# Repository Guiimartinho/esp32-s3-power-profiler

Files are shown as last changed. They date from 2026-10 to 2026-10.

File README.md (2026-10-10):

# Open Power Profiler

[](CONTRIBUTING.md#quality-gates)
[](#roadmap)
[](LICENSE)
[](hardware/LICENSE)

Open-source power profiler in the class of the Nordic PPK2, built around the
Raspberry Pi Pico 2. It is designed to sample current at 100 kSPS from
100 nA to 1 A with automatic range switching, to work either as a source
meter that powers the device under test or as an ampere meter in series
with an external supply, and to stream the samples to a PC over USB.

The instrument is two boards: a Raspberry Pi Pico 2, bought ready-made,
plugged into a carrier board designed in this project that holds the
measurement electronics.

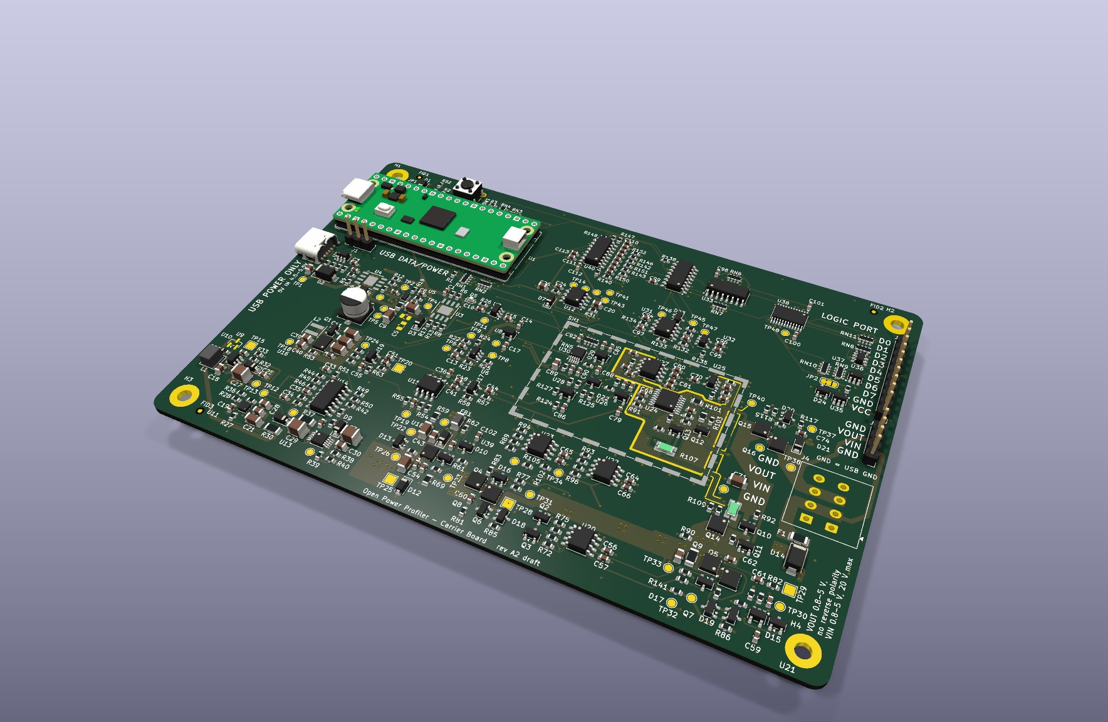
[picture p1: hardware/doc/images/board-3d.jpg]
Rendered view of the carrier board, draft A2


The picture is a rendering from the KiCad files of draft A2, with the
Pico 2 on its sockets. It is not a photograph: no board has been built.

> [!NOTE]
> The project is in early development. No hardware has been built and
> nothing has been measured. The performance figures in this repository
> are design targets, the circuits of the board are simulated from its
> netlist, and the figures of the board are calculated from the drawn
> copper. [Project Status](#project-status) says what exists, what it
> rests on and what comes next.

## Table of Contents

- [Project Status](#project-status)
- [Target Specifications](#target-specifications)
- [How It Works](#how-it-works)
- [Connections](#connections)
- [Hardware Draft](#hardware-draft)
- [Circuit Simulations](#circuit-simulations)
- [Repository Structure](#repository-structure)
- [Roadmap](#roadmap)
- [Getting Started](#getting-started)
- [Engineering Practices](#engineering-practices)
- [Documentation](#documentation)
- [Contributing](#contributing)
- [License](#license)
- [Acknowledgments](#acknowledgments)

## Project Status

As of 2026-10-10. Draft A2 of the carrier board is the present state of
the hardware: the whole schematic, a specification written for it, and a
board with every part placed and every one of its 984 connections drawn.
The board was first routed by an autorouter, which left 28 connections
open. Its layout has since been reviewed: the open connections are closed
and the copper that an autorouter does not draw is drawn, the pours of the
1 A path, the guard, the sense pairs and the copper of the converters. The
review was done with scripts and checked by independent calculation. The
seven points where the reviewed board departs from the first wording of
section 10 of the specification are recorded decisions, D-87 to D-93, and
the specification follows them. What is open is the review by a person in
the KiCad editor, a list of items that need parts moved, the silkscreen
and test point items, and the thermal check of D-93. Every figure of the
board is calculated from the drawn copper, none is measured; the package
in [`tools/board/`](tools/board/README.md) reproduces them from the board
file.

On 2026-10-10 the circuits of the schematic were simulated as well, block
by block, from its netlist: 134 benches in ngspice, of which 93 run
circuits of the board and 41 put the models into the test circuits of
their datasheets. The central design figures of the specification come
out again. The simulations raised four points for a decision before
boards are ordered, and the project owner decided them the same day: they
are decisions D-95 to D-98 of the specification. Three of them change the
schematic and are not drawn yet, so the schematic, the board, the bill of
materials and the results of the simulations still show the earlier
state. In fourteen places the simulations differ from a figure or a rule
of the specification or show something that it does not state. Those are
not decided, and no requirement, figure or rule of the specification was
changed on their account. A simulation is not a measurement: every active
part in it is a model written from a datasheet, a typical part at room
temperature. [Circuit Simulations](#circuit-simulations) shows the state.

The software was written ahead of the hardware and is tested without it.

| Area | What exists | What is open |
| --- | --- | --- |
| [Specification](docs/specification.md) | The baseline of draft A2: requirements R-01 to R-17, analog and firmware design, pin map, host protocol, 98 recorded decisions and 36 firmware rules that guard hardware. The last four, D-95 to D-98, are the decisions of the project owner on the four points that the simulations raised | Every figure is a datasheet value, a calculation, a simulation or an estimate; the tests of its section 11 have to confirm them. Three of the four new decisions are stated here and not drawn yet. Where the simulations of 2026-10-10 differ from its text in fourteen other places, the text stands unchanged and its section 16 lists the place |
| [Schematic](hardware/doc/README.md) | 428 parts on 15 pages. It passes the electrical rules check, and its netlist was checked independently against the datasheets. Its circuits are simulated from that netlist | The [component checks](docs/checks/README.md): none is closed, so every part is a candidate. Three decisions that follow the simulations are not drawn yet: 10 nF in place of 1 nF at three capacitors of the rail monitor (D-95), a position for a capacitor at the buffer of the driver rail (D-96), and the two parts of the damper on the module input fitted (D-98) |
| [Board](hardware/README.md#board) | 150 mm × 100 mm, four layers, 425 footprints, 984 of 984 connections drawn, no violation in the design rules check. The layout was reviewed with scripts and checked by independent calculation. Calculated from the drawn copper: the 1 A path is 19.5 squares in source meter mode and 23.3 squares in ampere meter mode against a limit of 30, and the surface leakage into the measured node is 5.1 nA against a budget of 10 nA. The seven points where the layout departs from the first wording of section 10 of the specification are recorded as decisions D-87 to D-93 | No person has reviewed the board in the KiCad editor; open items need parts moved, the capacitor loops of the converters among them; names on the silkscreen and probe grounds at the test points are missing; the temperature rise of the linear regulator is an open check, read on the first board (D-93). The position for a capacitor of D-96 is not on the board yet: it adds one footprint |
| [Bill of materials](hardware/doc/bom.csv) | 151 lines, each with a part number and a maker, exported from the schematic | Three lines had no stock on 2026-10-09. The file still shows the state before the decisions of 2026-10-10, with three positions without parts: the two parts of the damper on the module input are fitted by D-98 and get their part numbers when the schematic is changed, the three capacitors of D-95 change their value, and the detector position at the boost converter stays empty (D-97) |
| [Circuit simulations](simulation/README.md) | The circuits of draft A2 simulated in ngspice from the netlist of the final schematic, in a package of their own (D-94): 134 benches, 93 on the circuits of the board in ten blocks and 41 that put the models written for the project into the test circuits of their datasheets. Of 3162 figures 1834 pass, 122 fail and 1206 carry no limit. The central design figures of the specification come out again block by block: shunt ladder, signal chain, range logic with requirement R-07, source meter, output stage, path switches, rails, power input and digital lines. The package has 777 tests; lines and branches are covered in full, the one module that loads the simulator excepted | The four points that the simulations raised are decided (D-95 to D-98): the capacitors of the rail monitor, the buffer of the driver rail, the detector position at the boost converter and the damper on the module input. The results are still those of the circuit before these decisions; the benches run again when the change is drawn. In fourteen places the simulation and the text of the specification differ; the text stands unchanged until the owner decides. What stays for the bench: leakage at the nanoampere level, the multiplexer at +12 V and −4 V, the programs of the controller, coupling through the board, temperature. Every active part is a model written from its datasheet, and nothing is measured. The simulations ran on one machine; the `Simulation` workflow has not been started yet |
| [Firmware](firmware/README.md) | Core in C that needs no hardware, with unit tests on the PC: wire protocol, block queue, settling window, step-down rule, device state machine. The build project is still the one of the first plan, for the ESP32-S3 | No build for the Pico 2, no PIO program, no adapter for any hardware, no command handler, none of the firmware rules of the specification |
| [Host software](host/README.md) | Python package with protocol, transports, device client, capture helpers and a device simulator, tested against that simulator | Its nominal calibration and its handling of flagged samples do not follow draft A2 yet; no command that captures from an instrument, no viewer and no export |
| [Protocol](protocol/README.md) | One definition; the constants of firmware and host and the shared test vectors are generated from it | What draft A2 reports beyond it, listed in section 16 of the specification |
| [Tools](tools/README.md) | [`tools/board/`](tools/board/README.md): a Python package that calculates the layout figures from a dump of the board file: copper resistance in squares and milliohms, lengths of the Kelvin pairs, surface leakage into the measured node. 260 tests on synthetic boards, lines and branches fully covered | Calibration and production test: two empty folders. The `Tools` workflow has not been started yet. The scripts that drew the layout are not in the repository |
| Measurements | None: no board has been built | The phases of the [roadmap](#roadmap) |

Next steps, in this order:

1. **Draw the decisions that follow the simulations.** The project owner
   decided the four points on 2026-10-10: decisions D-95 to D-98 of the
   specification. Three of them change the schematic and are not drawn
   yet: 10 nF in place of 1 nF at three capacitors of the rail monitor,
   the comparators that tell the controller that the analog supplies
   stand (D-95); a position for a capacitor at the buffer of the driver
   rail, the supply of the amplifier that drives the converter, which
   needs a footprint and so a change of the board (D-96); and the two
   parts of a damper, a resistor with a capacitor, on the module input,
   the supply that comes through the USB connector of the Pico 2, on pads
   that the board already has (D-98). The fourth leaves the position for
   a voltage detector at the boost converter, which makes the supply of
   the analog rails, without a part and changes only the text of that
   position (D-97). After the change come the
   electrical rules check and the design rules check, the bill of
   materials and the pictures exported again, the netlist snapshot of the
   simulations written again and the benches of the changed blocks run
   again. Until then the schematic, the board, the bill of materials and
   the results of the simulations show the earlier state.
2. **Decisions that are still open.** They are the project owner's. The
   fourteen places where the text of the specification and the simulation
   differ: each one that changes the text becomes an entry in its
   decision log. And whether proof-of-concept boards are ordered on this
   state. The
   [simulation guide](simulation/README.md#what-the-simulations-say) gives
   every place with the bench that shows it, and section 16 of the
   specification lists them as open.
3. **Board.** Four things stand between the reviewed layout and
   fabrication. First, a person opens the board in the KiCad editor and
   reviews it; so far it was drawn and checked with scripts only. Second,
   the open items that need parts moved are a change of placement with a
   local redraw: the capacitor loops of the converters, the inductor of
   the pre-regulator and the others. Third, the silkscreen and test point
   items: net names, jumper functions, probe grounds, a frame for the
   serial number. Fourth, the thermal check of D-93: the temperature rise
   of the linear regulator at full dissipation is read on the first board.
   The [hardware guide](hardware/README.md#still-to-do) lists the open
   items one by one. The simulations judge the circuits, not the copper:
   of their decisions only the position of D-96 touches it.
4. **Software.** Bring the host package and the firmware to what the
   specification of draft A2 asks: the nominal calibration, the fault
   causes and the protocol items of its section 16. Then port the firmware
   to the Pico SDK. The [firmware guide](firmware/README.md) and the
   [host guide](host/README.md) list the differences.

Until 2026-10-10 this list had a step to file the simulations. It is
done in another form. The files of the earlier simulations, from which
the specification took its figures marked "simulated", are not filed;
the circuits were simulated again from the netlist, and the package, the
benches and their results are in [`simulation/`](simulation/README.md),
where a reader can run them again.

The [component checks](docs/checks/README.md) follow, of which none is
closed, and the phases of the [roadmap](#roadmap), starting with the risk
prototypes of phase 1. Three of those prototypes settle what the
simulations leave open: the reaction time of the range sequencer, which is
an input of every simulation of the range logic, the loop of the
pre-regulator at its low end, and the start of the boost converter from a
supply limited to 0.7 A.

## Target Specifications

| Item | Target | Requirement |
| --- | --- | --- |
| Sampling rate | 100 kSPS, timed by hardware | R-01 |
| Data integrity | No lost sample in a capture of 10 minutes; any loss is reported | R-02 |
| Current range | 100 nA to 1 A in four ranges, switched automatically | R-03 |
| Resolution | 100 nA or better in the lowest range; RMS noise there at most 5 nA in ampere meter mode from a quiet supply and 40 nA in source meter mode | R-04 |
| Accuracy | ±1 % of reading ±0.1 % of range after calibration | R-05 |
| Burden voltage | 100 mV maximum across the shunt; 200 mV from input to output at 1 A | R-06 |
| Range change | On a step from 1 µA to 500 mA the instrument adds at most 0.5 V of drop with 1 µF at its output and 0.25 V with 10 µF | R-07 |
| Source meter mode | Programmable output from 0.8 V to 5.0 V in 1.3 mV steps; 1.0 A up to 2.0 V, falling to 0.6 A at 5.0 V | R-08 |
| Ampere meter mode | External supply from 0.8 V to 5.0 V through the shunts; the input withstands −20 V to +20 V while its switch is open | R-09 |
| Digital inputs | 8 logic channels sampled together with the current, logic levels from 1.65 V to 5.5 V | R-10 |
| Host link | USB Full-Speed, CDC ACM, binary protocol | R-11 |
| Calibration | Gain and offset of each range, stored on the device | R-12 |
| Protection | Over-current trip, reverse polarity, over-voltage, thermal | R-13 |
| Power input | USB-C, 5 V, on the carrier board, used whenever it is present, or the USB cable of the Pico 2 alone; the input current is limited to what the source offers: 0.45 A, 1.4 A or 1.7 A | R-14 |
| Host software | Capture, live view, statistics and export on Windows, Linux and macOS | R-15 |
| Openness | Firmware and host software under MIT, hardware under CERN-OHL-P v2 | R-16 |
| Software quality | Automated tests with coverage gates, static analysis and continuous integration | R-17 |
| Controller | Raspberry Pi Pico 2 (RP2350) on pin sockets | D-39 |
| DUT connections | Pin header and lever terminal block, in the pin order of the PPK2 | D-44 |

These are design targets, not measurements. Draft A2 set seven of them
(R-04, R-06, R-07, R-08, R-09, R-10 and R-14) to what the architecture
delivers, with the PPK2 as the yardstick. Section 2 of the
[specification](docs/specification.md) gives the full wording of each
requirement and the evidence behind each figure: a datasheet value, a
calculation, a simulation or an estimate.

Where the specification compares a target with the PPK2, it quotes the
PPK2 User Guide v1.0.1:

| Item | This design, target | PPK2, as its user guide states |
| --- | --- | --- |
| Resolution in the lowest range | 100 nA or better (R-04) | 0.2 µA, with measurement down to about 200 nA |
| Current in source meter mode | 1.0 A up to 2.0 V, falling to 0.6 A at 5.0 V (R-08) | 600 mA, with a rated power of 5 W |
| External supply in ampere meter mode | 0.8 V to 5.0 V (R-09) | The same range |
| Logic levels of the digital inputs | 1.65 V to 5.5 V (R-10) | 1.65 V to 5.5 V |
| Burden voltage | 100 mV across the shunt, 200 mV in the whole path at 1 A (R-06) | Not stated |
| Drop at a range change | 0.5 V with 1 µF at the output, 0.25 V with 10 µF (R-07) | Not stated |
| Voltage that the supply input withstands | −20 V to +20 V with its switch open (R-09) | Not stated |

The middle column holds design targets, none of them measured; the right
column is taken from section 2 of the specification.

## How It Works

```text
USB-C 5 V ────► limiter ─┐
                         ├► multiplexer ─► 5 V rail ─► supplies of the carrier
Pico 2 USB ───► limiter ─┘

5 V rail ───► pre-regulator ──► LDO (source mode) ◄── DAC ◄── SPI
                                    │
VIN (ampere mode) ──► protection ──►├── mode switch
                                    │
                         shunt ladder + range FETs ◄── range sequencer
                                    │         │ Kelvin sense   ▲
                         output switch     in-amp ──┬──► comparators
                                    │               └──► ADC ──► Pico 2 ──► USB
                                  VOUT ──► DUT          D0..D7 ──► level shift
```

- **Two boards.** Everything in the diagram except the controller is on the
  carrier board. The Raspberry Pi Pico 2 brings the microcontroller and the
  USB port, and uses every one of its 26 GPIO pins.
- **One programmable part.** The range sequencer and the sampling clock are
  programs for the PIO blocks of the RP2350: small state machines that run
  from the system clock whatever the processors do. Firmware is loaded
  through USB; no programmer and no vendor tool is needed.
- **A supply that spares its source.** Each USB input has its own current
  limiter, and a multiplexer feeds the 5 V rail from USB-C whenever it is
  present. A supervisor switches the supplies of the carrier off when that
  rail collapses, and four comparators report through one line, PWR_GOOD,
  that the analog rails and the reference are present.
- **Four shunt ranges.** Shunts of 1 kΩ, 33 Ω, 1 Ω and 0.1 Ω, each limited
  to 100 mV of burden voltage. Three comparators drive the range
  sequencer, which switches to a higher range with no firmware involved:
  on a large step the 1 A range conducts 0.35 µs after its threshold
  (simulated, with a sequencer that reacts within 100 ns, which phase 1
  has to measure). A current step therefore costs the device under test
  only a short dip; requirement R-07 of the specification gives its size.
  The firmware decides when to step back down.
- **Hardware-timed sampling.** A 16-bit SAR ADC is clocked by a PIO state
  machine, so the sampling instant does not depend on firmware latency. The
  same state machine reads the range and the logic inputs with every
  conversion result.
- **Self-describing samples.** Every sample is a 32-bit word that carries the
  ADC code, the active range, a validity flag, the fault flag and the eight
  logic inputs.
- **Two cores, two jobs.** One core acquires data in DMA blocks. The other
  frames the blocks and streams them over USB.
- **Programmable supply.** In source meter mode a DAC sets a low-noise linear
  regulator, fed by a pre-regulator that tracks the output voltage.
- **Protection that does not wait for firmware.** The over-current trip is a
  PIO state machine. An over-voltage on the external supply input holds
  its switch open through one transistor, a second transistor keeps the two
  mode switches from closing together, and with its switch open that input
  withstands −20 V to +20 V (simulated).
- **A quiet front end.** The shunts of the three lower ranges, the
  amplifier and the converter are placed under a shield can, and the
  switching converters stand at least 30 mm away from it.

The reasons behind each choice, with the decision that records it, are in
sections 3 and 4 of the [specification](docs/specification.md).

## Connections

The back edge of the carrier has the USB connector of the Pico 2 (data, and
power for small loads) and a USB-C connector for power. Either one powers
the whole instrument. The front edge has the connections to the device under
test, in the pin order of the Nordic PPK2:

| Connector | Type | Pins, left to right |
| --- | --- | --- |
| DUT | 1×4 pin header, 2.54 mm | GND, VIN, VOUT, GND |
| DUT | Lever terminal block, 3.5 mm | GND, VIN, VOUT, GND |
| Logic port | 1×10 pin header, 2.54 mm | VCC, GND, D7 down to D0 |

- **Source meter mode:** the device under test connects to VOUT and GND.
- **Ampere meter mode:** the external supply connects to VIN and GND, the
  device under test to VOUT and GND.
- **Logic port:** as built, the logic inputs follow the output voltage, and
  the VCC pin is not needed. A solder jumper makes the VCC pin the reference
  instead, for a device whose logic runs on another voltage.

## Hardware Draft

The carrier board is drawn in KiCad 10 as draft A2. Its layout was reviewed
on 2026-10-10.

| | Draft A2 after the layout review |
| --- | --- |
| Schematic | 428 parts on 15 A4 pages: the root page and 14 sheets; unchanged by the layout review |
| Electrical rules check | 0 errors, 0 warnings |
| Board | 150 mm × 100 mm, four layers, 425 footprints, all on the top side |
| Routing | 984 of the 984 connections: 8.38 m of track on three layers (top 3.76 m, second inner layer 2.84 m, bottom 1.79 m), 694 vias and 42 copper zones. The first inner layer is the ground plane, in one piece and with no track on it |
| Open connections | None. The autorouted board had 28, and 25 of them broke a function |
| Design rules check | 0 violations, 0 unconnected pads, 0 footprint errors, 0 differences between board and schematic. The rule file is stricter than the one the autorouter ran with: the exemption of the larger spacings near pins now holds on the top layer only. Decision D-87 records its spacings |
| Bill of materials | 151 lines, each with a part number and a maker: [`hardware/doc/bom.csv`](hardware/doc/bom.csv); unchanged by the layout review |
| Circuit simulations | The circuits of the schematic simulated from its netlist on 2026-10-10 in 93 benches: 1356 figures pass, 105 fail and 1136 carry no limit. The four points that they raised are decided (D-95 to D-98), and three of them are not drawn yet ([Circuit Simulations](#circuit-simulations)) |

The schematic was checked independently against the datasheets of its
parts. That closes none of the
[component checks](docs/checks/README.md): the parts are candidates. The
simulations close none either: they run on models written from those
datasheets.

The board came about in three steps. A script placed every footprint
inside the area of its functional block. An autorouter drew a first set of
tracks: 956 of the 984 connections, with 28 left open, no pour and no
guard. Then the layout was reviewed with scripts on the board file, block
by block: the open connections were closed and the pours of the 1 A path,
the guard, the Kelvin pairs, the copper of the converters, the 5 V rail and
the ground fills were drawn. Each block was drawn against the rules of
section 10 of the specification and then checked by an independent check
that calculated every rule again. A final review of the whole board by rule
group followed, with 75 findings, then a repair round for the leakage paths
into the measured node that it found. No part was added or removed; 35 of
the 425 footprints moved or turned, 33 of them by 2.75 mm or less.

The result is a drawn and calculated layout, not a design to fabricate.
Nobody has opened it in the KiCad editor and looked at it as a person
would before ordering boards: every check ran from the command line. The
scripts that calculate the figures are in the repository, as the package
in [`tools/board/`](tools/board/README.md); the helpers that drew the
layout are not.

### What the Layout Review Reached

Every figure in the column "Now" is calculated from the drawn copper.
Nothing is built and nothing is measured. The resistances count 35 µm
copper at 40 °C and leave out the transistors, the shunt and the fuse.

| Rule, with its section of the specification | Limit | Autorouted board | Now |
| --- | --- | --- | --- |
| Connections drawn | 984 | 956 | 984 |
| 1 A path in source meter mode, regulator output to the VOUT terminal (10.4) | 30 squares | 397 squares, about 211 mΩ | 19.5 squares, 10.4 mΩ |
| 1 A path in ampere meter mode, VIN terminal to the VOUT terminal (10.4) | 30 squares | 217 squares, about 116 mΩ | 23.3 squares, 12.3 mΩ |
| Surface leakage into the measured node (10.3) | 10 nA | No figure | 5.1 nA; it was about 20 nA at the final review, before the repair round |
| Guard around the measured node (10.3) | A closed ring on the top layer | None | One piece of copper: three arcs on the top layer, open where the measured node leaves the shield can, joined through the other layers |
| Sense and guarded nets on the top layer without a via (10.3) | All 11 | No figure | 10 of 11 |
| 5 V rail from the bulk capacitor to the input capacitors of the converters (10.1) | 10 mΩ to the pre-regulator and 25 mΩ to the boost converter: targets of the layout review, the specification gives no figure | Tracks of 0.4 mm | A pour on the second inner layer: 2.7 mΩ and 3.0 mΩ to the pre-regulator, 3.6 mΩ to the boost converter |
| Copper from the output capacitors of the pre-regulator to the bead (10.5) | 15 mΩ | No figure | 7.1 mΩ |

The figures of the 1 A path, of the leakage, of the pairs and of the vias
on the sense nets are reproduced from the board file by the `report`
command of the package in `tools/board/`; its
[guide](tools/board/README.md#report-everything-the-definition-asks-for)
says how to install it, dump the board and run it. The resistances are
calculated on a grid of 0.1 mm; on a grid of 0.05 mm the two sums of the
1 A path read about 2 % higher, 19.9 squares and 23.8 squares, and a via
is counted in a way that errs to the high side.

The leakage figure rests on the assumptions that section 10.3 of the
specification itself uses: a clean surface of 10¹¹ Ω per square and the
voltages of the neighboring nets. Solder mask, cleanliness and humidity
are not modeled. Almost all of what is left comes from the pitch of pads:
the gate beside the source in a transistor package, the poles of the two
DUT connectors, neighboring pins of the multiplexer.

### Decisions of the Layout Review

In seven points the reviewed board departs from what section 10 of the
specification first asked. The owner accepted all seven on 2026-10-10.
They are recorded in the decision log of the
[specification](docs/specification.md) (section 15), and section 10 now
describes the board as it is drawn:

- **D-87.** The rule file of the board states every spacing that the
  layout needs.
- **D-88.** The high-side sense line of the 0.1 Ω shunt keeps two vias and
  1.9 mm on the second inner layer.
- **D-89.** The Kelvin pairs: one runs side by side, two are equal in
  length within 1 mm, and the taps of the two lowest ranges run through
  one via each.
- **D-90.** The guard is one piece of copper, open on the top layer at the
  three exits of the measured node and joined on other layers.
- **D-91.** The supply, address and enable pins of the multiplexer and
  their parts stand inside the guard.
- **D-92.** The 1 A path is judged by its resistance, 30 squares or less
  in either mode; two of its pieces run on the bottom layer.
- **D-93.** The island of output copper under the linear regulator is
  291 mm² on the bottom layer and 102 mm² on the top layer, joined by
  22 vias; its temperature rise is an open check, read on the first board.

A decision accepts a drawn layout, not a measured one: where it rests on
a resistance or a leakage, the figure is calculated from the drawn copper.
The [hardware guide](hardware/README.md#decisions-of-the-layout-review-d-87-to-d-93)
quotes, for each point, what section 10 said before, what the board has
and why.

### What the Layout Review Left Open

Four things stand before fabrication, and the component checks beside
them. A fifth came after the review: the three decisions that follow the
circuit simulations and are not drawn yet, of which the position for a
capacitor at the buffer of the driver rail adds a footprint to this board
(D-96; [Project Status](#project-status)).

No person has reviewed the board in the KiCad editor: it was drawn and
checked with scripts only.

Eleven items need parts moved or another footprint and were left open. The
capacitor loops of the pre-regulator and of the boost converter close over
6.8 mm to 17.1 mm of top copper where the limit is 5 mm, and the inductor
of the pre-regulator stands 4.5 mm from its switch pins where the limit is
3 mm; nine more are smaller.

The legends of the silkscreen and the test points are as the autorouted
board had them; only the title text changed, to the name of the project.
32 of the 40
signal test points have no probe ground within 5 mm, and the net names of
the test points and the functions of the two jumpers are not printed.

The temperature rise of the linear regulator at full dissipation is an
open check, to be read on the first board (D-93).

The component checks are open too: none is closed. The hardware guide
lists the [open items](hardware/README.md#open-items) one by one, with
their figures and with what would close each.

### Pictures

All pictures are renderings and plots of the board file, not photographs.

The top side, rendered from the board file. The gold line around the front
end is the guard under open solder mask:

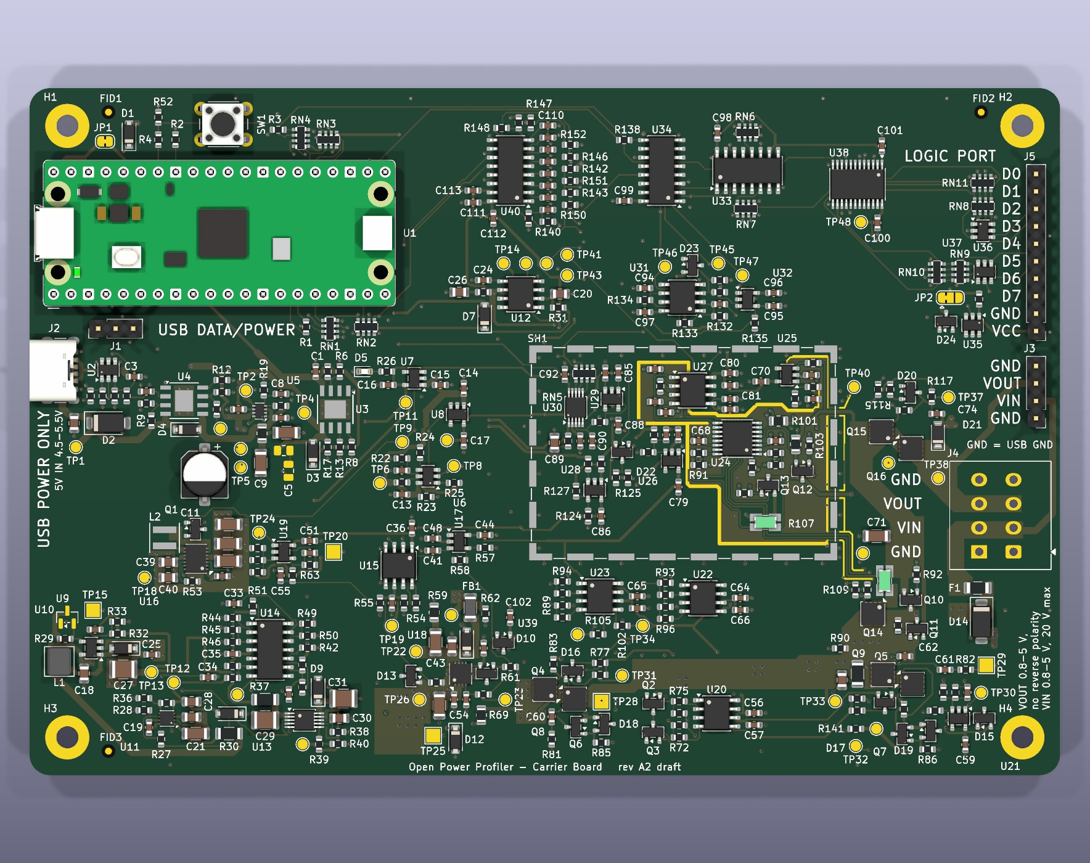
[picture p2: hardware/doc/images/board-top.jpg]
Rendered top view of the carrier board


The four copper layers side by side. Top left, the top layer: the parts,
the pours of the 1 A path, the sense pairs and the guard. Top right, the
first inner layer: the ground plane, in one piece. Bottom left, the second
inner layer: the 5 V rail, the rail trunks and a ground fill. Bottom
right, the bottom layer: the crossings, the second layer of the 1 A path
and a ground fill:

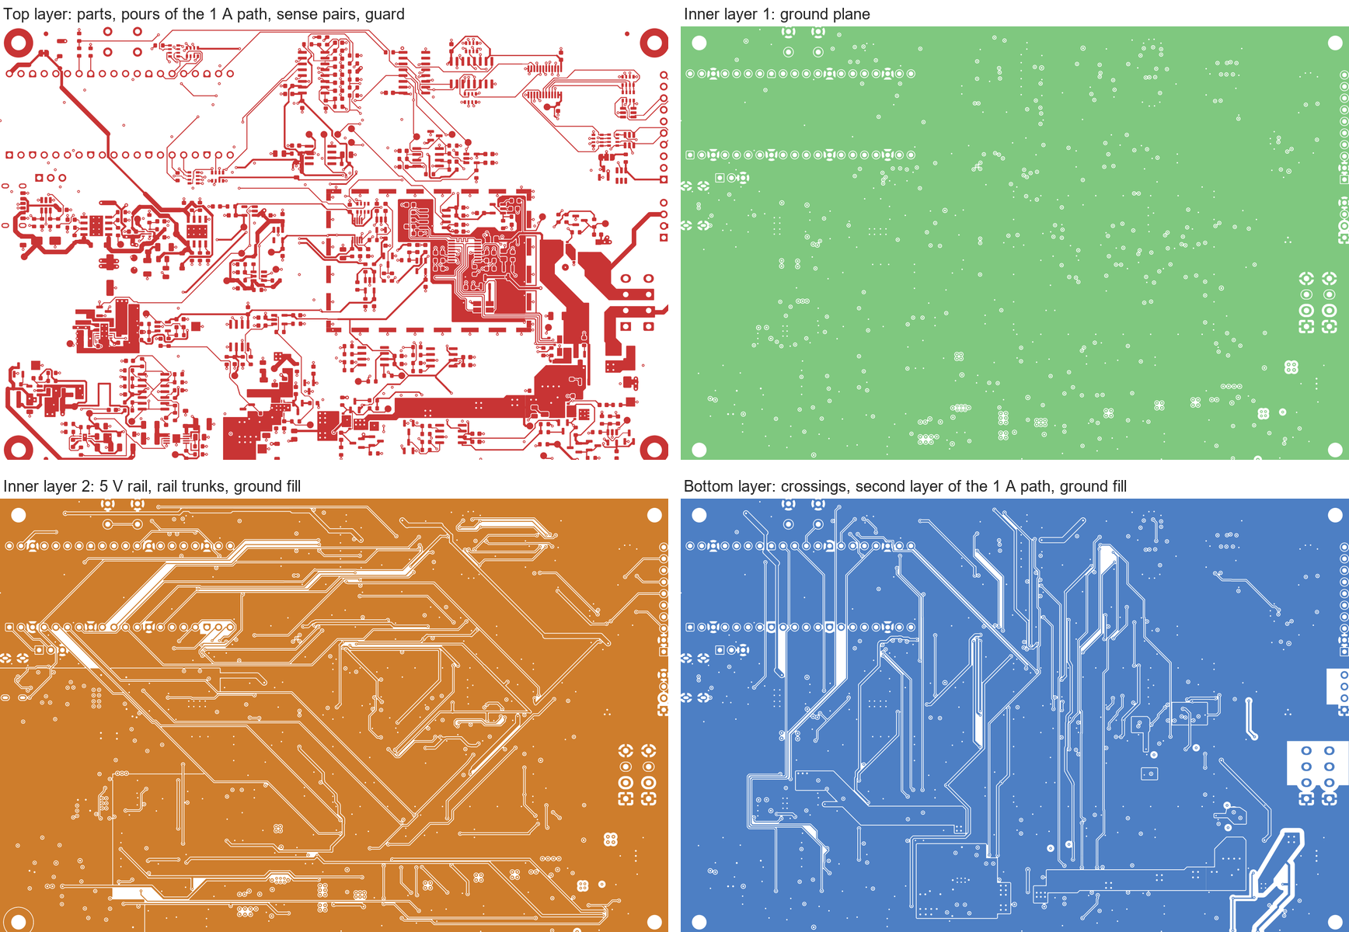
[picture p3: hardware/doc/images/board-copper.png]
The four copper layers of the board


The measured node under the shield can, top layer in red, openings of the
solder mask in pink. Look for the pink line that runs around the large red
area: it is the guard, bare of solder mask, around the copper of the
measured node and the guard pour. From the multiplexer in the middle, thin
lines run in pairs to the shunts: the Kelvin lines. At the lower right the
pair of the 1 A range leaves the can in a lane with a guard track on each
side:

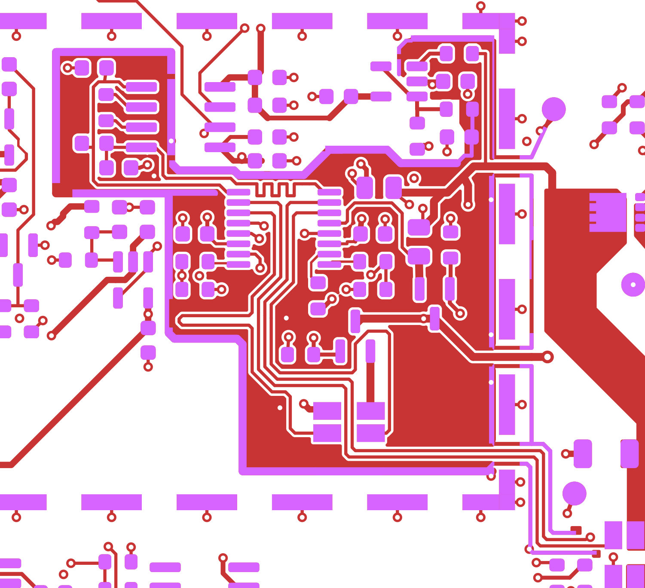
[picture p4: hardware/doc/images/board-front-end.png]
The measured node and its guard on the top layer


The 1 A path on the top layer. Follow the wide copper from the linear
regulator at the bottom left, along the supply band to the right, up to
the shunt branch and the output switch, and out to the terminal block at
the right edge. The dashed rectangle is made of the lands of the shield
can:

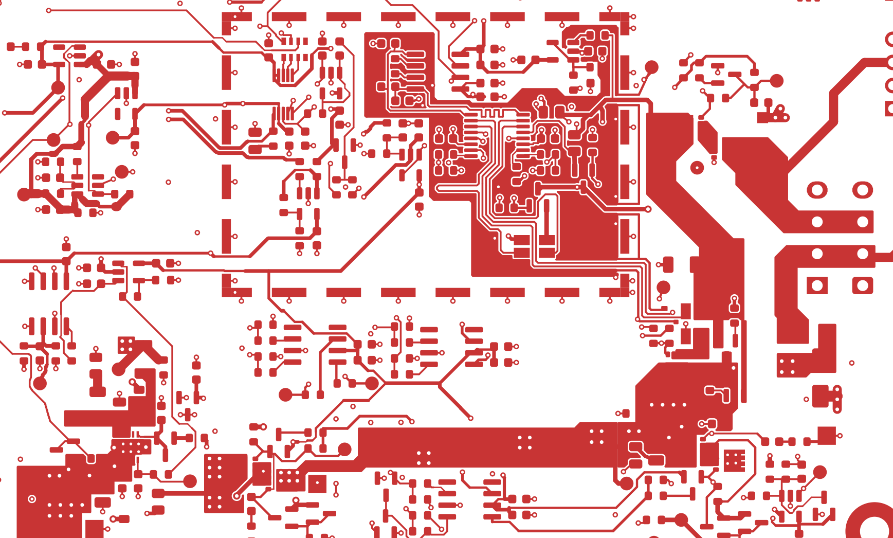
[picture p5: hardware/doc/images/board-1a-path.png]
The pours of the 1 A path on the top layer


The areas of the sixteen functional blocks and the parts inside them:

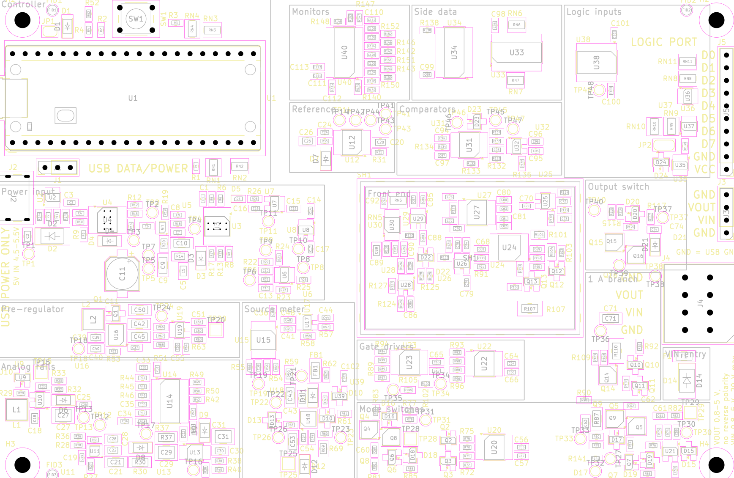
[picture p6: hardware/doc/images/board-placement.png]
Placement of the functional blocks


The root page of the schematic, with one block for each of the 14 sheets:

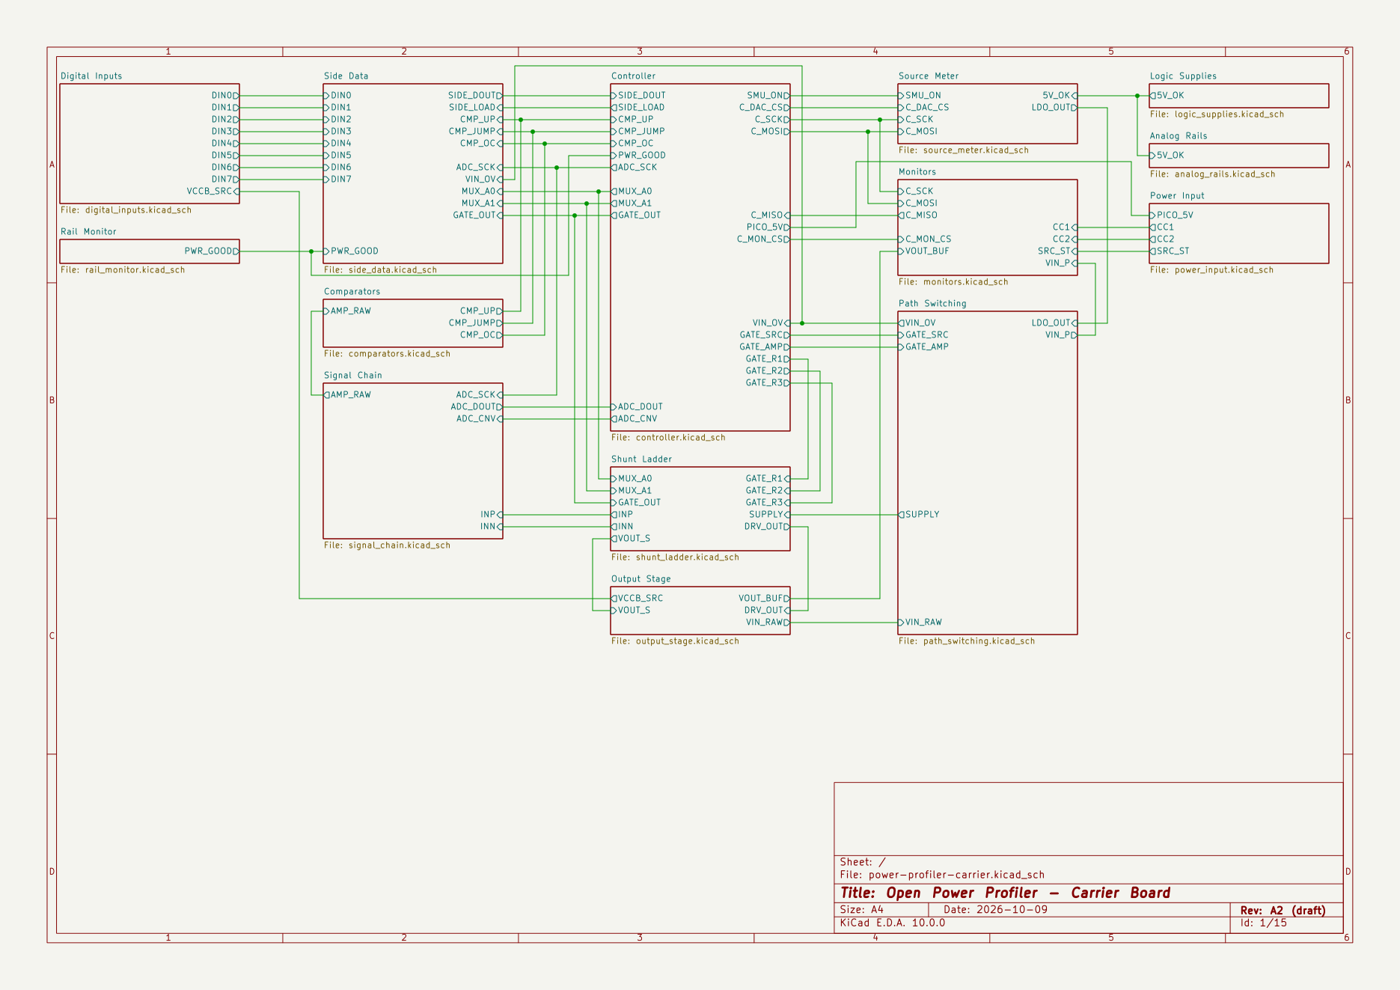
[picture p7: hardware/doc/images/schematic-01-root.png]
Block level of the schematic


Every sheet and the board are shown in
[`hardware/doc/`](hardware/doc/README.md), and the whole schematic is in
[`hardware/doc/schematic.pdf`](hardware/doc/schematic.pdf). The status, the
checks and the open work are in the [hardware guide](hardware/README.md).

## Circuit Simulations

The circuits of the carrier board are simulated from the netlist of the
schematic. A bench names parts of the schematic by their reference
designators, the package in [`simulation/`](simulation/README.md) writes
their elements from a snapshot of that netlist, and ngspice runs the
circuit: no part of the board is typed by hand. What stands around the
parts is typed by the bench and named in its notes: sources, loads,
cables, and in some benches a stand-in for a neighboring block of the
board. The simulator is the ngspice library that KiCad 10 ships. Every
active part is a model written for this project from its datasheet, a
typical part at room temperature. 41 benches put these models into the
test circuits of their datasheets; four models have no such bench, the
analog multiplexer among them. The models of the manufacturers may not be
copied into the repository; where a copy is present they give a second
value.

Everything in this section is simulated. Nothing is built and nothing is
measured: a figure that passes says that the circuit as drawn keeps its
limit with these models, not that a board will. Elsewhere on this page a
figure marked "simulated" is one of the specification, taken from the
earlier simulations of the draft.

| Block | Benches | Pass | Fail | No limit |
| --- | --- | --- | --- | --- |
| [Shunt ladder](simulation/results/ladder/README.md) | 2 | 20 | 0 | 6 |
| [Signal chain](simulation/results/signal_chain/README.md) | 11 | 113 | 8 | 111 |
| [Range control logic](simulation/results/range_logic/README.md) | 12 | 143 | 6 | 122 |
| [Source meter](simulation/results/source_meter/README.md) | 12 | 176 | 3 | 247 |
| [Output stage](simulation/results/output_stage/README.md) | 6 | 151 | 6 | 142 |
| [Path switching](simulation/results/path_switching/README.md) | 15 | 288 | 19 | 235 |
| [Power input and logic supplies](simulation/results/power_input/README.md) | 13 | 190 | 27 | 113 |
| [Analog rails and rail monitor](simulation/results/analog_rails/README.md) | 10 | 105 | 25 | 108 |
| [Digital lines and monitors](simulation/results/digital/README.md) | 10 | 145 | 11 | 49 |
| [Whole measuring path](simulation/results/system/README.md) | 2 | 25 | 0 | 3 |
| Circuits of the board, ten blocks | 93 | 1356 | 105 | 1136 |
| [Models against their datasheets](simulation/results/models/README.md) | 41 | 478 | 17 | 70 |
| All | 134 | 1834 | 122 | 1206 |

A bench is one circuit with its stimulus. It takes figures from the
waveforms and judges each one against its limit: a figure of the
specification where it states one; else a rating or a figure of a
datasheet, a value that the bench calculates, or a limit that the bench
sets and names. For a model the limit is the figure of its datasheet with
the tolerance that this project asks of a model. 1206 figures carry no
limit: they are values that nothing limits. A figure that fails is kept
as it is. Most of the 122 are of five kinds: a point that is decided
since and not drawn yet, a figure of the specification that the circuit
does not give, a rating that a fault case passes, an option that is not
in use, and a model that misses its datasheet. The guide
[sorts them by block](simulation/README.md#reading-the-failures).

How close the simulated values lie: for 595 figures of the board blocks
the pages print the distance from a stated value, in most cases the one
that the specification states. 368 lie less than 5 % from it, 434 less
than 10 % and 489 less than 25 %. The
[index of the results](simulation/results/README.md) has every bench, and
the page of each block has the values, the graphs and the decks, the
circuit files that the simulator ran. The whole suite ran on one Windows
machine and takes 29 minutes there.

### What the Simulations Say

**Reproduced.** The central design figures of the specification come out
of circuits taken from the netlist. That is a second calculation with
models, not a confirmation by measurement. Among them:

- Requirement R-07: on a step from 1 µA to 500 mA with 1 µF at the output
  the drop is 301.9 mV with nominal delays, and 388.2 mV with every delay
  at its limit and the capacitor 10 % low, against the limit of 500 mV.
  With 10 µF it is 168.3 mV and 179.2 mV, against 250 mV. An amplifier
  with half the bandwidth of its model, which is an assumption, takes the
  two worst cases to 400.3 mV and 180.8 mV.
- The jump to the 1 A range takes 360.8 ns from its threshold with
  nominal delays and 480.3 ns with the worst ones, against a target of
  550 ns. The 100 ns of the sequencer are an input of that run.
- Gain 19.93 and zero code 1313; one code is 1.914 nA in the lowest range
  and 19.14 µA in the highest. After a jump to the highest range the chain
  settles to 0.1 % of the range in 45.37 µs, and in 49.2 µs at the most
  over the cases that were run. The noise of one sample in the lowest
  range is 2.098 nA from a quiet supply.
- The source meter gives 799.5 mV and 5 V at its two nominal codes in
  steps of 1.282 mV, and its regulator keeps 449.2 mV to 631.9 mV of head
  room on the curve of R-08 with nominal parts.
- The in-rush into 2200 µF at the output is 856.1 mA, below the trip
  level, and the closed path drops 155.7 mV at 1 A in ampere meter mode,
  with the 20 mΩ that the specification allows for copper and contacts
  (limit 200 mV).
- With its switch open the external supply input takes 184.6 µA at +20 V
  and 597.9 µA at −20 V, against a limit of 1 mA.

**Four points, decided.** The simulations raised them for a decision
before boards are ordered, and the project owner decided them on
2026-10-10. Three are not drawn yet, so the results above are still those
of the circuit before them:

1. The capacitors of the rail monitor become 10 nF (D-95). With 1 nF as
   drawn and a comparator at its least hysteresis, an edge of PWR_GOOD
   moves its own threshold and gives a burst of edges on a slow rail.
   With 10 nF the threshold moves by 525 µV, below that hysteresis, where
   1 nF gives 3.149 mV to 3.606 mV; the one run made with 10 nF, at a
   slower slope, shows one edge. The capacitance between the pins that
   couples the edge is an assumption.
2. The buffer of the driver rail of the converter gets a position for a
   capacitor at its input, whose value is chosen on the bench (D-96). Its
   loop has 41.92° of phase margin as drawn, not the 54° that the
   specification stated, and it is stable. The model of the manufacturer
   gives 68.99°, with input capacitances that are not those of its
   datasheet. No run with the capacitor exists, and the position needs a
   footprint.
3. The position for a voltage detector at the boost converter stays
   without a part (D-97). As drawn the converter starts in one go from an
   input limited to 0.67 A to 0.85 A. A detector with a time-out of
   0.24 s in that position would stop that start and, with 1 mA of load,
   repeat it four times in the 1.1 s of the run without completing it.
   The result rests on a model of the converter below 2.7 V, where its
   datasheet says nothing, on a source with a flat current limit and on
   the 1 mA, so the start on a prototype stays a test of phase 1.
4. The damper on the module input is fitted (D-98). When the data cable
   is plugged again on a port at 5.5 V behind a short cable while USB-C
   supplies the instrument, the input of the power multiplexer reaches
   5.941 V with a limiter of typical reaction, and 6.002 V with one
   assumed to react in 15 µs, against a rating of 6.0 V. With the damper
   fitted the peak is 5.502 V in the runs made; the case that is worst
   with the damper, a longer gap of the contact, was not run, and neither
   was the recharge pulse at a change of input.

**Fourteen places where the simulation and the text differ.** The round
proposes no change of hardware for them; that is the owner's decision
too. They are figures and rules of the specification, and things on which
it is silent: how long the over-current comparator stays high while a
large capacitor recharges, the ladder clamp in a short circuit, the advice
on a capacitor at the VIN terminals, the times at power-off, the opening
time of the output switch at 0.8 V, the current in the output suppressor
at a trip, three figures of the mode switches, a check of section 16 that
the simulation does not meet, the list of terms of the noise budget, the
timing estimates of the converter lines, the leakage of the monitor
converter, figures of the source meter, the in-rush on a computer port
and the range that a logic input withstands. The text of the
specification stands until the owner decides. The fourteen are not every
difference: the guide names the further figures that fail against a
rating of a datasheet.

**What stays for the bench.** The simulations cannot settle the linear
range of the amplifier near the negative rail, the loop of the
pre-regulator at its low end, the linear regulator at light load, a supply
that leaves its range while the path is closed, leakage at the nanoampere
level, the programs of the controller, coupling through the board and
temperature.

The [simulation guide](simulation/README.md#what-the-simulations-say) gives
each of these with its figures, with the bench that shows it and with the
limits of the models behind it.

### Two of the Results

Both pictures are plots of simulation runs, not measurements.

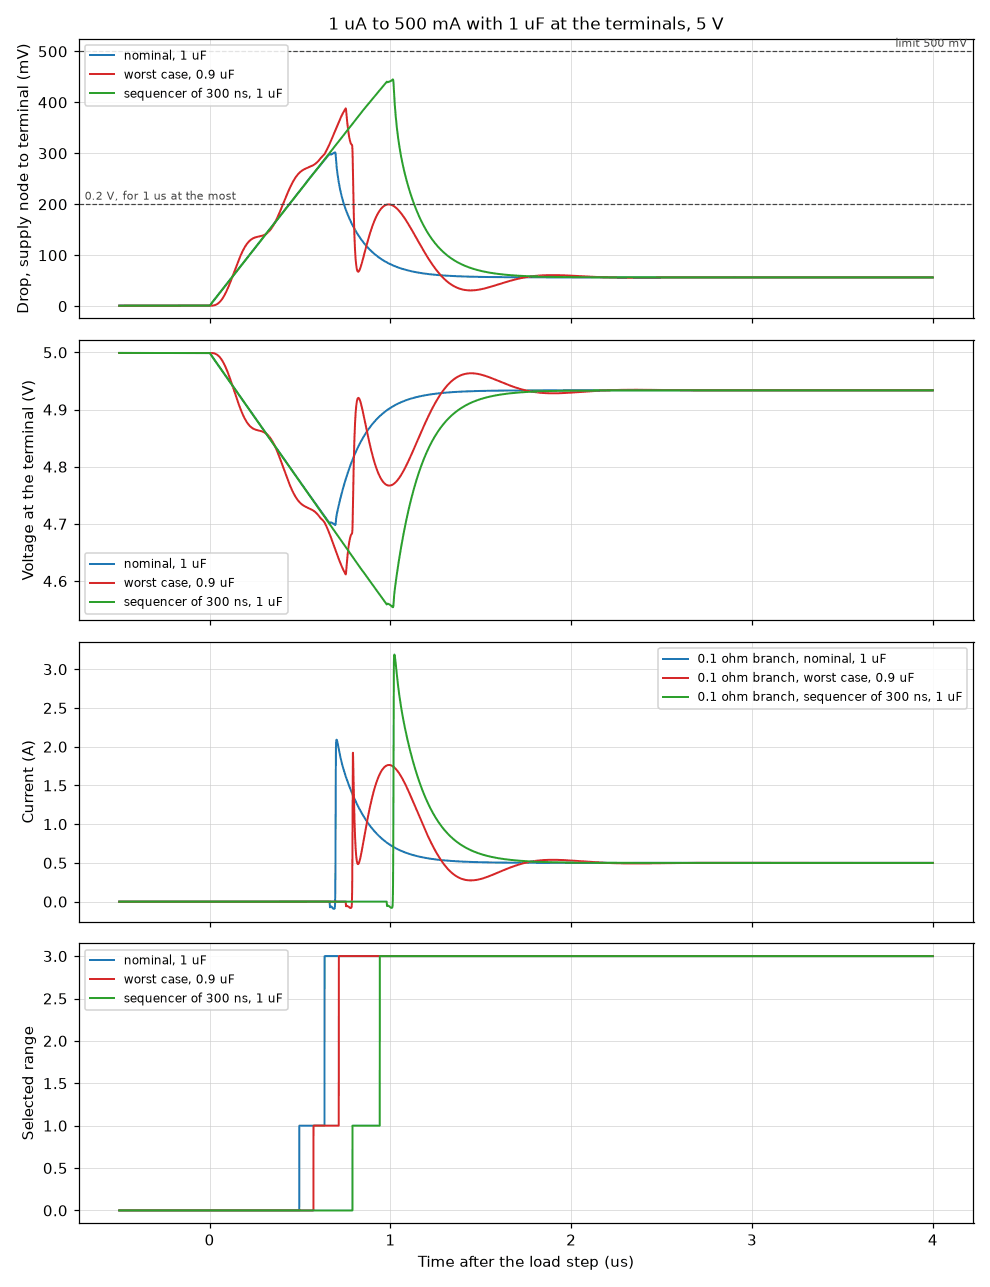
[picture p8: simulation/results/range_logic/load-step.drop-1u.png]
Simulated: a step from 1 µA to 500 mA with 1 µF at the terminals


Requirement R-07 in a simulation. The load steps from 1 µA to 500 mA in
the lowest range, with 1 µF at the terminals and 5 V at the output. From
the top: the drop between the supply node and the output terminal, the
voltage at the terminal, the current in the branch of the 0.1 Ω shunt, and
the selected range. The step-up comparator takes the next range, then the
jump comparator takes the path to the 1 A range. The drop peaks at 301.9 mV
with nominal delays and at 388.2 mV with every delay at its limit and the
capacitor 10 % low, against the limit of 500 mV. The requirement also
allows the drop above 0.2 V for 1 µs at the most, which is the dashed
line; the two curves are above it for 302 ns and 390 ns. The third curve
gives the sequencer 300 ns, three times what the specification allows it,
and reaches 445.1 mV. The reaction time of the sequencer is an input of
this run: the program that has to keep it is not written.

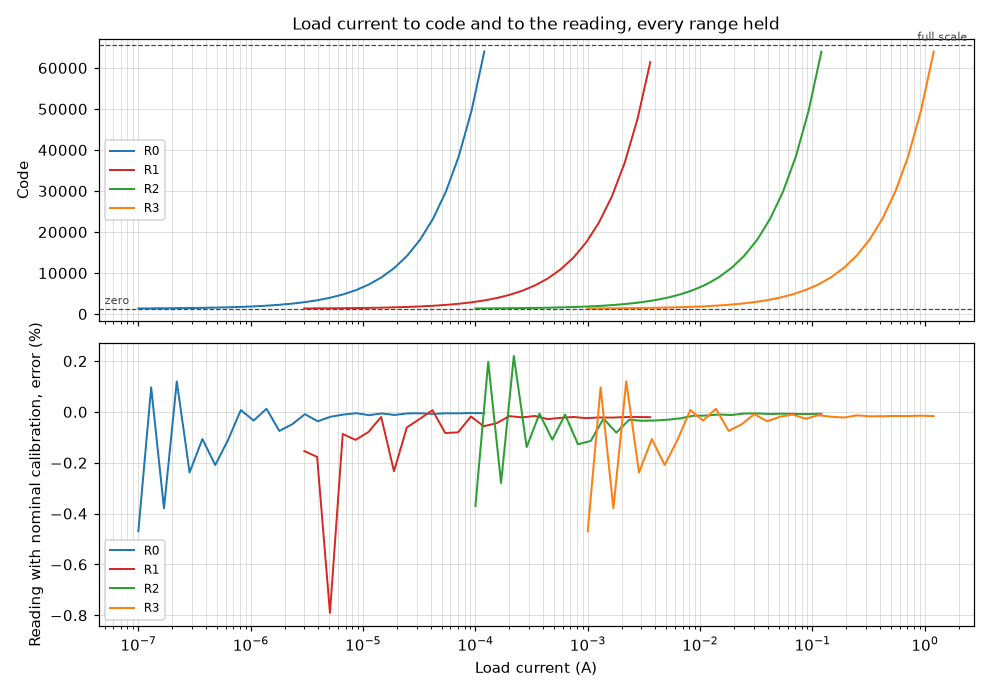
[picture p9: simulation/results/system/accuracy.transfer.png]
Simulated: load current to code and to the reading, every range held


The whole measuring path in a simulation: ladder, multiplexer and
amplifier chain as one circuit from the netlist, each range held while the
load current rises to 120 % of its full scale. Above, the code of an ideal
16-bit converter at the converter input: the four ranges cover 100 nA to
1.2 A, with zero at code 1313. Below, the error of the reading with the
nominal calibration against the load current; at small currents it is the
rounding to one code. The amplifiers have no offset, no bias current and
no noise in this run, and the converter is arithmetic.

## Repository Structure

| Path | Content | License |
| --- | --- | --- |
| [`firmware/`](firmware/) | Firmware of the controller: hardware-independent core with its unit tests; target build not ported to the Pico 2 yet | MIT |
| [`hardware/`](hardware/) | KiCad project of the carrier board and its pictures; the folder for fabrication outputs is empty | CERN-OHL-P v2 |
| [`simulation/`](simulation/) | Circuit simulations of the carrier board: the package `circuit-sim` with its tests, a snapshot of the netlist of the schematic, the models written for the project, the benches and their results | MIT |
| [`host/`](host/) | Python package: protocol, transports, device client, capture helpers, simulator | MIT |
| [`protocol/`](protocol/) | Protocol definition, generator and shared test vectors | MIT |
| [`tools/`](tools/) | [`tools/board/`](tools/board/): the package that calculates the layout figures from the board file, with its tests. The folders for the calibration and production-test scripts are empty | MIT |
| [`docs/`](docs/) | Specification, component checks (all open), test reports (none yet) | MIT |

## Roadmap

The work is split into phases. Each phase is closed by a test report with
recorded measurements. The exit criteria are in section 13 of the
[specification](docs/specification.md).

| Phase | Goal | Status |
| --- | --- | --- |
| 1 | Risk prototypes. On a Pico 2 with an ADC evaluation module: firmware on the Pico SDK, hardware-timed ADC capture, reaction time of the range sequencer, USB throughput. On evaluation modules: the pre-regulator with its tracking amplifier, and the start of the boost converter from a supply limited to 0.7 A | Not started; the software foundations exist, written ahead of it and tested without hardware; the firmware port to the Pico SDK and the bench work are not started |
| 2 | Analog front end with one fixed range on a test board | Not started |
| 3 | Shunt ladder and range logic | Not started |
| 4 | Source mode and power | Not started |
| 5 | Carrier board, revision A, with the Pico 2 plugged in. Entry: the open checks that precede fabrication are closed and the layout is reviewed | Not started; draft A2 of the schematic and a board with every connection drawn exist, drawn ahead of the phases. The layout was reviewed with scripts and by calculation, and its seven deviations from section 10 are recorded decisions (D-87 to D-93); three decisions that follow the simulations are still to be drawn (D-95, D-96 and D-98), and the review by a person in KiCad and the open items remain |
| 6 | Calibration, protocol freeze and host software | Not started |
| 7 | Revision B and release | Not started |

Draft A2 is the hypothesis that the phases test: the component checks and
the results of phases 1 to 4 change it before revision A is fabricated.
The circuit simulations test the same hypothesis ahead of the bench, with
models in place of parts. They are not a phase and close none: a phase is
closed by measurements. The work that comes first is listed under
[Project Status](#project-status).

## Getting Started

```sh
git clone https://github.com/Guiimartinho/open-power-profiler.git
cd open-power-profiler
```

Start with the [specification](docs/specification.md). Each part of the
repository documents its own setup and commands:

| Part | Needs | Guide |
| --- | --- | --- |
| Firmware | CMake, Ninja and gcc for the unit tests | [`firmware/README.md`](firmware/README.md) |
| Host software | Python 3.10 or later | [`host/README.md`](host/README.md) |
| Protocol | Python 3.11 or later | [`protocol/README.md`](protocol/README.md) |
| Hardware | KiCad 10 | [`hardware/README.md`](hardware/README.md) |
| Board figures | Python 3.10 or later; KiCad 10 to dump the board file | [`tools/board/README.md`](tools/board/README.md) |
| Circuit simulations | Python 3.10 or later; the ngspice shared library, which KiCad 10 ships | [`simulation/README.md`](simulation/README.md) |
| Documentation | Node.js, for `npx --yes markdownlint-cli2@0.23.3` | [`CONTRIBUTING.md`](CONTRIBUTING.md) |

No instrument is needed to work on the software: the firmware logic runs in
unit tests on the PC, the host package talks to a simulator, the board
figures package is tested on small synthetic boards, and the circuit
simulations need only the ngspice library that KiCad installs.

## Engineering Practices

- Logic that does not need hardware is kept apart from the code that does,
  in firmware and in host software, and is covered by unit tests.
- The wire protocol has one definition. The constants of both sides are
  generated from it, and both codecs must reproduce the same test vectors.
- Seven continuous integration workflows, one per area (`Firmware`,
  `Host`, `Protocol`, `Tools`, `Simulation`, `Hardware`, `Docs`), build
  the firmware, run the tests with coverage floors, run the formatters and
  static analyzers and check the hardware project. The firmware build is
  still the one of the first plan, for the ESP32-S3, until the port to the
  Pico SDK. For now the workflows are started by hand, not on every push
  (D-22); the same checks run locally before a change is recorded.
- The board figures package in `tools/board/` has the gates of the host
  software: tests with a coverage floor of 90 % of lines and branches,
  ruff, mypy in strict mode, and the wheel built and installed. They ran
  locally on Windows; the `Tools` workflow, which repeats them on Linux
  and macOS too, has not been started yet.
- The simulation package in `simulation/` has those gates as well: 777
  tests, of which 11 need the ngspice library, ruff, and mypy in strict
  mode over the package, its tests and the benches. Lines and branches
  are covered in full against a floor of 90 %; the one module that loads
  the simulator runs in a child process and is outside that measurement.
  The gates ran locally on Windows with Python 3.11; the `Simulation`
  workflow has not been started yet. They cover the package, not the
  board: a figure that fails in a simulation breaks no gate. It is a
  finding, and it is kept.
- Timing, throughput and analog behavior are not claimed from tests. They
  are measured on the bench and recorded in a report. A simulation is
  filed as a simulation: it closes no check and no phase.

The rules are in section 18 of the [specification](docs/specification.md)
and in the [contributing guide](CONTRIBUTING.md).

## Documentation

- [System specification](docs/specification.md): requirements, analog and
  firmware architecture, pin map, host protocol, calibration, verification
  plan, risks and decision log.
- [Hardware guide](hardware/README.md) and
  [the draft in pictures](hardware/doc/README.md): the carrier board, sheet
  by sheet.
- [Firmware guide](firmware/README.md), [host guide](host/README.md) and
  [protocol guide](protocol/README.md): architecture, commands and tests of
  each part.
- [Simulation guide](simulation/README.md) and
  [simulation results](simulation/results/README.md): what the circuit
  simulations reproduce, the four points that are decided, where they
  differ from the text of the specification, the limits of the models, and
  every figure with its graph and its circuit file.
- [Open checks](docs/checks/README.md): what has to be confirmed, part by
  part and on the bench, before the schematic is frozen, and the records
  that accept a candidate part against its datasheet; none is filed yet.
- [Test reports](docs/reports/README.md): the measurements that close each
  phase; no report is filed yet.
- [Calibration](docs/calibration/README.md) and
  [protocol reference](docs/protocol/README.md): what the specification
  defines for each and what is not written.
- [Tools](tools/README.md): the board figures, which exist, and what the
  calibration tool and the production test will have to do; neither is
  started.
- [Board figures guide](tools/board/README.md): how the figures of the
  layout are calculated from the board file, with the method, the
  assumptions and the limits.
- [Documentation index](docs/README.md): every document of the repository
  and how they relate.
- [Changelog](CHANGELOG.md): notable changes by release.

## Contributing

Contributions are welcome. Read the [contributing guide](CONTRIBUTING.md)
first: it covers the workflow, the commit message format, the quality gates
and how changes to the specification are recorded.

## License

- Hardware design files under [`hardware/`](hardware/):
  [CERN-OHL-P v2](hardware/LICENSE).
- Everything else, including firmware, host software, tools and
  documentation: [MIT](LICENSE).

## Acknowledgments

- Inspired by
  [Gedankenn/power_profiller](https://github.com/Gedankenn/power_profiller),
  an ESP32 and INA226 power profiler with a web dashboard. This project
  started on the ESP32-S3 too, and was called `esp32-s3-power-profiler`
  until its controller changed.
- The feature set and the pin order of the connectors follow the Nordic
  Semiconductor Power Profiler Kit II (PPK2). This project is independent
  and is not affiliated with or endorsed by Nordic Semiconductor.
- The controller module is a Raspberry Pi Pico 2. This project is
  independent and is not affiliated with or endorsed by Raspberry Pi Ltd.

[badge-checks]: https://img.shields.io/badge/checks-run%20on%20demand-lightgrey
[badge-status]: https://img.shields.io/badge/status-early%20development-orange
[badge-mit]: https://img.shields.io/badge/software-MIT-blue
[badge-ohl]: https://img.shields.io/badge/hardware-CERN--OHL--P%20v2-blue

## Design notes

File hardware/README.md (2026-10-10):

# Hardware

The carrier board of the instrument: schematic, PCB layout and fabrication
outputs. The simulations of its circuits are a package of their own, in
[`../simulation/`](../simulation/README.md).

The instrument is two boards. A Raspberry Pi Pico 2, bought ready-made, is
the controller. It plugs into two rows of pin sockets on the carrier board
designed here, which holds everything else: power input, source meter, shunt
ladder, signal chain, side data and connectors. Sections 4.11 and 5 of the
[specification](../docs/specification.md) define the interface.

Rendered view of the carrier board, draft A2

The picture is a rendering from the KiCad files, with the Pico 2 on its
sockets. It is not a photograph: no board has been built.

## Status

Draft A2 with a reviewed layout, as of 2026-10-10. The KiCad project holds
the whole carrier board: the schematic with 428 parts on fifteen A4 pages
(the root sheet and fourteen sheets) and a four-layer board of
150 mm × 100 mm on which every connection is drawn. The board was placed by
a script and routed by an autorouter, which left 28 connections open. On
2026-10-10 its layout was reviewed with scripts: the open connections were
closed and the copper that an autorouter does not draw was drawn. Every
figure of the board in this guide is calculated from the drawn copper. On
the same day the circuits of the schematic were simulated from its netlist,
block by block; the central design figures of the specification come out
again ([Circuit Simulations](#circuit-simulations)). The simulations
raised four points, which the owner decided the same day: decisions D-95
to D-98 of the specification. Three of them change the circuit, the
fourth only the text of a position, and none is drawn yet, so the files
of this directory still show the earlier state
([Decisions That Follow the Simulations](#decisions-that-follow-the-simulations)).
Nobody has looked at the layout in the KiCad editor yet, no board is
built, and nothing is measured.

| What | State |
| --- | --- |
| Schematic | Every sheet drawn: 428 parts, 225 nets, 15 pages; not changed by the layout review. Three decisions of 2026-10-10 are not drawn in it yet (D-95, D-96, D-98) |
| Electrical rules check | 0 errors, 0 warnings |
| Netlist against datasheets | Checked independently; no blocker and no major defect found |
| Bill of materials | 151 lines, each with a part number and a maker; three lines without stock on 2026-10-09; not changed by the layout review. It still holds 1 nF at C32 to C34 and leaves R14 and C5 out (D-95, D-98) |
| Component checks | 0 closed; every part is a candidate |
| Board, placement | 425 footprints placed by a script; 35 of them moved or turned in the layout review; not reviewed by a person |
| Board, routing | 984 of 984 connections, none open: 8.38 m of track, 694 vias, 42 copper zones |
| Design rules check with schematic parity | 0 violations, 0 unconnected pads, 0 footprint errors, against a rule file that asks more than the one of the autorouted board |
| Layout review | Done with scripts and checked by independent calculation; not yet looked at by a person in the KiCad editor |
| 1 A path, copper only | 19.5 squares (10.4 mΩ at 40 °C) in source mode and 23.3 squares (12.3 mΩ at 40 °C) in ampere mode, against a limit of 30 squares; calculated from the drawn copper |
| Surface leakage into the measured node | 5.1 nA against a budget of 10 nA; calculated from the drawn copper with the assumptions of section 10.3 of the specification |
| Deviations from the words of section 10 | Seven, each recorded as a decision of the specification on 2026-10-10: D-87 to D-93 ([list](#decisions-of-the-layout-review-d-87-to-d-93)) |
| Open items of the layout | Eleven that need parts moved or another footprint, and five points that the review did not touch ([list](#open-items)) |
| Thermal check of the linear regulator | Open: the temperature rise of U18 at full dissipation is read on the first board (D-93) |
| Calculation scripts | In [`tools/board/`](../tools/board/README.md): they calculate the figures of the board again from the board file ([how](#reproducing-the-figures)) |
| Circuit simulations | Done on 2026-10-10 from the netlist of this schematic, in [`../simulation/`](../simulation/README.md): 134 benches, 93 on the circuits of the board and 41 on the models; 1834 figures pass, 122 fail and 1206 carry no limit. Every active part is a model written from its datasheet; nothing is measured |
| Decisions that follow the simulations | Four, decided by the owner on 2026-10-10: D-95 to D-98. Not drawn yet: 10 nF at C32 to C34 of the rail monitor, a position for a capacitor at the buffer U28, and the damper R14 and C5 fitted. The detector position U9 stays without a part ([list](#decisions-that-follow-the-simulations)) |
| PIO programs | Not written |
| Fabrication outputs | None |
| Measurements | None: no board has been built |

What the draft has behind it:

- The schematic passes the electrical rules check of KiCad with no errors
  and no warnings. The netlist that KiCad exports equals the netlist the
  drawings were generated from (428 parts, 225 nets), and every symbol pin
  has a pad in its footprint (65 pairs of symbol and footprint).
- The netlist was checked independently against the datasheets: symbol,
  footprint and ratings of every part type that is new in this draft, and
  six subsystems as a whole (power, source meter, ampere path, measuring
  chain, controller and logic, and the seams between the blocks). That
  check found no blocker and no major defect. It is not a component check:
  it closes no item of section 16 of the specification. Its notes are not
  filed in this repository, so the result can be read here but not
  inspected: it counts as a review, not as evidence.
- Every line of the bill of materials has a part number and a maker (151
  lines; section 17 of the specification).
- The board is fully connected: 984 of 984 connections. It passes the
  design rules check of KiCad with no rule violation, no unconnected pad
  and no difference between board and schematic ([Checks](#checks)).
- The layout was reviewed against the rules of section 10 of the
  specification: the 1 A path is drawn as pours, a guard surrounds the
  measured node, the Kelvin lines are drawn again, the 5 V rail is a pour
  and two layers carry ground fills. Each block was drawn with scripts and
  then calculated again by an independent check, and a final review of the
  whole board recorded 75 findings, of which 41 are open
  ([Layout Review](#layout-review)).
- The figures of the board are calculated from the drawn copper: squares
  and resistance of a pour, surface leakage with an assumed sheet
  resistance, lengths of tracks and distances between copper. None is a
  measurement. The scripts that calculate the resistance of the 1 A path,
  the lengths of the pairs, the vias on the sense nets and the surface
  leakage are in [`tools/board/`](../tools/board/README.md), so those
  figures can be calculated again from the board file
  ([Reproducing the Figures](#reproducing-the-figures)).
- The seven points in which the board departs from the words of section 10
  of the specification are decisions of the specification, D-87 to D-93,
  accepted by the owner on 2026-10-10 on the recommendation of the layout
  review. Sections 10.3, 10.4, 10.6 and 10.8 of the specification say what
  the board has
  ([list](#decisions-of-the-layout-review-d-87-to-d-93)).
- The circuits of the schematic were simulated in ngspice from its
  netlist, block by block: a bench names parts by their reference
  designators and their elements are written from a snapshot of the
  netlist, so no part of the board is typed by hand. What stands around
  the parts is typed by the bench: sources, loads, cables, and in some
  benches a stand-in for a neighboring block. The central design figures
  of the specification come out again: the shunts and the burden, gain,
  zero and settling of the chain, the thresholds and the jump path, the
  drop of requirement R-07, the set-point and the head room of the
  source, the in-rush at the output, the order of the rails and the
  limits of the power input. The models are written from datasheets, and
  41 benches put them into the test circuits of those datasheets
  ([Circuit Simulations](#circuit-simulations)).
- The notes on the sheets were compared with the specification figure by
  figure and corrected where they differed, and the pictures and the PDF of
  [`doc/`](doc/README.md) are plotted from the present files.

It is not a design to fabricate:

- Nothing has been built and nothing has been measured. Every figure in
  these documents is a datasheet value, a calculation, a simulation or an
  estimate; the specification says which.
- The parts are the candidates of the specification. No component check of
  [`docs/checks/`](../docs/checks/README.md) is closed, and the open checks
  of section 16 of the specification stand, the bench items among them.
- The layout review was done with scripts. Nobody has opened the board in
  the KiCad editor and looked at it as a person does before ordering
  boards.
- Eleven items of the layout are open because they need parts moved or
  another footprint, the loops of the converter capacitors among them, and
  five points of section 10 were not touched by the review, the legends of
  the silkscreen among them.
- The temperature rise of the linear regulator U18 at its full dissipation
  is an open check of section 16 of the specification, to be read on the
  first board: the island of output copper on the top layer is smaller
  than the one the datasheet figure stands for (D-93).
- A simulation is not a measurement. Every active part in it is a model
  written from a datasheet, typical and at room temperature; the layout,
  leakage at the nanoampere level and temperature are not in it, and the
  range sequencer is a model of the firmware rules F-16 to F-18, because
  its program does not exist.
- Three decisions that follow the simulations are not drawn: 10 nF at
  C32 to C34 (D-95), a position for a capacitor at U28, which needs a
  footprint that the board does not have (D-96), and the damper R14 and
  C5 fitted (D-98)
  ([Decisions That Follow the Simulations](#decisions-that-follow-the-simulations)).
- In fourteen places the simulation and the text of the specification
  differ. The simulation round proposes no change of hardware for them;
  that decision is the owner's, and the text of the specification stands
  until it is taken.
- The helpers that drew the layout are not in this repository. The board
  file is the record of what was drawn.
- The range logic and the sampling clock are programs for the PIO blocks of
  the controller. They are not written yet; until they are, the pin
  assignment of the controller is provisional.
- Three positions carry no part in the drawn state. They are marked "do
  not populate" and are left out of the bill of materials: a voltage
  detector at the enable pin of the boost converter (U9) and the two
  parts of a damper on the module input (R14, C5), each drawn as the
  remedy for a bench item of section 16 (decision D-84). Two decisions
  change that, and neither is drawn yet: the damper is fitted (D-98), and
  U9 stays without a part but is no longer meant for the 803 type with
  its time-out of 0.24 s (D-97).
- Three lines of the bill of materials had no stock at an authorized
  distributor on 2026-10-09: the 1.5 µH inductor of the pre-regulator
  (L2, Coilcraft XFL4020-152MEC; Würth 74438356015 fits the same pads)
  and the capacitors Samsung CL21A106KAYNNNE and CL31A226KAHNNNE.
- The land pattern of the pre-regulator (U16) is a library footprint
  whose lead pads agree with the drawing of the manufacturer; its center
  pad is larger than the drawing asks for (1.7 mm × 3.3 mm against
  1.58 mm × 2.85 mm), which is accepted.
- KiCad has no 3D model of the lever terminal block, so the pictures show
  only its pads. The side its wires enter from was taken from the
  footprint, not from the drawing of the manufacturer.

## Layout

| Path | Content |
| --- | --- |
| `kicad/` | KiCad 10 project: schematic sheets, board, design rules and library tables |
| `kicad/lib/` | Project symbol and footprint libraries |
| `doc/` | Pictures of every schematic sheet and of the board, the schematic as PDF, and the bill of materials of the draft as CSV |
| `fabrication/` | Outputs of each revision: Gerber and drill files, bill of materials, placement (empty until a revision is fabricated) |

The simulations are not in this directory. They are a package of their own
at the root of the repository, [`../simulation/`](../simulation/README.md),
by decision D-94: it reads a snapshot of the netlist of this schematic and
holds the models, the benches and their results.

## KiCad Project

Open `kicad/power-profiler-carrier.kicad_pro` with KiCad 10. To look at the
design without KiCad, see [`doc/`](doc/README.md): every sheet with a
description and the board as pictures, and
[`doc/schematic.pdf`](doc/schematic.pdf).

The board carries the name of the project: the silkscreen text at its
bottom edge reads "Open Power Profiler - Carrier Board   rev A2 draft",
and the title blocks of the board file and of the root page of the
schematic read "Open Power Profiler - Carrier Board". The schematic PDF and
the picture of its root page were exported again with that title; the
other fourteen pages are unchanged.

### Schematic

| Page | Sheet | File | Content |
| --- | --- | --- | --- |
| 1 | Root | `power-profiler-carrier.kicad_sch` | One block per sheet and the wires between them |
| 2 | Controller | `controller.kicad_sch` | Raspberry Pi Pico 2 on its sockets, supply of the module, pull and series resistors of the SPI and acquisition lines, series resistors of the two status lines, reset button, console header |
| 3 | Power Input | `power_input.kicad_sch` | USB-C power connector, one current limiter per USB input, priority multiplexer that drives the 5 V rail |
| 4 | Logic Supplies | `logic_supplies.kicad_sch` | Supervisor of the 5 V rail, the two 3.3 V regulators, power LED, mounting holes, fiducials |
| 5 | Analog Rails | `analog_rails.kicad_sch` | +13.5 V boost, +12 V and −4 V rails with their clamps, 2.5 V reference |
| 6 | Rail Monitor | `rail_monitor.kicad_sch` | Four comparators that watch the analog rails and the reference: PWR_GOOD |
| 7 | Source Meter | `source_meter.kicad_sch` | Pre-regulator that tracks the output, linear regulator with its clamps, DAC and set-point amplifier |
| 8 | Path Switching | `path_switching.kicad_sch` | Source and ampere mode switches with their gate networks and interlock, VIN input and its protection |
| 9 | Shunt Ladder | `shunt_ladder.kicad_sch` | Four shunts, range switches with their drivers, ladder clamp, Kelvin multiplexer |
| 10 | Output Stage | `output_stage.kicad_sch` | Output switch with slow turn-on, DUT connectors and their suppressor, guard buffer |
| 11 | Signal Chain | `signal_chain.kicad_sch` | Instrumentation amplifier, pedestal, limiter on its own driver rail, filter, converter, shield can |
| 12 | Comparators | `comparators.kicad_sch` | Step up, over-current and jump thresholds |
| 13 | Side Data | `side_data.kicad_sch` | Two shift registers: status and logic inputs of every sample |
| 14 | Digital Inputs | `digital_inputs.kicad_sch` | Logic port, protection, series resistors and pull-downs, level translator |
| 15 | Monitors | `monitors.kicad_sch` | Eight slow channels and the temperature sensor |

Drawing conventions:

- Every page is A4.
- Connections inside a sheet are wires. Supply rails use power symbols.
- A signal that goes to another sheet ends on a hierarchical label, and the
  root sheet joins the sheets with wires.
- Reference designators are numbered as the annotation tool of KiCad does by
  default: one count per prefix (`R1`, `R2`, ... and `C1`, `C2`, ...), in the
  order of the sheets, and on a sheet by position (decision D-45).
- Each sheet carries notes with the design values of its block. In the
  notes, "range 0" to "range 3" are the four current ranges, so that they
  are not taken for resistors. On the Digital Inputs sheet, "D0" to "D7"
  are the logic inputs, named as on the logic port of the PPK2: they are
  not diodes.
- A part drawn with a cross is a position without a part.

Supply rails:

| Rail | Source | Feeds |
| --- | --- | --- |
| `+5V` | Priority multiplexer: the USB-C connector of the carrier through a 2.0 A limiter, or the USB connector of the Pico 2 through a jumper and a 0.76 A limiter | Every converter and regulator, the supervisor, and the Pico 2 through a diode |
| `+13V5` | Boost converter, running whenever `+5V` is present | +12 V_A regulator, control pin of the output regulator |
| `+12V_A` | Low-noise regulator | Amplifiers, multiplexer, gate drivers, buffers |
| `-4V_A` | Inverting charge pump with regulator | Amplifiers, multiplexer, buffers, minimum load of the output regulator |
| `+3V3_A` | Low-noise regulator | Converter, comparators, DAC, monitor, reference, buffer of the driver rail, tracking amplifier of the pre-regulator, temperature sensor |
| `+3V3_C` | Regulator | Logic of the carrier, rail monitor, power LED |
| `VREF` | 2.5 V reference, supplied from `+3V3_A` | Converter, DAC, monitor, thresholds, pedestal, driver rail |

A supervisor on `+5V` enables both 3.3 V regulators, the +12 V_A regulator,
the charge pump and, through a transistor, the pre-regulator: below 3.83 V
to 4.00 V on the rail (calculated) the carrier is off, with no firmware
involved (decision D-48). The power tree with its thresholds and its
start-up order is in section 3 of the specification.

The bill of materials is generated from the schematic, in which each of
its parts carries the fields `MPN` and `Manufacturer`: one line per part
number, 151 lines for 368 parts. The positions without parts, the test
points, the mounting holes, the fiducials and the solder jumpers are not
in it. The list of this draft is filed as [`doc/bom.csv`](doc/bom.csv);
to make it again, from `kicad/`:

```sh
kicad-cli sch export bom --output ../doc/bom.csv --fields 'Reference,Value,Footprint,MPN,Manufacturer,${QUANTITY}' --group-by 'Value,Footprint,MPN,Manufacturer' --exclude-dnp power-profiler-carrier.kicad_sch
```

### Board

`power-profiler-carrier.kicad_pcb` is linked to the schematic: every
footprint has its nets and its symbol. All 984 connections are drawn. The
figures of this section are counted or calculated from the board file;
none is measured.

- Outline 150 mm × 100 mm with a corner radius of 3 mm and four M3 holes
  (decision D-85).
- Four copper layers, used as the table below says. All 425 footprints are
  on the top side. The schematic has 428 parts: the two sockets of the
  module (MP1, MP2) sit in the holes of the module footprint, and the cover
  of the shield can (MP3) snaps onto its frame, so these three have no
  footprint of their own.
- The stackup in the board setup is the build that section 10.1 of the
  specification assumes until a manufacturer is chosen: 1.6 mm, 35 µm
  outer and 17.5 µm inner copper, 0.2 mm of dielectric between each outer
  layer and the inner layer next to it, gold finish (ENIG).
- Back edge, on the left: the USB connector of the Pico 2, which lies along
  the top edge, and below it the USB-C power connector.
- Front edge, on the right, from the top: the logic port, the DUT pin header
  and the DUT lever terminal block, each with the names of its pins; the
  limits of VOUT and VIN are printed below the terminal block.
- The rectangles on the `Dwgs.User` layer are the areas of the sixteen
  functional blocks. They follow section 10.1 of the specification: the
  switching converters in the left third, the front end right of center
  under the frame of a shield can, the 1 A branch of the ladder between the
  can and the terminal block.
- Net classes for the 1 A path, the supply inputs, the switch nodes, the
  rails, the sense and guard nets, the gate nodes and the clocked lines are
  defined in the project file, thirteen with the default class. The file
  `power-profiler-carrier.kicad_dru` adds the clearances that a net class
  cannot express ([Design rules check](#design-rules-check)). The classes
  are bound to the names of the nets: after a change to the schematic,
  check that the nets of the 1 A path still have their class.

Placement of the functional blocks

#### Placement

The parts were placed by a script, from the netlist and from a table that
gives each part the pin it serves and its largest distance from it.
Connectors, mounting holes, fiducials and the frame of the shield can stand
at fixed coordinates. The result of the run that placed this board:

- Every part is inside the rectangle of its block, no courtyard overlaps
  another, and nothing stands under the controller module.
- Only the 58 parts of the front end are inside the frame of the shield
  can.
- 95.9 % of the 370 distances of the table are kept, taken as the copper
  gap between the two pads, and so are those of all 47 decoupling
  capacitors.

The layout review moved or turned 35 of the 425 footprints, 33 of them by
2.75 mm or less. Two moved farther: the test point of VOUT, TP38, by
11.2 mm onto the pour of VOUT, and the suppressor of VOUT, D21, by 8.6 mm.
No part was added or removed. The reference designators of 123 parts are
hidden on the silkscreen, where no free place was left beside the part (115
after the placing run); they are on the fabrication layer. Nobody has
reviewed the placement by hand, and several
[open items](#open-items) of the layout are placement changes.

#### Routing

The board was first routed automatically with FreeRouting 2.5.0, through a
Specctra export of the placed board and an import of the session file
(decision D-86), in several runs that each continued from the board of the
run before. That autorouted board connected 956 of the 984 connections and
left 28 open, 25 of which broke a function: the 5 V rail was in pieces,
neither mode had a complete current path, and one Kelvin sense line of the
0.1 Ω shunt had no track. Its power nets were tracks of 0.4 mm and 0.5 mm.

The layout review of 2026-10-10 continued from that board. It closed the 28
connections and drew the copper that an autorouter does not draw
([Layout Review](#layout-review)). The board before and now:

| Item | Autorouted board | Now |
| --- | --- | --- |
| Connections | 956 of 984, 28 open | 984 of 984, none open |
| Tracks | 7.83 m in 3,228 segments | 8.38 m in 3,716 segments |
| Vias | 499, of which 26 of 0.8 mm with a 0.4 mm hole | 694: 594 of 0.6 mm with a 0.3 mm hole and 100 of 0.8 mm with a 0.4 mm hole; 336 of them on ground |
| Copper zones | 1, the ground plane | 42: the pours of the 1 A path, the pours of the converters, the 5 V rail, the guard, the ground fills |
| Ground plane | One piece | One piece of 14,205 mm², no track on its layer |
| Ground fills | None | 10,891 mm² on the second inner layer and 12,108 mm² on the bottom layer, stitched to the plane with 41 added vias |
| 5 V rail | Tracks of 0.4 mm | A pour of 1,623 mm² on the second inner layer, in three pieces |
| Reference designators hidden on the silkscreen | 115 | 123 |

The layers as they are used now:

| Layer | What it carries |
| --- | --- |
| `F.Cu`, top | All parts; the pours of the 1 A path and of the converters; the Kelvin lines; the guard ring and its pour; 3.76 m of track |
| `In1.Cu`, first inner layer | The ground plane: one piece, no track. The clearances of vias and through-hole pads open 787 mm² of it in all (593 mm² on the autorouted board, which had 499 vias) |
| `In2.Cu`, second inner layer | The pour of the 5 V rail; 2.84 m of track, among them rail trunks, 41 mm of the ladder output and 64.8 mm of the guard; a ground fill, which those tracks cut into 80 pieces |
| `B.Cu`, bottom | 1.79 m of track; the second layer of the supply band of the 1 A path; the output island of the linear regulator; the two pieces of the 1 A path that have no room on top; the output pour of the pre-regulator; four guard pours under the measured node; a ground fill |

The four copper layers

The picture shows the four copper layers side by side, plotted from the
board file: top, ground plane, second inner layer, bottom. Two details of
the top layer are in the next section: the measured node under the shield
can ([`board-front-end.png`](doc/images/board-front-end.png)) and the 1 A
path ([`board-1a-path.png`](doc/images/board-1a-path.png)). The rendered
views are in [`doc/`](doc/README.md); in the top view the gold line around
the front end is the guard under open solder mask.

#### Design Rules Check

The design rules check of KiCad, with schematic parity, reports on this
board 0 rule violations, 0 unconnected pads, 0 footprint errors and 0
differences between board and schematic. The commands are under
[Checks](#checks).

The rule file was rewritten in the layout review and has thirteen rules
now. It asks more than the file the autorouter ran against, so the result
above is not the same statement as "0 violations" on the autorouted board.
In plain words:

- Copper of different nets keeps 0.15 mm, except from pad to pad inside a
  footprint.
- The larger spacings (1 A path, switch nodes, measured node, gate nodes,
  VIN) still leave out a track that touches the courtyard of a footprint,
  because at the pins of a part the pad pitch decides. That exemption now
  applies on the top layer only. Before, it also freed copper on the other
  layers under a part, although every part is on the top side.
- The measured node keeps 0.5 mm from foreign nets on the bottom layer too,
  and there the rule also covers the ladder output.
- The copper fills of other nets keep 1.0 mm from the measured node on the
  two outer layers. On the inner layers a via of the measured node opens
  the ground plane by the normal clearance and not by a hole of 2.6 mm.
- The pours of the measured node keep 1.0 mm from ground and rail copper
  on the outer layers, pads included: a ground pad beside such a pour is a
  leakage path into the node.
- Gate nodes keep 0.5 mm from other nets on both outer layers.
- The VIN input keeps 1.0 mm from other nets on the outer layers and 0.5 mm
  on the inner layers. Section 10.4 of the specification says 1.0 mm from
  every other net.
- The guard may run 0.2 mm beside the measured node: it is driven to the
  potential of that node.

The rewritten rule file is decision D-87, the first of the
[decisions of the layout review](#decisions-of-the-layout-review-d-87-to-d-93).
Two things it does not check: no rule counts the vias on a sense net or on
a guarded net, and no rule spaces the measured node from other copper on
the inner layers, where 41 mm of the ladder output run with the ground fill
0.15 mm beside them. Both were checked by calculation instead.

The project ignores five checks of KiCad, the same five as on the
autorouted board: a footprint without a courtyard, a track end that is not
centered on a via, the tuning profiles, the footprint filters of the
symbols, and the component type of a footprint against its pads.

### Layout Review

The layout was reviewed on 2026-10-10 with scripts that work on the KiCad
board file, block by block. Each block was drawn against the rules of
section 10 of the specification and then checked by an independent check
that calculated every rule again. After that the whole board went through a
final review by rule group, with each finding checked by a second reviewer.
A repair round followed for the leakage paths into the measured node that
this review found, and a last pass calculated every finding again on the
final board.

The final review recorded 75 findings. On the final board 15 of them are
fixed, 16 are improved, 41 are open and 3 are not defects. The sections
below group them: the results by rule, the seven decisions that the review
led to, the open items, and what the review did not touch.

What the review is and is not:

- It is a drawn and calculated layout. Every figure below is calculated
  from the drawn copper with scripts; the level of evidence is a
  calculation, in a few places with stated assumptions.
- It is not a look at the board by a person. Nobody has opened it in the
  KiCad editor.
- Nothing is built and nothing is measured. Every part is still a
  candidate.
- The scripts that calculate the figures are in this repository
  ([Reproducing the Figures](#reproducing-the-figures)). The helpers that
  drew the layout are not.

#### Reproducing the Figures

The package [`tools/board/`](../tools/board/README.md) calculates the
figures of the layout from the board file: the resistance of the copper of
a net between pads, a path on one layer alone, the lengths of the two lines
of a pair along their center lines, the vias on the sense and guarded nets,
and the surface leakage into the measured node. What is specific to this
board (the pieces of the 1 A path, the three pairs, the nets of the
measured node, the assumed voltages, the rectangle of the shield can) is in
`tools/board/carrier.toml`. The package is tested on small synthetic
boards with answers known by hand, without KiCad and without hardware.

Three steps, each described in the
[README of the package](../tools/board/README.md):

1. Install the package into an environment of its own, from `tools/board/`.
2. Dump the board file to JSON with `tools/board/kicad/dump_board.py`. This
   step runs under the Python that KiCad installs, because it reads the
   board with KiCad's own module. Fill the zones and save the board first.
3. Run `board-figures report` on the dump.

From the root of the repository:

```sh
"$KICAD_PYTHON" tools/board/kicad/dump_board.py hardware/kicad/power-profiler-carrier.kicad_pcb tools/board/board.json
cd tools/board
python -m venv .venv
.venv/Scripts/python -m pip install -e ".[dev]"
.venv/Scripts/board-figures report board.json
```

`KICAD_PYTHON` stands for the path of the Python interpreter of the KiCad
installation. On Linux and macOS the folder of the environment is
`.venv/bin/` in place of `.venv/Scripts/`. The report reads
`carrier.toml` from the working directory, which is why it runs in
`tools/board/`. On the board in this directory the report prints:

| Figure | Report |
| --- | --- |
| 1 A path, source mode | 19.5 squares, 10.4 mΩ at 40 °C, with its seven pieces |
| 1 A path, ampere mode | 23.3 squares, 12.3 mΩ at 40 °C, with its eight pieces |
| Surface leakage, top layer | 4.46 nA, of which 0.73 nA inside the shield can |
| Surface leakage, bottom layer | 0.67 nA, of which 0.00 nA under the can |
| Kelvin pair of range 3 | 46.31 mm and 45.42 mm, difference 0.89 mm |
| Kelvin pair of range 2 | 28.35 mm and 27.78 mm, difference 0.56 mm |
| Pair from the multiplexer to the amplifier | 17.01 mm and 17.89 mm, difference 0.88 mm |
| Sense and guarded nets | 10 of 11 without a via |

The report also gives the share of the track length at the class width,
the tracks near the mounting holes and the ground vias at the lands of the
shield can. The other figures of this guide (the loops of the converters,
the 5 V rail, the copper of the reference, distances between copper) are
calculated with the commands `squares` and `path` of the package, one net
at a time, or were calculated in the review and are not part of the report.

The limits of the calculation:

- The resistances are calculated on a grid of 0.1 mm. On a grid of 0.05 mm
  the two sums read about 2 % higher: 19.9 squares and 23.8 squares.
  Compare figures made with the same grid only.
- A via counts 1.7 squares for each step from one layer to the next. That
  overstates a via, so the figure errs to the high side.
- The resistances count copper only: the transistors, the shunt, the fuse
  and the terminal are not in them, nor are solder and the heating of the
  copper by its own current.
- The leakage figure is converged at its grid of 0.04 mm. It rests on an
  assumed sheet resistance of 10¹¹ Ω per square and on assumed voltages.
  It leaves out the solder mask, flux residue, moisture and dust, the
  leakage through the laminate to the inner layers, and the leakage of the
  parts themselves. A real surface can be orders of magnitude off the
  assumed value in either direction: the figure ranks layouts and shows
  where the current would come from, and it is not an error budget.
- Every figure compares one layout with another. None predicts what a
  bench will read, and a measurement replaces it.

The helpers that drew the layout (the routing and merging scripts of the
review) are not in this repository; the board file is their result. The
simulations of the circuits are filed and can be run again
([Circuit Simulations](#circuit-simulations)).

#### Results by Rule

The column "Autorouted board" gives the figure of the board before the
review where one was calculated. Where it says "at the final review", the
figure is that of the board after the blocks were drawn and before the
repair round.

| Rule | Limit in the specification | Autorouted board | Now |
| --- | --- | --- | --- |
| 1 A path in source mode, output of the linear regulator to the VOUT terminal | 30 squares of 35 µm copper (10.4) | 397 squares, about 211 mΩ | 19.5 squares, 10.4 mΩ at 40 °C |
| 1 A path in ampere mode, VIN terminal to the VOUT terminal | 30 squares of 35 µm copper (10.4) | 217 squares, about 116 mΩ | 23.3 squares, 12.3 mΩ at 40 °C |
| Surface leakage into the measured node | Leakage budget of 10 nA (4.3, 10.3) | Not calculated; about 20 nA at the final review (top layer 11 nA, bottom layer 9 nA) | 5.1 nA: top layer 4.46 nA, bottom layer 0.67 nA |
| Sense and guarded nets without a via | No via (10.3) | Not counted; one sense line of the 0.1 Ω shunt had no track | 10 of 11 on the top layer without a via; the eleventh keeps two vias and 1.9 mm on the second inner layer |
| Kelvin pair of range 3, 0.1 Ω shunt to the multiplexer | Tracks of 0.2 mm at a gap of 0.2 mm, one layer, equal within 1 mm, no via (10.3) | One of the two lines open | 46.3 mm and 45.4 mm, 0.9 mm apart in length; side by side at 0.2 mm over 83 % of the run; one line has the two vias |
| Kelvin pair of range 2, 1 Ω shunt to the multiplexer | As above | Not calculated | 28.4 mm and 27.8 mm, 0.6 mm apart in length; top layer, no via; not side by side |
| Pair from the multiplexer to the amplifier | As above | Not calculated | 17.0 mm and 17.9 mm, 0.9 mm apart in length; side by side over about 4 mm only |
| Taps of range 0 (1 kΩ) and range 1 (33 Ω) | Sensed at the pads, the tap leaving the pad as its own track (10.3) | Not calculated | Each tap leaves its pad as its own track, then runs through a via and 12 mm and 10 mm on the second inner layer; not pairs |
| Guard | A closed track of 0.5 mm on the top layer, no solder mask over it (10.3) | None | One piece of copper: three arcs on the top layer, joined through 11 vias on the other layers; inside the can 109 mm at 0.5 mm, 24 mm at 0.25 mm and 7 mm at 0.15 mm; solder mask open over 160 of 190 mm (84 %); a guard pour of 227 mm² |
| Ground copper beside the pours of the measured node, outside the can | 1.0 mm (10.3) | Not calculated; 0.15 mm at the final review | None within 1.0 mm; the ground pad of the VOUT suppressor is 1.55 mm away |
| Gate node of the output switch to VOUT copper | 2 mm except at the gate pins (10.3) | Not calculated; 0.56 mm at the final review | 2.0 mm or more except at the two gate pins |
| Test point of VOUT, TP38 | 3 mm or more from any other pad (10.7) | Not calculated; 1.50 mm at the final review | On the VOUT pour, 3.03 mm from the nearest pad |
| Ground via at each land of the shield can | One beside each land (10.3) | Not counted | All 32 lands have a ground via within 1.5 mm |
| Pre-regulator, switch nodes and ground pad | Short pours from pad to pad; six vias in the power ground pad (10.5) | Tracks | Both switch nodes are pours without a via; six vias in the pad |
| Pre-regulator, feedback line | 20 mm or less (10.5) | Not calculated | 16.4 mm |
| Pre-regulator, copper from the output capacitors to the bead | 15 mΩ or less (10.5) | Not calculated | 13.4 squares, 7.1 mΩ, on the bottom layer through groups of vias |
| Pre-regulator, loops of its five capacitors | 5 mm or less on the top layer (10.5) | Not calculated | 8.2 mm to 17.1 mm: not kept |
| Pre-regulator, inductor to the switch pins | Within 3 mm (10.5) | Not calculated | 4.5 mm from its second pair of switch pins: not kept |
| Boost converter, loop of switch pin, diode, output capacitor and ground pin | Within 5 mm (10.5) | Not calculated | 6.8 mm through the 10 µF capacitor and 10.3 mm through the 100 nF capacitor: not kept |
| Boost converter, output to the filter resistor of the +12 V regulator | One track of 25 mm or more (10.5) | Not calculated | One track of 28.8 mm |
| Charge pump, capacitors to their pins | Within 2 mm (10.5) | Not calculated; two of its connections were open | Flying capacitor and supply sides 0.9 mm to 1.3 mm; the ground sides of two capacitors 3.4 mm and 4.4 mm: not kept |
| +12 V regulator | Output sense pin routed to the pad of the output capacitor; a guard track around the copper of the SET pin (10.5) | Not checked | Sense pin routed to the pad; +12 V copper faces 75 % of the contour of the SET copper and is open at the pins |
| 5 V rail, bulk capacitor to the input capacitors of the pre-regulator | 10 mΩ, a target of the layout review; the specification gives no figure (10.1) | Tracks of 0.4 mm, the rail in pieces | 2.7 mΩ and 3.0 mΩ |
| 5 V rail, bulk capacitor to the input capacitor of the boost converter | 25 mΩ, a target of the layout review; the specification gives no figure (10.1) | Tracks of 0.4 mm, the rail in pieces | 3.6 mΩ |
| Reference | The output pin is the star point; the branches share no track (10.5) | Not checked | Ten branches that share no track beyond the star copper; that copper, 5.7 mm long, is common to several: 2.2 mΩ between the branch of the ADC and the pedestal divider |
| Track widths | The width of the net class | Rails, guard nets and gate drivers 0.25 mm or less; power nets 0.4 mm and 0.5 mm | Share of the track length at the class width or wider: rails (0.4 mm) 62 %, gate drives (0.3 mm) 71 %, power input nets (1.0 mm) 34 %, sense nets (0.2 mm) 100 % |
| Thermal reliefs | Only on the ground pads of through-hole parts; none on a pad of the 1 A path (10.4, 10.6) | Not checked; 21 such pads joined solid into the plane at the final review | Reliefs on the through-hole ground pads of the connectors, the module sockets and the reset switch, in the plane and in the fills; the pads of the 1 A path joined solid |
| Mounting holes | No track on an outer layer within 4.0 mm of the center (10.1) | Not checked | Kept |

#### The 1 A Path

The 1 A path on the top layer

The picture is the top layer from the linear regulator at the bottom left,
along the supply band to the shunt branch, the output switch and the
terminal block on the right. The path is drawn as pours on the top layer.
The supply band, 38 mm from the source pair to the shunt branch, is doubled
on the bottom layer through groups of four to eight vias of 0.8 mm with a
0.4 mm hole. The linear regulator U18 stands on an island of output copper:
291 mm² on the bottom layer and 102 mm² on the top layer, joined by 22
vias.

The pieces, in squares of 35 µm copper, calculated from the drawn copper:

| Piece | Source mode | Ampere mode |
| --- | --- | --- |
| Output of the linear regulator to the source pair | 2.2 | |
| Common source of the source pair | 0.4 | |
| VIN terminal to the fuse | | 3.5 |
| Fuse to the ampere pair | | 8.0 |
| Common source of the ampere pair | | 0.3 |
| Supply node | 6.5 | 1.0 |
| Range 3 transistor to the 0.1 Ω shunt | 1.3 | 1.3 |
| Ladder output, from the shunt to the output switch | 5.6 | 5.6 |
| Common source of the output pair | 0.6 | 0.6 |
| VOUT to the terminal | 2.9 | 2.9 |
| Sum | 19.5 | 23.3 |
| Resistance at 40 °C | 10.4 mΩ | 12.3 mΩ |

The pieces are printed to one decimal. The pieces of ampere mode add to
23.25 squares before that rounding, which is 23.3 squares.

The figures count copper only: the transistors, the shunt, the fuse and
the contacts are not in them. They end at the poles of the terminal block,
where R-06 takes the path drop. The pin header is fed from the terminal
block through two tracks of 1.0 mm, 10.2 mΩ on VOUT and 11.2 mΩ on VIN
(calculated): a load on the pin header sees about 21 mΩ more copper than a
load on the terminal block.

The tracks of the 1 A net classes that remain on the board are taps and
links, not the path. In the last step of the review 1,069 tracks of the
board were widened toward the width of their net class where the copper
around them left room, and the 41 track ends that entered 19 pads wider
than the pad were necked down to the pad.

#### The Measured Node

The measured node under the shield can

The picture is the top layer under the shield can in red, with the
openings of the solder mask in pink: the guard ring, the guard pour, the
Kelvin lines from the multiplexer to the shunts, and the lane of the
range 3 pair outside the can.

Surface leakage. The figure of 5.1 nA is calculated with the assumptions
that section 10.3 of the specification uses: 10¹¹ Ω per square on a clean
surface, 5 V to ground and logic, 7 V to the +12 V rail and to gate nodes,
9 V to the −4 V rail. Solder mask, cleanliness and humidity are not
modeled. Of the 4.46 nA on the top layer, 0.73 nA are inside the shield can
and 3.73 nA outside; of the 0.67 nA on the bottom layer, 0.00 nA are under
the can. The largest shares:

| From | Share |
| --- | --- |
| Gate of the output pair | 1.35 nA |
| Ground | 1.32 nA |
| Copper of the VIN terminal | 0.98 nA |
| Gate of the range 3 transistor | 0.62 nA |
| +12 V at pin 14 of the multiplexer | 0.47 nA |
| −4 V at pin 2 of the guard buffer | 0.26 nA |

Almost all of it is the pitch of pads: the gate beside the source in the
transistor package, the poles of the two DUT connectors, neighboring pins
of the multiplexer and of the guard buffer. No track can change that; what
is left is another footprint or cleaning. An estimate made before the board
was drawn gave 1.3 nA to 2.9 nA; section 10.3 of the specification now
carries the figure calculated from the board and names that estimate.

Sense lines. Ten of the eleven sense and guarded nets are on the top layer
without a via. The eleventh is the high-side sense line of the 0.1 Ω shunt:
with the pin order of the multiplexer and the pad order of the
four-terminal shunt, the two lines of that pair have to cross once, and no
rotation of a part changes that. The lengths in the table are taken along
the center lines from pad edge to pad edge. The pair of range 2 is equal in
length but not side by side, because the pair of range 3 runs between its
two lines under the multiplexer. The pair to the amplifier is side by side
over about 4 mm only, because its pins are on opposite sides of both
packages.

Guard. The guard is the buffered ladder output and is one piece of copper.
On the top layer it is three arcs around the measured node inside the can.
They are cut where the measured node itself leaves through the wall: the
ladder output, the supply node and the range 3 pair. A guard track runs on
both sides of each exit, and along both sides of the range 3 pair outside
the can as far as the shunt. The arcs are joined through 11 vias, with
12.8 mm of track on the bottom layer and 64.8 mm on the second inner layer,
of which 53 mm are the feed of the monitor. Four guard pours on the bottom
layer surround the via pads of the measured node. The solder mask stays
closed over the guard at the six wall crossings and between pads on
purpose, and no bare guard lies within 0.3 mm of a land of the can. The
free top copper inside the ring is a guard pour, under solder mask except
at the ring. Inside the ring there is no ground pour, but 29 pads of 10
foreign nets stand there, the supply, address and enable pins of the
multiplexer and their parts, and 18 vias.

Off the top layer. The ladder output has no track on the bottom layer any
more (37 mm at the final review). It has 41 mm on the second inner layer:
the two taps and the load track of the 1 Ω shunt, with the inner ground
fill 0.15 mm beside them, which is laminate and not a surface. Its six via
pads on the bottom layer stand in guard pours; the nearest foreign copper
to one of them is 0.81 mm away.

#### Decisions of the Layout Review (D-87 to D-93)

The reviewed board departs in seven points from what section 10 of the
specification said before the review. The owner accepted the
recommendation of the layout review on all seven on 2026-10-10. They are
recorded in the decision log of the specification (section 15) as D-87 to
D-93, and sections 10.3, 10.4, 10.6 and 10.8 of the specification now
describe the board as it is drawn. The log has 98 decisions. The last
five are not of the layout: D-94 places the circuit simulations, and D-95
to D-98 are the decisions that followed them.

Each point below quotes the sentence that section 10 carried before the
review, says what the board has and why, and names the decision. The
figures in the reasons are calculated from the drawn copper; a decision
accepts a drawn layout, not a measured one.

1. **The rule file (D-87).** `kicad/power-profiler-carrier.kicad_dru` was
   rewritten, as [Design Rules Check](#design-rules-check) says rule by
   rule. Section 10.4 said of the VIN copper that it "keeps 1.0 mm from
   every other net"; the rule file asks 1.0 mm on the outer layers and
   0.5 mm on the inner layers. Reason: an inner layer has no surface that
   joins the two nets, and the larger spacing there only opens the ground
   plane. The other changes make the file stricter, or let the guard run
   0.2 mm beside the node it guards. A custom rule that matches replaces
   the clearance of a zone and of a net class, and the old exemption near
   pins had hidden 32 places where the measured node or the VIN input
   stood too close to other copper. The decision: the rule file states
   every spacing that the layout needs. The exemption near pins applies on
   the top layer only; the 0.5 mm of the measured node apply on the bottom
   layer too, there also to the ladder output; gate nodes keep 0.5 mm on
   both outer layers; the VIN input keeps 1.0 mm on the outer layers and
   0.5 mm on the inner layers; copper fills keep 1.0 mm from the measured
   node on the outer layers; the pours of the measured node keep 1.0 mm
   from ground and rail copper, pads included; the guard may run 0.2 mm
   beside the measured node.
2. **Vias on one sense line (D-88).** Section 10.3 said "No via on a
   sense net or on a guarded net." The high-side sense line of the 0.1 Ω
   shunt R110 has two, with 1.9 mm on the second inner layer at the shunt.
   Reason: the pin order of the multiplexer against the pad order of the
   four-terminal shunt forces the two lines of the pair to cross once, and
   no rotation of a part changes that. The decision: that line keeps its
   two vias and its 1.9 mm on the second inner layer, and its two via pads
   on the bottom layer stand in a guard pour. It is the one sense net with
   a via.
3. **Kelvin pairs (D-89).** Section 10.3 asked for "a tightly coupled pair
   from each shunt to the multiplexer U24 and from there to the amplifier
   U27: tracks of 0.2 mm with a gap of 0.2 mm, on one layer, equal in
   length within 1 mm, without a via." The lengths are equal within 1 mm
   in the three pairs. But the taps of ranges 0 and 1 run through a via
   each and on the second inner layer, the pair of range 2 is not side by
   side, and the pair to the amplifier is side by side over a quarter of
   its length. Reason: the pin order of the multiplexer nests the pairs
   under its package, so only the innermost pair can run side by side,
   and the two pins of a pair are on opposite sides of the multiplexer and
   of the amplifier. The decision: the pair of R110 runs side by side at
   0.2 mm; the pair of R107 and the pair from U24 to U27 are equal in
   length within 1 mm and run side by side only where the pins allow; the
   taps of R101 and R104 leave their pads as tracks of their own and run
   through one via each on the second inner layer.
4. **The guard is not a closed ring on one layer (D-90).** Section 10.3
   said "It is a closed track of 0.5 mm on the top layer" and "The guard
   is on the top layer only." The guard is open at the three exits of the
   measured node, its arcs are joined on the other layers, parts of it are
   0.25 mm and 0.15 mm wide, and guard pours exist on the bottom layer.
   Reason: the measured node has to leave the ring on the top layer, the
   bottom pours shield the via pads of the node from the ground fill, and
   bare guard beside a soldered land of the can would bridge to ground at
   assembly. The decision: the guard is one piece of copper, open on the
   top layer at the three places where the measured node leaves the shield
   can, with a guard track on both sides of each exit and of the range 3
   pair outside the can as far as the shunt. Its arcs are joined through
   vias with tracks on the bottom layer and on the second inner layer, and
   guard pours on the bottom layer surround the via pads of the measured
   node. The solder mask is closed over the guard at the wall crossings
   and between pads.
5. **Foreign nets inside the ring (D-91).** Section 10.3 said "no ground
   pour and no foreign net inside the ring." There is no ground pour, but
   the supply, address and enable pins of the multiplexer and their parts
   are inside. Reason: the pins of the multiplexer are inside by
   necessity, and moving their parts outside would lead their nets across
   the guard on the top layer. Their share of the calculated leakage is
   0.47 nA, at pin 14 of the multiplexer. The decision: the supply,
   address and enable pins of U24 and the parts at those pins stand inside
   the guard, and no ground pour lies inside it.
6. **Width and layer of the 1 A pours (D-92).** Section 10.4 asked for
   "pours on the top layer, 4 mm to 8 mm wide". The sums are under
   30 squares, but pieces are narrower: 1.2 mm on top at the source pair,
   where the bottom band is 4.9 mm, and 2.0 mm to 2.9 mm at the poles of
   the terminal block and at test points. Two pieces run on the bottom
   layer because parts stand in the way on top: the output of the linear
   regulator to the source pair, and the fuse to the ampere pair. Clearing
   them is a change of placement. The decision: the 1 A path is judged by
   its resistance, 30 squares or less in either mode (the drawn path has
   19.5 squares and 23.3 squares). Its pours are 4 mm to 8 mm wide where
   the parts leave room and narrower at pins, test points and connector
   poles, and the two pieces named above run on the bottom layer through
   groups of vias.
7. **Top island of the linear regulator (D-93).** Section 10.6 asked for
   "an island of output copper of at least 15 mm × 15 mm on the top layer
   and the same on the bottom layer". The bottom layer has 291 mm²; the
   top layer has 102 mm². Reason: parts stand around the regulator on the
   top layer. The decision: the island under U18 is 291 mm² on the bottom
   layer, joined by 22 vias to 102 mm² on the top layer. The datasheet
   figure of 65 K/W is for 225 mm² of top copper, so the temperature rise
   of U18 at its full dissipation is an open check of section 16 of the
   specification, to be read on the first board
   ([Close the Open Checks](#5-close-the-open-checks)).

Three things that the decisions do not do. They do not close an
[open item](#open-items): those are places where the board does not keep a
rule that still stands. They do not replace the look of a person at the
board in the KiCad editor. And they rest on calculations: where a decision
quotes a leakage or a resistance, a measurement on the first board
replaces the figure.

#### Open Items

These need parts moved or another footprint, and the review did not do
that. Every figure is calculated from the drawn copper. Each item says
what would close it.

- **Loops of the converter capacitors.** Pre-regulator: the loops of its
  five capacitors close on the top layer only over 8.2 mm to 17.1 mm
  (limit 5 mm), because their ground pads face away from the converter;
  each has a ground via 0.15 mm to 0.20 mm from its pad into the plane.
  Boost converter: 6.8 mm and 10.3 mm (limit 5 mm). Charge pump: the ground
  sides of two capacitors are 3.4 mm and 4.4 mm from the pin (limit 2 mm).
  To close: turn or place the capacitors again so that their ground pads
  face the ground pad of the converter. The other way is a decision that
  the return runs through the vias and the plane, with the ripple measured
  on the phase 1 prototype.
- **Inductor of the pre-regulator.** 4.5 mm from its second pair of switch
  pins (limit 3 mm). To close: turn or move the inductor so that its pad
  faces those pins.
- **Temperature sensor U39.** 5.1 mm from pad to pad and 7.7 mm from
  center to center from the linear regulator (limit 5 mm). To close: move
  it 0.2 mm toward the regulator, or have section 10.6 say between which
  points the 5 mm are taken.
- **Suppressor of VOUT, D21.** Its cathode copper is 93 mm² (1 cm² asked),
  and it stands 8.6 mm from the VOUT pole, where section 10.4 describes it
  between the poles at 4.3 mm. It was moved away from the poles to keep
  ground 1.0 mm from the VOUT pour. To close: enlarge the VOUT pour by
  7 mm², and have section 10.4 describe the part where it stands, or place
  it again.
- **Ladder clamps Q10 and Q11.** 21 mm² and 28 mm² of supply-node copper
  lie within 5 mm of their drains (1 cm² asked), and the strip to one
  clamp is 0.6 mm wide. To close: more copper at the drains, which needs a
  resistor and a gate track moved, or a sentence in section 10.6 that the
  1 cm² is the whole supply pour.
- **Drain pad of the ampere pair on the VIN side.** The pad of that
  transistor lies in no top pour: the whole current of ampere mode enters
  through four vias of 0.6 mm with a 0.3 mm hole in the pad. To close:
  move the parts that stand between the pour and the pad, and use vias of
  0.8 mm with a 0.4 mm hole. It is the piece from the fuse to the ampere
  pair, which decision D-92 lets run on the bottom layer.
- **Openings of the ground plane.** Where the clearances of a group of
  vias merge, the plane opens: up to 4.7 mm × 2.3 mm under the island of
  the linear regulator. With 694 vias instead of 499 the plane has 787 mm²
  of openings in all, against 593 mm² on the autorouted board. To close: a
  via pitch of 1.5 mm in the groups keeps webs of plane between the vias.
- **Star of the reference.** The branches should leave the output pad
  itself; two parts stand in the way, and 5.7 mm of copper with 2.2 mΩ are
  common to the branch of the ADC and the pedestal divider. To close: move
  one of the two parts, or record the common 2.2 mΩ as a decision.
- **Distance of the +12 V regulator.** It is 22 mm, courtyard to
  courtyard, from the diode and the capacitor of the boost converter;
  25 mm are asked and are kept from center to center only. To close: move
  the regulator, or have section 10.1 say that the 25 mm are from center to
  center.
- **Vias in or at pads that get solder paste.** 4 via holes on a pad edge
  and 14 via rings on a pad; via holes also in the drain pads of two
  transistors of the 1 A path. To close: move the vias clear of the pads,
  or accept them in writing with a line in the assembly notes (holes
  filled and capped, or a stencil that allows for them).
- **Pads entered by a wider track.** 19 pads were entered by a track wider
  than the pad. The 41 track ends were necked down in the last step of the
  review; the item stays on this list until a person has looked at those
  pads.

Smaller findings of the final review stay open beside these, among them:
the pour of the 5 V rail is in three pieces and the three 3.3 V regulators
hang on two single vias; the six vias in the power ground pad of the
pre-regulator are of 0.6 mm with a 0.3 mm hole, where section 10.1 gives
0.8 mm with a 0.4 mm hole for power; and five tracks have an acute corner.

#### Not Touched by the Review

These points of section 10 of the specification are as they were on the
autorouted board:

- 32 of the 40 signal test points have no probe ground within 5 mm
  (section 10.7).
- The net names of the test points and the function of the two solder
  jumpers are not on the silkscreen (section 10.2), 123 reference
  designators are hidden, and there is no frame for a hand-written serial
  number (section 10.7).
- The three acquisition lines enter the shield can at three places on two
  layers instead of through one opening (section 10.1).
- 21 nets cross the wall of the can below the ground plane, where
  section 10.3 lets tracks cross only on the top layer. The second inner
  layer carries 2.84 m of track, so its ground fill is in 80 pieces.
- The two resistor pairs of the set-point path do not stand side by side
  (section 10.1).

### Circuit Simulations

On 2026-10-10 the circuits of this schematic were simulated in ngspice,
block by block. The work is in [`../simulation/`](../simulation/README.md),
a package of its own at the root of the repository (decision D-94). A
bench names parts of the schematic by their reference designators, and the
package writes their elements from `simulation/netlist/carrier.json`, a
snapshot of the netlist that KiCad exports: 428 parts with their values
and nets. No part of the board is typed by hand. What stands around the
parts is typed by the bench and named in its notes: sources, loads,
cables, and in some benches a stand-in for a neighboring block of the
board. The snapshot matched the schematic in this directory on
2026-10-10.

Everything in this section is simulated. No board is built and nothing is
measured. A figure that passes says that the circuit as drawn keeps its
limit with the models named beside the result; it does not say that a
built board will. Every active part is a model written for this project
from its datasheet, a typical part at room temperature. 41 benches put
these models into the test circuits of their datasheets; the multiplexer
U24, the gate drivers U20, U22 and U23, the BAV199 diode pairs and the
fit of the clamp transistors Q10 and Q11 have no such bench. The models
of the manufacturers may not be copied into the repository; where a copy
was present they gave a second value.

| Block | Sheets of the schematic | Benches | Pass | Fail | No limit |
| --- | --- | --- | --- | --- | --- |
| [Shunt ladder](../simulation/results/ladder/README.md) | Shunt Ladder | 2 | 20 | 0 | 6 |
| [Signal chain](../simulation/results/signal_chain/README.md) | Signal Chain | 11 | 113 | 8 | 111 |
| [Range control logic](../simulation/results/range_logic/README.md) | Comparators, with Shunt Ladder, Signal Chain and the output switch in the loop | 12 | 143 | 6 | 122 |
| [Source meter](../simulation/results/source_meter/README.md) | Source Meter | 12 | 176 | 3 | 247 |
| [Output stage](../simulation/results/output_stage/README.md) | Output Stage | 6 | 151 | 6 | 142 |
| [Path switching](../simulation/results/path_switching/README.md) | Path Switching | 15 | 288 | 19 | 235 |
| [Power input and logic supplies](../simulation/results/power_input/README.md) | Power Input, Logic Supplies | 13 | 190 | 27 | 113 |
| [Analog rails and rail monitor](../simulation/results/analog_rails/README.md) | Analog Rails, Rail Monitor | 10 | 105 | 25 | 108 |
| [Digital lines and monitors](../simulation/results/digital/README.md) | Controller, Side Data, Digital Inputs, Monitors | 10 | 145 | 11 | 49 |
| [Whole measuring path](../simulation/results/system/README.md) | Shunt Ladder, Signal Chain and Comparators as one circuit | 2 | 25 | 0 | 3 |
| Circuits of the board | Ten blocks | 93 | 1356 | 105 | 1136 |
| [Models against their datasheets](../simulation/results/models/README.md) | | 41 | 478 | 17 | 70 |
| All | | 134 | 1834 | 122 | 1206 |

A figure that fails is kept as it is. The
[simulation guide](../simulation/README.md#reading-the-failures) says what
the 122 are, block by block, and gives every statement below with the
bench that shows it.

What the simulations reproduce of this draft, each value beside the one
that the specification states. It is a second calculation with models,
not a measurement:

| Circuit | Simulated | Specification |
| --- | --- | --- |
| Shunts seen by the amplifier | 1 kΩ, 31.95 Ω, 999 mΩ, 99.99 mΩ | 1 kΩ, 31.95 Ω, 0.999 Ω, 0.1 Ω |
| Burden of range 3 at 1 A, typical parts | 104.3 mV | 105 mV to 107 mV (calculated) |
| Gain of the chain and code at zero current | 19.93 and 1313 | 19.93 and about 1313 |
| Settling after a jump to range 3, to 0.1 % of the range and to one code | 45.37 µs and 65.22 µs | About 45 µs and 65 µs |
| Thresholds at the shunt: step up, over-current, jump | 90.95 mV, 115 mV, 151.2 mV | 91 mV, 115 mV, 151 mV |
| Jump threshold to range 3 conducting, nominal and worst delays | 360.8 ns and 480.3 ns | 0.35 µs and 0.51 µs; target 0.55 µs |
| Drop on a step from 1 µA to 500 mA with 1 µF, nominal and worst case (R-07) | 301.9 mV and 388.2 mV; 400.3 mV with the amplifier at half the bandwidth of its model, an assumption | 312 mV and 422 mV; limit 500 mV |
| The same with 10 µF | 168.3 mV and 179.2 mV; 180.8 mV with the amplifier at half its bandwidth | 169 mV and 186 mV; limit 250 mV |
| Output of the source at codes 616 and 3893, and its ceiling | 799.5 mV, 5 V, 5.259 V | 0.80 V, 5.00 V, 5.26 V |
| In-rush into 2200 µF when the output switch closes | 856.1 mA | 0.85 A |
| Drop at 1 A from the feeding point to the output terminal, with 20 mΩ of copper and contacts, ampere and source mode (R-06) | 155.7 mV and 141.7 mV | 158 mV and 144 mV; limit 200 mV |
| Over-voltage detector of VIN, trip and release | 5.465 V and 5.345 V | 5.46 V and 5.35 V |
| +13.5 V rail and −4 V_A at the tolerance limits | 13.02 V to 14.06 V; −3.913 V to −4.041 V | 13.0 V to 14.1 V; −3.91 V to −4.05 V |
| Current limits of the module input and of the USB-C input | 758.5 mA and 2.006 A | 0.76 A and 2.0 A |
| Resistance from the USB-C receptacle to the 5 V rail, typical and largest | 125.9 mΩ and 170.1 mΩ | 0.126 Ω and 0.170 Ω |

#### Decisions That Follow the Simulations

The simulations raised four points for a decision before boards are
ordered. The owner decided them on 2026-10-10, on the recommendation of
the simulations: decisions D-95 to D-98 of the specification. Nothing of
them is drawn yet. The schematic and the board in `kicad/`, the pictures
and the bill of materials in `doc/`, and the netlist snapshot of the
simulations hold the earlier state: 1 nF at C32 to C34, no position at
U28, R14 and C5 without parts. Drawing them is the first item of
[Still to Do](#still-to-do).

| Decision | What the simulation shows | What changes here | State |
| --- | --- | --- | --- |
| D-95: the capacitors C32 to C34 of the rail monitor are 10 nF, not 1 nF (changes the value of D-54) | With 1 nF as drawn and a comparator at its least hysteresis of 1 mV, an edge of PWR_GOOD moves its own threshold and a rail that crosses at 20 V/s or 400 V/s gives a burst of edges. With 10 nF and 1 pF the threshold moves by 525 µV, where 1 nF gives 3.149 mV to 3.606 mV; the one run made with 10 nF, at 2 V/s, shows one edge. The capacitance between the pins of the package, 0.5 pF to 1 pF, is an assumption | A value on three capacitors: the schematic, the bill of materials, no copper | Not drawn: the schematic shows 1 nF |
| D-96: a position for a capacitor from the non-inverting input of the buffer of the driver rail, U28, to ground; its value is chosen on the bench, and the position may stay empty | 41.92° of phase margin as drawn, not the 54° that the specification stated, because R126 (10 kΩ) works against the input capacitance of the amplifier. The loop is stable and a load step does not ring. The model of the manufacturer gives 68.99°, with input capacitances that are not those of its datasheet. No run with the capacitor exists | One position more on the Signal Chain sheet and one footprint more on the board, so the board changes | Not drawn |
| D-97: the position U9 at the boost converter stays without a part, and the 803 type with its time-out of 0.24 s is no longer the part meant for it; a remedy, if the test of phase 1 asks for one, is a detector with a time-out of milliseconds (changes D-84) | As drawn the boost converter starts in one go from an input limited to 0.67 A to 0.85 A. With a detector of 0.24 s the start would be stopped and, with 1 mA of load, repeated four times in the 1.1 s of the run without completing; with 0.1 mA the second attempt completes it. The result rests on a model of the converter below 2.7 V, where its datasheet says nothing, on a source with a flat current limit and on the assumed load | No copper. The text of the position, in the schematic and in the value of its footprint on the board | Schematic and board still name the position "803 type, 3.08 V" |
| D-98: the damper R14 (0.33 Ω) with C5 (10 µF) on the module input is fitted (changes D-84) | When the data cable is plugged again on a port at 5.5 V behind a short cable while USB-C supplies the rail, input 2 of the multiplexer U5 reaches 5.941 V with a limiter of typical reaction and 6.002 V with one assumed to react in 15 µs, against a rating of 6.0 V. With the damper fitted, its capacitor at half its value, the peak is 5.502 V in the runs made, after gaps of 2 ms to 2.6 ms; the damped input falls far less in those gaps, and the longer gap that matches was not run. The recharge pulse at a change of input was not simulated with the damper fitted; without it that pulse is 4.103 A through U5, against a pulse rating of 4 A | Two parts with their part numbers in the schematic and two lines of the bill of materials, on pads that exist | Not drawn: both are still marked "do not populate" |

#### Where the Text Differs, and What Stays for the Bench

In fourteen places the simulation and the text of the specification
differ: the time for which the over-current comparator stays high, the
ladder clamp in a short circuit, the capacitor advised at the VIN
terminals, the times at power-off, the opening time of the output switch
at 0.8 V, and others. The simulation round proposes no change of hardware
for them; the decision is the owner's. They are listed, with their
figures, in the
[simulation guide](../simulation/README.md#where-the-simulation-and-the-text-differ)
and as open points in section 16 of the specification, whose text stands
until the owner decides. The fourteen are not every difference: the guide
also names the figures that fail against a rating of a datasheet, most of
them in a fault case.

Some questions about this hardware stay for the bench, whatever the
simulations say:

- The linear range of the amplifier U27 near the −4 V rail with the output
  below 0.2 V: two readings of its datasheet end it at 130 mV or at
  214 mV across the shunt. It is an open check of section 16.
- The loop of the pre-regulator U16 at its low end, and the linear
  regulator U18 at light load with 22 µF: the models extrapolate there.
- A supply that reverses or jumps to 20 V while the ampere pair is closed:
  a transistor of the pair then has to block 34.44 V to 65.74 V against a
  rating of 30 V. Whether a part survives is a pulse test.
- The clamp levels of the rail diodes D8 and D9, 296.4 mV and −292.8 mV
  with the largest forward voltage of the datasheet, and 394.2 mV and
  −391.4 mV at −40 °C, against pin ratings of 0.3 V.
- Leakage at the nanoampere level, the multiplexer U24 at +12 V and −4 V,
  the programs of the controller, coupling through the copper and
  temperature. No model here gives a figure for any of them.

### Connectors

Someone who faces the front edge reads the pins from left to right in the
order of the Nordic PPK2 (Figure 4 of its user guide, v1.0.1).

| Connector | Type | Pins |
| --- | --- | --- |
| DUT, pin header | 1×4, 2.54 mm, straight | GND, VIN, VOUT, GND |
| DUT, terminal block | Lever-operated, 3.5 mm (candidate: WAGO 2601-1104) | GND, VIN, VOUT, GND |
| Logic port | 1×10, 2.54 mm, straight | VCC, GND, D7 down to D0 |

The carrier also has the USB-C power connector at the back edge (power
only) and a 3-pin console header (TX, RX and GND at 3.3 V).

The two DUT connectors carry the same nets. VOUT delivers 0.8 V to 5.0 V in
source mode. VIN is the external supply of ampere mode: 0.8 V to 5.0 V in
use, and −20 V to +20 V withstood while the ampere switch is open
(simulated; decision D-60). The VCC pin of the logic port is used only when
the solder jumper beside the level translator (JP2) is moved: as built,
the logic inputs follow the output voltage of the instrument, and they are
valid for logic levels of 1.65 V to 5.5 V (R-10). The limits of every
terminal are in section 4.9 of the specification.

### Libraries

| Library | Item | Description |
| --- | --- | --- |
| `PowerProfiler` | Symbol `ADS8860xDGS` | 16-bit converter, from the datasheet SBAS569B |
| `PowerProfiler` | Symbol `MUX509xPW` | Dual 4:1 multiplexer, from the datasheet SBAS758C |
| `PowerProfiler` | Symbol `TPS63020DSJ` | Buck-boost converter, from the datasheet SLVS916I |
| `PowerProfiler` | Symbol `TPS2116DRL` | Priority power multiplexer, with the pin numbers of the KiCad symbol `Power_Management:TPS2116DRL`; its second output pin is passive |
| `PowerProfiler` | Footprint `TerminalBlock_WAGO_2601-1104_1x04_P3.50mm_Horizontal_Pad1.9mm` | Lever terminal block: the library footprint with pads of 1.9 mm × 2.3 mm |
| `PowerProfiler` | Footprint `RaspberryPi_Pico_Common_THT_NoKeepout` | Controller module: the library footprint without its antenna keep-out |
| `PowerRails` | Power symbols | One symbol per supply rail of the table above, and the ground symbol |

The symbols are in `kicad/lib/PowerProfiler.kicad_sym` and
`kicad/lib/PowerRails.kicad_sym`, the two footprints in
`kicad/lib/PowerProfiler.pretty` (decision D-85). Every other symbol and
footprint, the symbol of the Pico 2 among them, comes from the library that
KiCad 10 installs.

### Controller Module

The carrier takes a Raspberry Pi Pico 2 with its pin headers fitted, on two
1×20 pin sockets 17.78 mm apart (MP1, MP2). The sockets are soldered
into the holes of the module footprint (U1) and the module is plugged
into them; an RP2350 of stepping A3 or A4 is preferred (decision D-82). A
Pico 2 W fits the same sockets, but the firmware does not support it. The
pin map is in section 5 of the specification; every GPIO of the headers is
in use.

- Either USB connector powers the whole instrument, and USB-C is used
  whenever it is present. Each input has its own current limiter, and
  neither connector is fed back from the other. Cut the solder jumper on
  the Controller sheet (JP1) to keep the carrier off the USB port of the
  computer.
- With the data cable alone the instrument stays inside what a default USB
  port offers: the input current allowed is 0.45 A, about 1.5 W at the
  output (estimate). The whole current curve of R-08 needs a USB-C source
  that offers 1.5 A or more (section 4.1 of the specification, decision
  D-49).
- Every line that the module drives, except the console output, has a
  resistor to a rail on the carrier, and series resistors limit what a pin
  can push into an input whose supply is absent. With the module in reset,
  in its boot loader or out of its sockets every switch is open and the
  pre-regulator is off (section 5).
- Firmware is loaded through the USB connector of the Pico 2: hold its
  BOOTSEL button and press the reset button of the carrier.

### Checks

Run them from `kicad/`. The Hardware workflow runs the same commands when it
is started, by hand only (decision D-22). It fails on any error of the
electrical rules check, on any rule violation of the board (warnings
count), on any footprint error and, since the layout review, on any
unconnected pad. The results below are from local runs.

```sh
kicad-cli sch erc --severity-all power-profiler-carrier.kicad_sch
kicad-cli pcb drc --schematic-parity --severity-all power-profiler-carrier.kicad_pcb
```

Results on the files of this draft, with KiCad 10.0.0 on 2026-10-10:

| Check | Result |
| --- | --- |
| Electrical rules check | 0 errors, 0 warnings |
| Design rules check, rule violations | 0 |
| Design rules check, footprint errors (difference between board and schematic) | 0 |
| Design rules check, unconnected pads | 0 |

The design rules check compares the board with its rules and with the
schematic. Before a board is ordered it must report no rule violation, no
difference between board and schematic and no unconnected pad. It reports
that now, against the rule file that the layout review rewrote
([Design Rules Check](#design-rules-check) says what the file asks and
which five checks the project ignores). On the autorouted board the same
check listed 28 unconnected items.

Three corrections stood behind the result of the autorouted board. The
autorouter had left five pairs of vias
0.493 mm to 0.499 mm apart; each pair was moved apart by less than 0.01 mm.
The pattern that binds one net to its net class was corrected. And the
stackup of the board file was set to the build of section 10.1 of the
specification.

Both checks were run with `kicad-cli` only. The project has not been opened
in the KiCad editor yet. The checks say that the files are consistent and
that the copper keeps the rules of the rule file. They do not say that the
layout is good: a rule file holds spacings, not the length of a converter
loop, the squares of a pour or the leakage into a node. Those were
calculated in the [layout review](#layout-review), and what that review
left open is listed there.

### Still to Do

This is the hardware part of the next steps that the
[README](../README.md#project-status) of the repository puts in order:
first the decisions that follow the simulations are drawn (item 1 here),
then the owner decides what is still open (item 2), then the board
(items 3 and 4), then the software, which the
[firmware guide](../firmware/README.md) and the
[host guide](../host/README.md) list. The checks that need parts or a
bench (item 5) and the work that waits for firmware (item 6) belong to the
phases that follow.

Five steps of the earlier lists are done. The 28 connections that the
autorouter had left open were closed in the layout review of 2026-10-10;
this guide no longer carries their list and their map. The seven
deviations of the reviewed board are decided
([D-87 to D-93](#decisions-of-the-layout-review-d-87-to-d-93)). The
scripts that calculate the figures of the board are filed in
[`tools/board/`](../tools/board/README.md). The simulations of the
circuits are filed in [`../simulation/`](../simulation/README.md), made
again from the final netlist; this guide no longer carries the list of
what had to be filed. And the four points that the simulations raised
are decided
([D-95 to D-98](#decisions-that-follow-the-simulations)).

#### 1. Draw the Decisions That Follow the Simulations

Nothing of the four decisions is drawn. The files in `kicad/`, and the
pictures and the bill of materials in `doc/`, show the state before
them.

- D-95, Rail Monitor sheet: C32, C33 and C34 from 1 nF to 10 nF, with the
  part number of the new value in their fields. The pads stay, so the
  board changes only in the value of three footprints.
- D-96, Signal Chain sheet: a position for a capacitor from the
  non-inverting input of U28, the node of R126, to ground, and its
  footprint on the board. It is the one change of copper: the board has
  425 footprints, and this is one more. The position may stay without a
  part; its value is chosen on the bench.
- D-98, Power Input sheet: R14 (0.33 Ω) and C5 (10 µF) are no longer
  marked "do not populate" and get their part numbers. Their pads are on
  the board.
- D-97, Analog Rails sheet: U9 stays without a part. Its value still
  reads "803 type, 3.08 V", and that text follows the decision: the part
  meant now is a detector with a time-out of milliseconds, named only if
  the test of phase 1 asks for a remedy.
- Then the notes of the sheets that name the old values, the electrical
  rules check and the design rules check with schematic parity, the bill
  of materials, the PDF and the pictures of `doc/` exported again, and
  the figures of the layout that the new footprint touches
  ([Reproducing the Figures](#reproducing-the-figures)).
- Then the simulations: the netlist exported, the snapshot written again
  and the benches of the changed blocks run again. The
  [simulation guide](../simulation/README.md#when-the-schematic-changes)
  says which benches hold the changed parts.

#### 2. Decide What Is Still Open

- The fourteen places where the simulation and the text of the
  specification differ are the owner's. None is proposed as a change of
  the hardware; each one that changes the text is an entry in the
  decision log.
- Whether proof-of-concept boards are ordered on this state is a decision
  as well. The simulations judge the circuits, not the copper: items 3
  and 4 stand as they are.

#### 3. Review the Board in KiCad

- A person opens the project in the KiCad editor and reviews the board.
  Until now every check ran from the command line and every figure comes
  from a script.
- That review reads the placement and the copper against the rules of
  section 10 of the specification, and compares a 1:1 print with the
  module on its sockets, the USB-C connector, the terminal block, the frame
  of the can and one of the 1 A transistors (section 10.8).

#### 4. Close the Open Items and Finish the Silkscreen

- The [open items](#open-items) that the owner wants closed are placement
  changes with a local redraw: the capacitors of the three converters and
  the inductor of the pre-regulator, the temperature sensor, the suppressor
  of VOUT, the ladder clamps, the drain pad of the ampere pair, the star of
  the reference, the via groups over the ground plane, the vias at pasted
  pads.
- The points that the review [did not touch](#not-touched-by-the-review):
  probe grounds at the test points, the net names of the test points and
  the functions of the jumpers on the silkscreen, a frame for the serial
  number, one opening for the acquisition lines, the resistor pairs of the
  set-point path.
- Calculate again, after each change, the figures that the change touches
  ([Reproducing the Figures](#reproducing-the-figures)), and run both
  checks. A renamed net or a renumbered part also changes
  `tools/board/carrier.toml`. The board can be ordered only when the
  design rules check reports no violation, no difference between board and
  schematic and no unconnected pad, and when a person has reviewed it.

#### 5. Close the Open Checks

Section 16 of the specification, tracked in
[`docs/checks/`](../docs/checks/README.md):

- Close the component checks, part by part, each with the comparison of
  pin numbers and land pattern with the datasheet. None is closed.
- Before a board is ordered, without a carrier board: the risk prototypes of
  phase 1 (reaction of the range sequencer, pre-regulator with its tracking
  amplifier, start of the boost converter from a supply limited to 0.7 A),
  the linear range of the amplifier near full scale with the output below
  0.2 V, and on loose parts the leakage of the VOUT suppressor, the leakage
  of the range and clamp transistors and the on-resistance of the
  multiplexer.
- Find stock for the three lines of the bill of materials that had none,
  and order the parts with long lead times first.
- On the first board, before a DUT is connected: every gate at or below
  0.3 V in the states that section 16 lists, then the gate ramp of the
  output switch and the in-rush with a capacitor in place of the DUT.
- On the first board, the thermal check of decision D-93: the temperature
  rise of the linear regulator U18 at its full dissipation. Its island of
  output copper is 291 mm² on the bottom layer and 102 mm² on the top
  layer, and the datasheet figure of 65 K/W is for 225 mm² of top copper,
  so the figure has to be read on the board.
- On the bench, what the four decisions leave to check: one edge of
  PWR_GOOD per event at start and at stop with 10 nF (D-95); the step
  response of the driver rail with the position at U28 empty and with a
  capacitor in it, whose value is chosen there (D-96); the start of the
  boost converter from a supply limited to 0.7 A, which says whether a
  detector with a time-out of milliseconds is needed at U9 (D-97); the
  data cable plugged again with the damper fitted, and the recharge
  pulse at a change of input, which was not simulated (D-98).
- Measure what the simulations leave to the bench
  ([list](#where-the-text-differs-and-what-stays-for-the-bench)).

#### 6. With the Firmware

- Write the PIO programs of the range sequencer and of the acquisition, and
  test them in an emulator. Until they exist the pin assignment of the
  controller is provisional, and a change of it changes the Controller
  sheet and the board.
- The firmware rules that guard hardware (F-1 to F-36, section 6.6 of the
  specification) are part of this design: several limits of the carrier
  hold only with them. None is implemented; the
  [firmware guide](../firmware/README.md) says what exists.

#### After Every Change

- Plot the pictures of `doc/` again after every change to the schematic or
  the board; the commands are at the end of [`doc/README.md`](doc/README.md).
  Export the bill of materials again after a change to the schematic.
- After a change to the schematic, check that the nets of the 1 A path
  still have their net class, and run both checks.
- After a change to the schematic, export its netlist, write the snapshot
  of the simulations again and run the benches of the blocks that the
  change touches. The results describe the netlist of the snapshot, and
  no check compares the two by itself: the
  [simulation guide](../simulation/README.md#when-the-schematic-changes)
  has the steps.

## Design References

In the [specification](../docs/specification.md):

- Section 3: system architecture and power tree.
- Section 4: analog hardware design, from the power input to the error
  budget, and the controller module.
- Section 5: pin map.
- Section 6.6: firmware rules that guard hardware.
- Section 10: PCB and mechanical guidelines.
- Section 15: decisions, D-23 onwards for the drafts, D-47 to D-86 for
  draft A2, D-87 to D-93 for its layout review, D-94 for the place of
  the circuit simulations and D-95 to D-98 for the decisions that
  followed them.
- Section 16: open checks, and at its end the open points of the circuit
  simulations.
- Section 17: bill of materials summary.

## Revisions

Board revisions are named with letters. Drafts A0, A1 and A2 are review
drafts; A2 is the one in this directory. Revision A is the first carrier
board to be fabricated (phase 5) and revision B corrects the issues found on
it (phase 7). Fabrication outputs are stored per revision, for example
`fabrication/rev-a/`.

- Draft A1 changed, against draft A0, the controller (a Raspberry Pi Pico 2
  in place of the ESP32-S3 development board and of the programmable logic
  device), the connectors of the DUT, the reference designators and the
  board (decisions D-39 to D-46).
- Draft A2 is draft A1 after a review of every part and every block, which
  recorded 432 findings, six of them blockers. The power input has a
  current limiter per USB input and a priority multiplexer in place of the
  fuse and the diode OR-ing, and a supervisor of the 5 V rail gives the
  carrier one off state. Four comparators make PWR_GOOD, the pre-regulator
  follows the output of the linear regulator, the switches of the path
  close slowly behind gate networks, the two mode switches cannot be closed
  together, and VIN withstands −20 V to +20 V. Clamps, pull resistors and
  series resistors protect the ladder, the terminals, the converter input
  and the lines of the controller. The schematic grew from 278 parts on
  13 pages to 428 parts on 15 and was numbered again, and every line of
  the bill of materials has a part number. Where the specification asked
  for more than an instrument of this class delivers, the requirement was
  restated (R-04, R-06 to R-10 and R-14). The board grew from
  130 mm × 100 mm to 150 mm × 100 mm and is placed and routed
  automatically, where draft A1 had placed footprints and no tracks
  (decisions D-47 to D-86).
- The layout of draft A2 was reviewed on 2026-10-10. The autorouted board
  had 956 of its 984 connections and 28 open. The review closed them and
  drew the pours of the 1 A path, the guard, the Kelvin lines, the pour of
  the 5 V rail and the ground fills, with scripts and with an independent
  check of every rule. The schematic and the bill of materials did not
  change, and the draft keeps its name. The board departs from the words
  that section 10 of the specification had in seven points; the owner
  accepted them the same day, and they are decisions D-87 to D-93. The
  review left a list of open items ([Layout Review](#layout-review)). The
  scripts that calculate its figures are in
  [`tools/board/`](../tools/board/README.md), and the silkscreen and both
  title blocks carry the name "Open Power Profiler - Carrier Board".
- The circuits of draft A2 were simulated on 2026-10-10, from the netlist
  of its schematic. Neither the schematic nor the board changed, and the
  draft keeps its name. The central design figures come out again
  ([Circuit Simulations](#circuit-simulations)). The simulations are in
  [`../simulation/`](../simulation/README.md) by decision D-94. They
  raised four points, which the owner decided the same day (D-95 to
  D-98): three of them change the schematic and are not drawn yet. A
  list of places where the simulations differ from the text of the
  specification is not decided.

## License

Copyright (c) 2026 Luiz Guilherme Ito.

The design files in this directory are licensed under the CERN Open Hardware
Licence Version 2 - Permissive (CERN-OHL-P v2). See [LICENSE](LICENSE). They
are provided without any warranty, as stated in section 5 of the license.

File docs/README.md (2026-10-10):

# Documentation

The index of every document of the repository, with the state of each one.

The project is in early development. The carrier board exists as draft A2:
a complete schematic and a board whose layout was reviewed on 2026-10-10.
All 984 connections are routed, and the copper that an autorouter does not
draw is drawn: the pours of the 1 A path, the guard, the Kelvin pairs, the
copper of the converters, the 5 V rail and the ground fills. That review
was done with scripts and checked by independent calculation; the board has
not yet been looked at by a person in the KiCad editor, and it is not a
design to fabricate. The seven points in which it deviates from the earlier
guidelines of section 10 of the specification are recorded as decisions
D-87 to D-93. The circuits of the schematic were simulated on 2026-10-10
from its netlist, in a package of their own in `simulation/` (D-94): 134
benches, whose results are filed. The central design figures of the
specification come out again. The simulations raised four points for a
decision before boards are ordered, and the project owner decided them the
same day: decisions D-95 to D-98. Three of them change the schematic and
are not drawn yet, so the schematic, the board, the bill of materials and
the results of the simulations still show the earlier state. In fourteen
places the simulations differ from the text of the specification; those
are not decided, and no requirement, figure or rule of the specification
was changed on their account. The software foundations exist and are
tested without hardware, and so do the package that calculates the
figures of the board layout and the package that runs the simulations.

Nothing has been built and nothing has been measured: every figure in these
documents is a datasheet value, a calculation, a simulation or an estimate,
and says which. Every figure of the board is calculated from the drawn
copper, and the package in `tools/board/` calculates them again from the
board file. A figure of the circuit simulations of 2026-10-10 comes from
a circuit whose parts are taken from the netlist, with models written
from datasheets, and the package in `simulation/` runs it again. The
figures that the specification marks "simulated" are older: they were
taken from simulations made while the draft was designed, whose files are
not filed.

## In This Directory

| Document | Content | State |
| --- | --- | --- |
| [specification.md](specification.md) | The baseline: requirements R-01 to R-17, architecture and analog design, pin map, firmware with the rules F-1 to F-36 that guard hardware, host protocol, calibration, board guidelines, verification plan, development phases, risk register, decision log, open checks and bill of materials | Written for draft A2 of the carrier board, with decisions D-01 to D-98. No value in it is measured. The seven points in which the reviewed board deviates from the earlier guidelines of section 10 are decisions D-87 to D-93, and sections 10.3, 10.4, 10.6 and 10.8 describe the board as it is drawn. D-94 places the circuit simulations in `simulation/`, and D-95 to D-98 are the decisions of the project owner on the four points that the simulations raised: it states them as the design, and three of them are not drawn yet. Where those simulations differ from a figure or a rule in other places, the text is unchanged: the end of section 16 lists fourteen such places as open |
| [checks/](checks/README.md) | Component checks: each candidate part, and each peripheral of the controller, against the documentation of its manufacturer. The tables mirror section 16 of the specification, the open points of the circuit simulations included | Every check is open; no record is filed, so every part is a candidate. The fourteen places where the simulations and the specification differ wait for the project owner; the four points of the simulations are decided (D-95 to D-98) and have left the list, and drawing them is the first item before the board is ordered |
| [checks/TEMPLATE.md](checks/TEMPLATE.md) | Form of a check record | In use from the first record |
| [reports/](reports/README.md) | Test reports: the measurements that close each development phase of section 13 | No report is filed; no phase is closed |
| [reports/TEMPLATE.md](reports/TEMPLATE.md) | Form of a phase report | In use from the first report |
| [protocol/](protocol/README.md) | Host protocol: where it is defined, its state against draft A2, and what the user reference will hold | Pointer page. The protocol is at version 1 and not frozen; the reference is planned for phase 6 |
| [calibration/](calibration/README.md) | Calibration: what section 8 of the specification defines, the reference equipment, and what is missing | Summary page. The procedure is not written; planned for phase 6 |

## In the Rest of the Repository

| Document | Content | State |
| --- | --- | --- |
| [README](../README.md) | The project in one page: the state of every area and the next steps, target specifications with a comparison with the PPK2, how it works, connections, the hardware draft in pictures, the circuit simulations with two of their graphs, roadmap | Follows draft A2 with the reviewed layout, the simulations of 2026-10-10 and the four decisions that followed them |
| [Hardware guide](../hardware/README.md) | The carrier board: status of the draft, schematic, board, connectors, libraries, checks and the work still to do | Draft A2: 428 parts on 15 schematic pages; a board of 150 mm × 100 mm on four layers with 984 of 984 connections routed and a design rules check with no violation and no unconnected pad. The layout is reviewed with scripts; its figures are calculated from the drawn copper. Its seven deviations from the earlier guidelines are recorded decisions (D-87 to D-93). A review by a person, the open items of the layout and the thermal check of D-93 stand before fabrication. It carries the four decisions that follow the simulations (D-95 to D-98) with what each changes on the schematic, the board or the bill of materials; none is drawn yet, and drawing them is its first step |
| [The draft in pictures](../hardware/doc/README.md) | Every schematic sheet and the board as pictures, with the design values of each block; the schematic is also a [PDF](../hardware/doc/schematic.pdf), and the bill of materials a [CSV file](../hardware/doc/bom.csv) | Plotted and exported from draft A2; the board pictures are plotted from the reviewed board file, and the views of the assembled board are renderings, not photographs. The pictures show the state before decisions D-95, D-96 and D-98; the text under the sheets says where they differ |
| [Simulation guide](../simulation/README.md) | The circuit simulations: the state of the results block by block, what they reproduce, the four points that are decided, where they differ from the text of the specification, what stays for the bench, the limits of the models, the traps of the simulator, setup, commands and checks | The package `circuit-sim` exists: 134 benches run in the ngspice library of KiCad 10, 93 that take the parts of their circuits from a snapshot of the netlist and 41 that put the models into the test circuits of their datasheets. 1834 figures pass, 122 fail and 1206 carry no limit. 777 tests, 100 % of lines and branches covered outside the one module that loads the simulator (floor 90 %), ruff and mypy in strict mode, run locally on Windows. Its workflow has not been started yet. It simulates with models written from datasheets and measures nothing. Its results are those of the circuit before decisions D-95, D-96 and D-98 |
| [Simulation results](../simulation/results/README.md) | One line for every bench, and a page for each block with every figure beside the value that the specification states and its limit, the graphs of the waveforms and the decks, the circuit files that the simulator ran | Written by the package from the result files of 2026-10-10; not edited by hand. Everything in them is simulated |
| [Firmware guide](../firmware/README.md) | Architecture of the firmware, its layout, the unit tests on the PC, coverage and static analysis | The hardware-independent core exists and is unit-tested. The port to the Pico SDK is not started; the target build in the directory is still the one for the ESP32-S3 |
| [Host guide](../host/README.md) | The Python package: layers, setup, the simulated instrument, checks | Protocol codec, transports, device client, capture helpers and simulator exist and are tested. Viewer, export and the marks that draft A2 asks for are not written |
| [Protocol directory](../protocol/README.md) | The definition of the wire protocol, the generator, the shared test vectors, and how a change is made | Version 1, generated files up to date. The items that draft A2 reports are not in the definition yet |
| [Tools](../tools/README.md) | The tools of the repository: the board figures, and what the calibration tool and the production test will have to do | The board figures exist and are tested without hardware. The calibration tool and the production test are not started; their directories are empty |
| [Board figures guide](../tools/board/README.md) | The package `board-figures`: how to install it, dump the board from KiCad and run each command; the method, the assumptions and the limits of each calculation; its checks | The package exists: 260 tests on synthetic boards, 100 % of lines and branches covered (floor 90 %), ruff and mypy in strict mode, run locally on Windows. Its workflow has not been started yet. It calculates from the drawn copper and measures nothing |
| [Contributing guide](../CONTRIBUTING.md) | Workflow, commit message format, quality gates, versioning | Current |
| [Changelog](../CHANGELOG.md) | Notable changes by release | Everything is under "Unreleased"; no release exists |

One directory of the hardware area is empty and has no document:
`hardware/fabrication/`, for the outputs of a board that is ordered. The
directory `hardware/simulation/` is gone: the simulations are in
`simulation/`, at the root of the repository (D-94). The scripts that
calculate the figures of the reviewed board (resistance of a pour in
squares, a path on one layer, surface leakage into the measured node,
lengths of the pairs) are filed in `tools/board/`, so a reader can repeat
those figures from the board file. The scripts that drew the copper of the
board are not in the repository, and neither are the model files of the
manufacturers, whose licenses do not allow it.

## What Comes Next

The first part of the board step is done: the 28 connections that the
autorouter left open are closed, and the layout is drawn against section 10
of the specification. The seven points in which the drawn board deviates
from the earlier text of that section are decided: the project owner
accepted them on 2026-10-10, and they are decisions D-87 to D-93 of the
log. The scripts that calculate the figures of the board are filed in
`tools/board/`. The simulation step is done as well: the circuits are
simulated from the final netlist, and the package, the models, the benches
and the results are filed in `simulation/`. The rest is not started. It is
the work that stands between the draft and the phases of section 13 of the
specification:

1. The decisions that follow the simulations, drawn. The project owner
   decided the four points on 2026-10-10 (D-95 to D-98). Three change the
   schematic and are not drawn yet: 10 nF at three capacitors of the rail
   monitor, a position for a capacitor at the buffer of the driver rail,
   which adds a footprint to the board, and the two parts of the damper on
   the module input. Then the two rule checks, the bill of materials and
   the pictures exported again, the netlist snapshot of the simulations
   written again and the benches of the changed blocks run again. The
   [hardware guide](../hardware/README.md#still-to-do) has the steps.
2. Decisions of the project owner that are still open:
   - The fourteen places where the simulation and the text of the
     specification differ, listed in the
     [simulation guide](../simulation/README.md#what-the-simulations-say)
     and at the end of section 16 of the specification. A change of the
     text is an entry in the decision log.
   - Whether proof-of-concept boards are ordered on this state.
3. Board, four things, with the lists in the
   [hardware guide](../hardware/README.md):
   - A person opens the board in KiCad and reviews it.
   - The open items that need a part moved or another footprint: a
     placement change with a local redraw. The capacitor loops of the
     pre-regulator, the boost converter and the charge pump are the
     largest of them.
   - The silkscreen and the test points: net names, the function of the two
     jumpers, a frame for the serial number, a probe ground near each test
     point.
   - The thermal check of D-93: the temperature rise of the linear
     regulator U18 at full dissipation on its island of copper, read on
     the first board.
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

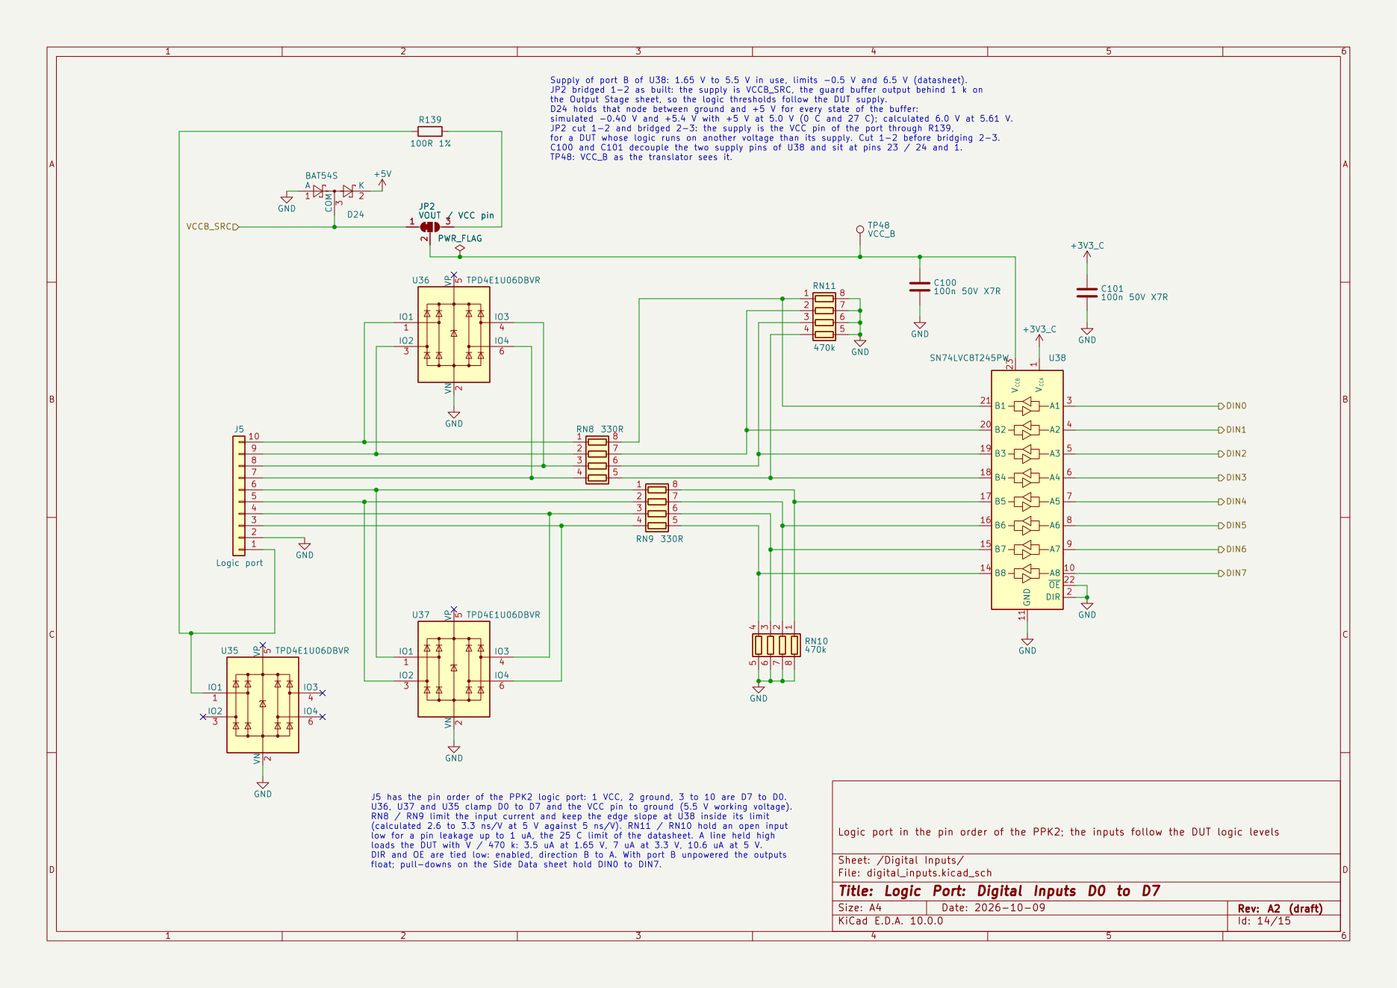
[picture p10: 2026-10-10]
hardware/doc/images/schematic-14-digital-inputs.png

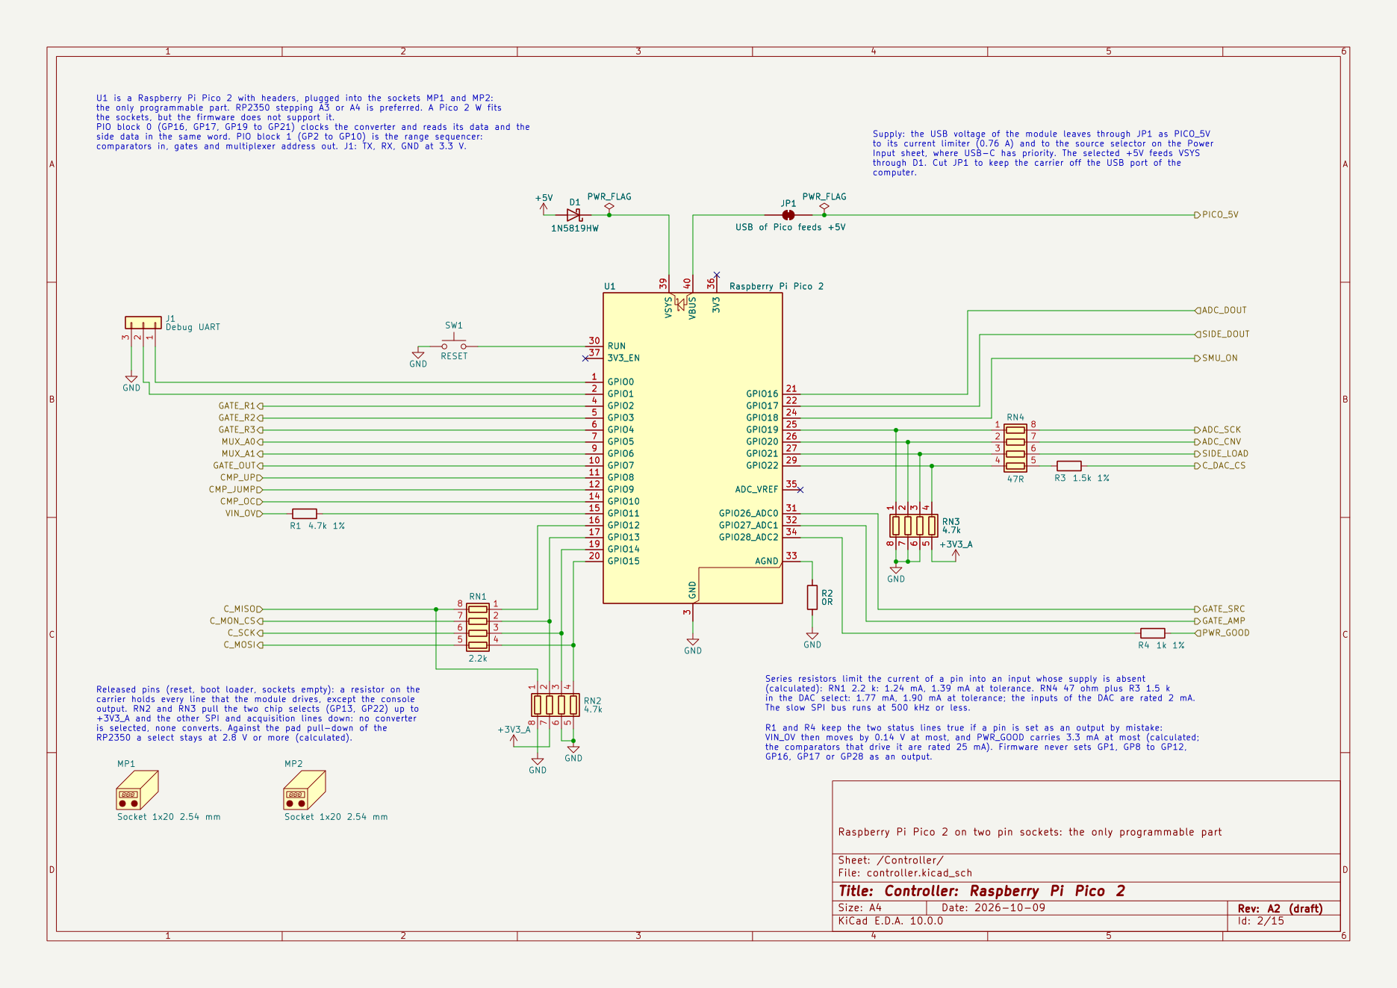
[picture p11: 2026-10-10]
hardware/doc/images/schematic-02-controller.png

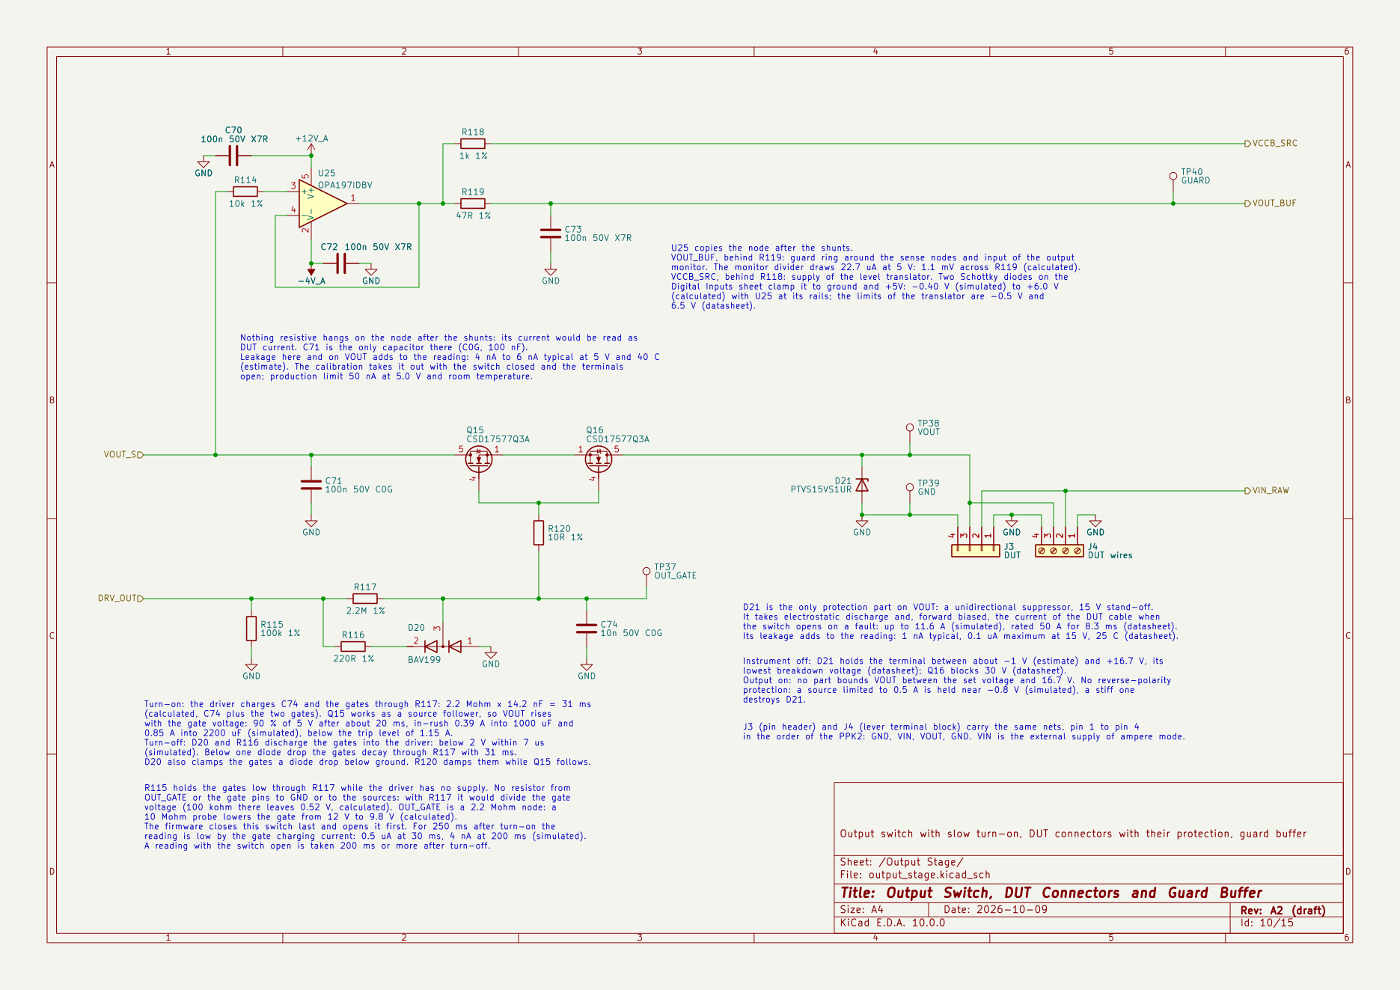
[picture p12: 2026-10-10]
hardware/doc/images/schematic-10-output-stage.png

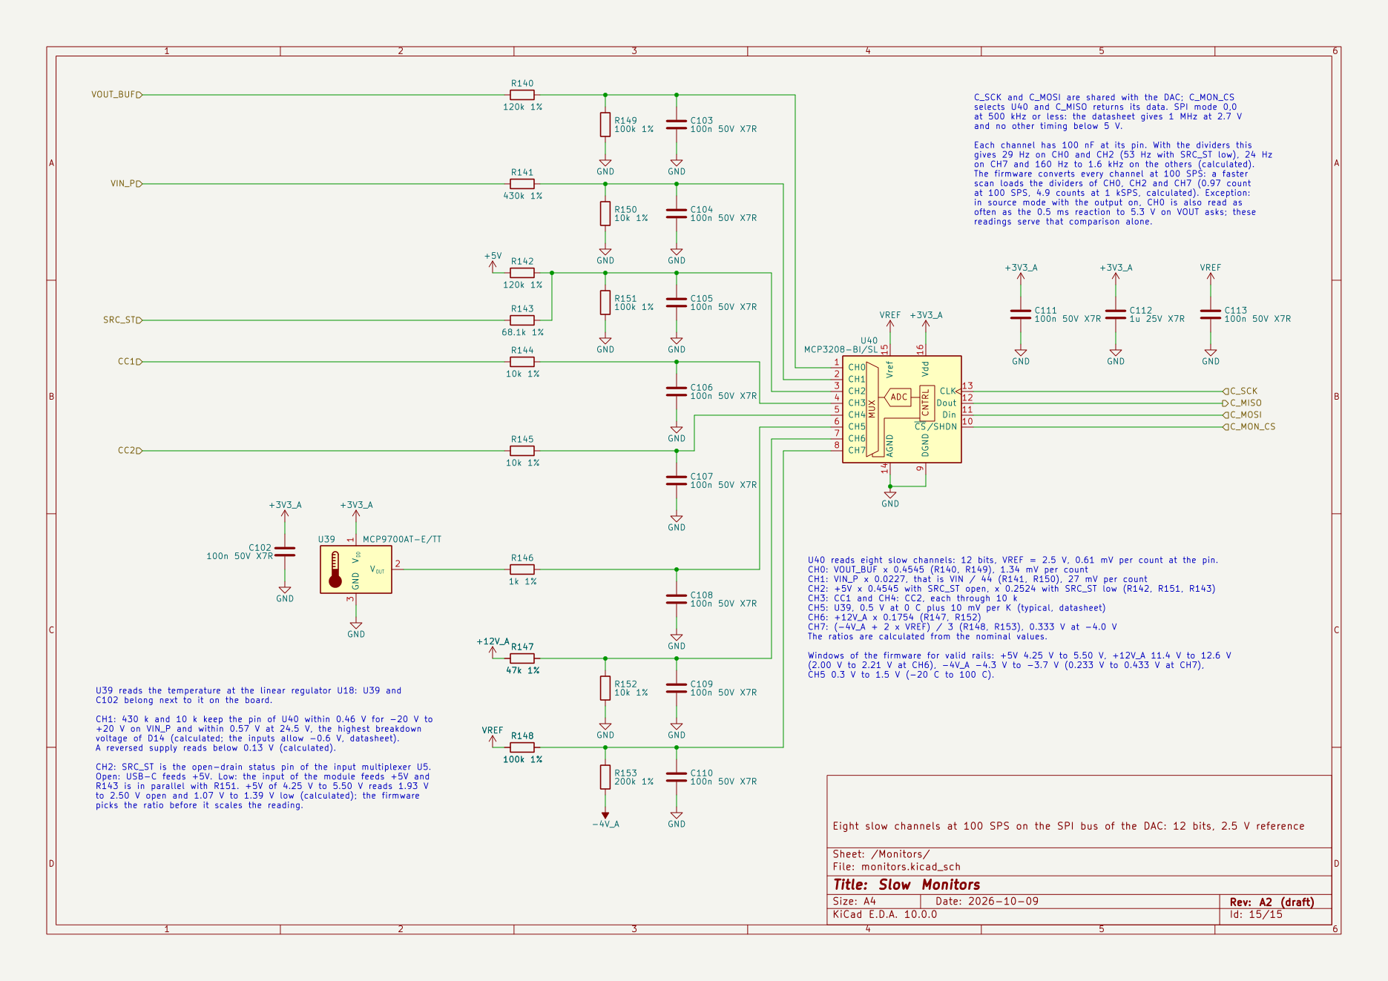
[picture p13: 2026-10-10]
hardware/doc/images/schematic-15-monitors.png

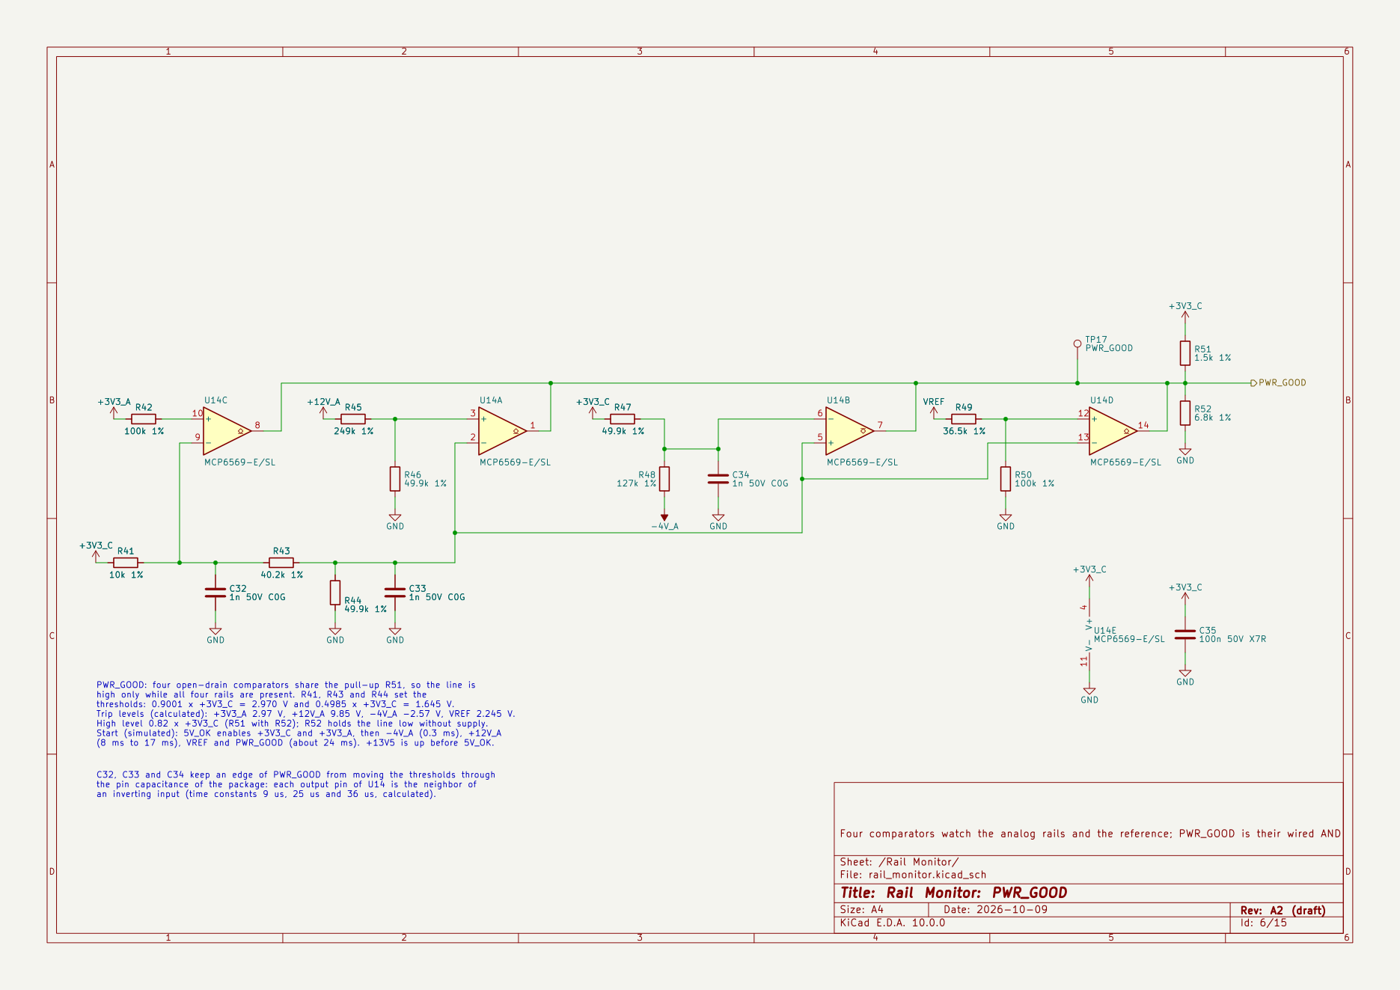
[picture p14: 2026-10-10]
hardware/doc/images/schematic-06-rail-monitor.png

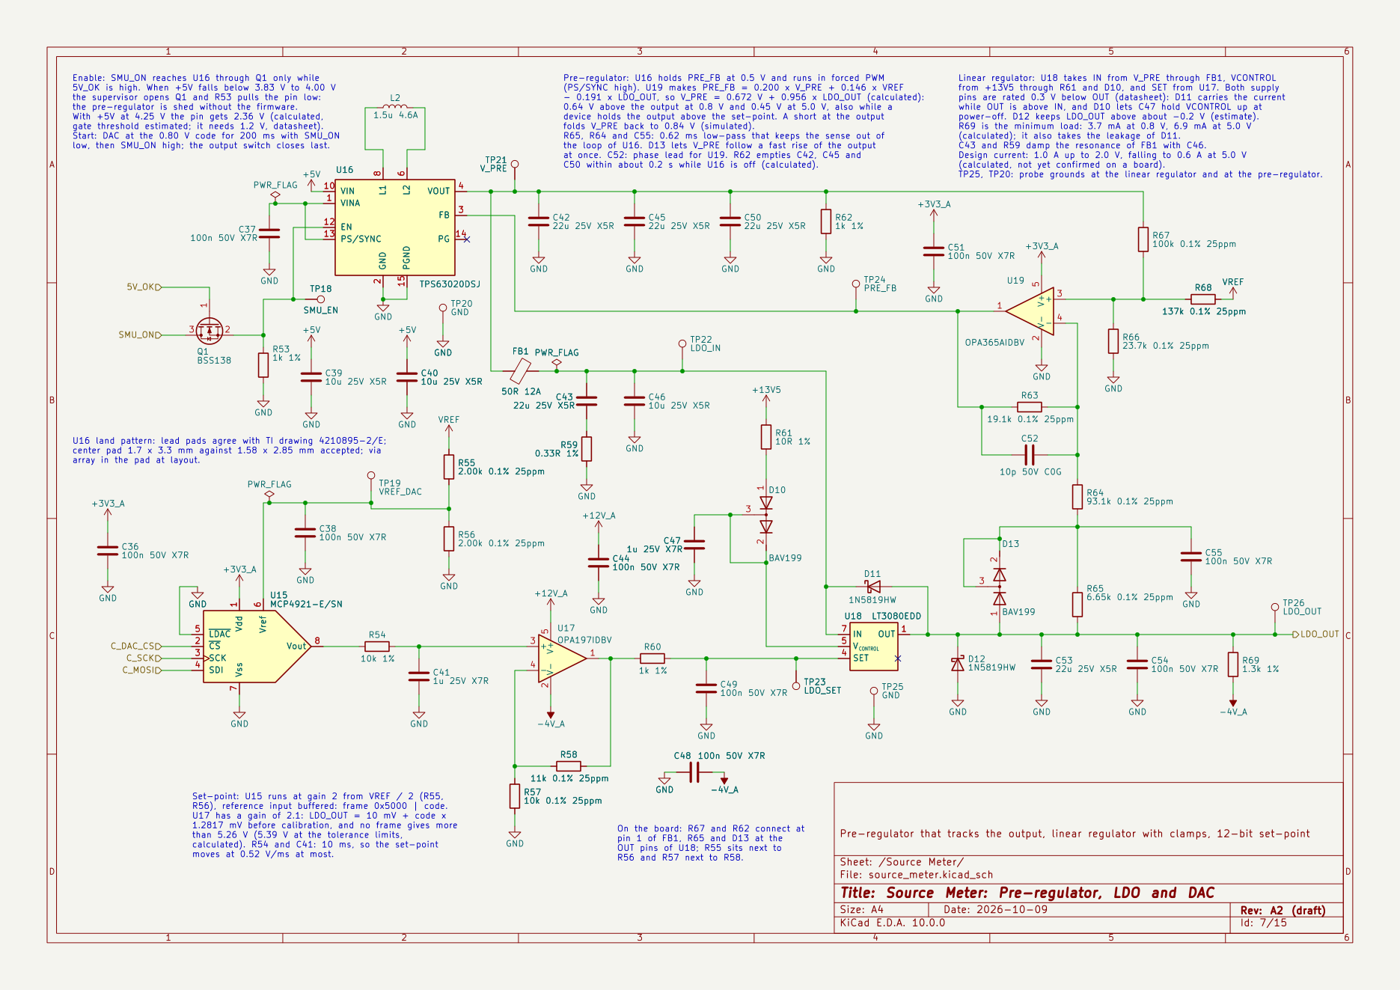
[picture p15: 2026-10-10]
hardware/doc/images/schematic-07-source-meter.png

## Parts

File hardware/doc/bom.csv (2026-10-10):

Reference | Value | Footprint | MPN | Manufacturer | QUANTITY
C1,C3,C13,C25,C35-C38,C44,C48,C49,C51,C54,C55,C57,C59-C61,C66-C70,C72,C73,C79-C81,C84,C86,C88,C93-C111,C113 | 100n 50V X7R | Capacitor_SMD:C_0603_1608Metric | C0603C104K5RACTU | KEMET | 51
C2,C18,C20,C22,C28,C30,C63 | 4.7u 25V X7R | Capacitor_SMD:C_0805_2012Metric | CL21B475KAFNNNE | Samsung Electro-Mechanics | 7
C4 | 3.3n 50V X7R | Capacitor_SMD:C_0603_1608Metric | CL10B332KB8NNNC | Samsung Electro-Mechanics | 1
C6,C7,C14-C17,C19,C24,C41,C47,C56,C62,C64,C65,C78,C82,C83,C91,C92,C112 | 1u 25V X7R | Capacitor_SMD:C_0603_1608Metric | C0603C105K3RACTU | KEMET | 20
C8 | 33n 50V X7R | Capacitor_SMD:C_0603_1608Metric | CL10B333KB8NNNC | Samsung Electro-Mechanics | 1
C9,C10,C21 | 22u 10V X7R | Capacitor_SMD:C_1206_3216Metric | CL31B226KPHNNNE | Samsung Electro-Mechanics | 3
C11 | 47u 16V | Capacitor_SMD:CP_Elec_6.3x5.4 | 865060343004 | Wurth Elektronik | 1
C12,C32-C34,C58 | 1n 50V C0G | Capacitor_SMD:C_0603_1608Metric | C0603C102J5GACTU | KEMET | 5
C23,C77 | 220p 50V C0G | Capacitor_SMD:C_0603_1608Metric | C0603C221J5GACTU | KEMET | 2
C26 | 10u 16V X7R | Capacitor_SMD:C_0805_2012Metric | CL21B106KOQNNNE | Samsung Electro-Mechanics | 1
C27,C29,C31 | 10u 25V X7R | Capacitor_SMD:C_1210_3225Metric | CL32B106KAJNNNE | Samsung Electro-Mechanics | 3
C39,C40,C46 | 10u 25V X5R | Capacitor_SMD:C_0805_2012Metric | CL21A106KAYNNNE | Samsung Electro-Mechanics | 3
C42,C43,C45,C50,C53 | 22u 25V X5R | Capacitor_SMD:C_1206_3216Metric | CL31A226KAHNNNE | Samsung Electro-Mechanics | 5
C52 | 10p 50V C0G | Capacitor_SMD:C_0603_1608Metric | C0603C100J5GACTU | KEMET | 1
C71 | 100n 50V C0G | Capacitor_SMD:C_1206_3216Metric | C3216C0G1H104J160AA | TDK | 1
C74 | 10n 50V C0G | Capacitor_SMD:C_0603_1608Metric | GRM1885C1H103JA01D | Murata | 1
C75,C76 | 22p 50V C0G | Capacitor_SMD:C_0603_1608Metric | C0603C220J5GACTU | KEMET | 2
C85 | 1.5n 50V C0G | Capacitor_SMD:C_0603_1608Metric | C0603C152J5GACTU | KEMET | 1
C87 | 680p 50V C0G | Capacitor_SMD:C_0603_1608Metric | C0603C681J5GACTU | KEMET | 1
C89 | 22u 6.3V X5R | Capacitor_SMD:C_0805_2012Metric | CL21A226KQQNNNE | Samsung Electro-Mechanics | 1
C90 | 10n 25V C0G | Capacitor_SMD:C_0603_1608Metric | C0603C103J3GACTU | KEMET | 1
D1,D3,D4,D11,D12 | 1N5819HW | Diode_SMD:D_SOD-123 | 1N5819HW-7-F | Diodes Incorporated | 5
D2 | SMAJ10A | Diode_SMD:D_SMA | SMAJ10A-E3/61 | Vishay | 1
D5 | green 2.0V | LED_SMD:LED_0603_1608Metric | 150060VS75000 | Wurth Elektronik | 1
D6-D9 | B0530W 30V 0.5A | Diode_SMD:D_SOD-123 | B0530W-7-F | Diodes Incorporated | 4
D10,D13,D15-D20,D22,D23 | BAV199 | Package_TO_SOT_SMD:SOT-23 | BAV199-7-F | Diodes Incorporated | 10
D14 | SMAJ20CA | Diode_SMD:D_SMA | SMAJ20CA-E3/61 | Vishay | 1
D21 | PTVS15VS1UR | Diode_SMD:Nexperia_CFP3_SOD-123W | PTVS15VS1UR,115 | Nexperia | 1
D24 | BAT54S | Package_TO_SOT_SMD:SOT-23 | BAT54SLT1G | onsemi | 1
F1 | 4A fast 32V | Fuse:Fuse_1206_3216Metric | 0466004.NR | Littelfuse | 1
FB1 | 50R 12A | Inductor_SMD:L_1206_3216Metric | BLM31SN500SN1L | Murata | 1
J1 | Debug UART | Connector_PinHeader_2.54mm:PinHeader_1x03_P2.54mm_Vertical | 61300311121 | Wurth Elektronik | 1
J2 | USB-C power | Connector_USB:USB_C_Receptacle_GCT_USB4125-xx-x_6P_TopMnt_Horizontal | USB4125-GF-A-0190 | GCT | 1
J3 | DUT | Connector_PinHeader_2.54mm:PinHeader_1x04_P2.54mm_Vertical | 61300411121 | Wurth Elektronik | 1
J4 | DUT wires | PowerProfiler:TerminalBlock_WAGO_2601-1104_1x04_P3.50mm_Horizontal_Pad1.9mm | 2601-1104 | WAGO | 1
J5 | Logic port | Connector_PinHeader_2.54mm:PinHeader_1x10_P2.54mm_Vertical | 61301011121 | Wurth Elektronik | 1
L1 | 10u 3A | Inductor_SMD:L_Wuerth_MAPI-4030 | 74438357100 | Wurth Elektronik | 1
L2 | 1.5u 4.6A | Inductor_SMD:L_Coilcraft_XxL4020 | XFL4020-152MEC | Coilcraft | 1
MP1,MP2 | Socket 1x20 2.54 mm |  | 61302011821 | Wurth Elektronik | 2
MP3 | BMI-S-210-C |  | BMI-S-210-C | Laird | 1
Q1-Q3 | BSS138 | Package_TO_SOT_SMD:SOT-23 | BSS138-7-F | Diodes Incorporated | 3
Q4,Q5,Q8,Q9,Q14-Q16 | CSD17577Q3A | Package_SON:VSON-8_3.3x3.3mm_P0.65mm_NexFET | CSD17577Q3A | Texas Instruments | 7
Q6,Q7 | BC847B | Package_TO_SOT_SMD:SOT-23 | BC847B-7-F | Diodes Incorporated | 2
Q10-Q13 | IRLML0030 | Package_TO_SOT_SMD:SOT-23 | IRLML0030TRPBF | Infineon | 4
R1,R71 | 4.7k 1% | Resistor_SMD:R_0603_1608Metric | CRCW06034K70FKEA | Vishay | 2
R2 | 0R | Resistor_SMD:R_0603_1608Metric | CRCW06030000Z0EA | Vishay | 1
R3,R51 | 1.5k 1% | Resistor_SMD:R_0603_1608Metric | CRCW06031K50FKEA | Vishay | 2
R4,R26,R53,R60,R62,R70,R72,R75,R88,R89,R93,R94,R96-R99,R111,R112,R118,R146 | 1k 1% | Resistor_SMD:R_0603_1608Metric | CRCW06031K00FKEA | Vishay | 20
R5,R9 | 4.53k 1% | Resistor_SMD:R_0603_1608Metric | CRCW06034K53FKEA | Vishay | 2
R6,R10 | 3.01k 1% | Resistor_SMD:R_0603_1608Metric | CRCW06033K01FKEA | Vishay | 2
R7,R11,R91,R95 | 5.1k 1% | Resistor_SMD:R_0603_1608Metric | CRCW06035K10FKEA | Vishay | 4
R8,R12 | 402k 1% | Resistor_SMD:R_0603_1608Metric | CRCW0603402KFKEA | Vishay | 2
R13 | 1.21k 1% | Resistor_SMD:R_0603_1608Metric | CRCW06031K21FKEA | Vishay | 1
R15 | 453R 1% | Resistor_SMD:R_0603_1608Metric | CRCW0603453RFKEA | Vishay | 1
R16,R19,R23,R25,R41,R54,R113,R114,R126,R144,R145,R150,R152 | 10k 1% | Resistor_SMD:R_0603_1608Metric | CRCW060310K0FKEA | Vishay | 13
R17,R24,R27,R42,R50,R78,R80,R85,R86,R90,R103,R106,R109,R115,R148,R149,R151 | 100k 1% | Resistor_SMD:R_0603_1608Metric | CRCW0603100KFKEA | Vishay | 17
R18 | 13.7k 1% | Resistor_SMD:R_0603_1608Metric | CRCW060313K7FKEA | Vishay | 1
R20,R59 | 0.33R 1% | Resistor_SMD:R_0805_2012Metric | ERJ-6RQFR33V | Panasonic | 2
R21 | 86.6k 0.1% | Resistor_SMD:R_0603_1608Metric | TNPW060386K6BEEA | Vishay | 1
R22,R57 | 10k 0.1% 25ppm | Resistor_SMD:R_0603_1608Metric | TNPW060310K0BEEA | Vishay | 2
R28 | 150k 1% | Resistor_SMD:R_0603_1608Metric | CRCW0603150KFKEA | Vishay | 1
R29 | 51k 1% | Resistor_SMD:R_0603_1608Metric | CRCW060351K0FKEA | Vishay | 1
R30 | 2.2R 1% 0.25W | Resistor_SMD:R_1206_3216Metric | CRCW12062R20FKEA | Vishay | 1
R31,R61,R108,R120,R129 | 10R 1% | Resistor_SMD:R_0603_1608Metric | CRCW060310R0FKEA | Vishay | 5
R32 | 133k 1% | Resistor_SMD:R_0603_1608Metric | CRCW0603133KFKEA | Vishay | 1
R33 | 13.3k 1% | Resistor_SMD:R_0603_1608Metric | CRCW060313K3FKEA | Vishay | 1
R34 | 226k 0.1% | Resistor_SMD:R_0603_1608Metric | TNPW0603226KBEEA | Vishay | 1
R35 | 1R 1% | Resistor_SMD:R_0603_1608Metric | CRCW06031R00FNEA | Vishay | 1
R36,R67,R74 | 100k 0.1% 25ppm | Resistor_SMD:R_0603_1608Metric | TNPW0603100KBEEA | Vishay | 3
R37 | 0.47R 1% 0.25W | Resistor_SMD:R_1206_3216Metric | ERJ-8RQFR47V | Panasonic | 1
R38 | 120k 0.1% | Resistor_SMD:R_0603_1608Metric | TNPW0603120KBEEA | Vishay | 1
R39 | 442k 1% | Resistor_SMD:R_0603_1608Metric | CRCW0603442KFKEA | Vishay | 1
R40 | 12.4k 1% | Resistor_SMD:R_0603_1608Metric | CRCW060312K4FKEA | Vishay | 1
R43 | 40.2k 1% | Resistor_SMD:R_0603_1608Metric | CRCW060340K2FKEA | Vishay | 1
R44,R46,R47 | 49.9k 1% | Resistor_SMD:R_0603_1608Metric | CRCW060349K9FKEA | Vishay | 3
R45 | 249k 1% | Resistor_SMD:R_0603_1608Metric | CRCW0603249KFKEA | Vishay | 1
R48 | 127k 1% | Resistor_SMD:R_0603_1608Metric | CRCW0603127KFKEA | Vishay | 1
R49 | 36.5k 1% | Resistor_SMD:R_0603_1608Metric | CRCW060336K5FKEA | Vishay | 1
R52,R81,R82 | 6.8k 1% | Resistor_SMD:R_0603_1608Metric | CRCW06036K80FKEA | Vishay | 3
R55,R56 | 2.00k 0.1% 25ppm | Resistor_SMD:R_0603_1608Metric | TNPW06032K00BEEA | Vishay | 2
R58,R124 | 11k 0.1% 25ppm | Resistor_SMD:R_0603_1608Metric | TNPW060311K0BEEA | Vishay | 2
R63 | 19.1k 0.1% 25ppm | Resistor_SMD:R_0603_1608Metric | TNPW060319K1BEEA | Vishay | 1
R64 | 93.1k 0.1% 25ppm | Resistor_SMD:R_0603_1608Metric | TNPW060393K1BEEA | Vishay | 1
R65 | 6.65k 0.1% 25ppm | Resistor_SMD:R_0603_1608Metric | TNPW06036K65BEEA | Vishay | 1
R66 | 23.7k 0.1% 25ppm | Resistor_SMD:R_0603_1608Metric | TNPW060323K7BEEA | Vishay | 1
R68 | 137k 0.1% 25ppm | Resistor_SMD:R_0603_1608Metric | ERA-3AEB1373V | Panasonic | 1
R69 | 1.3k 1% | Resistor_SMD:R_0805_2012Metric | CRCW08051K30FKEA | Vishay | 1
R73 | 115k 0.1% | Resistor_SMD:R_0603_1608Metric | TNPW0603115KBEEA | Vishay | 1
R76 | 3.3M 1% | Resistor_SMD:R_0603_1608Metric | CRCW06033M30FKEA | Vishay | 1
R77,R79,R92,R100,R130 | 22R 1% | Resistor_SMD:R_0603_1608Metric | CRCW060322R0FKEA | Vishay | 5
R83,R84,R117 | 2.2M 1% | Resistor_SMD:R_0603_1608Metric | CRCW06032M20FKEA | Vishay | 3
R87 | 0.47R 1% 0.5W | Resistor_SMD:R_1206_3216Metric | RCWE1206R470FKEA | Vishay | 1
R101 | 1k 0.1% 25ppm | Resistor_SMD:R_0805_2012Metric | TNPW08051K00BEEA | Vishay | 1
R102,R105,R119 | 47R 1% | Resistor_SMD:R_0603_1608Metric | CRCW060347R0FKEA | Vishay | 3
R104 | 33R 0.1% 25ppm | Resistor_SMD:R_0805_2012Metric | CPF0805B33RE1 | TE Connectivity | 1
R107 | 1R 0.5% 25ppm | Resistor_SMD:R_Shunt_Ohmite_LVK12 | TNPW12061R00DEEA | Vishay | 1
R110 | 0.1R 0.25% 50ppm | Resistor_SMD:R_Shunt_Ohmite_LVK12 | LVK12R100CER | Ohmite | 1
R116 | 220R 1% | Resistor_SMD:R_0603_1608Metric | CRCW0603220RFKEA | Vishay | 1
R121 | 49.9k 0.1% 25ppm | Resistor_SMD:R_0603_1608Metric | TNPW060349K9BEEA | Vishay | 1
R122 | 1.02k 0.1% 25ppm | Resistor_SMD:R_0603_1608Metric | TNPW06031K02BEEA | Vishay | 1
R123 | 523R 0.1% 25ppm | Resistor_SMD:R_0603_1608Metric | RT0603BRD07523RL | Yageo | 1
R125,R128 | 3.9k 1% | Resistor_SMD:R_0603_1608Metric | CRCW06033K90FKEA | Vishay | 2
R127,R137 | 1k 0.1% 25ppm | Resistor_SMD:R_0603_1608Metric | TNPW06031K00BEEA | Vishay | 2
R131 | 0.22R 1% | Resistor_SMD:R_0603_1608Metric | ERJ-3RQFR22V | Panasonic | 1
R132 | 34.8k 0.1% 25ppm | Resistor_SMD:R_0603_1608Metric | TNPW060334K8BEEA | Vishay | 1
R133 | 3.6k 0.1% 25ppm | Resistor_SMD:R_0603_1608Metric | TNPW06033K60BEEA | Vishay | 1
R134 | 2.4k 0.1% 25ppm | Resistor_SMD:R_0603_1608Metric | TNPW06032K40BEEA | Vishay | 1
R135 | 9.31k 0.1% 25ppm | Resistor_SMD:R_0603_1608Metric | TNPW06039K31BEEA | Vishay | 1
R136 | 3.01k 0.1% 25ppm | Resistor_SMD:R_0603_1608Metric | ERA-3AEB3011V | Panasonic | 1
R138 | 33R 1% | Resistor_SMD:R_0603_1608Metric | CRCW060333R0FKEA | Vishay | 1
R139 | 100R 1% | Resistor_SMD:R_0603_1608Metric | CRCW0603100RFKEA | Vishay | 1
R140,R142 | 120k 1% | Resistor_SMD:R_0603_1608Metric | CRCW0603120KFKEA | Vishay | 2
R141 | 430k 1% | Resistor_SMD:R_0603_1608Metric | CRCW0603430KFKEA | Vishay | 1
R143 | 68.1k 1% | Resistor_SMD:R_0603_1608Metric | CRCW060368K1FKEA | Vishay | 1
R147 | 47k 1% | Resistor_SMD:R_0603_1608Metric | CRCW060347K0FKEA | Vishay | 1
R153 | 200k 1% | Resistor_SMD:R_0603_1608Metric | CRCW0603200KFKEA | Vishay | 1
RN1 | 2.2k | Resistor_SMD:R_Array_Convex_4x0603 | CAY16-222J4LF | Bourns | 1
RN2,RN3 | 4.7k | Resistor_SMD:R_Array_Convex_4x0603 | CAY16-472J4LF | Bourns | 2
RN4 | 47R | Resistor_SMD:R_Array_Convex_4x0603 | CAY16-470J4LF | Bourns | 1
RN5 | 220R 5% | Resistor_SMD:R_Array_Convex_4x0603 | CAY16-221J4LF | Bourns | 1
RN6,RN7 | 100k | Resistor_SMD:R_Array_Convex_4x0603 | CAY16-104J4LF | Bourns | 2
RN8,RN9 | 330R | Resistor_SMD:R_Array_Convex_4x0603 | CAY16-331J4LF | Bourns | 2
RN10,RN11 | 470k | Resistor_SMD:R_Array_Convex_4x0603 | CAY16-474J4LF | Bourns | 2
SH1 | BMI-S-210-F | RF_Shielding:Laird_Technologies_BMI-S-210-F_44.00x30.50mm | BMI-S-210-F | Laird | 1
SW1 | RESET | Button_Switch_THT:SW_PUSH_6mm | B3F-1000 | Omron | 1
U1 | Raspberry Pi Pico 2 | PowerProfiler:RaspberryPi_Pico_Common_THT_NoKeepout | SC1632 | Raspberry Pi | 1
U2,U35-U37 | TPD4E1U06DBVR | Package_TO_SOT_SMD:SOT-23-6 | TPD4E1U06DBVR | Texas Instruments | 4
U3,U4 | TPS259621DDAR | Package_SO:TI_SO-PowerPAD-8_ThermalVias | TPS259621DDAR | Texas Instruments | 2
U5 | TPS2116DRLR | Package_TO_SOT_SMD:SOT-583-8 | TPS2116DRLR | Texas Instruments | 1
U6 | TPS3808G01DBVR | Package_TO_SOT_SMD:SOT-23-6 | TPS3808G01DBVR | Texas Instruments | 1
U7,U8 | LP5907MFX-3.3 | Package_TO_SOT_SMD:SOT-23-5 | LP5907MFX-3.3/NOPB | Texas Instruments | 2
U10 | LMR62014XMF | Package_TO_SOT_SMD:SOT-23-5 | LMR62014XMF/NOPB | Texas Instruments | 1
U11 | LM27761DSG | Package_SON:WSON-8-1EP_2x2mm_P0.5mm_EP0.9x1.6mm | LM27761DSGT | Texas Instruments | 1
U12 | REF5025AID | Package_SO:SOIC-8_3.9x4.9mm_P1.27mm | REF5025AID | Texas Instruments | 1
U13 | LT3042EMSE | Package_SO:MSOP-10-1EP_3x3mm_P0.5mm_EP1.68x1.88mm | LT3042EMSE#PBF | Analog Devices | 1
U14 | MCP6569-E/SL | Package_SO:SOIC-14_3.9x8.7mm_P1.27mm | MCP6569-E/SL | Microchip | 1
U15 | MCP4921-E/SN | Package_SO:SOIC-8_3.9x4.9mm_P1.27mm | MCP4921-E/SN | Microchip | 1
U16 | TPS63020DSJ | Package_DFN_QFN:DFN-14-1EP_3x4mm_P0.5mm_EP1.7x3.3mm | TPS63020DSJR | Texas Instruments | 1
U17,U25,U26 | OPA197IDBV | Package_TO_SOT_SMD:SOT-23-5 | OPA197IDBVR | Texas Instruments | 3
U18 | LT3080EDD | Package_DFN_QFN:DFN-8-1EP_3x3mm_P0.5mm_EP1.66x2.38mm | LT3080EDD#PBF | Analog Devices | 1
U19,U28,U29 | OPA365AIDBV | Package_TO_SOT_SMD:SOT-23-5 | OPA365AIDBVR | Texas Instruments | 3
U20,U22,U23 | TC4427EOA | Package_SO:SOIC-8_3.9x4.9mm_P1.27mm | TC4427EOA713 | Microchip | 3
U21,U32 | MCP6561T-E/OT | Package_TO_SOT_SMD:SOT-23-5 | MCP6561T-E/OT | Microchip | 2
U24 | MUX509IPWR | Package_SO:TSSOP-16_4.4x5mm_P0.65mm | MUX509IPWR | Texas Instruments | 1
U27 | AD8421ARZ | Package_SO:SOIC-8_3.9x4.9mm_P1.27mm | AD8421ARZ | Analog Devices | 1
U30 | ADS8860IDGS | Package_SO:MSOP-10_3x3mm_P0.5mm | ADS8860IDGS | Texas Instruments | 1
U31 | MCP6562-E/SN | Package_SO:SOIC-8_3.9x4.9mm_P1.27mm | MCP6562-E/SN | Microchip | 1
U33,U34 | SN74LV165ADR | Package_SO:SOIC-16_3.9x9.9mm_P1.27mm | SN74LV165ADR | Texas Instruments | 2
U38 | SN74LVC8T245PW | Package_SO:TSSOP-24_4.4x7.8mm_P0.65mm | SN74LVC8T245PWR | Texas Instruments | 1
U39 | MCP9700AT-E/TT | Package_TO_SOT_SMD:SOT-23 | MCP9700AT-E/TT | Microchip | 1
U40 | MCP3208-BI/SL | Package_SO:SOIC-16_3.9x9.9mm_P1.27mm | MCP3208T-BI/SL | Microchip | 1

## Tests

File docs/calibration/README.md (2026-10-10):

# Calibration

How the instrument turns ADC codes into amperes and DAC codes into volts,
and how the values behind that are found for one board and stored.

## Status

The calibration procedure is not written. It is planned for phase 6
(section 13 of the [specification](../specification.md)), and it cannot be
written earlier: no board exists, and a procedure has to be tried on one.
Until then section 8 of the specification defines what is calibrated, how
the values are stored and which reference equipment is needed. This page
summarizes that section and says what is missing around it.

Nothing below is measured. Each figure is a datasheet value, a calculation,
a simulation or an estimate, as the specification marks it.

## What Section 8 Defines

The conversion runs on the host. The instrument sends raw ADC codes with
the range that was active, and the host computes
`I = (code − offset[r]) × gain[r]` with one gain and one offset per range.
Requirement R-12 asks for these values to be stored on the device.

- **Nominal values.** Before a board is calibrated the gain of a range is
  `VREF / (65536 × G × R[r])`, with the amplifier gain G = 19.93 and, for
  R[r], the shunt of the range in parallel with the shunt of range 0, which
  always stays in the path: 1 kΩ, 31.95 Ω, 0.999 Ω and 0.1 Ω for ranges 0
  to 3 (calculated, section 4.3). The set-point of the source is
  10 mV + code × 1.2817 mV before calibration (F-30). Nominal values are
  design targets, never a calibration.
- **The stored record.** Gain and offset of each range, gain and offset of
  the DAC, the length of the settling window and the calibration
  temperature, with a version field and a CRC. The record lives in the
  flash of the Pico 2, because the carrier board has no memory of its own
  (D-82).
- **What binds the record to a module and to a carrier.** The record
  carries the 64-bit chip identifier of the RP2350 and the serial number
  and revision of the carrier. The serial number is entered at calibration
  and written by hand into a frame on the silkscreen of the carrier
  (section 10.7). A record whose chip identifier does not match, which is a
  flash image copied to another module, is reported by GET_INFO as not
  calibrated, and so is a missing or corrupt record; nominal values are
  then used and flagged. A module moved to another carrier is not detected
  by firmware. For that case the host shows the stored serial number at
  every connection, to be compared with the label (section 9).
- **Open-switch zero.** With the output switch open the current is zero,
  so firmware measures the offset of every range, locked one by one. It
  runs at start-up and on the command CAL_ZERO, no earlier than 200 ms
  after the output switch opened or after a reset, because the gate of
  that switch needs this time to rest (F-36). The offsets are kept in RAM,
  not in flash. The zero of range 0 drifts by up to 0.7 nA/°C from the
  amplifier alone (datasheet maxima, calculated), so firmware takes the
  zero again whenever the output is off and the board temperature has
  moved by more than 2 °C.
- **Closed-switch zero (D-59).** The open-switch zero does not see what
  loads the node behind the shunts beyond the output switch. With the
  output on and the terminals open, at 5.0 V and at the working voltage,
  300 ms or more after the output was switched on (F-36), the reading of
  range 0 is stored and subtracted. The limit for a board is 50 nA at
  5.0 V and room temperature; the typical figures add up to 4 nA to 6 nA
  at 40 °C (estimate). The step needs the DUT disconnected once per
  calibration.
- **Gain calibration.** In source mode into precision resistors, with the
  output voltage read by a reference multimeter; two points per range,
  near 10 % and 90 % of full scale. It removes the tolerance of the
  shunts, 0.1 % to 0.5 % (D-68), the share of the range 0 shunt in the
  higher ranges and, at the calibration temperature, the leakage across
  the ladder. It does not remove the drift with temperature, 25 ppm/°C for
  ranges 0 to 2 and 50 ppm/°C for range 3 (datasheet values), which is why
  the calibration temperature is stored. After a reported sequencer fault
  (F-21) the gain of range 2 is calibrated again: its 1 Ω shunt has
  carried 6.3 W to 8.4 W for up to 2 ms (calculated).
- **DAC calibration.** Nine set-points or more, at room temperature,
  measured with the reference multimeter (D-58, F-30). Two points do not
  cover the integral non-linearity of the DAC, 15.4 mV at its limit and
  2.6 mV typical (datasheet values, calculated), against the criterion of
  10 mV in the test of R-08 (section 11).
- **Settling window.** After a range change the samples are flagged
  invalid for 7 samples by default (F-35; simulated: 45 µs to 0.1 % of
  range). The length is measured on the prototype with a fast load step
  and then stored as a constant.
- **Output settling.** For 250 ms after the output switch closes the
  samples read low by the charging current of its gate, 0.3 µA after 50 ms
  and 4 nA after 200 ms (simulated). The time is a constant of the host,
  which marks these samples and leaves them out of statistics below 1 µA
  (section 9).

Three more values are found on a board and stored, by the firmware rules of
section 6.6, and section 8 does not list them in the record. Where they are
kept is open, and section 16 lists it among the points to decide:

- the offset of the monitor channel that reads VIN, stored at calibration
  (F-26); before it a true 0.8 V can read 0.67 V (calculated);
- the constants of the input model behind the power budget, calibrated on
  the first board (F-14);
- the thermal limit, a constant taken from the first board (F-15).

## What the Circuit Simulations Add

On 2026-10-10 the circuits of draft A2 were simulated from the netlist of
the schematic ([simulation guide](../../simulation/README.md)). Nothing in
them is measured, and section 8 is unchanged.

- The nominal values come out of the drawn circuit: the amplifier sees
  shunts of 1 kΩ, 31.95 Ω, 999 mΩ and 99.99 mΩ, the gain is 19.93, and
  the code at zero current is 1313 (simulated). Over 120 sets of
  tolerances the gain of the chain lies between 19.87 and 19.97; with the
  tolerance of the shunts, that is what the gain calibration removes.
- One question for section 8 came up. With the amplifier at the limit of
  its common-mode rejection the zero of range 0 moves with the output
  voltage by 2.515 nA per volt, 12.58 nA at 5 V (simulated;
  [`signal_chain/common-mode`](../../simulation/results/signal_chain/README.md#signal_chaincommon-mode)).
  Section 8 does not say at which ladder voltage the open-switch zero is
  taken. The point stays for the bench and for the procedure that is not
  written; the closed-switch zero is taken at 5.0 V and at the working
  voltage.
- The settling after a range change comes out again: 45.37 µs to 0.1 %
  of the range, where the specification has about 45 µs. The charging
  current of the gates of the output switch is 293.1 nA after 50 ms,
  where the specification has 0.3 µA, and 2.748 nA after 200 ms, where it
  has 4 nA: 31 % less, inside the factor of two that the bench sets as
  its limit (simulated).

## Reference Equipment

Section 8 names three things, and no model or accuracy class beyond the
tolerance of the resistors:

| Equipment | Used for |
| --- | --- |
| Precision resistors, 0.01 % | The loads of the gain calibration, two points per range |
| Reference multimeter | The output voltage in the gain calibration and the nine or more set-points of the DAC calibration |
| A fast load step | The length of the settling window, measured once on the prototype |

The DAC calibration is done at room temperature, and the calibration
temperature is stored with the record. Which multimeter is
good enough for the target of R-05, ±1 % of reading ±0.1 % of range, is
part of the procedure that is not written.

## What Is Not Written

- **The procedure.** The steps, the resistor values of each range, the
  order, the pass limits and the form of the result. It belongs on this
  page.
- **The tool.** The scripts under
  [`tools/calibration/`](../../tools/README.md) that drive the instrument
  and the reference equipment. The directory is empty.
- **Firmware support.** The `cal` component of the firmware has no code:
  no record, no storage in flash, no check of the chip identifier, no zero
  calibration. The firmware is not ported to the Pico 2 either (see the
  [firmware guide](../../firmware/README.md)).
- **Host support.** The host package converts codes with a nominal table,
  and its client can send CAL_ZERO and CAL_WRITE to the simulated
  instrument. The nominal table still uses the values of the first plan, a
  gain of 20 and shunts of 1 kΩ, 33 Ω, 1 Ω and 0.1 Ω, not the nominal
  values above. The host does not read a table from the instrument, does
  not show the carrier serial number, does not mark the output settling,
  and has no guided calibration (see the
  [host guide](../../host/README.md)).
- **Protocol support.** The command CAL_WRITE carries a target, a gain and
  an offset. How the other fields of the record reach the instrument (the
  settling window, the temperature, the serial number of the carrier, the
  DAC set-points beyond a gain and an offset) and how the host reads the
  record and its state back through GET_INFO is not defined; the response
  data of GET_INFO is provisional (section 7.4). See the
  [protocol page](../protocol/README.md).

The order of that work follows the next steps in the
[README](../../README.md#project-status) of the repository. First the
software, without a board: the nominal values of draft A2 in the host
package, the decision of section 16 on how the record travels, the record
in the `cal` component, and then the port of the firmware to the Pico SDK.
The procedure and the tool come in phase 6, on a carrier board of
revision A.

A change to the calibration format, once one exists, is a breaking change
(see the [contributing guide](../../CONTRIBUTING.md)).

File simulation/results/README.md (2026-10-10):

# Simulation Results

Everything in this folder is a simulation result: circuits taken from
the netlist of the schematic, run in ngspice, with models that are
named beside every result. Nothing here is measured on hardware. A
figure that passes says that the circuit as drawn, with these models,
keeps the limit; it does not say that a built board will.

The pages are written by `circuit-sim report` from the result files;
do not edit them by hand.

| Block | Bench | What is simulated | Pass | Fail | No limit |
| --- | --- | --- | --- | --- | --- |
| analog_rails | [boost-detector](analog_rails/README.md) | Boost converter with the voltage detector of decision D-84 fitted at U9 | 3 | **7** | 12 |
| analog_rails | [boost-output](analog_rails/README.md) | Boost converter: +13V5 with tolerances, against load, and its ripple | 7 | 0 | 21 |
| analog_rails | [boost-start](analog_rails/README.md) | Boost converter as drawn: its start on a source limited to 0.67 A to 0.85 A | 26 | **1** | 17 |
| analog_rails | [clamps](analog_rails/README.md) | Clamp diodes D8 and D9: one analog rail present, the other one absent | 4 | **2** | 3 |
| analog_rails | [monitor](analog_rails/README.md) | Rail monitor: thresholds with tolerances, hysteresis, and the edge of PWR_GOOD | 15 | **2** | 16 |
| analog_rails | [negative-rail](analog_rails/README.md) | -4V_A: its level and the 5 V rail it needs | 7 | 0 | 1 |
| analog_rails | [power-down](analog_rails/README.md) | Power-off and supervisor trip: the order in which the rails fall | 10 | **12** | 2 |
| analog_rails | [power-up](analog_rails/README.md) | Power-up: the order in which the rails arrive | 27 | **1** | 1 |
| analog_rails | [reference](analog_rails/README.md) | Reference line: level under load, impedance with the capacitors as drawn, noise | 4 | 0 | 18 |
| analog_rails | [supply-noise](analog_rails/README.md) | Noise and ripple of +12V_A and -4V_A, and what passes from the rails ahead | 2 | 0 | 17 |
| digital | [converter-lines](digital/README.md) | Converter lines: edges behind 47 ohm and 220 ohm, cost in timing, reading window | 16 | **2** | 15 |
| digital | [logic-abuse](digital/README.md) | A logic input at +12 V, at -12 V and under a contact discharge of 8 kV | 9 | **5** | 11 |
| digital | [logic-input](digital/README.md) | A logic input: edge, levels, open line, load on the device under test | 22 | 0 | 1 |
| digital | [module-supply](digital/README.md) | The 5 V of the controller module against the 5 V rail: which way current flows | 6 | **1** | 4 |
| digital | [monitor-channels](digital/README.md) | Monitor channels at rest: scale, tolerance, input leakage, VIN at -20 V and +20 V | 18 | **3** | 7 |
| digital | [monitor-sampling](digital/README.md) | Monitor converter while it samples: charge step, settling, edges of the slow SPI bus | 10 | 0 | 4 |
| digital | [released-pins](digital/README.md) | Lines of the controller with its pins released, and the two status lines | 24 | 0 | 2 |
| digital | [side-data](digital/README.md) | Side data chain: load pulse, shift and the sixteen bits at the controller | 12 | 0 | 2 |
| digital | [translator-supply](digital/README.md) | Supply of the user side of the translator: clamp levels, drop at rest, sag | 18 | 0 | 1 |
| digital | [unpowered-inputs](digital/README.md) | Controller lines driven high into parts that have no supply | 10 | 0 | 2 |
| ladder | [change](ladder/README.md) | A range change at the ladder: make-before-break of the range switches | 8 | 0 | 0 |
| ladder | [ranges](ladder/README.md) | The four ranges at rest: shunt seen by the amplifier and burden voltage | 12 | 0 | 6 |
| models | [analog-rails-b0530w](models/README.md) | B0530W models against the datasheet | 9 | 0 | 2 |
| models | [analog-rails-detector](models/README.md) | 803-type voltage detector model against its datasheet | 4 | 0 | 0 |
| models | [analog-rails-lm27761](models/README.md) | LM27761 models against the datasheet | 14 | 0 | 0 |
| models | [analog-rails-lmr62014](models/README.md) | LMR62014 models against the datasheet | 11 | **2** | 2 |
| models | [analog-rails-lt3042](models/README.md) | LT3042 model against its datasheet | 15 | 0 | 0 |
| models | [analog-rails-mcp6569](models/README.md) | MCP6569 model (open-drain output) against its datasheet | 8 | 0 | 0 |
| models | [analog-rails-mlcc](models/README.md) | Ceramic capacitor with its loss under bias against the cited curves | 8 | 0 | 0 |
| models | [analog-rails-ref5025](models/README.md) | REF5025 model against its datasheet | 15 | 0 | 0 |
| models | [digital-1n5819hw](models/README.md) | 1N5819HW model against its datasheet | 11 | 0 | 0 |
| models | [digital-ads8860](models/README.md) | ADS8860 digital pins: model against the datasheet | 6 | 0 | 0 |
| models | [digital-bat54s](models/README.md) | BAT54S model against its datasheet | 15 | 0 | 0 |
| models | [digital-mcp3208](models/README.md) | MCP3208 inputs: model against the datasheet | 7 | 0 | 0 |
| models | [digital-mcp9700a](models/README.md) | MCP9700A model against its datasheet | 6 | 0 | 0 |
| models | [digital-rp2350](models/README.md) | Controller module: pad and supply models against the datasheets | 15 | 0 | 0 |
| models | [digital-sn74lv165a](models/README.md) | SN74LV165A model against its datasheet | 7 | 0 | 0 |
| models | [digital-sn74lvc8t245](models/README.md) | SN74LVC8T245 model against its datasheet | 23 | 0 | 0 |
| models | [digital-tpd4e1u06](models/README.md) | TPD4E1U06 model against its datasheet | 13 | 0 | 0 |
| models | [mosfet-csd17577q3a](models/README.md) | CSD17577Q3A model against its datasheet | 4 | 0 | 2 |
| models | [mosfet-irlml0030](models/README.md) | IRLML0030 model against its datasheet | 4 | 0 | 2 |
| models | [output-stage-buffer](models/README.md) | OPA197 model with a capacitive load behind an isolation resistor | 10 | **7** | 4 |
| models | [output-stage-suppressor](models/README.md) | PTVS15VS1UR model against its datasheet | 6 | 0 | 6 |
| models | [output-stage-transistor](models/README.md) | CSD17577Q3A at the limits of its datasheet: the variants of the output stage | 5 | 0 | 8 |
| models | [path-switching-bc847b](models/README.md) | BC847B model against its datasheet | 8 | 0 | 3 |
| models | [path-switching-bss138](models/README.md) | BSS138 model of the path switching sheet against its datasheet | 9 | 0 | 1 |
| models | [path-switching-fuse](models/README.md) | Model of the fuse 0466004.NR against its datasheet | 1 | 0 | 2 |
| models | [path-switching-smaj20ca](models/README.md) | SMAJ20CA model against its datasheet | 9 | 0 | 0 |
| models | [power-input-capacitors](models/README.md) | Capacitor models of the power input against their datasheets | 13 | **1** | 0 |
| models | [power-input-diodes](models/README.md) | 1N5819HW, SMAJ10A, TPD4E1U06 and LED models against their datasheets | 14 | 0 | 4 |
| models | [power-input-limiter](models/README.md) | TPS259621 model against its datasheet | 24 | 0 | 0 |
| models | [power-input-multiplexer](models/README.md) | TPS2116 model against its datasheet | 16 | 0 | 1 |
| models | [power-input-regulator](models/README.md) | LP5907-3.3 model against its datasheet | 14 | 0 | 0 |
| models | [power-input-supervisor](models/README.md) | TPS3808G01 model against its datasheet | 6 | 0 | 3 |
| models | [range-logic-mcp6561](models/README.md) | MCP6561 model against its datasheet: thresholds, hysteresis and delay | 4 | 0 | 6 |
| models | [signal-chain-ad8421](models/README.md) | AD8421 model against its datasheet | 35 | **2** | 1 |
| models | [signal-chain-ads8860](models/README.md) | ADS8860 analog input and reference pin: model against the datasheet | 7 | 0 | 1 |
| models | [signal-chain-opa197](models/README.md) | OPA197 model against its datasheet | 21 | 0 | 2 |
| models | [signal-chain-opa365](models/README.md) | OPA365 model against its datasheet | 17 | 0 | 1 |
| models | [source-meter-lt3080](models/README.md) | LT3080 model of the source meter against its datasheet | 18 | **3** | 15 |
| models | [source-meter-mcp4921](models/README.md) | MCP4921 model of the source meter against its datasheet | 11 | 0 | 0 |
| models | [source-meter-parts](models/README.md) | Diode, transistor, bead and inductor of the source meter against their datasheets | 19 | 0 | 1 |
| models | [source-meter-tps63020](models/README.md) | TPS63020 model of the source meter against its datasheet | 16 | **2** | 3 |
| output_stage | [guard](output_stage/README.md) | The guard buffer: stability with the guard ring, static error, range change, output off | 14 | 0 | 13 |
| output_stage | [on-resistance](output_stage/README.md) | The closed output pair at 1 A: burden behind the shunts, over the output range | 4 | 0 | 8 |
| output_stage | [short-circuit](output_stage/README.md) | A short circuit at the closed output: current, trip, energy and voltages | 58 | **2** | 57 |
| output_stage | [terminal](output_stage/README.md) | The output terminal under abuse: reversed source, live source on the open output, charged capacitor on a lower output | 17 | 0 | 30 |
| output_stage | [turn-off](output_stage/README.md) | The output switch opens under load: gate, current, terminal and suppressor | 33 | **3** | 27 |
| output_stage | [turn-on](output_stage/README.md) | The output switch closes: gate ramp, output ramp and in-rush into a capacitor | 25 | **1** | 7 |
| path_switching | [close](path_switching/README.md) | A mode pair closes on a live supply: gate ramp and source follower | 28 | 0 | 12 |
| path_switching | [detector](path_switching/README.md) | The over-voltage detector of VIN: levels with tolerances and reaction time | 12 | **2** | 6 |
| path_switching | [drop](path_switching/README.md) | The two paths at rest: drop at 1 A, gate drive and current taken from VIN | 12 | **3** | 26 |
| path_switching | [hand-over](path_switching/README.md) | A pair closes while the supply node still holds a higher voltage | 2 | 0 | 4 |
| path_switching | [idle](path_switching/README.md) | The supply node with every path switch open: idle level and decay | 3 | 0 | 5 |
| path_switching | [interlock](path_switching/README.md) | The interlock of the two mode pairs and a change of mode | 29 | 0 | 1 |
| path_switching | [open](path_switching/README.md) | A mode pair opens under load: time to block and the kick of the supply leads | 47 | **3** | 28 |
| path_switching | [overvoltage](path_switching/README.md) | The supply rises above its range while the ampere pair is closed | 27 | **3** | 23 |
| path_switching | [plug](path_switching/README.md) | A supply of +20 V or -20 V is plugged into VIN with the ampere pair open | 24 | 0 | 28 |
| path_switching | [reversal](path_switching/README.md) | The supply reverses while the ampere pair is closed | 15 | **4** | 29 |
| path_switching | [ring](path_switching/README.md) | Ampere mode: a load step to 1 A rings on the supply leads against the capacitor at the load | 4 | 0 | 23 |
| path_switching | [sag](path_switching/README.md) | Ampere mode: the supply node after a load step of 500 mA behind supply leads | 3 | 0 | 4 |
| path_switching | [short](path_switching/README.md) | A short circuit in ampere mode: the trip opens the output and the supply leads kick | 41 | **4** | 30 |
| path_switching | [trip](path_switching/README.md) | Ampere mode: the output opens at 0.5 A to 1.2 A behind 0.5 uH to 3 uH of supply leads | 14 | 0 | 15 |
| path_switching | [withstand](path_switching/README.md) | The VIN terminal from -20 V to +20 V with the ampere pair open | 27 | 0 | 1 |
| power_input | [contact-bounce](power_input/README.md) | A contact of the USB-C cable opens and closes again: what reaches the multiplexer | 22 | 0 | 13 |
| power_input | [current-limit](power_input/README.md) | The current limits of the two inputs and a short circuit of the 5 V rail | 5 | **4** | 10 |
| power_input | [load-step](power_input/README.md) | A load step of 1 A on the 5 V rail: the dip and its recovery with the capacitors as drawn | 11 | 0 | 14 |
| power_input | [logic-rails](power_input/README.md) | The supervisor of the 5 V rail and the two 3.3 V rails: thresholds, delay, start and trip | 15 | **2** | 6 |
| power_input | [overload](power_input/README.md) | A load beyond what the source gives: the rail falls and the supervisor sheds the carrier | 13 | 0 | 6 |
| power_input | [overvoltage](power_input/README.md) | Too much voltage and the wrong polarity at the USB-C receptacle | 9 | **3** | 4 |
| power_input | [path-drop](power_input/README.md) | The drop from each connector to the 5 V rail at the loads of the specification | 9 | 0 | 5 |
| power_input | [plug-module](power_input/README.md) | Plugging the cable of the controller module: in-rush on the port of a computer | 17 | **13** | 8 |
| power_input | [plug-usbc](power_input/README.md) | Plugging a live USB-C source: peak at the receptacle, in-rush, soft start, the 5 V rail | 13 | **2** | 13 |
| power_input | [replug-module](power_input/README.md) | The cable of the module is plugged again: what reaches input 2 of the multiplexer | 35 | **2** | 14 |
| power_input | [switch-over](power_input/README.md) | USB-C plugged while the module input supplies: the change of input and the dip of the rail | 16 | 0 | 8 |
| power_input | [thresholds](power_input/README.md) | The levels at which the limiter and the multiplexer switch, and what the monitor reads | 18 | 0 | 1 |
| power_input | [unplug](power_input/README.md) | The USB-C cable is pulled: the rail falls, the multiplexer changes to the module input | 7 | **1** | 11 |
| range_logic | [blanking](range_logic/README.md) | The blanking time: the old voltage after a change and the pulse of a step down | 4 | 0 | 23 |
| range_logic | [hot-plug](range_logic/README.md) | Hot plug of 100 uF and a short circuit at the output: the surge in the ladder | 14 | **1** | 5 |
| range_logic | [input-clamp](range_logic/README.md) | The comparator inputs with 3V3_A off and the amplifier output at 10 V | 9 | 0 | 4 |
| range_logic | [jump](range_logic/README.md) | The jump path: from the jump threshold at the ladder to range 3 conducting | 12 | 0 | 5 |
| range_logic | [landing](range_logic/README.md) | Load steps with a capacitor at the load: the range reached and the time to a true reading | 1 | **1** | 37 |
| range_logic | [load-step](range_logic/README.md) | Requirement R-07: the drop on a step from 1 uA to 500 mA, and the ladder clamp | 23 | 0 | 7 |
| range_logic | [power-on](range_logic/README.md) | DUT power on into 1000 uF to 3300 uF: the in-rush against the armed trip | 6 | 0 | 6 |
| range_logic | [ramp](range_logic/README.md) | A slow ramp from 1 uA to 1 A and back: one range at a time, no bounce | 18 | 0 | 10 |
| range_logic | [reverse](range_logic/README.md) | Reverse current through the ladder: under-range level and voltage across the ladder | 6 | 0 | 2 |
| range_logic | [supply-leads](range_logic/README.md) | Ampere mode behind supply leads: sag of the supply node, ringing and the trip | 7 | **2** | 9 |
| range_logic | [thresholds](range_logic/README.md) | The three comparator thresholds, with tolerances, and their hysteresis | 31 | 0 | 4 |
| range_logic | [trip](range_logic/README.md) | The over-current trip after 12 us, and the recharge of a load capacitor | 12 | **2** | 10 |
| signal_chain | [common-mode](signal_chain/README.md) | Offset and gain of the chain against the output voltage | 6 | 0 | 14 |
| signal_chain | [driver-rail](signal_chain/README.md) | The driver rail: output of the buffer U28, the rail, and the stability of its loop | 8 | **3** | 11 |
| signal_chain | [frequency](signal_chain/README.md) | Frequency response: input filter and anti-alias filter | 8 | 0 | 9 |
| signal_chain | [head-room](signal_chain/README.md) | Head room of the amplifier near full scale with the output voltage near 0 V | 10 | **2** | 15 |
| signal_chain | [limiter](signal_chain/README.md) | The limiter in front of the converter driver during an over-range | 13 | 0 | 15 |
| signal_chain | [noise](signal_chain/README.md) | Noise of the chain at the converter input, by range | 4 | 0 | 22 |
| signal_chain | [pedestal](signal_chain/README.md) | The pedestal: divider with its 1 uF, the buffer U26 and the reference pin of U27 | 7 | **1** | 10 |
| signal_chain | [reference-line](signal_chain/README.md) | The reference pin of the converter during a conversion: R131 and C89 | 4 | 0 | 8 |
| signal_chain | [sampling-kick](signal_chain/README.md) | The converter input: settling of the sampling kick through R130 and C90 | 6 | **2** | 3 |
| signal_chain | [settling](signal_chain/README.md) | Settling of the chain after a range change | 31 | 0 | 0 |
| signal_chain | [transfer](signal_chain/README.md) | From the shunt voltage to the converter input and to the code, with tolerances | 16 | 0 | 4 |
| source_meter | [enable](source_meter/README.md) | The enable pin of the pre-regulator behind Q1, over the 5 V rail | 11 | 0 | 1 |
| source_meter | [external](source_meter/README.md) | A device above the set-point: current drawn from it, clamps, the 5 V rail | 6 | **2** | 10 |
| source_meter | [filter](source_meter/README.md) | The filter in front of the IN pin: source impedance with and without the damper | 0 | 0 | 18 |
| source_meter | [load-step](source_meter/README.md) | Load steps from microamperes to 100 mA and to the curve: droop, recovery, head room | 28 | 0 | 72 |
| source_meter | [loop](source_meter/README.md) | Loop gain and phase margin: linear regulator, pre-regulator, tracking amplifier | 6 | 0 | 33 |
| source_meter | [noise](source_meter/README.md) | Noise of the source across the 1 kohm shunt of range 0 | 8 | 0 | 2 |
| source_meter | [pre-regulator](source_meter/README.md) | The pre-regulator with its tracking amplifier: start and a load step to the curve | 13 | 0 | 49 |
| source_meter | [rails](source_meter/README.md) | A missing or falling rail, the minimum load and the set-point filter in a hold-off | 16 | 0 | 1 |
| source_meter | [sequence](source_meter/README.md) | Start and stop of the source in the order of rules F-28 and F-29, set-point steps | 21 | **1** | 15 |
| source_meter | [setpoint](source_meter/README.md) | The set-point: DAC code to output voltage, step, ceiling and tolerances | 15 | 0 | 12 |
| source_meter | [short](source_meter/README.md) | Short circuit at the output: current limit, pre-regulator, dissipation of U18 | 20 | 0 | 20 |
| source_meter | [tracking](source_meter/README.md) | The tracking pre-regulator at rest: law, head room on the curve, dissipation | 32 | 0 | 14 |
| system | [accuracy](system/README.md) | From the load current to the code, every range held | 18 | 0 | 0 |
| system | [profile](system/README.md) | A load profile with automatic ranging: sleep, wake, burst, sleep | 7 | 0 | 3 |

Simulator: ngspice-45.2 shared library.

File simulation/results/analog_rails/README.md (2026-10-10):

# Simulation Results: Analog Rails and Rail Monitor

Everything on this page is a simulation result. Nothing here is measured on
hardware. The page is written by `circuit-sim report` from the result files
beside it; do not edit it by hand.

## `analog_rails/boost-detector`

**Boost converter with the voltage detector of decision D-84 fitted at U9.**

A detector of 3.08 V holds the converter off until the 5 V rail has stood for a
while. The position U9 is empty on the board. Here it carries an 803-type
detector: its output holds the enable pin of the converter low until the rail
has been above 3.08 V for the time-out of the part, and pulls it low again 20 us
after the rail has fallen below. The converter then starts on a rail that
already stands at 5 V, with +13V5 at 4.6 V. The first attempt is taken cycle by
cycle on the three limits of the input of the controller module, on the corner
that is kindest to the source, and on the USB-C input. Two runs of 1.1 s with
the averaged model and the real time-out of 0.24 s then show what follows a
failed attempt, with 1 mA and with 0.1 mA drawn from +13V5 in between.

Answers: section 4.1 (the detector is the remedy if the converter does not start
cleanly), requirement R-14, decision D-84, the risk register.

| Figure | Simulated | Specification | Limits | Verdict | Source |
| --- | --- | --- | --- | --- | --- |
| First attempt, source limited to 0.67 A: lowest 5 V rail | 2.928 V | | at least 3.13 V | **FAIL** | datasheet of the detector: it stops the converter at 3.04 V to 3.13 V; a rail that stays above 3.13 V is a start in one go |
| First attempt, source limited to 0.67 A: +13V5 when the detector stops the converter | 10.21 V | | | | |
| First attempt, source limited to 0.67 A: time from the enable to the stop | 177.5 µs | | | | |
| First attempt, source limited to 0.76 A: lowest 5 V rail | 2.976 V | | at least 3.13 V | **FAIL** | datasheet of the detector: it stops the converter at 3.04 V to 3.13 V; a rail that stays above 3.13 V is a start in one go |
| First attempt, source limited to 0.76 A: +13V5 when the detector stops the converter | 10.73 V | | | | |
| First attempt, source limited to 0.76 A: time from the enable to the stop | 203.5 µs | | | | |
| First attempt, source limited to 0.85 A: lowest 5 V rail | 3.03 V | | at least 3.13 V | **FAIL** | datasheet of the detector: it stops the converter at 3.04 V to 3.13 V; a rail that stays above 3.13 V is a start in one go |
| First attempt, source limited to 0.85 A: +13V5 when the detector stops the converter | 11.48 V | | | | |
| First attempt, source limited to 0.85 A: time from the enable to the stop | 249 µs | | | | |
| First attempt, 0.85 A, gentle amplifier and least current limit: lowest 5 V rail | 3.62 V | | at least 3.13 V | pass | datasheet of the detector: it stops the converter at 3.04 V to 3.13 V; a rail that stays above 3.13 V is a start in one go |
| First attempt, 0.85 A, gentle amplifier and least current limit: +13V5 at the end of the run | 13.98 V | | | | |
| First attempt, source limited to 2.0 A: lowest 5 V rail | 4.586 V | | at least 3.13 V | pass | datasheet of the detector: it stops the converter at 3.04 V to 3.13 V; a rail that stays above 3.13 V is a start in one go |
| First attempt, source limited to 2.0 A: +13V5 at the end of the run | 13.66 V | | | | |
| First attempt, 0.76 A: lowest 5 V rail, averaged model | 3.006 V | 2.976 V (+1.01 %) | 2.827 V to 3.124 V | pass | the cycle-by-cycle model in the same circuit (check of the averaged model) |
| 0.76 A, a detector with a time-out of 3 ms: attempts until +13V5 is charged | 2 | | | | |
| 0.76 A, a detector with a time-out of 3 ms: +13V5 above 13.0 V after the first enable | 3.379 ms | | | | |
| 0.76 A, 1 mA on +13V5: number of starts of the converter in 1.1 s | 4 | | at most 1 | **FAIL** | decision D-84: the detector is the remedy for a start that hangs or repeats |
| 0.76 A, 1 mA on +13V5: +13V5 above 13.0 V after the source starts | nan s | | at most 460 ms | **FAIL** | section 3, step 8: PWR_GOOD at the latest 0.46 s after power |
| 0.76 A, 1 mA on +13V5: +13V5 just before the second start | 4.817 V | | | | |
| 0.76 A, 0.1 mA on +13V5: number of starts of the converter in 1.1 s | 2 | | at most 1 | **FAIL** | decision D-84: the detector is the remedy for a start that hangs or repeats |
| 0.76 A, 0.1 mA on +13V5: +13V5 above 13.0 V after the source starts | 485.6 ms | | at most 460 ms | **FAIL** | section 3, step 8: PWR_GOOD at the latest 0.46 s after power |
| 0.76 A, 0.1 mA on +13V5: +13V5 just before the second start | 8.867 V | | | | |

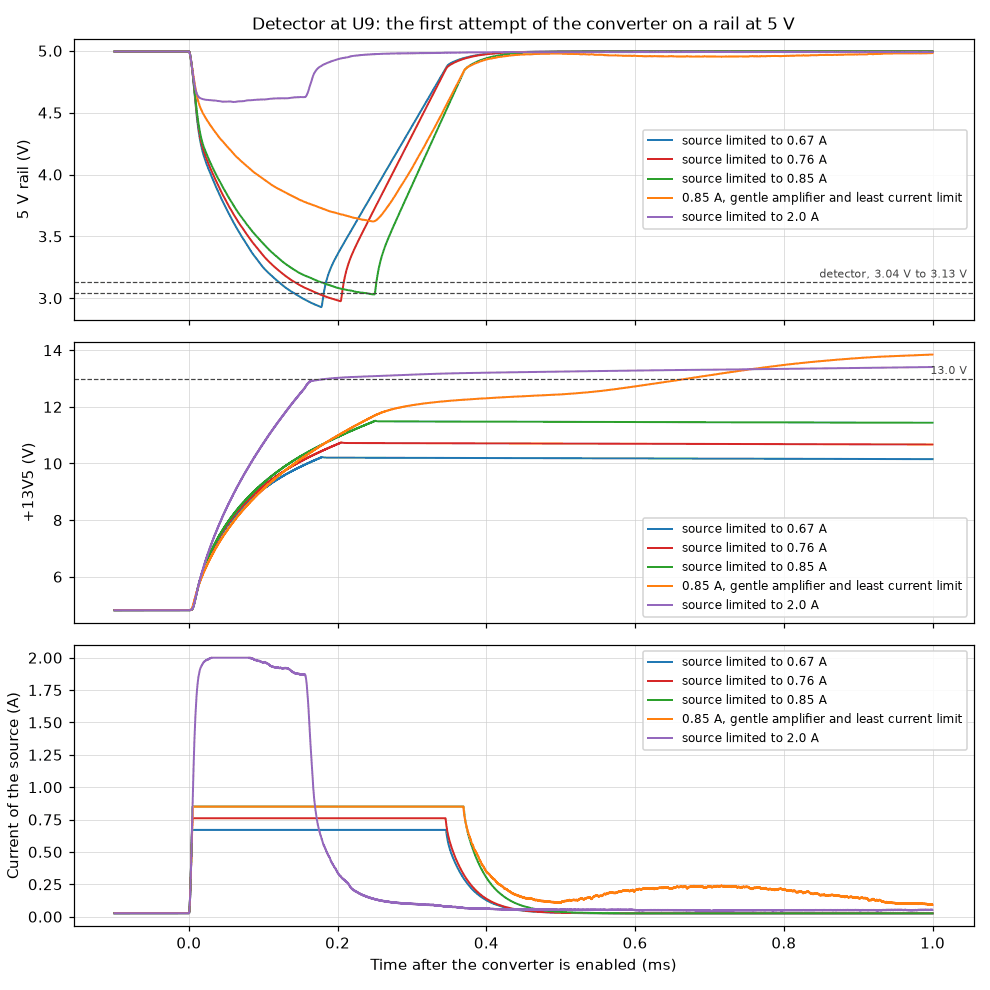
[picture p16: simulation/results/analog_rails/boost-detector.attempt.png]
Detector at U9: the first attempt of the converter on a rail at 5 V


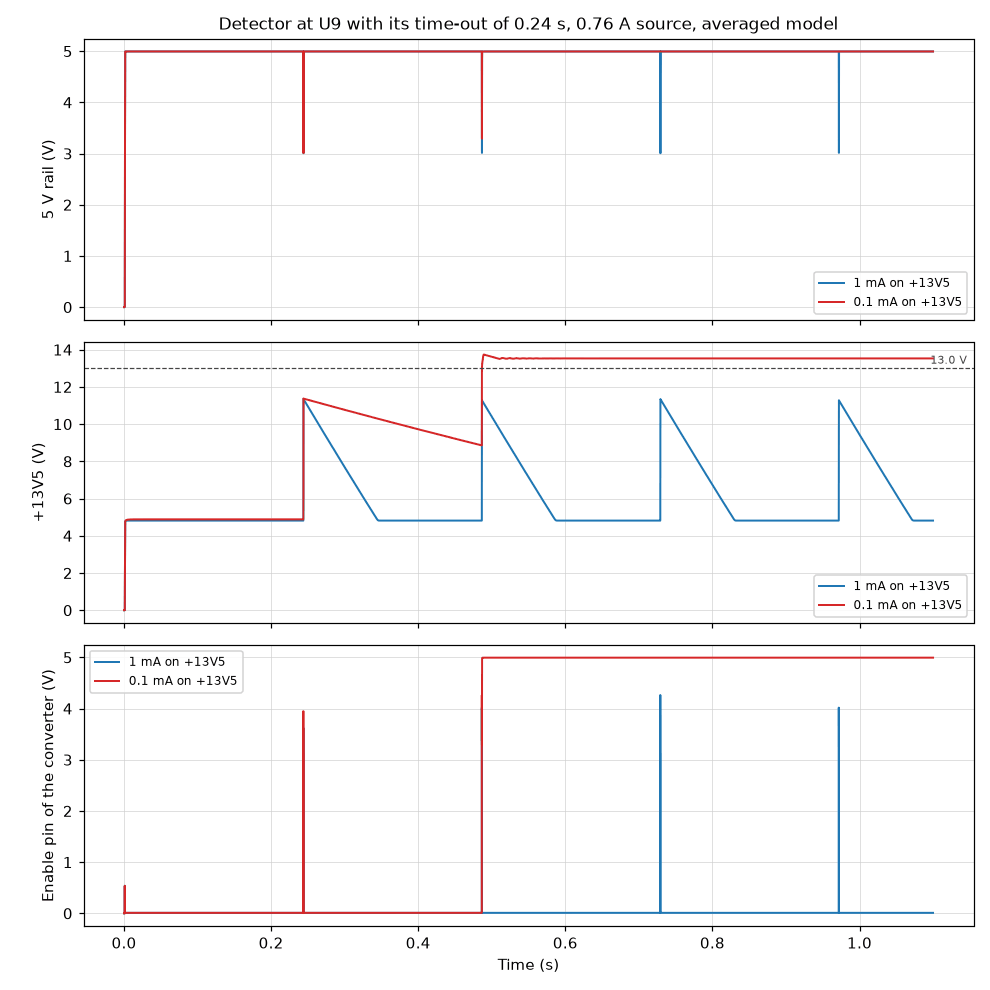
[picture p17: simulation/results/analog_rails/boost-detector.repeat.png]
Detector at U9 with its time-out of 0.24 s, 0.76 A source, averaged model


Notes:

- The detector carries the figures of the APX803S-31: 3.08 V, 20 us to answer,
  0.24 s of time-out. The schematic names the position "803 type, 3.08 V"
  without a part number.
- The source is a voltage behind 0.2 ohm with a flat current limit and no path
  back; a limiter that folds back or switches off while it limits makes the
  attempt harder, not easier.
- With the detector the converter starts on a rail at 5 V. There it takes more
  than twice what the input of the controller module gives, the capacitors of
  the rail make up the difference, and the rail reaches the detector before
  +13V5 is charged. The detector then stops the converter for 0.24 s. Whether a
  later attempt ends depends on what +13V5 keeps in between: with 1 mA drawn
  from it nothing is left and every attempt is the first one again.
- The cycle-by-cycle runs wait 3 ms where the part waits 0.24 s, and they go on
  to the second attempt of such a detector: in 3 ms +13V5 keeps its charge and
  the second attempt ends. A detector with a short time-out, or anything else
  that keeps +13V5 from emptying between two attempts, charges the rail in two
  steps; the part of the schematic does not.
- The load on +13V5 while the detector waits is an assumption: 1 mA for the
  control pin of the source regulator, whose datasheet gives it only under load,
  beside the 0.09 mA of the feedback divider, which is in the netlist.
- The converter model takes its current limit from the typical curve of the
  datasheet and holds the full current until the output is within 1 V. The case
  "gentle amplifier and least current limit" takes both the other way and is the
  kindest corner for the source that the datasheet allows.
- The ceramic capacitors are linear in every run: those of +13V5 take the value
  that needs the energy of the real charge from 4.6 V to 13.5 V, those of the 5
  V rail the value they have at 5 V, which is less than they have while the rail
  is lower.

Models. written here: B0530W, LMR62014, LMR62014_AVG, L_74438357100,
PWRIN_WCAP_47U, RAILS_803.

Decks: [boost-detector.first-0p76.cir](boost-detector.first-0p76.cir),
[boost-detector.long-1ma.cir](boost-detector.long-1ma.cir).

## `analog_rails/boost-output`

**Boost converter: +13V5 with tolerances, against load, and its ripple.**

The boost converter on a 5 V rail that is up, with the loads of +13V5. The level
of +13V5 is read from the averaged model: with typical parts, with the feedback
voltage and the 1 % divider at their limits, at 10 mA and at 40 mA of load, and
with the 5 V rail at 4.25 V and at 5.5 V. The ripple is read from the
cycle-by-cycle model at the same two loads, at the output of the converter,
behind the filter R37 with C29 at the input of the +12V_A regulator, and on the
5 V rail; then once more with a 0 ohm part in the place of R37.

Answers: section 3 (analog rails, 13.0 V to 14.1 V), decision D-51.

| Figure | Simulated | Specification | Limits | Verdict | Source |
| --- | --- | --- | --- | --- | --- |
| +13V5, typical parts, 10 mA | 13.53 V | 13.53 V (+0.00 %) | 13.46 V to 13.6 V | pass | section 3: 13.5 V; 1.23 V x (1 + R32 / R33) |
| +13V5, feedback voltage and divider at the limits that make it highest | 14.06 V | | 13 V to 14.1 V | pass | section 3: 13.0 V to 14.1 V |
| +13V5, feedback voltage and divider at the limits that make it lowest, 40 mA | 13.02 V | | 13 V to 14.1 V | pass | section 3: 13.0 V to 14.1 V |
| +13V5: change from 10 mA to 40 mA | -352.7 µV | | | | |
| +13V5 with the 5 V rail at 4.25 V, 40 mA | 13.53 V | | 13 V to 14.1 V | pass | section 3: 13.0 V to 14.1 V; D-49: the rail may stand at 4.25 V |
| +13V5 with the 5 V rail at 5.5 V, 10 mA | 13.53 V | | 13 V to 14.1 V | pass | section 3: 13.0 V to 14.1 V |
| Current from the 5 V rail at 10 mA of load | 29.86 mA | | | | |
| Current from the 5 V rail at 40 mA of load | 113.6 mA | | | | |
| Ripple at the output of the converter within two switching periods, peak to peak, 10 mA | 879.4 µV | | | | |
| Slow movement at the output of the converter over 0.25 ms, peak to peak, 10 mA | 1.352 mV | | | | |
| Ripple behind R37 with C29 within two switching periods, peak to peak, 10 mA | 39.82 µV | | | | |
| Slow movement behind R37 with C29 over 0.25 ms, peak to peak, 10 mA | 1.217 mV | | | | |
| Ripple on the 5 V rail within two switching periods, peak to peak, 10 mA | 867.9 µV | | | | |
| Slow movement on the 5 V rail over 0.25 ms, peak to peak, 10 mA | 1.108 mV | | | | |
| Ripple at the input of the +12V_A regulator with R37 at 0 ohm, 10 mA | 451.8 µV | | | | |
| That ripple behind the regulator by its 79 dB, R37 as drawn, 10 mA | 4.468 nV | | | | |
| The same with R37 at 0 ohm, 10 mA | 50.69 nV | | | | |
| Highest inductor current in regulation, 10 mA | 121.7 mA | | at most 3 A | pass | datasheet of the inductor: 10 % of the inductance lost at 3 A |
| Ripple at the output of the converter within two switching periods, peak to peak, 40 mA | 2.542 mV | | | | |
| Slow movement at the output of the converter over 0.25 ms, peak to peak, 40 mA | 5.135 mV | | | | |
| Ripple behind R37 with C29 within two switching periods, peak to peak, 40 mA | 129.2 µV | | | | |
| Slow movement behind R37 with C29 over 0.25 ms, peak to peak, 40 mA | 4.547 mV | | | | |
| Ripple on the 5 V rail within two switching periods, peak to peak, 40 mA | 1.144 mV | | | | |
| Slow movement on the 5 V rail over 0.25 ms, peak to peak, 40 mA | 3.597 mV | | | | |
| Ripple at the input of the +12V_A regulator with R37 at 0 ohm, 40 mA | 1.319 mV | | | | |
| That ripple behind the regulator by its 79 dB, R37 as drawn, 40 mA | 14.5 nV | | | | |
| The same with R37 at 0 ohm, 40 mA | 148 nV | | | | |
| Highest inductor current in regulation, 40 mA | 241.5 mA | | at most 3 A | pass | datasheet of the inductor: 10 % of the inductance lost at 3 A |

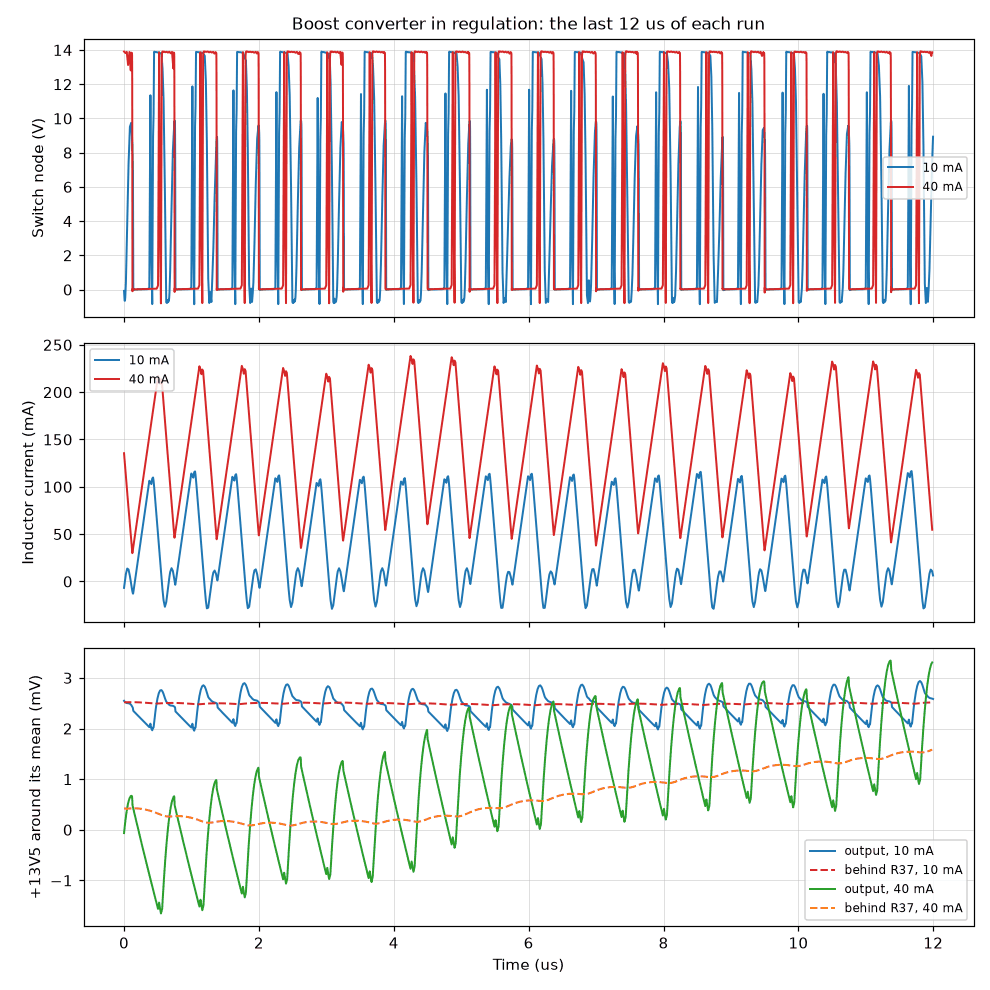
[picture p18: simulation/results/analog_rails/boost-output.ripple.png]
Boost converter in regulation: the last 12 us of each run


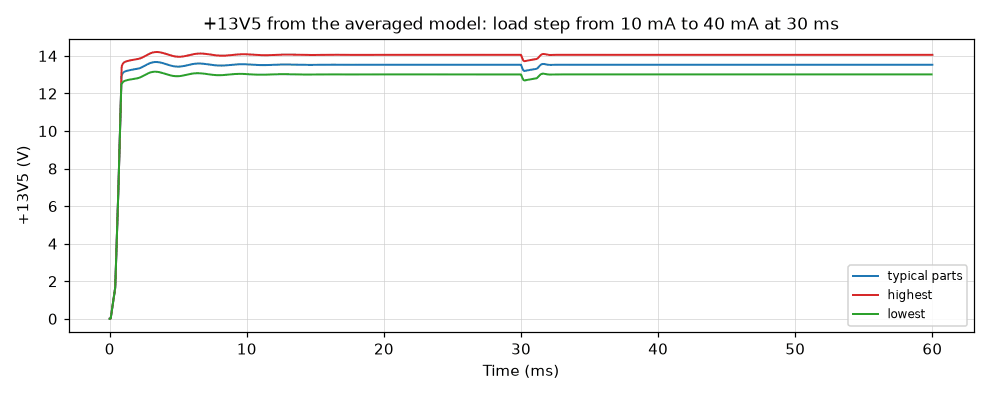
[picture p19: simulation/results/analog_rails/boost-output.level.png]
+13V5 from the averaged model: load step from 10 mA to 40 mA at 30 ms


Notes:
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

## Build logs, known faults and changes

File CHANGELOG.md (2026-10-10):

# Changelog

All notable changes to this project are documented in this file.

The format is based on
[Keep a Changelog](https://keepachangelog.com/en/1.1.0/), and this project
adheres to [Semantic Versioning](https://semver.org/spec/v2.0.0.html).

Each entry starts with the area it affects: **firmware**, **hardware**,
**host**, **protocol**, **tools**, **simulation**, **docs** or **repo**.

## [Unreleased]

### Added

- **docs:** system specification with requirements, analog and firmware
  architecture, host protocol, calibration, verification plan, development
  phases, risk register and decision log.
- **docs:** templates and indexes for component checks and phase reports.
- **repo:** monorepo layout with `firmware/`, `hardware/`, `host/`, `tools/`
  and `docs/`.
- **repo:** contributing guide, issue and pull request templates, editor and
  lint configuration, documentation lint workflow.
- **repo:** MIT license for everything outside `hardware/` and CERN-OHL-P v2
  for the hardware design files.
- **protocol:** one definition of the wire protocol in
  `protocol/definition.toml`, with a generator for the firmware and host
  constants and for the test vectors that both codecs must reproduce.
- **firmware:** ESP-IDF project for the ESP32-S3 with the
  hardware-independent core, unit-tested on the PC: CRC, frame encoder and
  parser, sample word, stream payload, command envelopes, the block queue
  between the cores, the settling window, the step-down rule and the device
  state machine. It drives no hardware yet.
- **host:** Python package `s3-power-profiler` with the protocol codec,
  serial and in-memory transports, a device client, a capture reader with gap
  detection, nominal calibration and statistics, a device simulator and the
  `s3pp` command.
- **hardware:** KiCad 10 project of the carrier board with the sockets of the
  development board and the 19 signals between the boards.
- **hardware:** draft A0 of the carrier board: the complete schematic on
  thirteen A4 sheets drawn with wires, and a board file with every footprint
  placed by functional block and no tracks. A review draft with candidate
  parts, not a design to fabricate.
- **hardware:** project symbols for the ADS8860, the MUX509 and the TPS63020,
  and a power-symbol library for the supply rails.
- **hardware:** pictures of every schematic sheet and of the board, and the
  schematic as PDF, in `hardware/doc/`.
- **hardware:** draft A1 of the carrier board. A Raspberry Pi Pico 2 on
  sockets is the only programmable part; two shift registers carry the
  side data; the DUT connects through a pin header and a lever terminal
  block in the pin order of the PPK2, and the logic port has that order
  too. The board is 130 mm × 100 mm with every part placed near the pin it
  serves.
- **repo:** continuous integration for firmware, host software, protocol and
  hardware, with coverage floors and static analysis.
- **hardware:** draft A2 of the carrier schematic: 428 parts on 15 A4
  pages, 14 sheets below the root sheet (D-83). It passes the electrical
  rules check and was checked independently against datasheets; the parts
  stay candidates, and nothing is built or measured.
- **hardware:** input stage with a current limiter on each USB input and a
  priority multiplexer that supplies the 5 V rail from USB-C whenever it is
  present (D-47). A supervisor on the 5 V rail switches the supplies of the
  carrier off as one below 3.9 V (calculated, D-48).
- **hardware:** rail monitor on a sheet of its own: PWR_GOOD comes from
  four comparators that watch 3V3_A, +12 V_A, −4 V_A and the reference
  (D-54).
- **hardware:** VIN protection that withstands −20 V to +20 V while the
  ampere switch is open (simulated), with a bidirectional suppressor, a
  fuse and a detector that refuses to close the switch above 5.46 V
  (calculated, D-60). An interlock transistor keeps the two mode switches
  from closing together (D-62).
- **hardware:** ESD arrays at the CC pins and at the VCC pin of the logic
  port (D-50), test points on the nodes that draft A2 adds, and positions
  without parts for a voltage detector at the boost converter and for a
  damper on the input from the controller module (D-84).
- **hardware:** a project symbol for the input multiplexer TPS2116, and
  project footprints for the lever terminal block and for the controller
  module (D-83, D-85).
- **docs:** one list of the firmware rules that guard hardware, in section
  6.6 of the specification, with the hardware watchdog of the controller as
  the last line of defense (D-81).
- **docs:** the README states where every area of the project stands and
  the next steps in their order, and shows the routed layers, the open
  connections, the placement and the check results of draft A2.
- **hardware:** the bill of materials of draft A2 is filed as
  `hardware/doc/bom.csv`: 151 lines, each with a part number and a maker.
- **docs:** the hardware guide lists the 28 open connections of the
  board one by one, with what each breaks while it is open and a map of
  them, and the simulations whose files have to be filed.
- **docs:** the firmware, host and protocol guides compare the code with
  what the specification of draft A2 asks, item by item, and give the next
  steps of each area; the pages on calibration, tools and test reports say
  what the specification defines today and what is not written.
- **hardware:** two pictures of the reviewed board in
  `hardware/doc/images/`: `board-front-end.png`, the measured node under
  the shield can with the guard and the Kelvin lines, and
  `board-1a-path.png`, the pours from the linear regulator to the terminal
  block. Both are plots of the board file, not photographs.
- **docs:** the hardware guide lists, one by one, the seven points in which
  the reviewed board deviates from the layout guidelines that section 10
  of the specification had for draft A2, each recorded as a decision (D-87
  to D-93), and the open items of the layout that need a part moved or
  another footprint.
- **tools:** the package `board-figures` in `tools/board/`, with a command
  of the same name. It calculates the layout figures that the documents
  quote from a dump of the board file of the carrier: the resistance of
  the copper of a net between pads in squares and in milliohms, a path on
  one layer alone, the center-line lengths of the two lines of a pair, the
  surface leakage into the measured node, and all figures of the carrier
  in one report. What is specific to the carrier board is in
  `tools/board/carrier.toml`, and an adapter that runs under the Python of
  KiCad 10 writes the dump. Every figure it gives is calculated from the
  drawn copper; it measures nothing.
- **tools:** the package is tested without hardware and without KiCad: 260
  tests on small synthetic boards with answers known by hand, 100 % of
  lines and branches covered against a floor of 90 %, ruff, and mypy in
  strict mode. These checks ran locally on Windows. The package brings
  numpy, scipy and shapely as dependencies, for this package only.
- **repo:** the workflow `Tools` runs the checks of `tools/board/` on
  Windows, Linux and macOS and builds and installs the package. Like the
  other workflows it is started by hand (D-22); it has not been started
  yet.
- **docs:** a guide of the board figures in `tools/board/README.md`: how
  to install the package, make the dump and run each command, with the
  method, the assumptions and the limits of each calculation.
- **simulation:** the package `circuit-sim` in `simulation/`, with a
  command of the same name, simulates the circuits of the carrier board
  (D-94). A bench names parts of the schematic by their reference
  designators; the package writes their elements from a snapshot of the
  netlist that KiCad exports, runs the circuit in the ngspice shared
  library that KiCad 10 ships, takes figures from the waveforms, and
  judges each against its limit: a figure of the specification, a rating
  of a datasheet, or a limit that the bench sets and names. It files the
  figures, a graph of the waveforms and the decks, the circuit files
  that the simulator ran, and writes a page for each block from them. No
  part of the board is typed by hand; sources, loads and cables are.
- **simulation:** models of the parts, written for the project from their
  datasheets, each with the source of its figures and a list of what it
  leaves out. 41 benches put them into the test circuits of their
  datasheets; four models have no such bench, and the simulation guide
  names them. The model files of the manufacturers are not in the
  repository, because their licenses do not allow a copy; where a copy is
  present, a second run gives a second value beside the first.
- **simulation:** the results of 2026-10-10 on the netlist of draft A2, in
  `simulation/results/`: 134 benches, 93 on the circuits of the board in
  ten blocks (shunt ladder, signal chain, range logic, source meter,
  output stage, path switching, power input, analog rails, digital lines,
  whole measuring path) and 41 on the models. Of 3162 figures 1834 pass,
  122 fail and 1206 carry no limit; a figure that fails is kept as it is.
  The folder holds 251 graphs and 289 decks. Everything in it is
  simulated: no board is built and nothing is measured.
- **simulation:** what those results say. The central design figures of
  the specification come out again block by block, among them the drop of
  requirement R-07 on a step from 1 µA to 500 mA with 1 µF: 301.9 mV with
  nominal delays, and 388.2 mV with every delay at its limit and the
  capacitor 10 % low, against the limit of 500 mV (simulated). The
  simulations raised four points for a decision before boards are
  ordered: the capacitors of the rail monitor, the buffer of the driver
  rail, the detector position at the boost converter and the damper on
  the module input. The project owner decided them (D-95 to D-98, under
  "Changed"). In fourteen places the simulation and the text of the
  specification differ. Those are not decided, and the specification
  keeps its text there.
- **simulation:** the package is tested: 777 tests, of which 11 need the
  ngspice library, 100 % of lines and branches covered against a floor of
  90 %, the module that loads the simulator excepted, ruff, and mypy in
  strict mode over the package, its tests and the benches. These checks
  ran locally on Windows with Python 3.11 and ngspice 45.2. The package
  brings numpy and matplotlib as dependencies.
- **repo:** the workflow `Simulation` runs the checks of `simulation/` on
  Windows, Linux and macOS, runs the tests that need the simulator with
  the ngspice library of a Linux distribution, and builds and installs the
  package. It does not run the benches. Like the other workflows it is
  started by hand (D-22); it has not been started yet.
- **docs:** a guide of the simulations in `simulation/README.md`: the state
  of the results block by block, what they reproduce, the four points
  that are decided, the places where they differ from the text of the
  specification, what stays for the bench, what the 122 failing figures
  are, the limits of the models, the traps of the simulator, and how to
  set up, run and extend the package.
- **docs:** the README shows the circuit simulations on the front page: a
  row in the status table, the results by block, what they say, and two
  graphs of simulation runs, each called a simulation.

### Changed

- **docs:** the instrument is now two boards: an ESP32-S3-DevKitC-1
  compatible development board plugged into a carrier board (D-14). The
  carrier has its own USB-C power connector (D-15), the slow monitors move to
  an external converter (D-16), and the pin map is rewritten for the headers
  of the development board.
- **docs:** the host protocol gains its exact CRC parameters, the type,
  command, status and event codes, the command arguments and the rules for
  which state accepts which command.
- **docs:** software engineering practices and quality gates (section 18,
  requirement R-17, D-17 to D-21).
- **docs:** the development board is the two-port clone with an N8R2 or
  N16R2 module, 25.40 mm between its header rows; the pin map gains PATH_EN
  on GPIO 35 and a spare line on GPIO 36 (D-23, D-29).
- **docs:** the specification follows the draft schematic: range logic in a
  programmable logic device, −4 V negative rail, dual Kelvin multiplexer,
  comparators on the amplifier output, 0.45 V of pre-regulator headroom,
  buffered ladder output, candidate parts for every block (D-24 to D-38).
- **hardware:** the socket footprint of the development board accepts
  25.40 mm and 22.86 mm between the rows.
- **repo:** the Hardware workflow also checks the board against the
  schematic.
- **repo:** the continuous integration workflows are started by hand
  instead of on every push and pull request (D-22).
- **docs:** the controller is a Raspberry Pi Pico 2 in place of the
  ESP32-S3 development board and of the programmable logic device: range
  logic and sampling clock become PIO programs, the pin map, the firmware
  plan and the phases are rewritten (D-39 to D-43). The firmware in the
  repository is not ported yet.
- **hardware:** reference designators follow the default annotation of
  KiCad (D-45), and the outline shrinks from 160 mm × 100 mm to
  130 mm × 100 mm (D-46).
- **repo:** the repository is renamed to `open-power-profiler`. Its former
  address, `esp32-s3-power-profiler`, redirects to the new one.
- **docs:** the README presents the project as the Open Power Profiler,
  with its connections and the state of each part; the firmware guide
  separates what is valid for the Raspberry Pi Pico 2 from the ESP-IDF
  build of the first plan.
- **host:** the description of the package, its keywords and the help of
  the `s3pp` command no longer name the ESP32-S3.
- **docs:** the specification follows draft A2 of the schematic: decisions
  D-47 to D-86, the open checks of section 16, the phases of section 13
  with three risk prototypes in phase 1, and the layout guidelines of
  section 10.
- **docs:** **BREAKING** seven requirements are re-baselined to the
  figures that the architecture delivers. None of the figures is measured;
  section 2 of the specification states the evidence of each and compares
  it with the PPK2.
  - R-04: RMS noise in the lowest range at most 5 nA in ampere mode from a
    quiet supply and at most 40 nA in source mode (D-59).
  - R-06: total path drop of 200 mV at 1 A in place of 150 mV; the shunt
    drop stays at 100 mV (D-64).
  - R-07: on a step from 1 µA to 500 mA the instrument adds at most 0.5 V
    of drop with 1 µF at the output and at most 0.25 V with 10 µF (D-65).
  - R-08: 1.0 A up to 2.0 V, falling in a straight line to 0.6 A at 5.0 V,
    in place of 1 A at every voltage (D-56).
  - R-09: the VIN terminal withstands −20 V to +20 V while the ampere
    switch is open (D-60).
  - R-10: logic inputs from 1.65 V to 5.5 V in place of 1.6 V to 5.5 V
    (D-79).
  - R-14: the budget is an input current for each source, 0.45 A, 1.4 A or
    1.7 A, and the 5 V rail may fall to 4.25 V (D-49).
- **docs:** **BREAKING** the calibration record of section 8 is tied to
  the module and the carrier: it gains the chip identifier of the RP2350
  and the serial number and revision of the carrier (D-82), a
  closed-switch zero (D-59) and nine or more set-points of the DAC in
  place of two (D-58).
- **hardware:** source meter: the pre-regulator tracks the output of the
  linear regulator (D-55), and the set-point DAC is referenced to half the
  reference, which caps the output at about 5.26 V (calculated, D-58).
- **hardware:** the over-current trip is at 1.15 A in the highest range in
  place of 1.2 A (D-74), and the output switch closes slowly and opens fast
  (D-71).
- **hardware:** the ladder clamp is two diode-connected MOSFETs (D-66), and
  VOUT is protected by one 15 V suppressor to ground (D-70).
- **hardware:** the shunts of ranges 0 and 1 are thin-film resistors, range
  2 uses a two-terminal part on a Kelvin land and range 3 a four-terminal
  part (D-68).
- **hardware:** the board grows from 130 mm × 100 mm to 150 mm × 100 mm
  with a shield can over the front end (D-85). Its parts are placed by a
  script and its tracks come from an autorouter, which leaves 28 of the
  984 connections open (D-86): an autorouted draft that needs a layout
  review before fabrication.
- **hardware:** the pictures and the PDF in `hardware/doc/` show draft A2,
  and the reference designators are numbered anew for it by the rule of
  D-45.
- **docs:** the table of open component checks follows section 16 of the
  specification for draft A2, and the documentation index gives the state
  of every document and the work that comes next.
- **docs:** section 16 of the specification lists the points of its
  sections 6 to 8 that are not decided yet: how the calibration record
  travels, reports without a place in the protocol, where three stored
  constants live, the evaluation step of two firmware rules and a fault
  during start-up.
- **repo:** the contributing guide and the issue and pull request forms
  follow the present state: the Pico 2, draft A2, checks started by hand.
- **hardware:** the layout of the carrier board of draft A2 is reviewed
  against section 10 of the specification. All 984 connections are routed,
  where the autorouter had left 28 open, and the design rules check
  reports no violation, no unconnected pad, no footprint error and no
  difference from the schematic. The schematic and the bill of materials
  are unchanged; 35 of the 425 footprints moved or turned. The review was
  done with scripts and checked by independent calculation. Nobody has
  reviewed the board in the KiCad editor yet, the seven points in which it
  deviates from the earlier text of section 10 are recorded as decisions
  (D-87 to D-93), and the board is not a design to fabricate.
  Every figure of it is calculated from the drawn copper; nothing is built
  and nothing is measured.
- **hardware:** the 1 A path is drawn as pours on the top layer, with the
  supply band doubled on the bottom layer: 19.5 squares of copper in
  source mode and 23.3 squares in ampere mode against the limit of 30
  squares, 10.4 mΩ and 12.3 mΩ at 40 °C (calculated from the drawn copper,
  copper only). The autorouted tracks had 397 and 217 squares.
- **hardware:** the measured node has a guard around it under the shield
  can, with the solder mask open over 84 % of the guard track, and 10 of
  the 11 sense and guarded nets run on the top layer without a via. The
  Kelvin pair of the 0.1 Ω shunt runs side by side over 83 % of its
  length; the pair of the 1 Ω shunt and the pair to the amplifier are
  equal in length within 0.9 mm and not side by side throughout, and the
  taps of the 1 kΩ and 33 Ω shunts run through a via each on the second
  inner layer. The calculated surface leakage into the measured
  node is 5.1 nA against a budget of 10 nA, with the assumptions of
  section 10.3 (10¹¹ Ω per square on a clean surface; solder mask,
  cleanliness and humidity not modeled).
- **hardware:** the switch nodes and the output copper of the converters
  are pours, the 5 V rail is a pour on the second inner layer, and the
  reference leaves its output pin as a star of ten branches. The capacitor
  loops of the pre-regulator, the boost converter and the charge pump are
  longer than section 10.5 asks and stay open: their capacitors have to be
  placed again.
- **hardware:** ground fills on the second inner layer and on the bottom
  layer, stitched to the ground plane with 41 added vias; the ground plane
  stays one piece with no track on its layer. Through-hole ground pads
  have thermal reliefs, and the pads of the 1 A path are joined solid.
- **hardware:** the rule file of the board is rewritten and stricter. The
  exemption of the larger spacings near pins applies on the top layer
  only; the 0.5 mm of the measured node apply on the bottom layer too;
  copper fills keep 1.0 mm from the measured node on the outer layers; the
  pours of the measured node keep 1.0 mm from ground and rail copper, pads
  included; the VIN input keeps 1.0 mm on the outer layers and 0.5 mm on
  the inner layers; the guard may run 0.2 mm beside the measured node.
  These rules are recorded as decision D-87.
- **hardware:** the pictures of the board in `hardware/doc/images/` are
  plotted again from the reviewed board file. The views of the assembled
  board are renderings.
- **repo:** the Hardware workflow also fails on an unconnected pad of the
  board. It could not while the autorouted board had open connections;
  the design rules check of the reviewed board reports none.
- **docs:** the specification gives the state of the board after the
  layout review in its head, in section 10.8 and in the open checks of
  section 16, and section 10.3 carries the calculated leakage figure in
  place of the earlier estimate of 1.3 nA to 2.9 nA.
- **docs:** the specification records the seven points in which the
  reviewed board deviates from its layout guidelines as decisions, and
  sections 10.3, 10.4, 10.6, 10.8, 13, 14 and 16 follow them. The project
  owner accepted each on the recommendation of the layout review. With
  them the decision log reached D-93.
  - D-87: the rule file of the board states every spacing, among them
    1.0 mm from VIN on the outer layers and 0.5 mm on the inner layers.
  - D-88: the high-side sense line of the 0.1 Ω shunt keeps two vias and
    1.9 mm on the second inner layer.
  - D-89: the Kelvin pairs are routed as on draft A2: equal in length
    within 1 mm, and side by side only where the pins allow.
  - D-90: the guard is one piece of copper, open on the top layer at the
    three exits of the measured node and joined on the other layers.
  - D-91: the supply, address and enable pins of the multiplexer and their
    parts stand inside the guard, with no ground pour inside it.
  - D-92: the 1 A path is judged by its resistance, 30 squares or less in
    either mode, and two of its pieces run on the bottom layer.
  - D-93: the island of output copper under the linear regulator U18 is
    291 mm² on the bottom layer, joined by 22 vias to 102 mm² on the top
    layer. The temperature rise of U18 at full dissipation is an open
    check of section 16, to be read on the first board.
- **hardware:** the board carries the name of the project. The silkscreen
  and the title blocks of the board and of the schematic read "Open Power
  Profiler - Carrier Board". The schematic PDF and the picture of its root
  page are exported again; the other 14 pages are unchanged.
- **docs:** the README, the guides, the indexes of the checks and of the
  reports and the contributing guide describe the board after the layout
  review: what is drawn, which figures are calculated, what is decided,
  what is open and what comes next. The tools guide and the contributing
  guide name the board figures and their checks.
- **docs:** the specification records where the circuit simulations live
  and how they are made, as decision D-94 of the project owner: a package
  of their own in `simulation/`, circuits built from a snapshot of the
  netlist, models written for the project. Its head, the repository
  structure of section 12 and the practices of section 18 follow, and
  section 16 gains a list at its end: the fourteen places where the
  simulation and the text differ. In those places no requirement, figure,
  rule or earlier decision changes: the text stands until the owner
  decides.
- **hardware:** four decisions follow the circuit simulations, taken by
  the project owner on 2026-10-10 on their recommendation. The three
  capacitors C32 to C34 at the comparator inputs of the rail monitor are
  10 nF, not 1 nF (D-95, which changes the value of D-54). A position for
  a capacitor from the non-inverting input of the buffer U28 of the
  driver rail to ground is added; its value is chosen on the bench, and
  the position may stay empty (D-96). The position U9 at the enable pin
  of the boost converter stays without a part and is no longer meant for
  the 803 type with its time-out of 0.24 s (D-97, which changes D-84).
  The damper R14 with C5 on the input from the controller module is
  fitted (D-98, which changes D-84). None of this is drawn yet: the
  schematic, the board, the bill of materials and the netlist snapshot of
  the simulations hold the earlier state, and drawing D-95, D-96 and D-98
  is the next step of the hardware.
- **docs:** the specification records decisions D-95 to D-98 and follows
  them in its head and in sections 3, 4.1, 4.5, 4.7, 10.8, 11, 13, 14, 16
  and 17. The four points leave the list of open points at the end of
  section 16; what the decisions leave to check stays in its lists, and
  drawing them is the first item before the board is ordered. With them
  the decision log reached D-98.
- **docs:** the README, the hardware guide, the picture guide, the
  documentation index, the index of the checks and the pages on tools,
  firmware, host software, calibration and test reports describe the
  project after the simulations of 2026-10-10: what was simulated and
  with which models, what is reproduced, where the simulation and the
  specification differ, and what only a bench can settle. The README,
  the hardware guide, the picture guide, the documentation index, the
  index of the checks, the firmware guide and the page on test reports
  also carry the four decisions that followed and what is still to be
  drawn. The next steps begin with drawing decisions D-95, D-96 and
  D-98; the fourteen places and the order of proof-of-concept boards are
  the open decisions of the owner; filing the simulations is no longer a
  step.
- **repo:** the contributing guide and the issue and pull request forms
  name the simulation area: the commit scope and changelog area
  `simulation`, the four checks of the package, what a change of the
  schematic, of a model or of a bench has to carry, and the rule that a
  figure that fails in a simulation is kept.

### Removed

- **hardware:** the symbol and the socket footprint of the ESP32-S3
  development board, the programmable logic device and the buffer between
  the two boards.
- **hardware:** the resettable fuse and the OR-ing diode of the power
  input, replaced by the input stage of D-47.
- **hardware:** the reverse clamp diode of the VIN terminal (D-60), the
  anti-parallel diode pair across the shunt ladder (D-66) and the diode
  clamp of VOUT to a 5.6 V node (D-70).
- **hardware:** the picture `board-open-connections.png` and, in the
  hardware guide, the list and the map of the 28 open connections: no
  connection is open after the layout review.
- **hardware:** the empty folder `hardware/simulation/` and, in the
  hardware guide, the list of the simulations that had to be filed: the
  simulations are in `simulation/`, made again from the final netlist
  (D-94).

[Unreleased]: https://github.com/Guiimartinho/open-power-profiler/commits/main

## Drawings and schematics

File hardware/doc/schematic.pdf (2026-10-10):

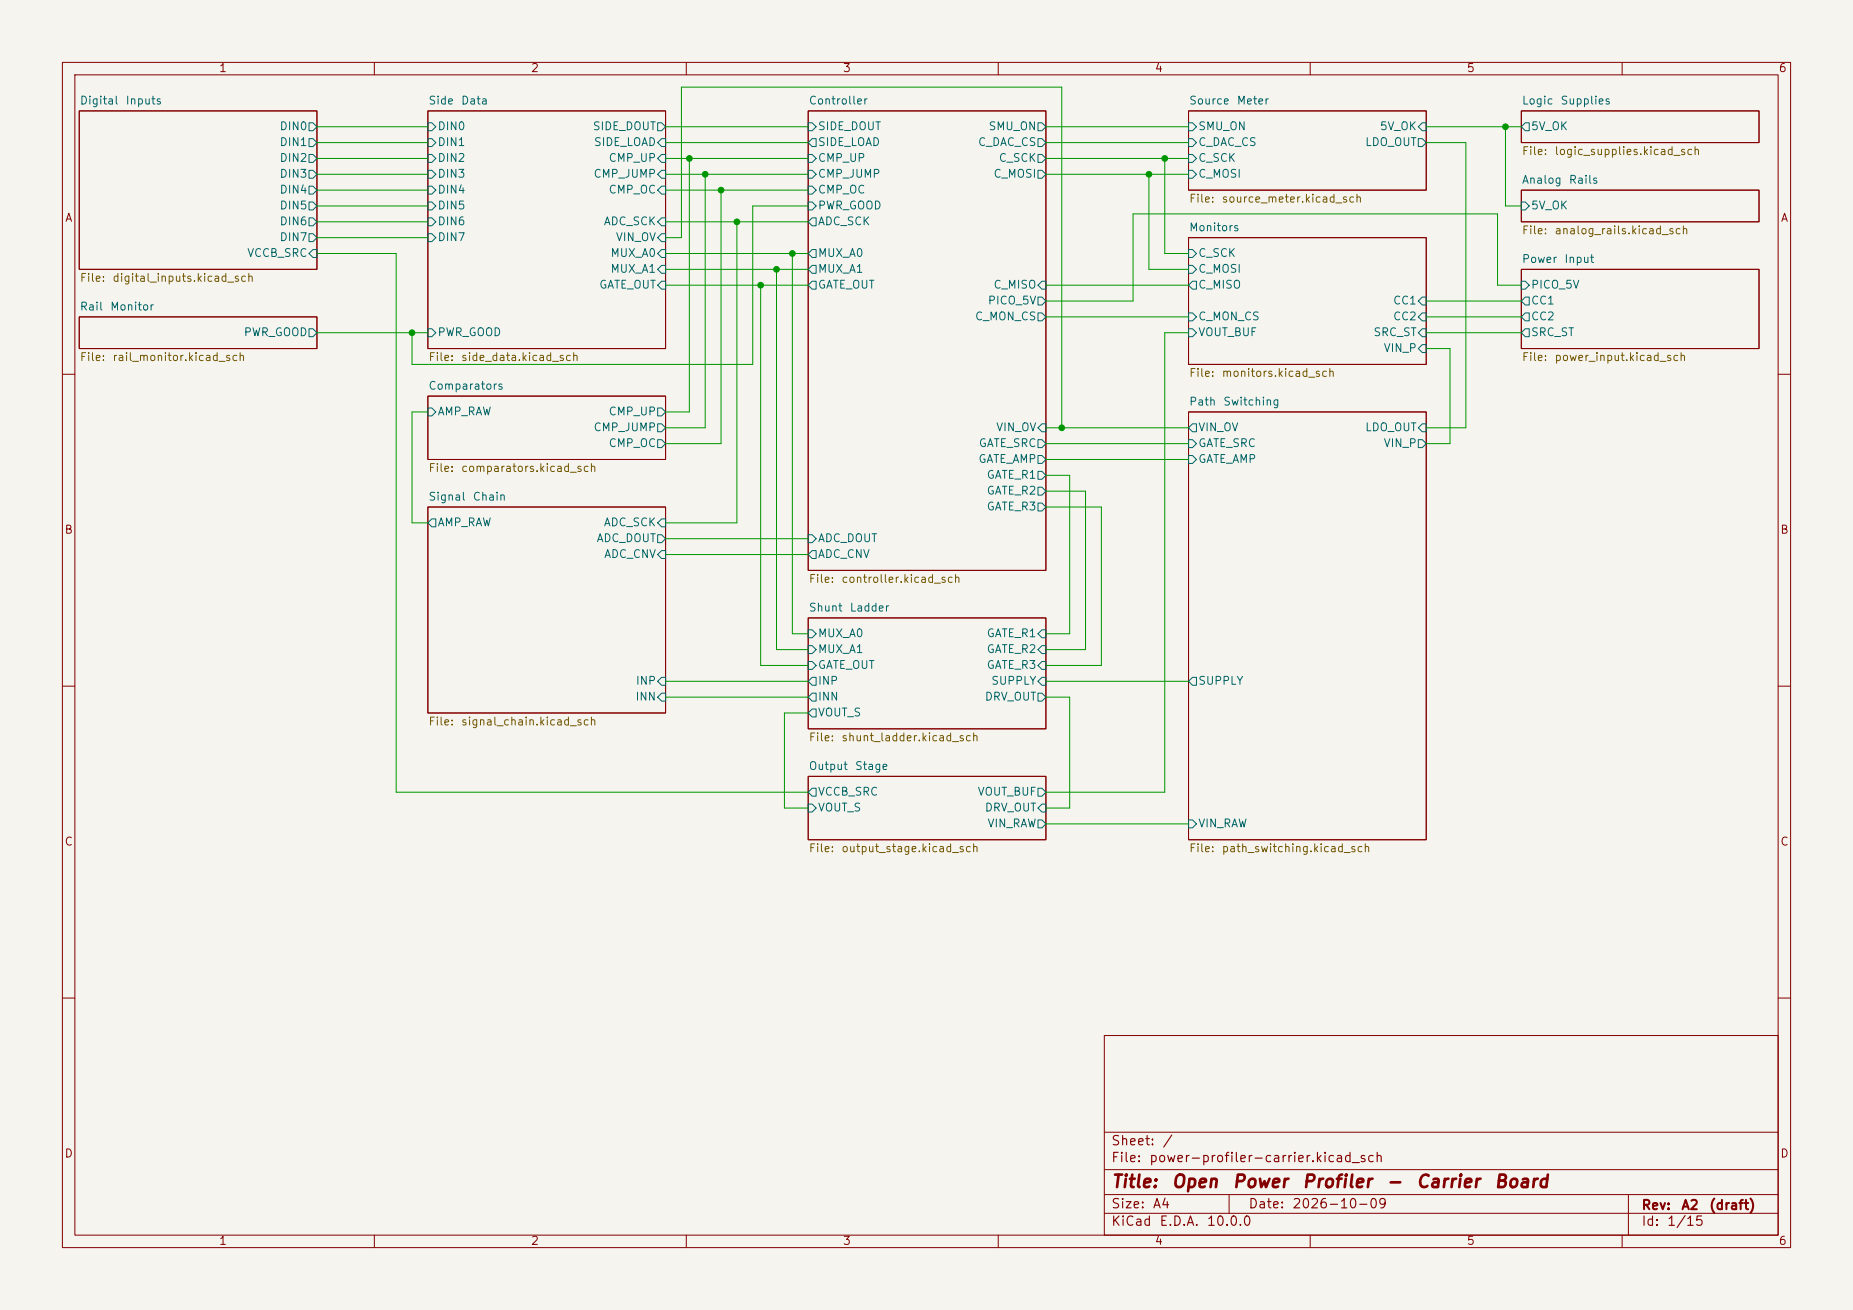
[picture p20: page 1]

SUPPLY DRV_OUT Shunt Ladder File: shunt_ladder.kicad_sch

Sheet: /
D Date: 2026-10-09 KiCad E.D.A. 10.0.0
File: power-profiler-carrier.kicad_sch
Title: Open Power Profiler - Carrier Board

Size: A4 | Rev: A2 (draft)

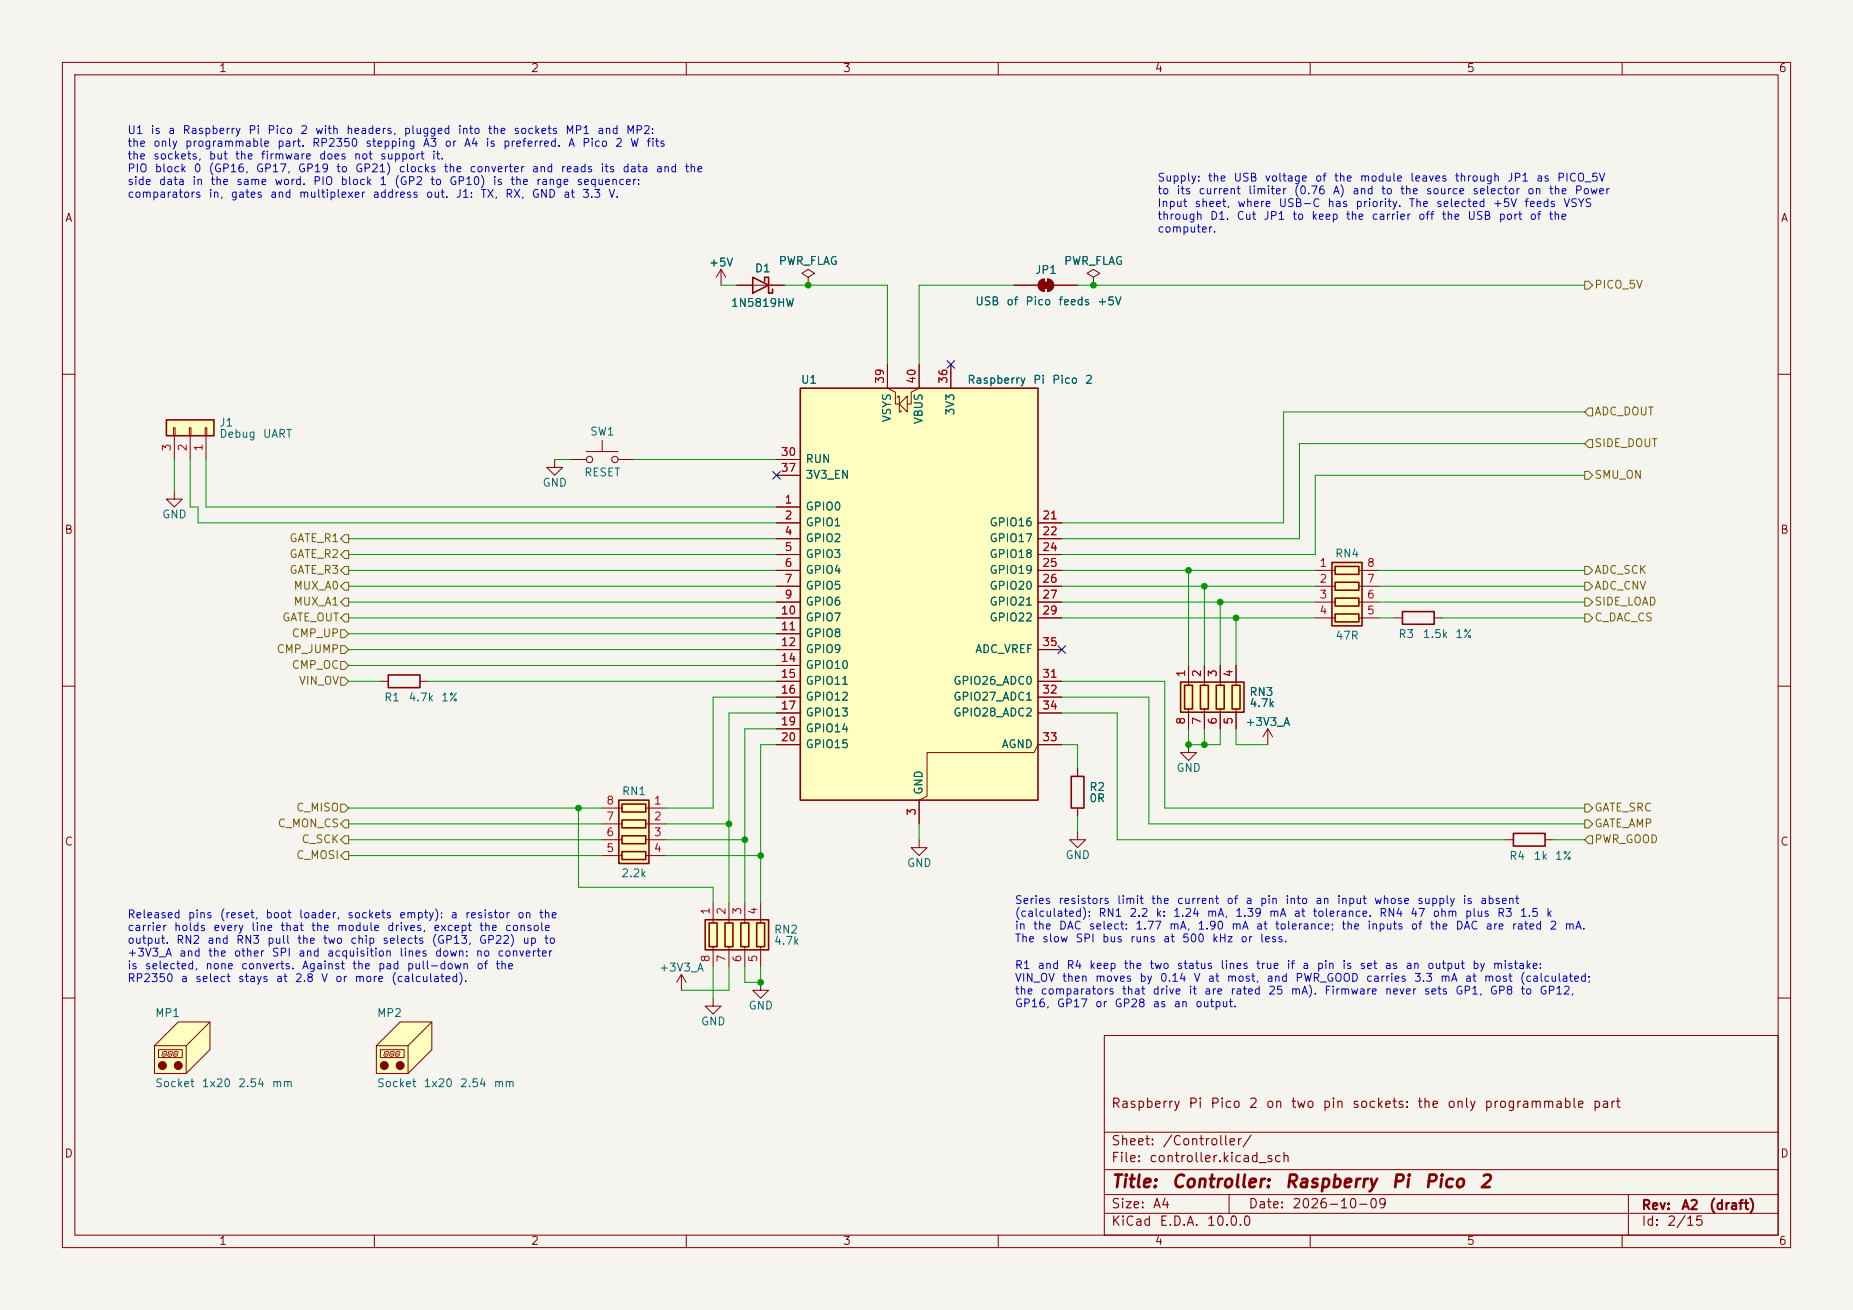
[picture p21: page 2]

ADC_CNV U1 is a Raspberry Pi Pico 2 with headers, plugged into the sockets MP1 and MP2: the only programmable part. RP2350 stepping A3 or A4 is preferred. A Pico 2 W fits

the sockets, but the firmware does not support it. PIO block 0 (GP16, GP17, GP19 to GP21) clocks the converter and reads its data and the

Supply: the USB voltage of the module leaves through JP1 as PICO_5V
to its current limiter (0.76 A) and to the source selector on the Power
Input sheet, where USB-C has priority. The selected +5V feeds VSYS
through D1. Cut JP1 to keep the carrier off the USB port of the
computer.

PWR_FLAG JP1 USB of Pico feeds +5V PWR_FLAG

Raspberry Pi Pico 2 on two pin sockets: the only programmable part R2

Released pins (reset, boot loader, sockets empty): a resistor on the
carrier holds every line that the module drives, except the console output. RN2 and RN3 pull the two chip selects (GP13, GP22) up to +3V3_A and the other SPI and acquisition lines down: no converter

in the DAC select: 1.77 mA, 1.90 mA at tolerance; the inputs of the DAC are rated 2 mA. The slow SPI bus runs at 500 kHz or less.

R1 and R4 keep the two status lines true if a pin is set as an output by mistake: VIN_OV then moves by 0.14 V at most, and PWR_GOOD carries 3.3 mA at most (calculated;

the comparators that drive it are rated 25 mA). Firmware never sets GP1, GP8 to GP12, GP16, GP17 or GP28 as an output.

Sheet: /Controller/
D Date: 2026-10-09 KiCad E.D.A. 10.0.0
File: controller.kicad_sch
Title: Controller: Raspberry Pi Pico 2

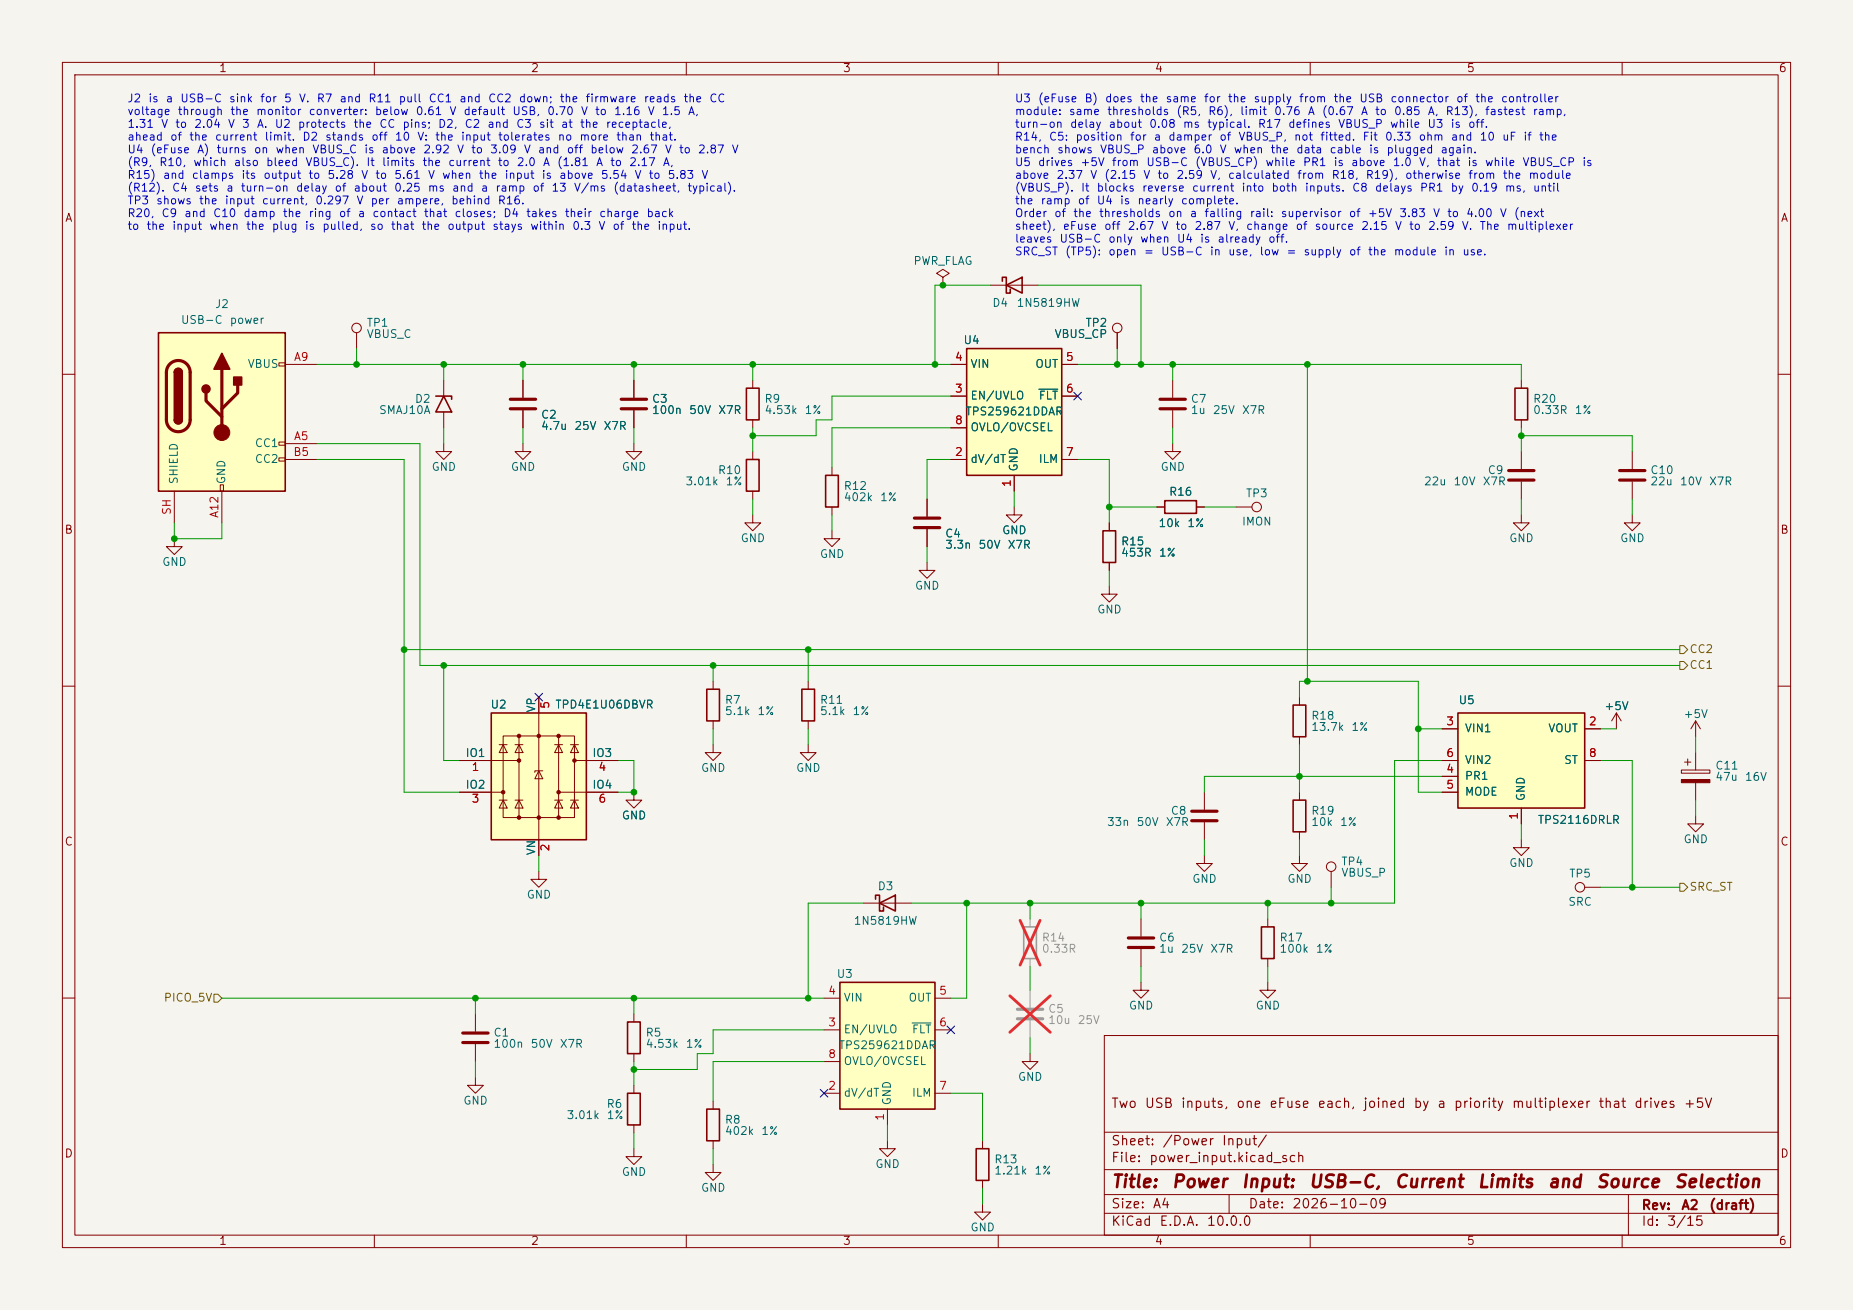
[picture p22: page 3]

leaves USB-C only when U4 is already off. SRC_ST (TP5): open = USB-C in use, low = supply of the module in use. J2 is a USB-C sink for 5 V. R7 and R11 pull CC1 and CC2 down; the firmware reads the CC
voltage through the monitor converter: below 0.61 V default USB, 0.70 V to 1.16 V 1.5 A, 1.31 V to 2.04 V 3 A. U2 protects the CC pins; D2, C2 and C3 sit at the receptacle,
J2 USB-C power GND

ahead of the current limit. D2 stands off 10 V: the input tolerates no more than that. U4 (eFuse A) turns on when VBUS_C is above 2.92 V to 3.09 V and off below 2.67 V to 2.87 V

(R9, R10, which also bleed VBUS_C). It limits the current to 2.0 A (1.81 A to 2.17 A, R15) and clamps its output to 5.28 V to 5.61 V when the input is above 5.54 V to 5.83 V

U5 drives +5V from USB-C (VBUS_CP) while PR1 is above 1.0 V, that is while VBUS_CP is above 2.37 V (2.15 V to 2.59 V, calculated from R18, R19), otherwise from the module

(R12). C4 sets a turn-on delay of about 0.25 ms and a ramp of 13 V/ms (datasheet, typical).
TP3 shows the input current, 0.297 V per ampere, behind R16. R20, C9 and C10 damp the ring of a contact that closes; D4 takes their charge back

(VBUS_P). It blocks reverse current into both inputs. C8 delays PR1 by 0.19 ms, until the ramp of U4 is nearly complete.

Order of the thresholds on a falling rail: supervisor of +5V 3.83 V to 4.00 V (next
sheet), eFuse off 2.67 V to 2.87 V, change of source 2.15 V to 2.59 V. The multiplexer

to the input when the plug is pulled, so that the output stays within 0.3 V of the input. C2

Two USB inputs, one eFuse each, joined by a priority multiplexer that drives +5V

Sheet: /Power Input/
D Date: 2026-10-09 KiCad E.D.A. 10.0.0
File: power_input.kicad_sch
Title: Power Input: USB-C, Current Limits and Source Selection

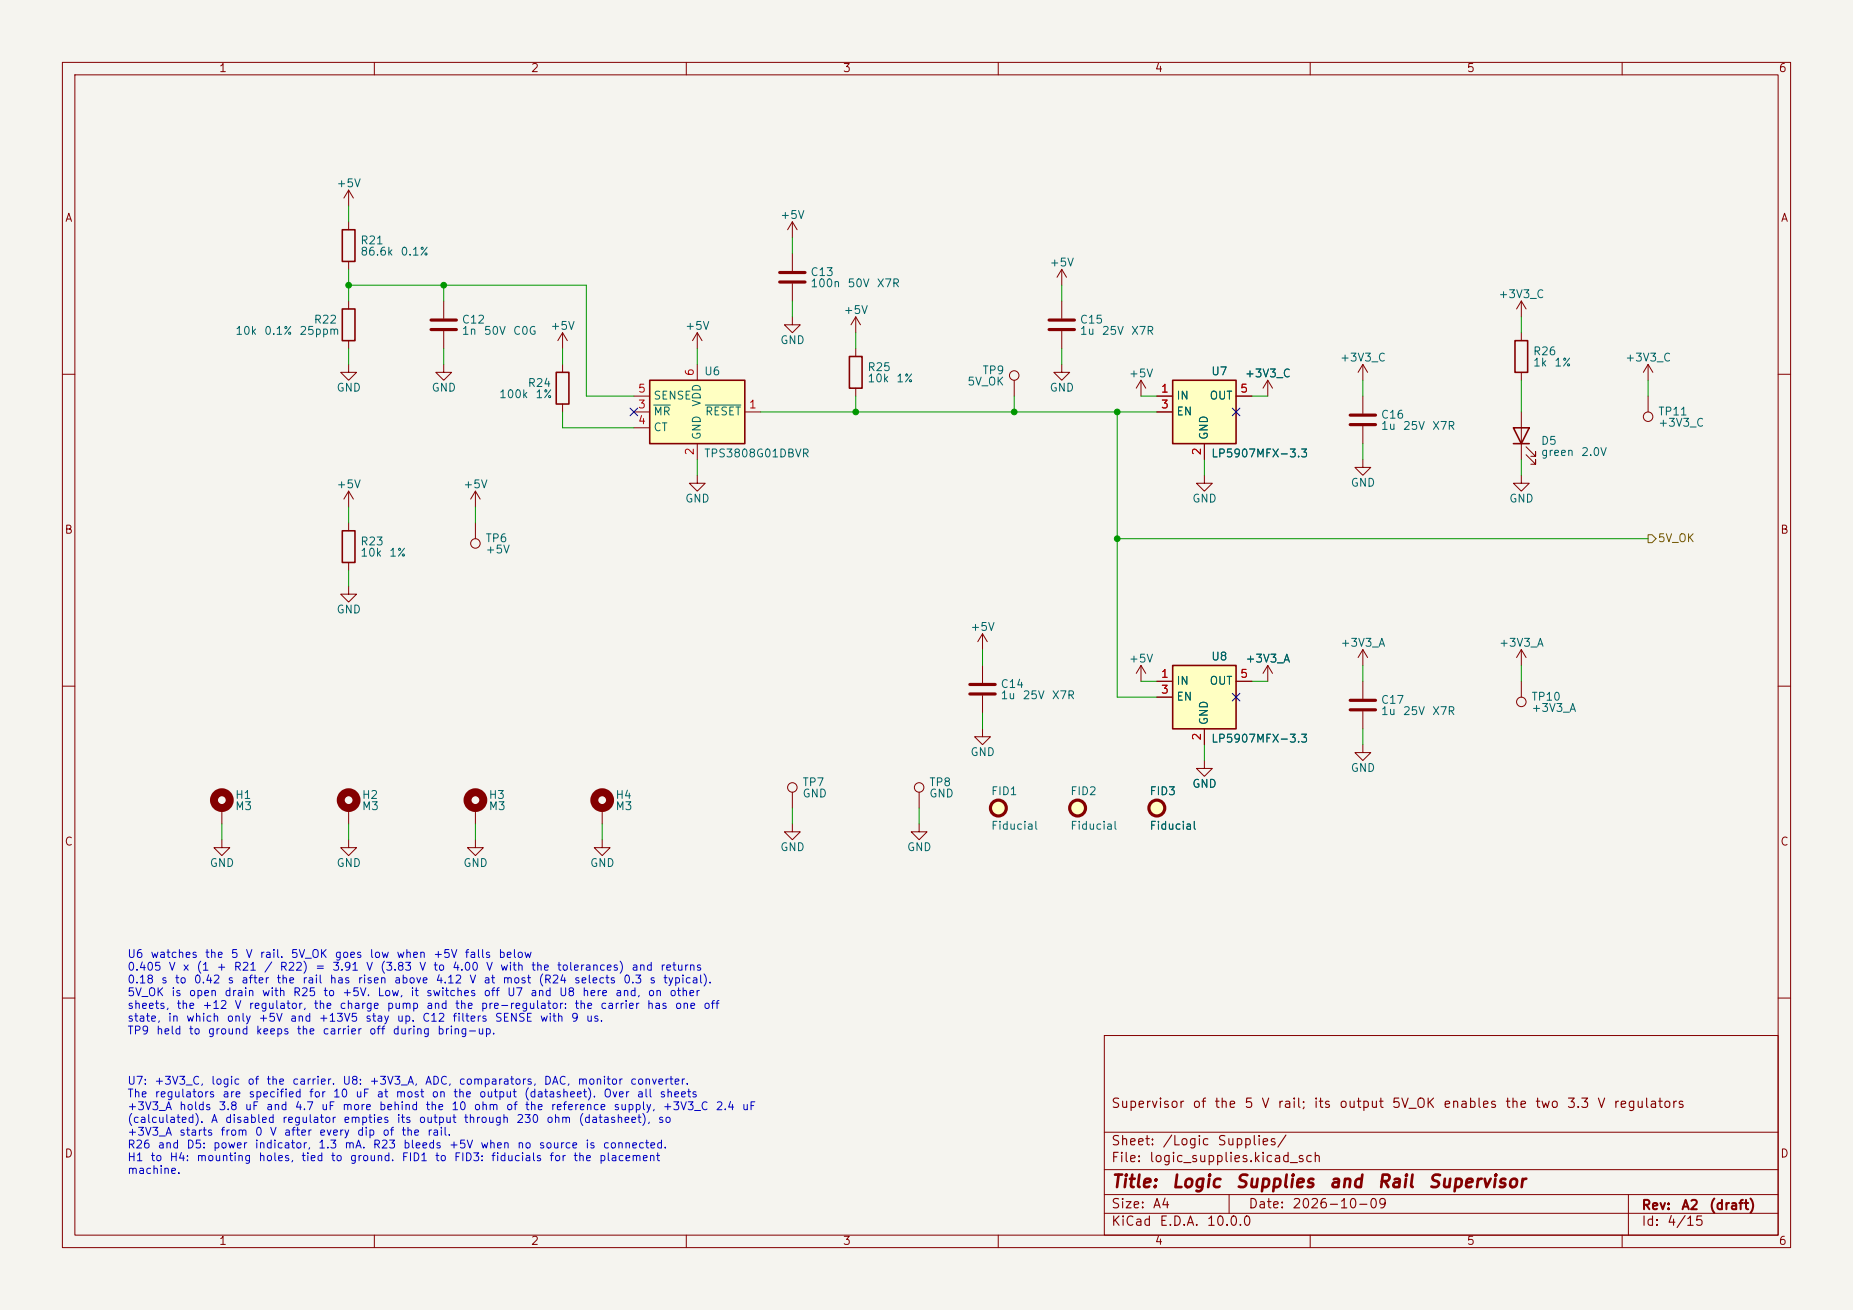
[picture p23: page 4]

5V_OK U7: +3V3_C, logic of the carrier. U8: +3V3_A, ADC, comparators, DAC, monitor converter. The regulators are specified for 10 uF at most on the output (datasheet). Over all sheets +3V3_A holds 3.8 uF and 4.7 uF more behind the 10 ohm of the reference supply, +3V3_C 2.4 uF

(calculated). A disabled regulator empties its output through 230 ohm (datasheet), so +3V3_A starts from 0 V after every dip of the rail. R26 and D5: power indicator, 1.3 mA. R23 bleeds +5V when no source is connected. H1 to H4: mounting holes, tied to ground. FID1 to FID3: fiducials for the placement machine. U6 watches the 5 V rail. 5V_OK goes low when +5V falls below
0.405 V x (1 + R21 / R22) = 3.91 V (3.83 V to 4.00 V with the tolerances) and returns 0.18 s to 0.42 s after the rail has risen above 4.12 V at most (R24 selects 0.3 s typical).
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

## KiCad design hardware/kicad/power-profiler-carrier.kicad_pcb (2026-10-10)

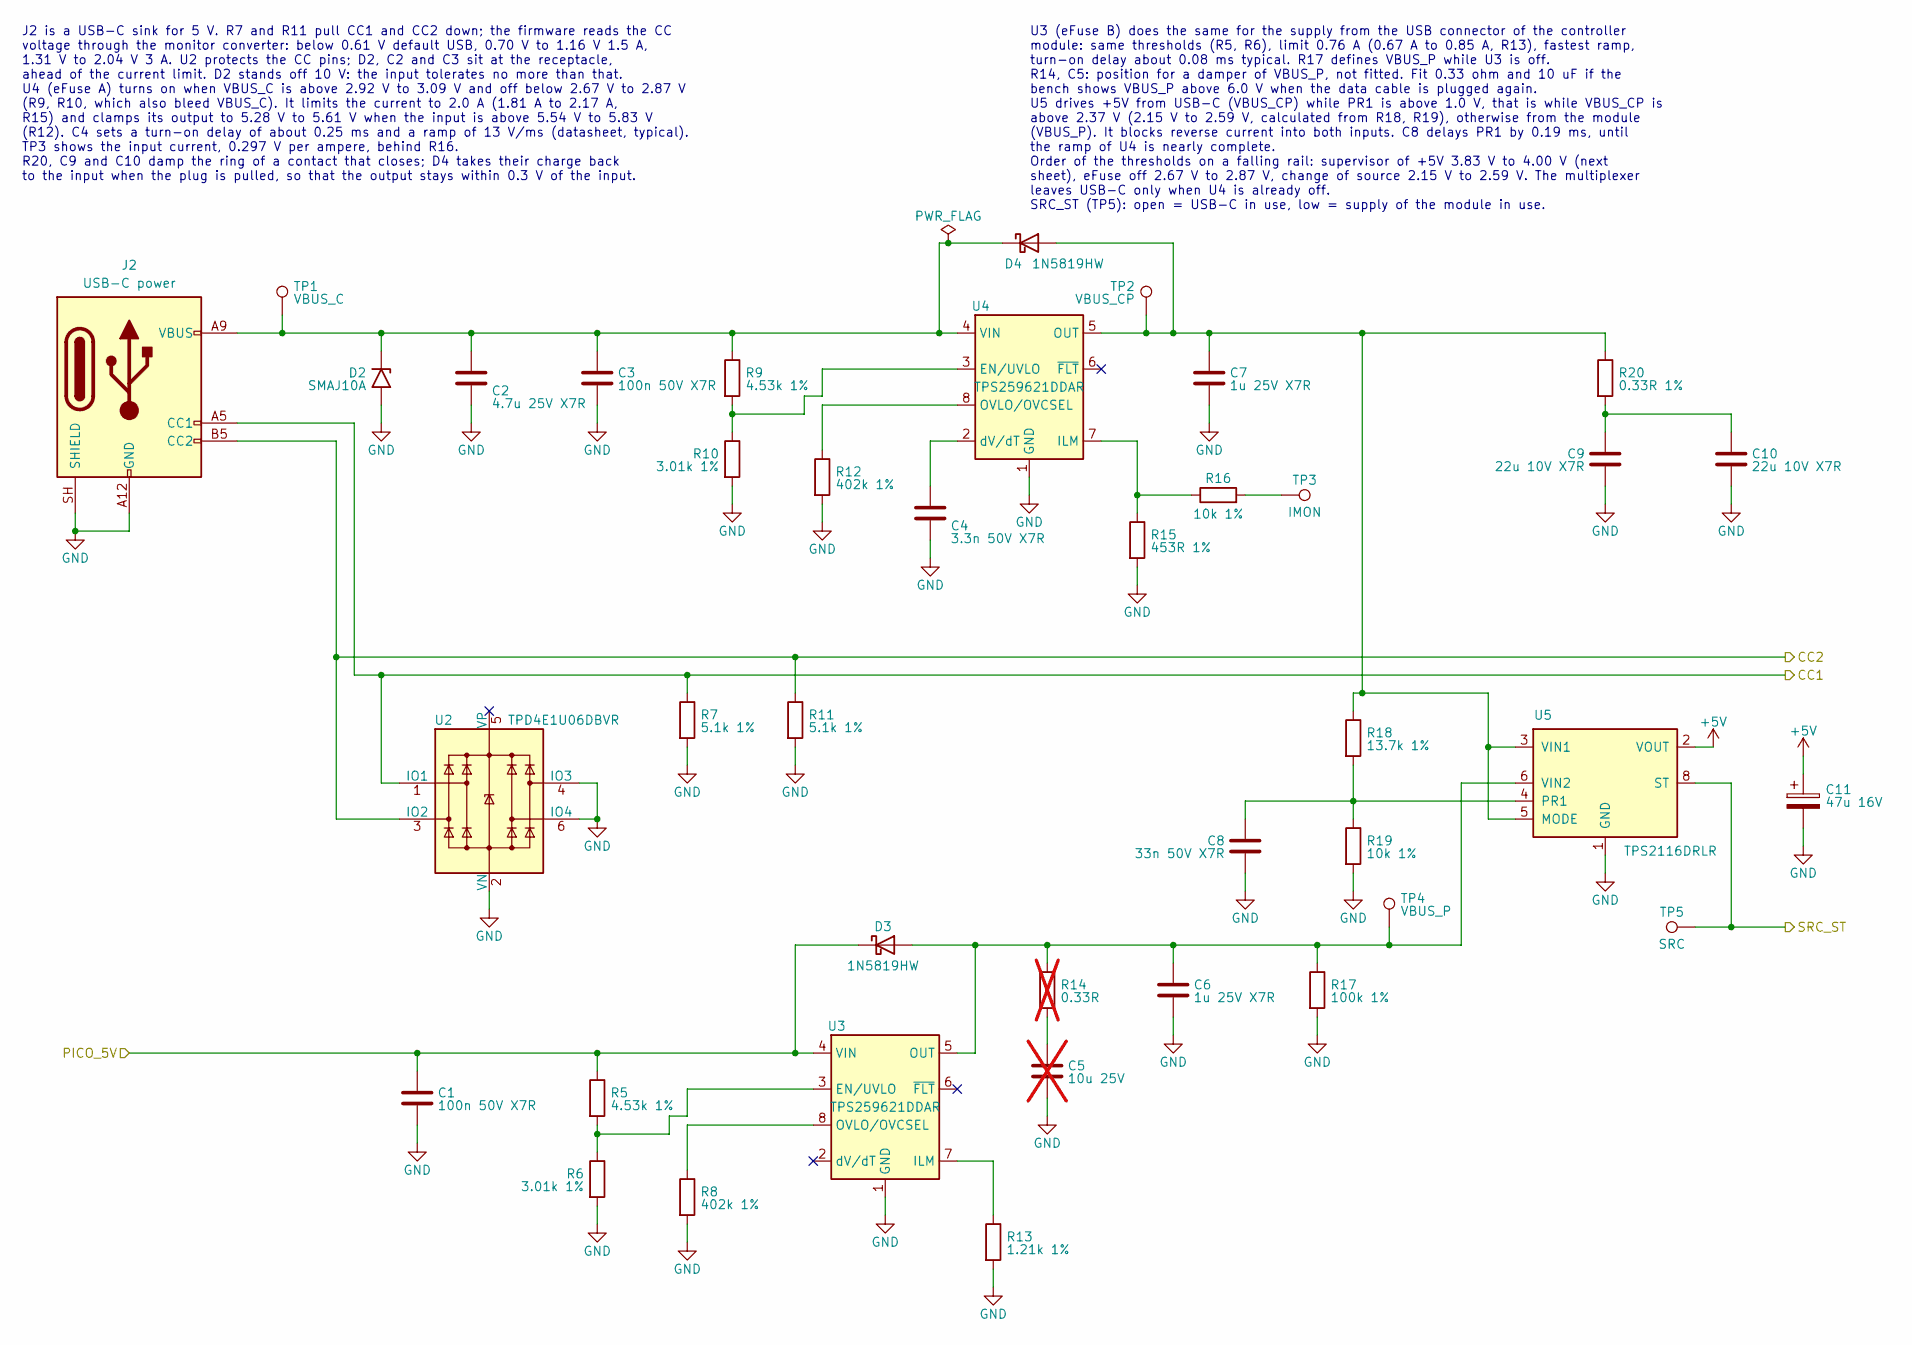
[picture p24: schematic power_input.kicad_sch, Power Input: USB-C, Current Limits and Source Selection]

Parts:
C1, C3: 100n 50V X7R; C_0603_1608Metric; MPN C0603C104K5RACTU
C2: 4.7u 25V X7R; C_0805_2012Metric; MPN CL21B475KAFNNNE
C4: 3.3n 50V X7R; C_0603_1608Metric; MPN CL10B332KB8NNNC
C5: 10u 25V; C_0805_2012Metric; not fitted
C6, C7: 1u 25V X7R; C_0603_1608Metric; MPN C0603C105K3RACTU
C8: 33n 50V X7R; C_0603_1608Metric; MPN CL10B333KB8NNNC
C9, C10: 22u 10V X7R; C_1206_3216Metric; MPN CL31B226KPHNNNE
C11: 47u 16V; CP_Elec_6.3x5.4; MPN 865060343004
D2: SMAJ10A; D_SMA; MPN SMAJ10A-E3/61
D3, D4: 1N5819HW; D_SOD-123; MPN 1N5819HW-7-F
J2: USB-C power; USB_C_Receptacle_GCT_USB4125-xx-x_6P_TopMnt_Horizontal; MPN USB4125-GF-A-0190
R5, R9: 4.53k 1%; R_0603_1608Metric; MPN CRCW06034K53FKEA
R6, R10: 3.01k 1%; R_0603_1608Metric; MPN CRCW06033K01FKEA
R7, R11: 5.1k 1%; R_0603_1608Metric; MPN CRCW06035K10FKEA
R8, R12: 402k 1%; R_0603_1608Metric; MPN CRCW0603402KFKEA
R13: 1.21k 1%; R_0603_1608Metric; MPN CRCW06031K21FKEA
R14: 0.33R; R_0805_2012Metric; not fitted
R15: 453R 1%; R_0603_1608Metric; MPN CRCW0603453RFKEA
R16, R19: 10k 1%; R_0603_1608Metric; MPN CRCW060310K0FKEA
R17: 100k 1%; R_0603_1608Metric; MPN CRCW0603100KFKEA
R18: 13.7k 1%; R_0603_1608Metric; MPN CRCW060313K7FKEA
R20: 0.33R 1%; R_0805_2012Metric; MPN ERJ-6RQFR33V
TP1: VBUS_C; TestPoint_Pad_D1.5mm
TP2: VBUS_CP; TestPoint_Pad_D1.5mm
TP3: IMON; TestPoint_Pad_D1.5mm
TP4: VBUS_P; TestPoint_Pad_D1.5mm
TP5: SRC; TestPoint_Pad_D1.5mm
U2: TPD4E1U06DBVR; SOT-23-6; MPN TPD4E1U06DBVR
U3, U4: TPS259621DDAR; TI_SO-PowerPAD-8_ThermalVias; MPN TPS259621DDAR
U5: TPS2116DRLR; SOT-583-8; MPN TPS2116DRLR

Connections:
+5V: C11.1, U5.2 (VOUT), U5.7 (VOUT); also elsewhere on the board
/Controller/PICO_5V: C1.1, D3.1 (K), R5.1, U3.4 (VIN); also elsewhere on the board
/Monitors/CC1: J2.A5 (CC1), R7.1, U2.1 (IO1); also elsewhere on the board
/Monitors/CC2: J2.B5 (CC2), R11.1, U2.3 (IO2); also elsewhere on the board
/Monitors/SRC_ST: TP5.1 (1_1), U5.8 (ST); also elsewhere on the board
unnamed: C5.1, R14.2
unnamed: C9.1, C10.1, R20.2
unnamed: C2.1, C3.1, D2.1 (A1), D4.1 (K), J2.A9 (VBUS), J2.B9 (VBUS), R9.1, TP1.1 (1_1), U4.4 (VIN)
unnamed: C6.1, D3.2 (A), R14.1, R17.1, TP4.1 (1_1), U3.5 (OUT), U5.6 (VIN2)
unnamed: C7.1, D4.2 (A), R18.1, R20.1, TP2.1 (1_1), U4.5 (OUT), U5.3 (VIN1), U5.5 (MODE)
unnamed: R16.2, TP3.1 (1_1)
unnamed: R5.2, R6.1, U3.3 (EN/UVLO)
unnamed: R13.1, U3.7 (ILM)
unnamed: R8.1, U3.8 (OVLO/OVCSEL)
unnamed: R9.2, R10.1, U4.3 (EN/UVLO)
unnamed: R15.1, R16.1, U4.7 (ILM)
unnamed: R12.1, U4.8 (OVLO/OVCSEL)
unnamed: C4.1, U4.2 (dV/dT)
unnamed: C8.1, R18.2, R19.1, U5.4 (PR1)

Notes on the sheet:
U3 (eFuse B) does the same for the supply from the USB connector of the controller module: same thresholds (R5, R6), limit 0.76 A (0.67 A to 0.85 A, R13), fastest ramp, turn-on delay about 0.08 ms typical. R17 defines VBUS_P while U3 is off. R14, C5: position for a damper of VBUS_P, not fitted. Fit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
J2 is a USB-C sink for 5 V. R7 and R11 pull CC1 and CC2 down; the firmware reads the CC voltage through the monitor converter: below 0.61 V default USB, 0.70 V to 1.16 V 1.5 A, 1.31 V to 2.04 V 3 A. U2 protects the CC pins; D2, C2 and C3 sit at the receptacle, ahead of the current limit. D2 stands 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

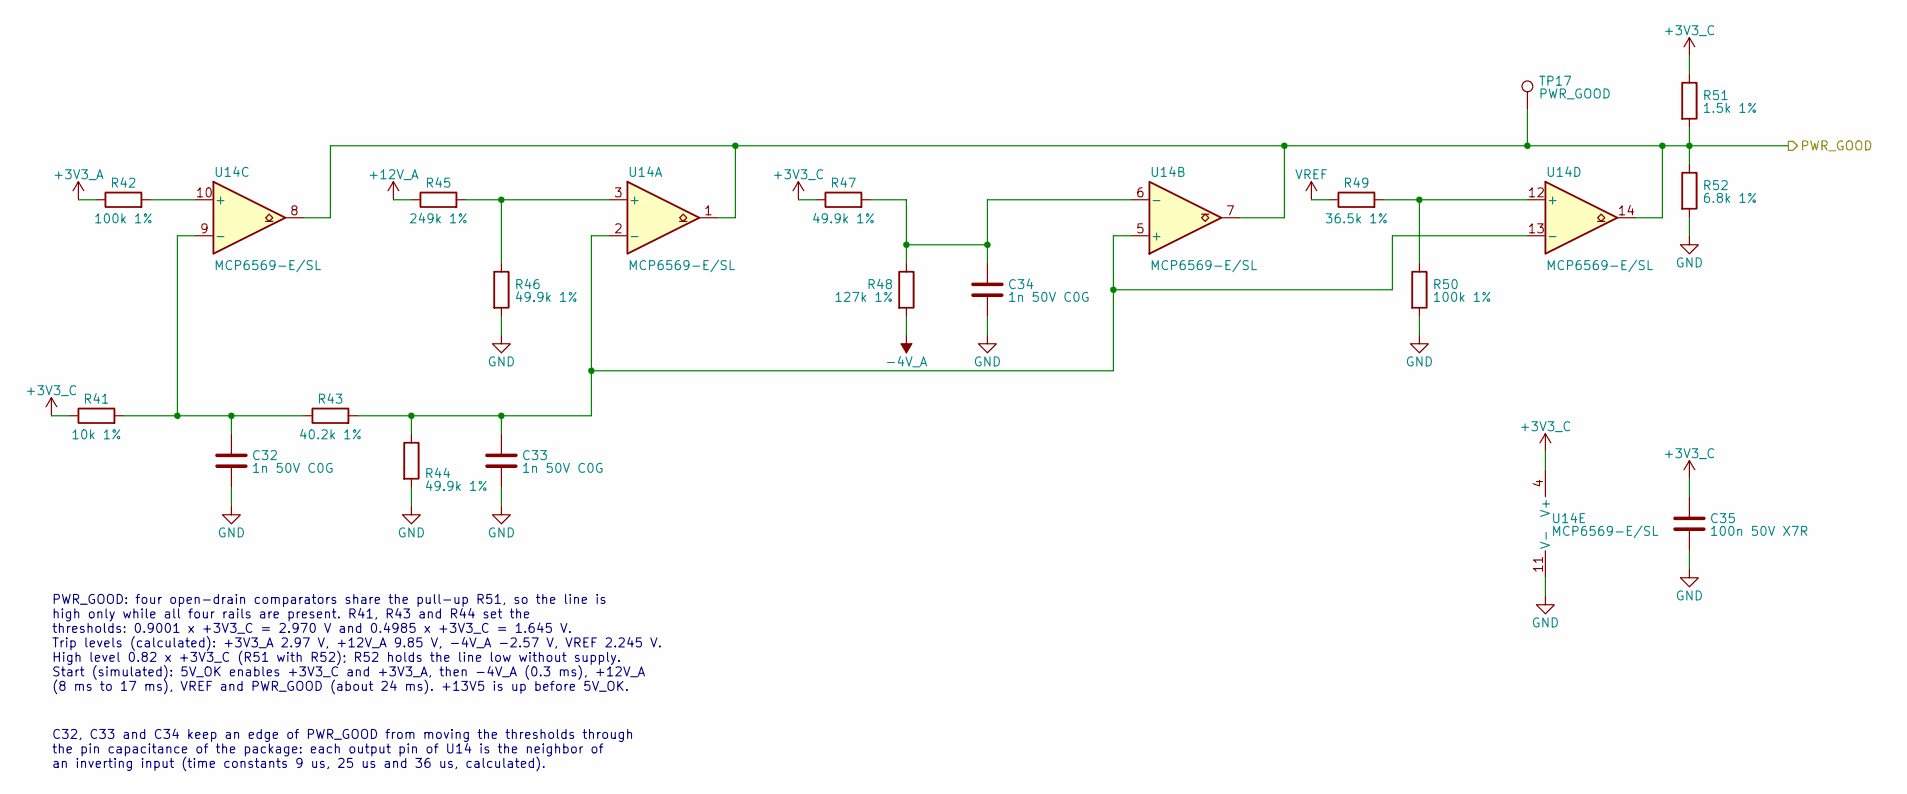
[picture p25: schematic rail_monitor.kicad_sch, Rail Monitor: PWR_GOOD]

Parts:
C32, C33, C34: 1n 50V C0G; C_0603_1608Metric; MPN C0603C102J5GACTU
C35: 100n 50V X7R; C_0603_1608Metric; MPN C0603C104K5RACTU
R41: 10k 1%; R_0603_1608Metric; MPN CRCW060310K0FKEA
R42, R50: 100k 1%; R_0603_1608Metric; MPN CRCW0603100KFKEA
R43: 40.2k 1%; R_0603_1608Metric; MPN CRCW060340K2FKEA
R44, R46, R47: 49.9k 1%; R_0603_1608Metric; MPN CRCW060349K9FKEA
R45: 249k 1%; R_0603_1608Metric; MPN CRCW0603249KFKEA
R48: 127k 1%; R_0603_1608Metric; MPN CRCW0603127KFKEA
R49: 36.5k 1%; R_0603_1608Metric; MPN CRCW060336K5FKEA
R51: 1.5k 1%; R_0603_1608Metric; MPN CRCW06031K50FKEA
R52: 6.8k 1%; R_0603_1608Metric; MPN CRCW06036K80FKEA
TP17: PWR_GOOD; TestPoint_Pad_D1.5mm
U14: MCP6569-E/SL; SOIC-14_3.9x8.7mm_P1.27mm; MPN MCP6569-E/SL

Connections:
+12V_A: R45.1; also elsewhere on the board
/Controller/PWR_GOOD: R51.2, R52.1, TP17.1 (1_1), U14.1, U14.7, U14.8, U14.14; also elsewhere on the board
unnamed: R45.2, R46.1, U14.3 (+)
unnamed: C33.1, R43.2, R44.1, U14.2 (-), U14.5 (+), U14.13 (-)
unnamed: C34.1, R47.2, R48.1, U14.6 (-)
unnamed: R42.2, U14.10 (+)
unnamed: C32.1, R41.2, R43.1, U14.9 (-)
unnamed: R49.2, R50.1, U14.12 (+)

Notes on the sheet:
PWR_GOOD: four open-drain comparators share the pull-up R51, so the line is high only while all four rails are present. R41, R43 and R44 set the thresholds: 0.9001 x +3V3_C = 2.970 V and 0.4985 x +3V3_C = 1.645 V. Trip levels (calculated): +3V3_A 2.97 V, +12V_A 9.85 V, -4V_A -2.57 V, VREF 2.245 V. 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
C32, C33 and C34 keep an edge of PWR_GOOD from moving the thresholds through the pin capacitance of the package: each output pin of U14 is the neighbor of an inverting input (time constants 9 us, 25 us and 36 us, calculated).

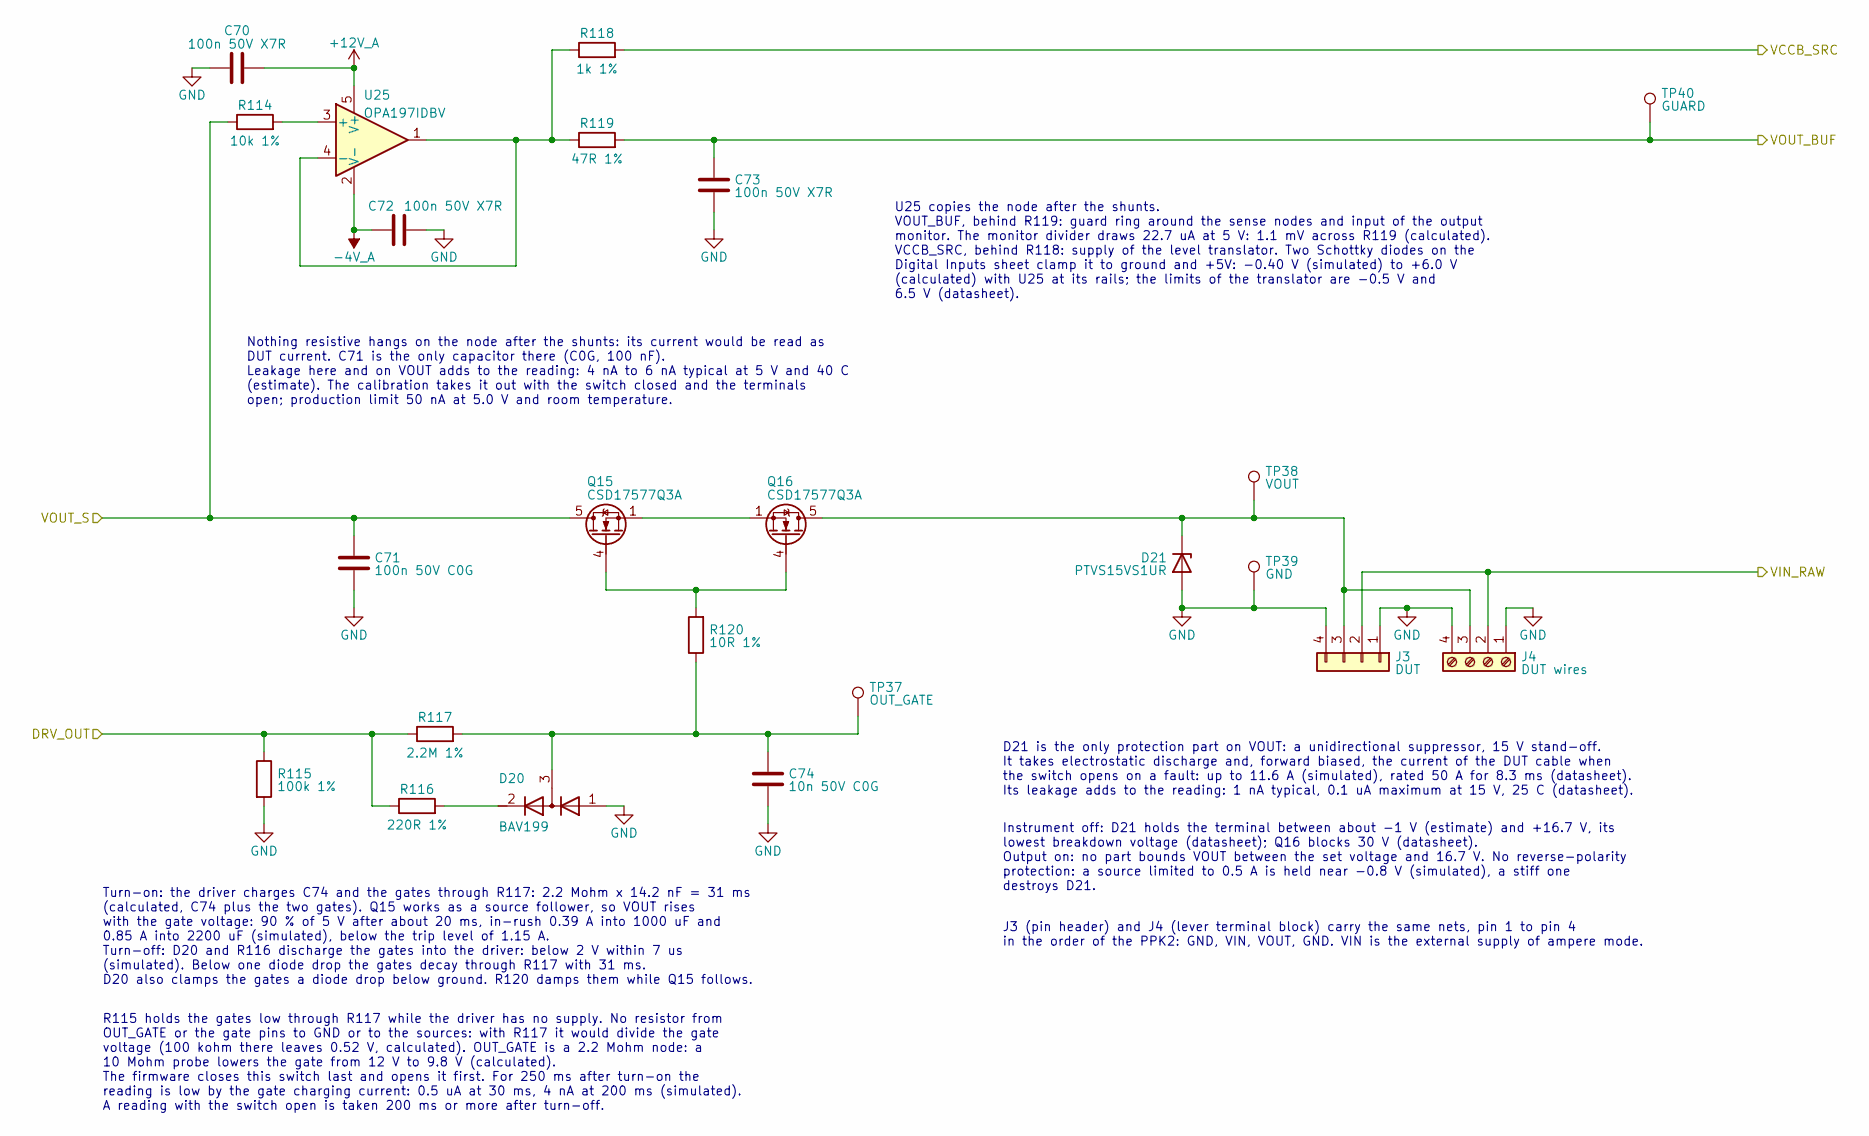
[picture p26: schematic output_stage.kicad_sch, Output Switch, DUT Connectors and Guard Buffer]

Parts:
C70, C72, C73: 100n 50V X7R; C_0603_1608Metric; MPN C0603C104K5RACTU
C71: 100n 50V C0G; C_1206_3216Metric; MPN C3216C0G1H104J160AA
C74: 10n 50V C0G; C_0603_1608Metric; MPN GRM1885C1H103JA01D
D20: BAV199; SOT-23; MPN BAV199-7-F
D21: PTVS15VS1UR; Nexperia_CFP3_SOD-123W; MPN PTVS15VS1UR,115
J3: DUT; PinHeader_1x04_P2.54mm_Vertical; MPN 61300411121
J4: DUT wires; TerminalBlock_WAGO_2601-1104_1x04_P3.50mm_Horizontal_Pad1.9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; MPN 2601-1104
Q15, Q16: CSD17577Q3A; VSON-8_3.3x3.3mm_P0.65mm_NexFET; MPN CSD17577Q3A
R114: 10k 1%; R_0603_1608Metric; MPN CRCW060310K0FKEA
R115: 100k 1%; R_0603_1608Metric; MPN CRCW0603100KFKEA
R116: 220R 1%; R_0603_1608Metric; MPN CRCW0603220RFKEA
R117: 2.2M 1%; R_0603_1608Metric; MPN CRCW06032M20FKEA
R118: 1k 1%; R_0603_1608Metric; MPN CRCW06031K00FKEA
R119: 47R 1%; R_0603_1608Metric; MPN CRCW060347R0FKEA
R120: 10R 1%; R_0603_1608Metric; MPN CRCW060310R0FKEA
TP37: OUT_GATE; TestPoint_Pad_D1.5mm
TP38: VOUT; TestPoint_Pad_D1.5mm
TP39: GND; TestPoint_Pad_D1.5mm
TP40: GUARD; TestPoint_Pad_D1.5mm
U25: OPA197IDBV; SOT-23-5; MPN OPA197IDBVR

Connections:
+12V_A: C70.1, U25.5 (V+); also elsewhere on the board
/Digital Inputs/VCCB_SRC: R118.2; also elsewhere on the board
/Monitors/VOUT_BUF: C73.1, R119.2, TP40.1 (1_1); also elsewhere on the board
/Output Stage/DRV_OUT: R115.1, R116.1, R117.1; also elsewhere on the board
/Output Stage/VIN_RAW: J3.2, J4.2; also elsewhere on the board
/Output Stage/VOUT_S: C71.1, Q15.5 (D), R114.1; also elsewhere on the board
unnamed: D20.2 (K), R116.2
unnamed: C74.1, D20.3 (common), R117.2, R120.1, TP37.1 (1_1)
unnamed: D21.1 (K), J3.3, J4.3, Q16.5 (D), TP38.1 (1_1)
unnamed: Q15.4 (G), Q16.4 (G), R120.2
unnamed: Q15.1 (S), Q15.2 (S), Q15.3 (S), Q16.1 (S), Q16.2 (S), Q16.3 (S)
unnamed: R114.2, U25.3 (+)
unnamed: R118.1, R119.1, U25.1, U25.4 (-)

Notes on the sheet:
D21 is the only protection part on VOUT: a unidirectional suppressor, 15 V stand-off. It takes electrostatic discharge and, forward biased, the current of the DUT cable when the switch opens on a fault: up to 11.6 A (simulated), rated 50 A for 8.3 ms (datasheet). Its leakage adds to the reading: 1 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
Nothing resistive hangs on the node after the shunts: its current would be read as DUT current. C71 is the only capacitor there (C0G, 100 nF). Leakage here and on VOUT adds to the reading: 4 nA to 6 nA typical at 5 V and 40 C (estimate). The calibration takes it out with the switch closed and the t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
U25 copies the node after the shunts. VOUT_BUF, behind R119: guard ring around the sense nodes and input of the output monitor. The monitor divider draws 22.7 uA at 5 V: 1.1 mV across R119 (calculated). VCCB_SRC, behind R118: supply of the level translator. Two Schottky diodes on the Digital Inputs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
Turn-on: the driver charges C74 and the gates through R117: 2.2 Mohm x 14.2 nF = 31 ms (calculated, C74 plus the two gates). Q15 works as a source follower, so VOUT rises with the gate voltage: 90 % of 5 V after about 20 ms, in-rush 0.39 A into 1000 uF and 0.85 A into 2200 uF (simulated), below the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
J3 (pin header) and J4 (lever terminal block) carry the same nets, pin 1 to pin 4 in the order of the PPK2: GND, VIN, VOUT, GND. VIN is the external supply of ampere mode.
R115 holds the gates low through R117 while the driver has no supply. No resistor from OUT_GATE or the gate pins to GND or to the sources: with R117 it would divide the gate voltage (100 kohm there leaves 0.52 V, calculated). OUT_GATE is a 2.2 Mohm node: a 10 Mohm probe lowers the gate from 12 V to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
Instrument off: D21 holds the terminal between about -1 V (estimate) and +16.7 V, its lowest breakdown voltage (datasheet); Q16 blocks 30 V (datasheet). Output on: no part bounds VOUT between the set voltage and 16.7 V. No reverse-polarity protection: a source limited to 0.5 A is held near -0.8 V (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

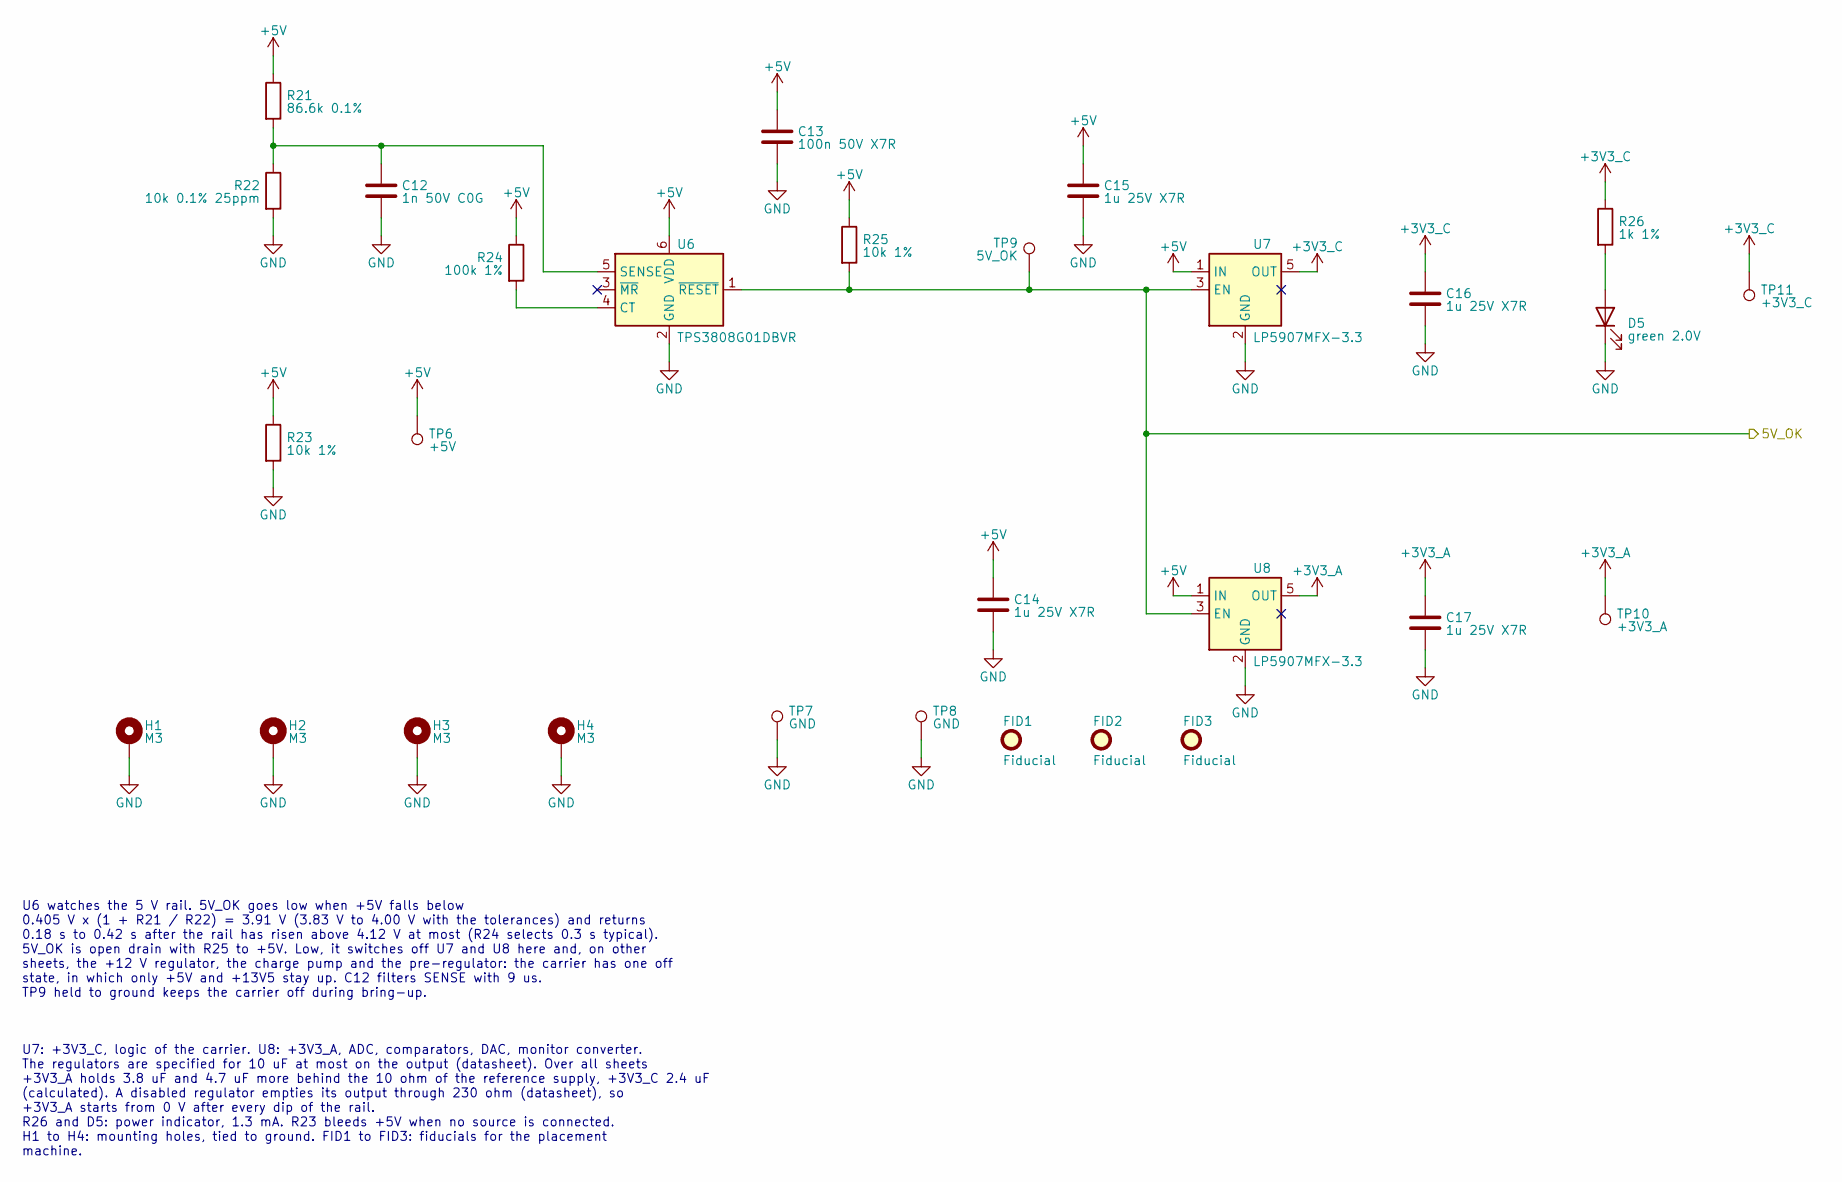
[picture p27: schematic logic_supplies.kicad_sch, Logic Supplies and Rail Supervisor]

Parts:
C12: 1n 50V C0G; C_0603_1608Metric; MPN C0603C102J5GACTU
C13: 100n 50V X7R; C_0603_1608Metric; MPN C0603C104K5RACTU
C14, C15, C16, C17: 1u 25V X7R; C_0603_1608Metric; MPN C0603C105K3RACTU
D5: green 2.0V; LED_0603_1608Metric; MPN 150060VS75000
FID1, FID2, FID3: Fiducial; Fiducial_1mm_Mask2mm
H1, H2, H3, H4: M3; MountingHole_3.2mm_M3_Pad
R21: 86.6k 0.1%; R_0603_1608Metric; MPN TNPW060386K6BEEA
R22: 10k 0.1% 25ppm; R_0603_1608Metric; MPN TNPW060310K0BEEA
R23, R25: 10k 1%; R_0603_1608Metric; MPN CRCW060310K0FKEA
R24: 100k 1%; R_0603_1608Metric; MPN CRCW0603100KFKEA
R26: 1k 1%; R_0603_1608Metric; MPN CRCW06031K00FKEA
TP6: +5V; TestPoint_Pad_D1.5mm
TP7, TP8: GND; TestPoint_Pad_D1.5mm
TP9: 5V_OK; TestPoint_Pad_D1.5mm
TP10: +3V3_A; TestPoint_Pad_D1.5mm
TP11: +3V3_C; TestPoint_Pad_D1.5mm
U6: TPS3808G01DBVR; SOT-23-6; MPN TPS3808G01DBVR
U7, U8: LP5907MFX-3.3; SOT-23-5; MPN LP5907MFX-3.3/NOPB

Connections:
+5V: C13.1, C14.1, C15.1, R21.1, R23.1, R24.1, R25.1, TP6.1 (1_1), U6.6 (VDD), U7.1 (IN), U8.1 (IN); also elsewhere on the board
/Analog Rails/5V_OK: R25.2, TP9.1 (1_1), U6.1 (~RESET), U7.3 (EN), U8.3 (EN); also elsewhere on the board
unnamed: D5.2 (A), R26.2
unnamed: R24.2, U6.4 (CT)
unnamed: C12.1, R21.2, R22.1, U6.5 (SENSE)

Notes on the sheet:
U7: +3V3_C, logic of the carrier. U8: +3V3_A, ADC, comparators, DAC, monitor converter. The regulators are specified for 10 uF at most on the output (datasheet). Over all sheets +3V3_A holds 3.8 uF and 4.7 uF more behind the 10 ohm of the reference supply, +3V3_C 2.4 uF (calculated). A disabled reg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
U6 watches the 5 V rail. 5V_OK goes low when +5V falls below 0.405 V x (1 + R21 / R22) = 3.91 V (3.83 V to 4.00 V with the tolerances) and returns 0.18 s to 0.42 s after the rail has risen above 4.12 V at most (R24 selects 0.3 s typical). 5V_OK is open drain with R25 to +5V. Low, it switches off U7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

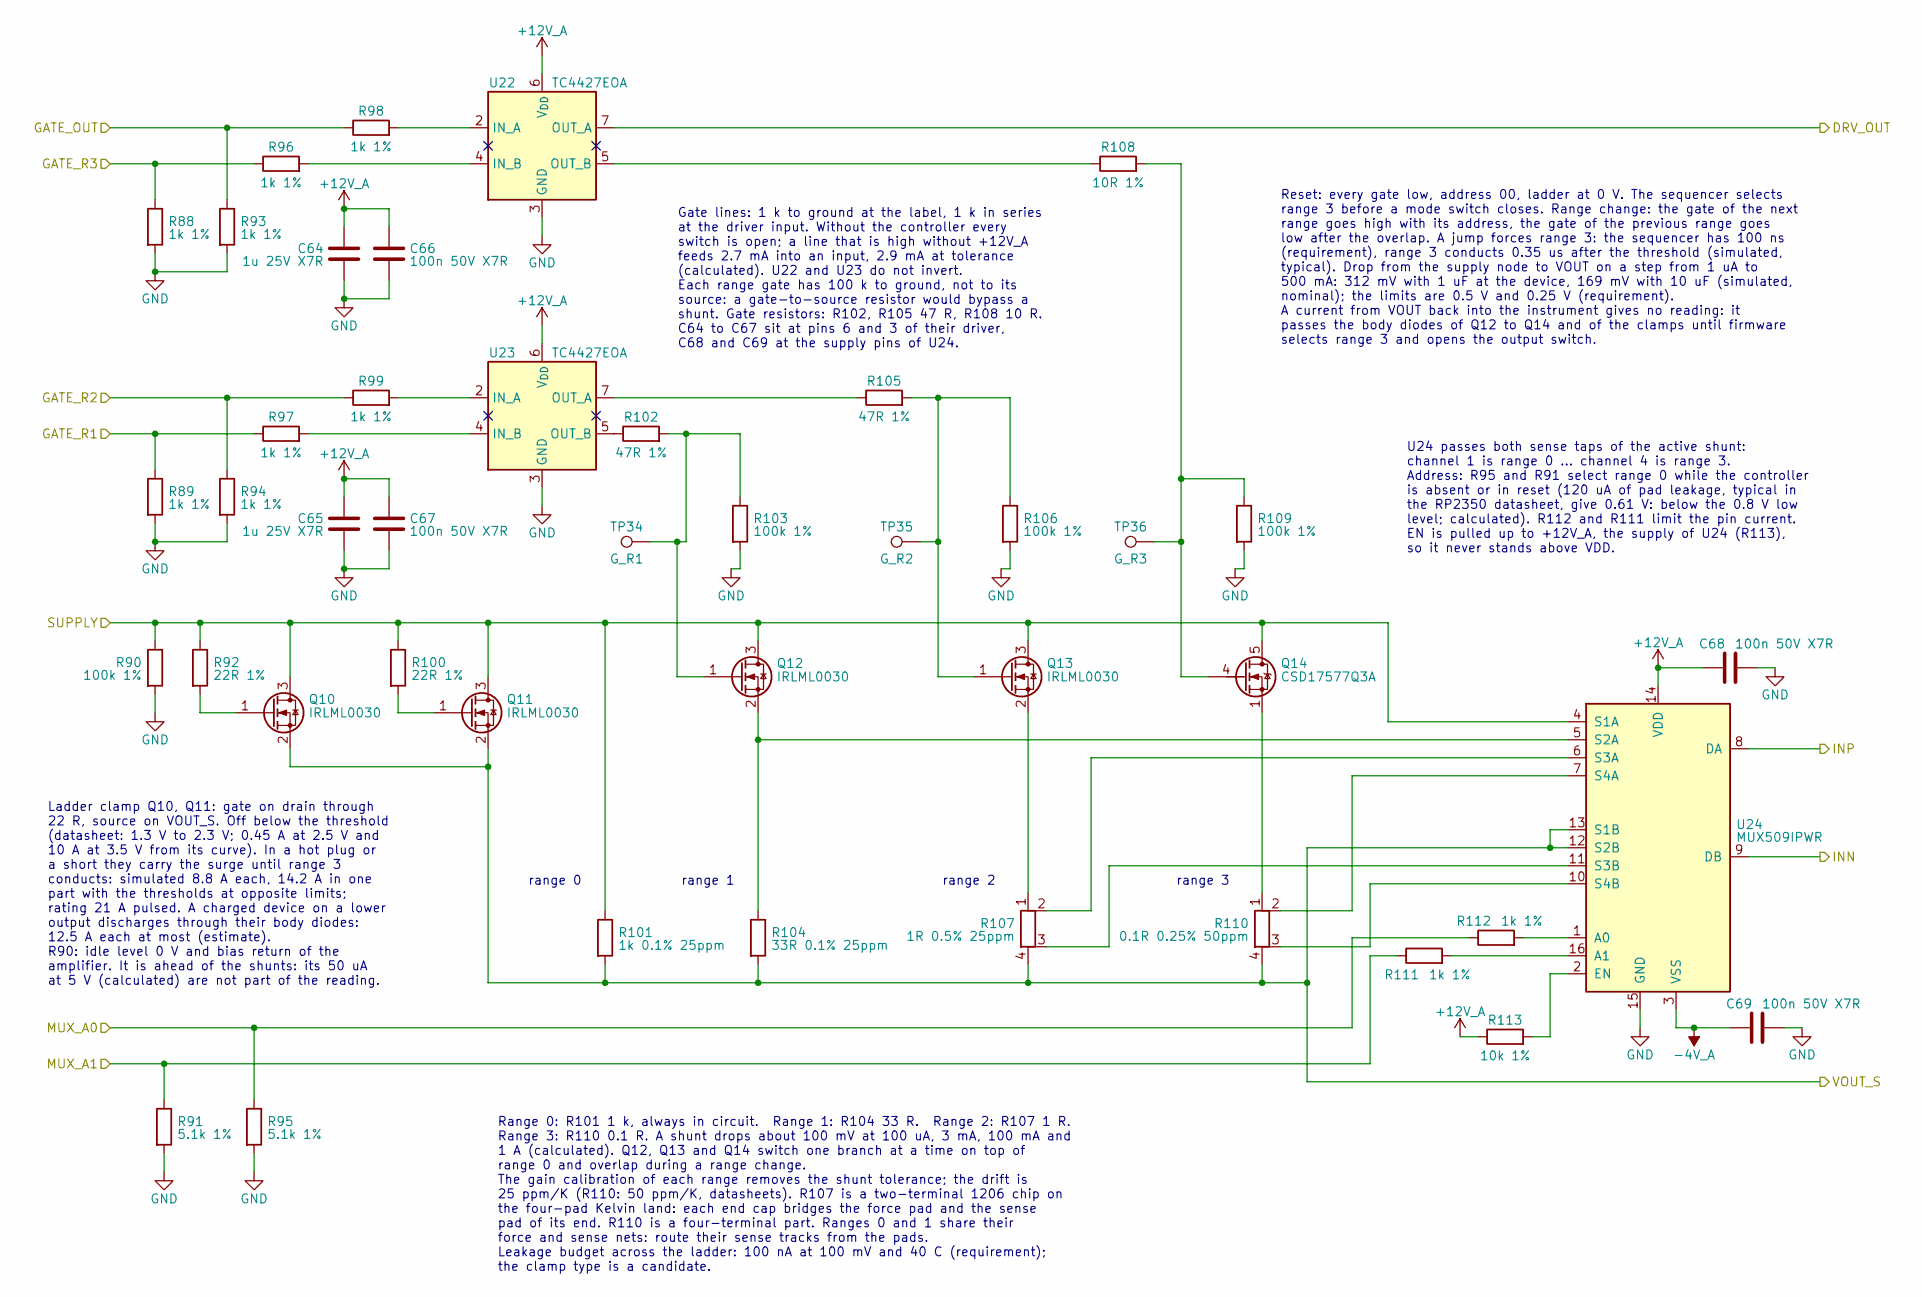
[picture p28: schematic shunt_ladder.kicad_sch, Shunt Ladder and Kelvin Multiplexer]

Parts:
C64, C65: 1u 25V X7R; C_0603_1608Metric; MPN C0603C105K3RACTU
C66, C67, C68, C69: 100n 50V X7R; C_0603_1608Metric; MPN C0603C104K5RACTU
Q10, Q11, Q12, Q13: IRLML0030; SOT-23; MPN IRLML0030TRPBF
Q14: CSD17577Q3A; VSON-8_3.3x3.3mm_P0.65mm_NexFET; MPN CSD17577Q3A
R88, R89, R93, R94, R96, R97, R98, R99, R111, R112: 1k 1%; R_0603_1608Metric; MPN CRCW06031K00FKEA
R90, R103, R106, R109: 100k 1%; R_0603_1608Metric; MPN CRCW0603100KFKEA
R91, R95: 5.1k 1%; R_0603_1608Metric; MPN CRCW06035K10FKEA
R92, R100: 22R 1%; R_0603_1608Metric; MPN CRCW060322R0FKEA
R101: 1k 0.1% 25ppm; R_0805_2012Metric; MPN TNPW08051K00BEEA
R102, R105: 47R 1%; R_0603_1608Metric; MPN CRCW060347R0FKEA
R104: 33R 0.1% 25ppm; R_0805_2012Metric; MPN CPF0805B33RE1
R107: 1R 0.5% 25ppm; R_Shunt_Ohmite_LVK12; MPN TNPW12061R00DEEA
R108: 10R 1%; R_0603_1608Metric; MPN CRCW060310R0FKEA
R110: 0.1R 0.25% 50ppm; R_Shunt_Ohmite_LVK12; MPN LVK12R100CER
R113: 10k 1%; R_0603_1608Metric; MPN CRCW060310K0FKEA
TP34: G_R1; TestPoint_Pad_D1.5mm
TP35: G_R2; TestPoint_Pad_D1.5mm
TP36: G_R3; TestPoint_Pad_D1.5mm
U22, U23: TC4427EOA; SOIC-8_3.9x4.9mm_P1.27mm; MPN TC4427EOA713
U24: MUX509IPWR; TSSOP-16_4.4x5mm_P0.65mm; MPN MUX509IPWR

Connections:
+12V_A: C64.1, C65.1, C66.1, C67.1, C68.1, R113.1, U22.6 (V_{DD}), U23.6 (V_{DD}), U24.14 (VDD); also elsewhere on the board
/Controller/GATE_OUT: R93.1, R98.1; also elsewhere on the board
/Controller/GATE_R1: R89.1, R97.1; also elsewhere on the board
/Controller/GATE_R2: R94.1, R99.1; also elsewhere on the board
/Controller/GATE_R3: R88.1, R96.1; also elsewhere on the board
/Controller/MUX_A0: R95.1, R112.1; also elsewhere on the board
/Controller/MUX_A1: R91.1, R111.1; also elsewhere on the board
/Output Stage/DRV_OUT: U22.7 (OUT_A); also elsewhere on the board
/Output Stage/VOUT_S: Q10.2 (S), Q11.2 (S), R101.2, R104.2, R107.4, R110.4, U24.12 (S2B), U24.13 (S1B); also elsewhere on the board
/Path Switching/SUPPLY: Q10.3 (D), Q11.3 (D), Q12.3 (D), Q13.3 (D), Q14.5 (D), R90.1, R92.1, R100.1, R101.1, U24.4 (S1A); also elsewhere on the board
/Shunt Ladder/INN: U24.9 (DB); also elsewhere on the board
/Shunt Ladder/INP: U24.8 (DA); also elsewhere on the board
unnamed: Q10.1 (G), R92.2
unnamed: Q11.1 (G), R100.2
unnamed: Q12.1 (G), R102.2, R103.1, TP34.1 (1_1)
unnamed: Q12.2 (S), R104.1, U24.5 (S2A)
unnamed: Q13.1 (G), R105.2, R106.1, TP35.1 (1_1)
unnamed: Q13.2 (S), R107.1
unnamed: Q14.4 (G), R108.2, R109.1, TP36.1 (1_1)
unnamed: Q14.1 (S), Q14.2 (S), Q14.3 (S), R110.1
unnamed: R98.2, U22.2 (IN_A)
unnamed: R96.2, U22.4 (IN_B)
unnamed: R108.1, U22.5 (OUT_B)
unnamed: R99.2, U23.2 (IN_A)
unnamed: R97.2, U23.4 (IN_B)
unnamed: R105.1, U23.7 (OUT_A)
unnamed: R102.1, U23.5 (OUT_B)
unnamed: R112.2, U24.1 (A0)
unnamed: R111.2, U24.16 (A1)
unnamed: R113.2, U24.2 (EN)
unnamed: R107.2, U24.6 (S3A)
unnamed: R107.3, U24.11 (S3B)
unnamed: R110.2, U24.7 (S4A)
unnamed: R110.3, U24.10 (S4B)

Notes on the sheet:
Gate lines: 1 k to ground at the label, 1 k in series at the driver input. Without the controller every switch is open; a line that is high without +12V_A feeds 2.7 mA into an input, 2.9 mA at tolerance (calculated). U22 and U23 do not invert. Each range gate has 100 k to ground, not to its source: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
Reset: every gate low, address 00, ladder at 0 V. The sequencer selects range 3 before a mode switch closes. Range change: the gate of the next range goes high with its address, the gate of the previous range goes low after the overlap. A jump forces range 3: the sequencer has 100 ns (requirement),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
range 2
U24 passes both sense taps of the active shunt: channel 1 is range 0 ... channel 4 is range 3. Address: R95 and R91 select range 0 while the controller is absent or in reset (120 uA of pad leakage, typical in the RP2350 datasheet, give 0.61 V: below the 0.8 V low level; calculated). R112 and R111 l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
Ladder clamp Q10, Q11: gate on drain through 22 R, source on VOUT_S. Off below the threshold (datasheet: 1.3 V to 2.3 V; 0.45 A at 2.5 V and 10 A at 3.5 V from its curve). In a hot plug or a short they carry the surge until range 3 conducts: simulated 8.8 A each, 14.2 A in one part with the thresho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
range 3
range 0
range 1
Range 0: R101 1 k, always in circuit. Range 1: R104 33 R. Range 2: R107 1 R. Range 3: R110 0.1 R. A shunt drops about 100 mV at 100 uA, 3 mA, 100 mA and 1 A (calculated). Q12, Q13 and Q14 switch one branch at a time on top of range 0 and overlap during a range change. The gain calibration of each r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

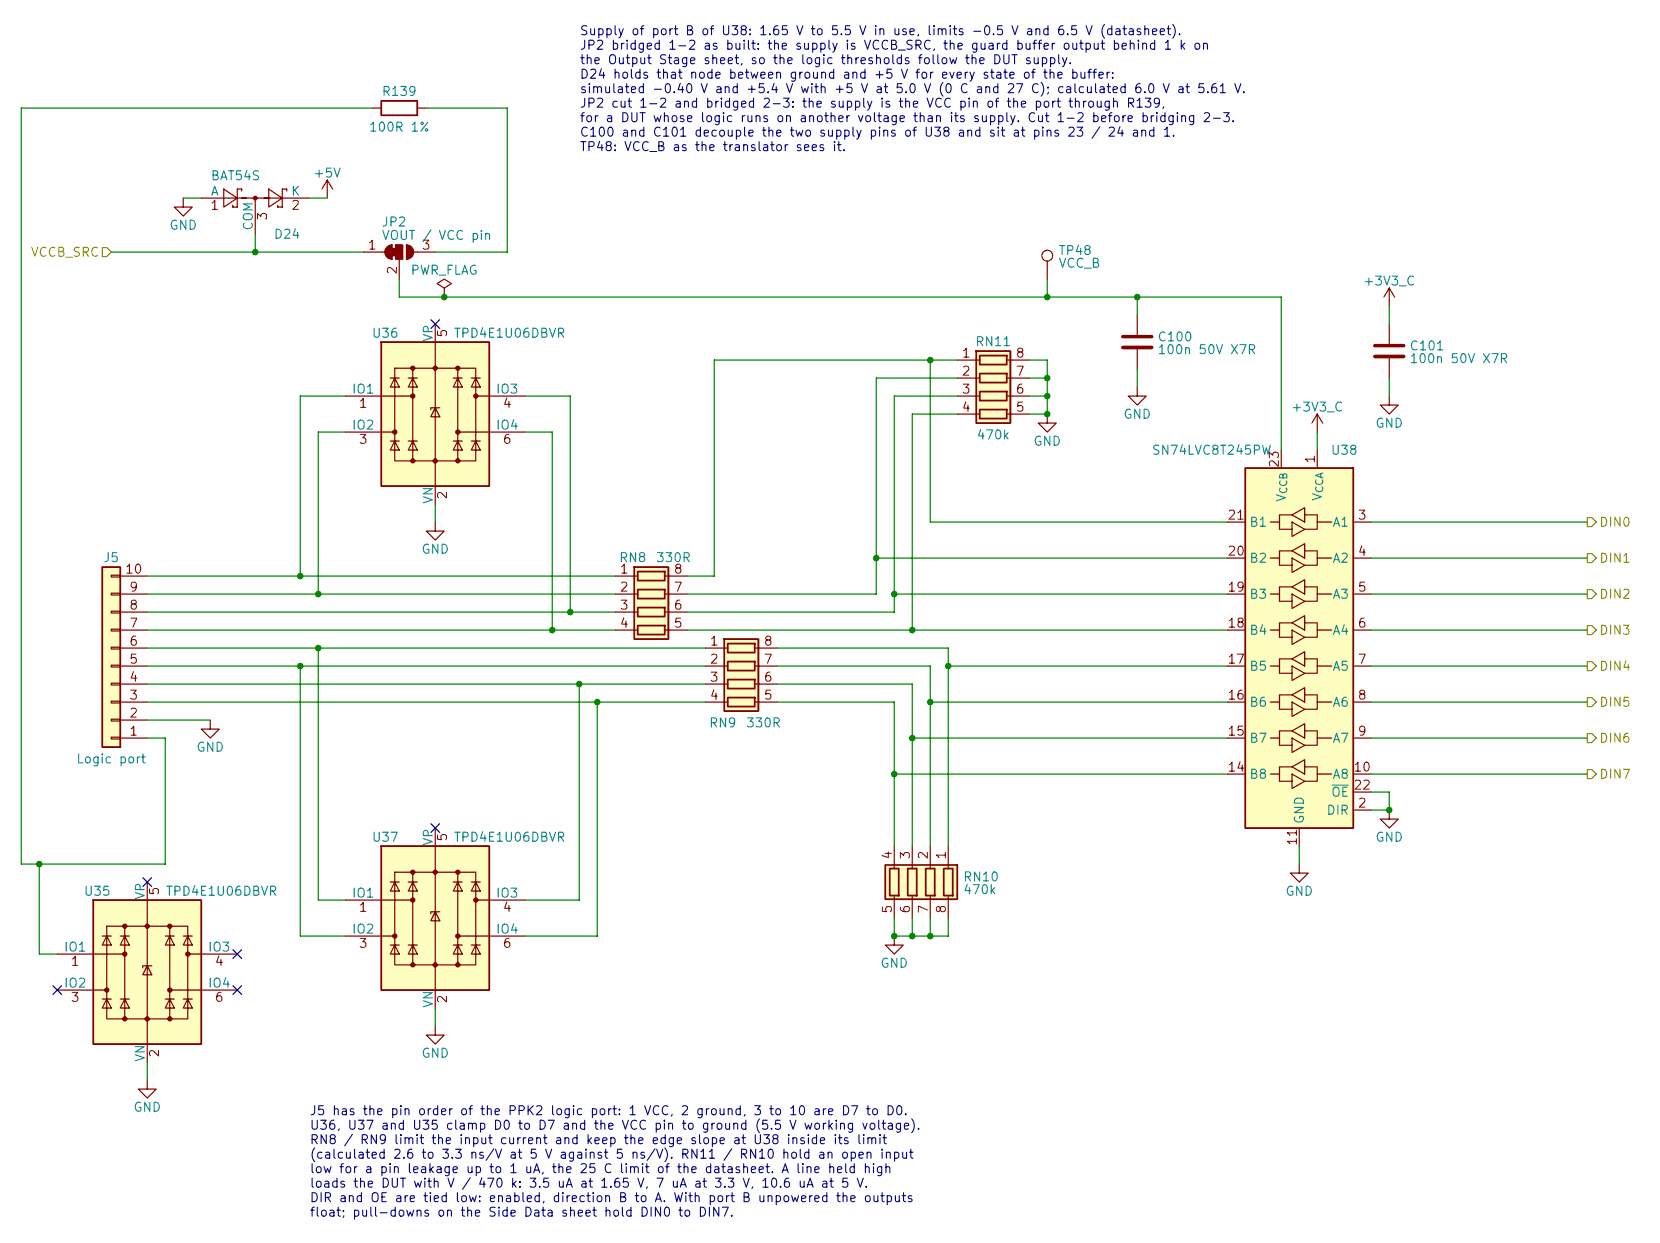
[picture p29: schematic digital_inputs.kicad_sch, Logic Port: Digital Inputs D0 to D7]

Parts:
C100, C101: 100n 50V X7R; C_0603_1608Metric; MPN C0603C104K5RACTU
D24: BAT54S; SOT-23; MPN BAT54SLT1G
J5: Logic port; PinHeader_1x10_P2.54mm_Vertical; MPN 61301011121
JP2: VOUT / VCC pin; SolderJumper-3_P1.3mm_Bridged12_RoundedPad1.0x1.5mm
R139: 100R 1%; R_0603_1608Metric; MPN CRCW0603100RFKEA
RN8, RN9: 330R; R_Array_Convex_4x0603; MPN CAY16-331J4LF
RN10, RN11: 470k; R_Array_Convex_4x0603; MPN CAY16-474J4LF
TP48: VCC_B; TestPoint_Pad_D1.5mm
U35, U36, U37: TPD4E1U06DBVR; SOT-23-6; MPN TPD4E1U06DBVR
U38: SN74LVC8T245PW; TSSOP-24_4.4x7.8mm_P0.65mm; MPN SN74LVC8T245PWR

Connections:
+5V: D24.2 (K); also elsewhere on the board
/Digital Inputs/DIN0: U38.3 (A1); also elsewhere on the board
/Digital Inputs/DIN1: U38.4 (A2); also elsewhere on the board
/Digital Inputs/DIN2: U38.5 (A3); also elsewhere on the board
/Digital Inputs/DIN3: U38.6 (A4); also elsewhere on the board
/Digital Inputs/DIN4: U38.7 (A5); also elsewhere on the board
/Digital Inputs/DIN5: U38.8 (A6); also elsewhere on the board
/Digital Inputs/DIN6: U38.9 (A7); also elsewhere on the board
/Digital Inputs/DIN7: U38.10 (A8); also elsewhere on the board
/Digital Inputs/VCCB_SRC: D24.3 (COM), JP2.1 (A); also elsewhere on the board
unnamed: J5.1, R139.1, U35.1 (IO1)
unnamed: J5.3, RN9.4 (R4.1), U37.6 (IO4)
unnamed: J5.4, RN9.3 (R3.1), U37.4 (IO3)
unnamed: J5.5, RN9.2 (R2.1), U37.3 (IO2)
unnamed: J5.6, RN9.1 (R1.1), U37.1 (IO1)
unnamed: J5.7, RN8.4 (R4.1), U36.6 (IO4)
unnamed: J5.8, RN8.3 (R3.1), U36.4 (IO3)
unnamed: J5.9, RN8.2 (R2.1), U36.3 (IO2)
unnamed: J5.10, RN8.1 (R1.1), U36.1 (IO1)
unnamed: JP2.3 (B), R139.2
unnamed: C100.1, JP2.2 (C), TP48.1 (1_1), U38.23 (V_{CCB}), U38.24 (V_{CCB})
unnamed: RN9.8 (R1.2), RN10.1 (R1.1), U38.17 (B5)
unnamed: RN9.7 (R2.2), RN10.2 (R2.1), U38.16 (B6)
unnamed: RN9.6 (R3.2), RN10.3 (R3.1), U38.15 (B7)
unnamed: RN9.5 (R4.2), RN10.4 (R4.1), U38.14 (B8)
unnamed: RN8.8 (R1.2), RN11.1 (R1.1), U38.21 (B1)
unnamed: RN8.7 (R2.2), RN11.2 (R2.1), U38.20 (B2)
unnamed: RN8.6 (R3.2), RN11.3 (R3.1), U38.19 (B3)
unnamed: RN8.5 (R4.2), RN11.4 (R4.1), U38.18 (B4)

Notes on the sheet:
J5 has the pin order of the PPK2 logic port: 1 VCC, 2 ground, 3 to 10 are D7 to D0. U36, U37 and U35 clamp D0 to D7 and the VCC pin to ground (5.5 V working voltage). RN8 / RN9 limit the input current and keep the edge slope at U38 inside its limit (calculated 2.6 to 3.3 ns/V at 5 V against 5 ns/V)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
Supply of port B of U38: 1.65 V to 5.5 V in use, limits -0.5 V and 6.5 V (datasheet). JP2 bridged 1-2 as built: the supply is VCCB_SRC, the guard buffer output behind 1 k on the Output Stage sheet, so the logic thresholds follow the DUT supply. D24 holds that node between ground and +5 V for every 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

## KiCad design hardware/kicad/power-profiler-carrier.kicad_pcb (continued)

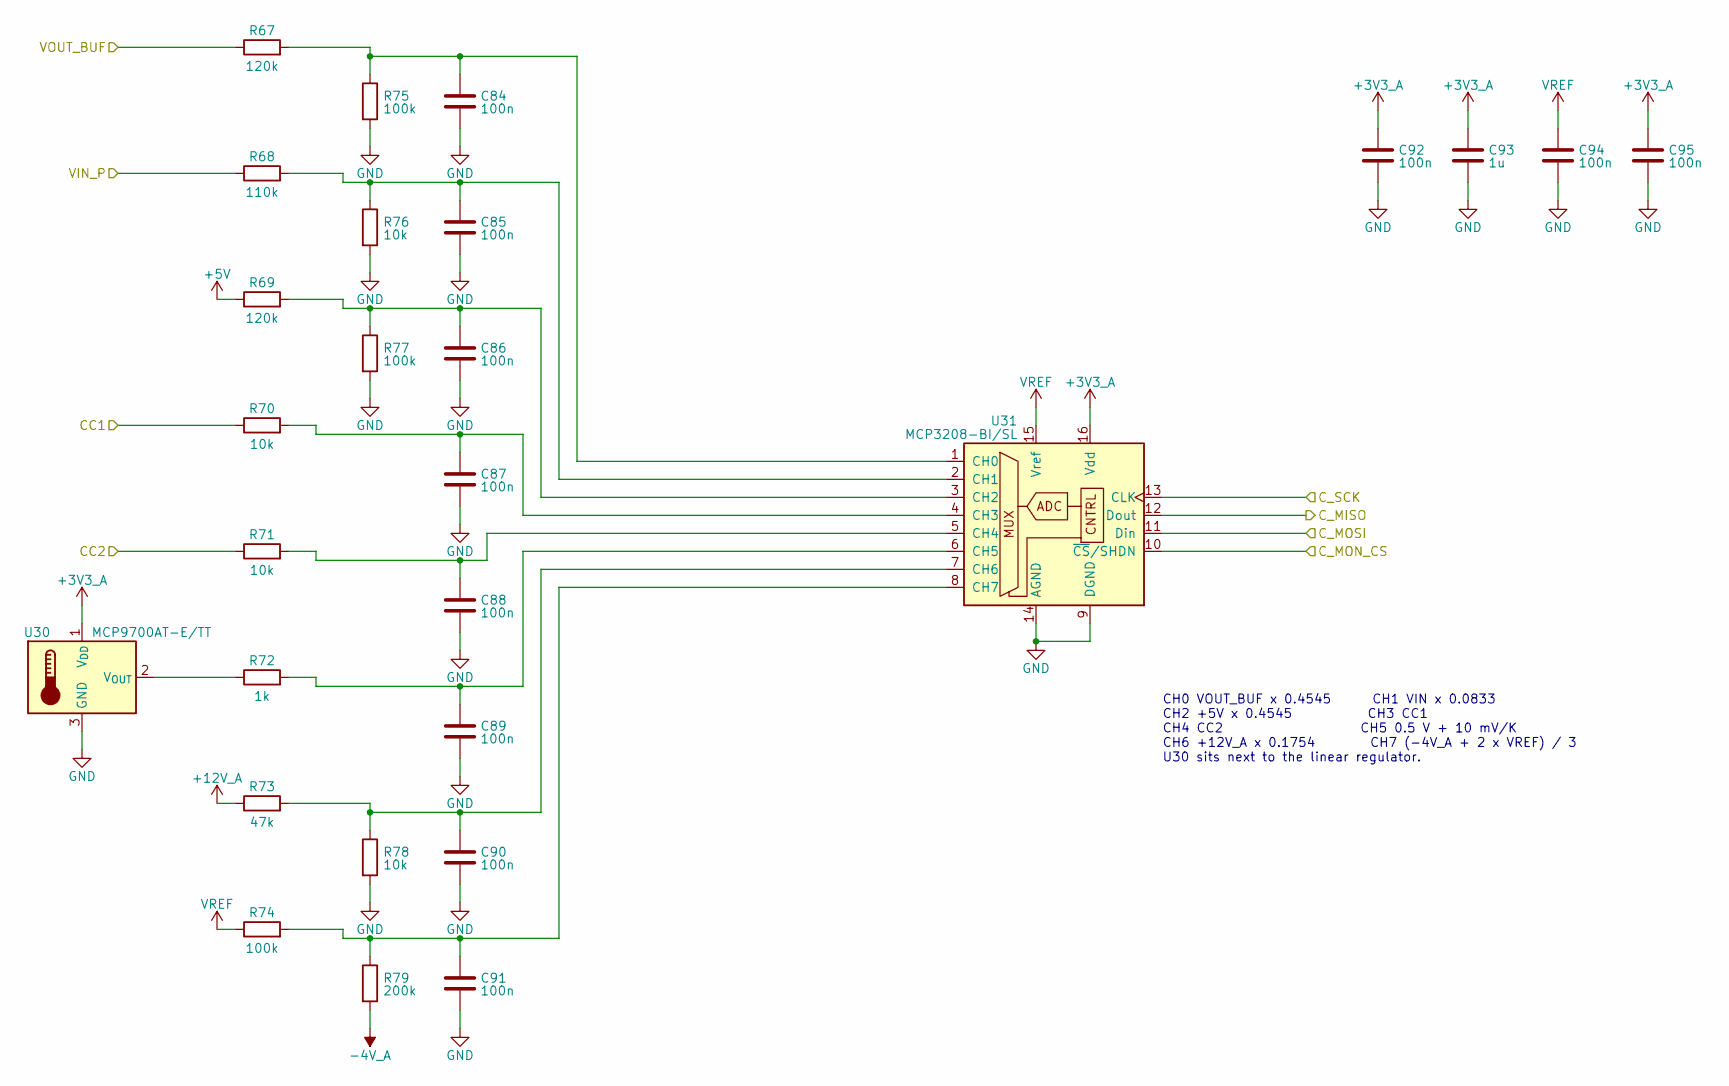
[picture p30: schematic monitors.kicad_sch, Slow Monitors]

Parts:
C84, C85, C86, C87, C88, C89, C90, C91, C92, C94, C95: 100n; C_0603_1608Metric
C93: 1u; C_0603_1608Metric
R67, R69: 120k; R_0603_1608Metric
R68: 110k; R_0603_1608Metric
R70, R71, R76, R78: 10k; R_0603_1608Metric
R72: 1k; R_0603_1608Metric
R73: 47k; R_0603_1608Metric
R74, R75, R77: 100k; R_0603_1608Metric
R79: 200k; R_0603_1608Metric
U30: MCP9700AT-E/TT; SOT-23
U31: MCP3208-BI/SL; SOIC-16_3.9x9.9mm_P1.27mm

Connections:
/Monitors/VIN_P: R73.1; also elsewhere on the board
/Path Switching/LDO_OUT: R69.1; also elsewhere on the board
unnamed 50: R67.1; also elsewhere on the board
unnamed 66: R79.2; also elsewhere on the board

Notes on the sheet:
CH0 VOUT_BUF x 0.4545 CH1 VIN x 0.0833 CH2 +5V x 0.4545 CH3 CC1 CH4 CC2 CH5 0.5 V + 10 mV/K CH6 +12V_A x 0.1754 CH7 (-4V_A + 2 x VREF) / 3 U30 sits next to the linear regulator.

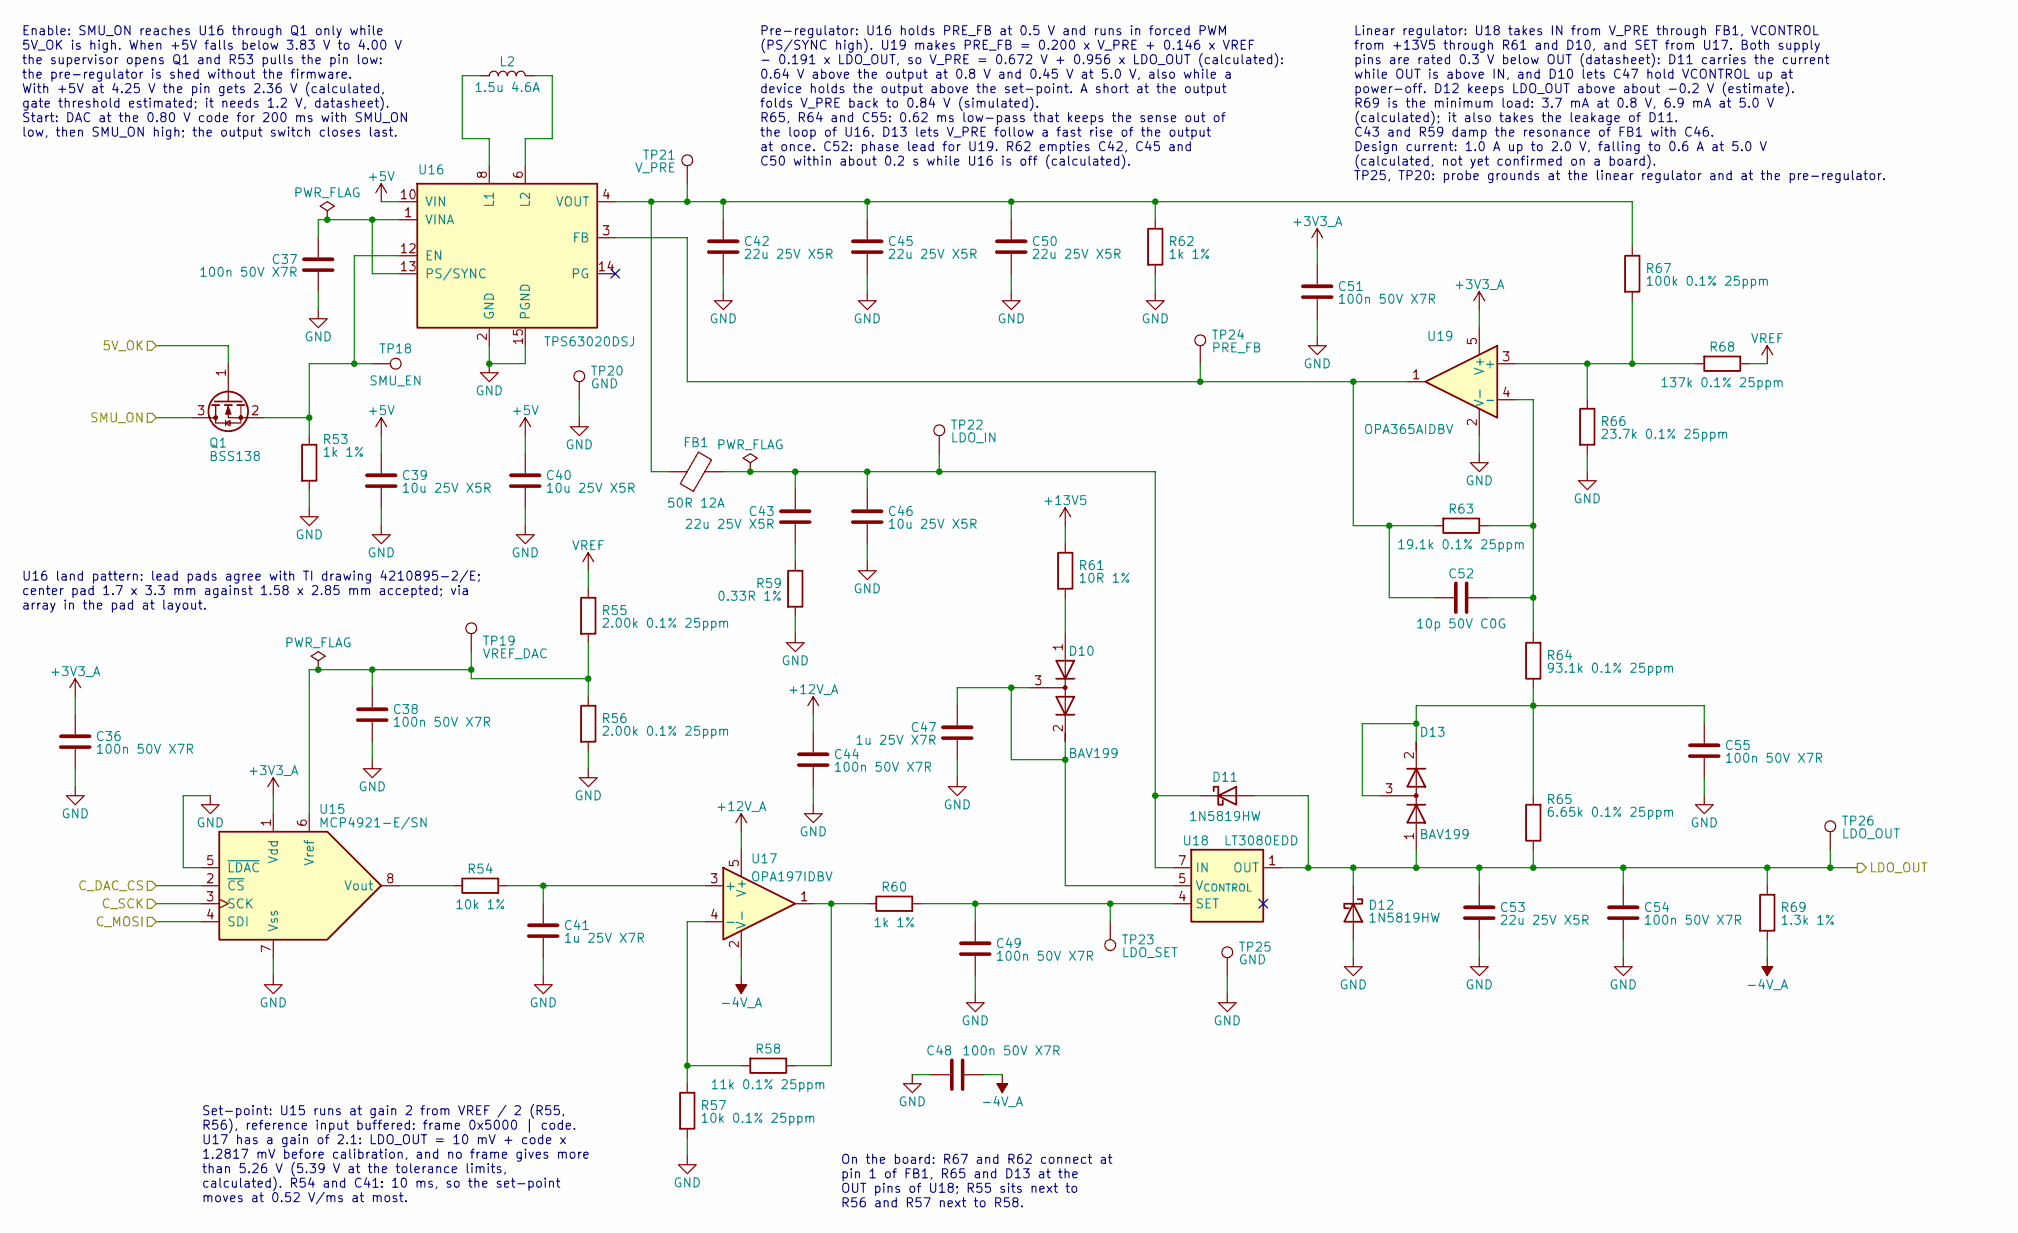
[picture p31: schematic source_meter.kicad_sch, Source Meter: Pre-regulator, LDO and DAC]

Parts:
C36, C37, C38, C44, C48, C49, C51, C54, C55: 100n 50V X7R; C_0603_1608Metric; MPN C0603C104K5RACTU
C39, C40, C46: 10u 25V X5R; C_0805_2012Metric; MPN CL21A106KAYNNNE
C41, C47: 1u 25V X7R; C_0603_1608Metric; MPN C0603C105K3RACTU
C42, C43, C45, C50, C53: 22u 25V X5R; C_1206_3216Metric; MPN CL31A226KAHNNNE
C52: 10p 50V C0G; C_0603_1608Metric; MPN C0603C100J5GACTU
D10, D13: BAV199; SOT-23; MPN BAV199-7-F
D11, D12: 1N5819HW; D_SOD-123; MPN 1N5819HW-7-F
FB1: 50R 12A; L_1206_3216Metric; MPN BLM31SN500SN1L
L2: 1.5u 4.6A; L_Coilcraft_XxL4020; MPN XFL4020-152MEC
Q1: BSS138; SOT-23; MPN BSS138-7-F
R53, R60, R62: 1k 1%; R_0603_1608Metric; MPN CRCW06031K00FKEA
R54: 10k 1%; R_0603_1608Metric; MPN CRCW060310K0FKEA
R55, R56: 2.00k 0.1% 25ppm; R_0603_1608Metric; MPN TNPW06032K00BEEA
R57: 10k 0.1% 25ppm; R_0603_1608Metric; MPN TNPW060310K0BEEA
R58: 11k 0.1% 25ppm; R_0603_1608Metric; MPN TNPW060311K0BEEA
R59: 0.33R 1%; R_0805_2012Metric; MPN ERJ-6RQFR33V
R61: 10R 1%; R_0603_1608Metric; MPN CRCW060310R0FKEA
R63: 19.1k 0.1% 25ppm; R_0603_1608Metric; MPN TNPW060319K1BEEA
R64: 93.1k 0.1% 25ppm; R_0603_1608Metric; MPN TNPW060393K1BEEA
R65: 6.65k 0.1% 25ppm; R_0603_1608Metric; MPN TNPW06036K65BEEA
R66: 23.7k 0.1% 25ppm; R_0603_1608Metric; MPN TNPW060323K7BEEA
R67: 100k 0.1% 25ppm; R_0603_1608Metric; MPN TNPW0603100KBEEA
R68: 137k 0.1% 25ppm; R_0603_1608Metric; MPN ERA-3AEB1373V
R69: 1.3k 1%; R_0805_2012Metric; MPN CRCW08051K30FKEA
TP18: SMU_EN; TestPoint_Pad_D1.5mm
TP19: VREF_DAC; TestPoint_Pad_D1.5mm
TP20, TP25: GND; TestPoint_Pad_2.0x2.0mm
TP21: V_PRE; TestPoint_Pad_D1.5mm
TP22: LDO_IN; TestPoint_Pad_D1.5mm
TP23: LDO_SET; TestPoint_Pad_D1.5mm
TP24: PRE_FB; TestPoint_Pad_D1.5mm
TP26: LDO_OUT; TestPoint_Pad_D1.5mm
U15: MCP4921-E/SN; SOIC-8_3.9x4.9mm_P1.27mm; MPN MCP4921-E/SN
U16: TPS63020DSJ; DFN-14-1EP_3x4mm_P0.5mm_EP1.7x3.3mm; MPN TPS63020DSJR
U17: OPA197IDBV; SOT-23-5; MPN OPA197IDBVR
U18: LT3080EDD; DFN-8-1EP_3x3mm_P0.5mm_EP1.66x2.38mm; MPN LT3080EDD#PBF
U19: OPA365AIDBV; SOT-23-5; MPN OPA365AIDBVR

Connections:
+5V: C39.1, C40.1, U16.10 (VIN), U16.11 (VIN); also elsewhere on the board
+12V_A: C44.1, U17.5 (V+); also elsewhere on the board
+13V5: R61.1; also elsewhere on the board
/Analog Rails/5V_OK: Q1.1 (G); also elsewhere on the board
/Controller/C_DAC_CS: U15.2 (~CS); also elsewhere on the board
/Controller/C_MOSI: U15.4 (SDI); also elsewhere on the board
/Controller/C_SCK: U15.3 (SCK); also elsewhere on the board
/Controller/SMU_ON: Q1.3 (D); also elsewhere on the board
/Path Switching/LDO_OUT: C53.1, C54.1, D11.2 (A), D12.1 (K), D13.1 (A), R65.1, R69.1, TP26.1 (1_1), U18.1 (OUT), U18.2 (OUT), U18.3 (OUT), U18.9 (OUT); also elsewhere on the board
unnamed: C42.1, C45.1, C50.1, FB1.1, R62.1, R67.1, TP21.1 (1_1), U16.4 (VOUT), U16.5 (VOUT)
unnamed: C43.2, R59.1
unnamed: D10.1 (A), R61.2
unnamed: C47.1, D10.2 (K), D10.3 (common), U18.5 (V_{CONTROL})
unnamed: C43.1, C46.1, D11.1 (K), FB1.2, TP22.1 (1_1), U18.7 (IN), U18.8 (IN)
unnamed: C55.1, D13.2 (K), D13.3 (common), R64.1, R65.2
unnamed: L2.1, U16.8 (L1), U16.9 (L1)
unnamed: L2.2, U16.6 (L2), U16.7 (L2)
unnamed: Q1.2 (S), R53.1, TP18.1 (1_1), U16.12 (EN)
unnamed: R58.1, R60.1, U17.1
unnamed: R54.1, U15.8 (Vout)
unnamed: C38.1, R55.2, R56.1, TP19.1 (1_1), U15.6 (Vref)
unnamed: C52.2, R63.2, TP24.1 (1_1), U16.3 (FB), U19.1
unnamed: C37.1, U16.1 (VINA), U16.13 (PS/SYNC)
unnamed: C41.1, R54.2, U17.3 (+)
unnamed: R57.1, R58.2, U17.4 (-)
unnamed: C49.1, R60.2, TP23.1 (1_1), U18.4 (SET)
unnamed: C52.1, R63.1, R64.2, U19.4 (-)

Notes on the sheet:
Pre-regulator: U16 holds PRE_FB at 0.5 V and runs in forced PWM (PS/SYNC high). U19 makes PRE_FB = 0.200 x V_PRE + 0.146 x VREF - 0.191 x LDO_OUT, so V_PRE = 0.672 V + 0.956 x LDO_OUT (calculated): 0.64 V above the output at 0.8 V and 0.45 V at 5.0 V, also while a device holds the output above the 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
U16 land pattern: lead pads agree with TI drawing 4210895-2/E; center pad 1.7 x 3.3 mm against 1.58 x 2.85 mm accepted; via array in the pad at layout.
Linear regulator: U18 takes IN from V_PRE through FB1, VCONTROL from +13V5 through R61 and D10, and SET from U17. Both supply pins are rated 0.3 V below OUT (datasheet): D11 carries the current while OUT is above IN, and D10 lets C47 hold VCONTROL up at power-off. D12 keeps LDO_OUT above about -0.2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
On the board: R67 and R62 connect at pin 1 of FB1, R65 and D13 at the OUT pins of U18; R55 sits next to R56 and R57 next to R58.
Set-point: U15 runs at gain 2 from VREF / 2 (R55, R56), reference input buffered: frame 0x5000 | code. U17 has a gain of 2.1: LDO_OUT = 10 mV + code x 1.2817 mV before calibration, and no frame gives more than 5.26 V (5.39 V at the tolerance limits, calculated). R54 and C41: 10 ms, so the set-point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
Enable: SMU_ON reaches U16 through Q1 only while 5V_OK is high. When +5V falls below 3.83 V to 4.00 V the supervisor opens Q1 and R53 pulls the pin low: the pre-regulator is shed without the firmware. With +5V at 4.25 V the pin gets 2.36 V (calculated, gate threshold estimated; it needs 1.2 V, data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

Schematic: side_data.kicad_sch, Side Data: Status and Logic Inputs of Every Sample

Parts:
C98, C99: 100n 50V X7R; C_0603_1608Metric; MPN C0603C104K5RACTU
R138: 33R 1%; R_0603_1608Metric; MPN CRCW060333R0FKEA
RN6, RN7: 100k; R_Array_Convex_4x0603; MPN CAY16-104J4LF
U33, U34: SN74LV165ADR; SOIC-16_3.9x9.9mm_P1.27mm; MPN SN74LV165ADR

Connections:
/Comparators/CMP_UP: U34.12 (D1); also elsewhere on the board
/Controller/ADC_SCK: U33.2 (CP), U34.2 (CP); also elsewhere on the board
/Controller/GATE_OUT: U34.4 (D5); also elsewhere on the board
/Controller/MUX_A0: U34.5 (D6); also elsewhere on the board
/Controller/MUX_A1: U34.6 (D7); also elsewhere on the board
/Controller/PWR_GOOD: U34.11 (D0); also elsewhere on the board
/Controller/SIDE_DOUT: R138.2; also elsewhere on the board
/Controller/SIDE_LOAD: U33.1 (~PL), U34.1 (~PL); also elsewhere on the board
/Digital Inputs/DIN0: RN6.1 (R1.1), U33.11 (D0); also elsewhere on the board
/Digital Inputs/DIN1: RN6.2 (R2.1), U33.12 (D1); also elsewhere on the board
/Digital Inputs/DIN2: RN6.3 (R3.1), U33.13 (D2); also elsewhere on the board
/Digital Inputs/DIN3: RN6.4 (R4.1), U33.14 (D3); also elsewhere on the board
/Digital Inputs/DIN4: RN7.1 (R1.1), U33.3 (D4); also elsewhere on the board
/Digital Inputs/DIN5: RN7.2 (R2.1), U33.4 (D5); also elsewhere on the board
/Digital Inputs/DIN6: RN7.3 (R3.1), U33.5 (D6); also elsewhere on the board
/Digital Inputs/DIN7: RN7.4 (R4.1), U33.6 (D7); also elsewhere on the board
unnamed: U33.9 (Q7), U34.10 (DS)
unnamed: R138.1, U34.9 (Q7)

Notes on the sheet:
ADC_SCK: 9.375 MHz or less at 100 kSPS (16 or more system clock cycles per bit), 15 MHz at most for the 500 kSPS option (10 per bit). Register at 3.3 V (datasheet): load pulse 9 ns or longer, clock to Q7 18 ns at most. Time in which both data lines can be read (calculated): 36.9 ns at 9.375 MHz, 16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
U33, U34: SN74LV165A only. Its inputs take 5.5 V whatever the supply (datasheet); a 74HC or 74HCT type does not, and the controller module can drive these lines while the carrier is off. VIN_OV and PWR_GOOD are taken on the carrier side of the series resistors of the controller pins (4.7 k and 1 k)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
How a sample gets its sixteen side bits: 1. SIDE_LOAD is low at the convert-start edge of the converter, for three system clock cycles (20 ns) or more. U33 and U34 follow their inputs while it is low and hold them when it rises; SIDE_DOUT then shows MUX_A1. 2. Each rising edge of ADC_SCK brings the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

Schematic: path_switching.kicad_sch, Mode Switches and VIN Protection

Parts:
C56, C62: 1u 25V X7R; C_0603_1608Metric; MPN C0603C105K3RACTU
C57, C59, C60, C61: 100n 50V X7R; C_0603_1608Metric; MPN C0603C104K5RACTU
C58: 1n 50V C0G; C_0603_1608Metric; MPN C0603C102J5GACTU
C63: 4.7u 25V X7R; C_0805_2012Metric; MPN CL21B475KAFNNNE
D14: SMAJ20CA; D_SMA; MPN SMAJ20CA-E3/61
D15, D16, D17, D18, D19: BAV199; SOT-23; MPN BAV199-7-F
F1: 4A fast 32V; Fuse_1206_3216Metric; MPN 0466004.NR
Q2, Q3: BSS138; SOT-23; MPN BSS138-7-F
Q4, Q5, Q8, Q9: CSD17577Q3A; VSON-8_3.3x3.3mm_P0.65mm_NexFET; MPN CSD17577Q3A
Q6, Q7: BC847B; SOT-23; MPN BC847B-7-F
R70, R72, R75: 1k 1%; R_0603_1608Metric; MPN CRCW06031K00FKEA
R71: 4.7k 1%; R_0603_1608Metric; MPN CRCW06034K70FKEA
R73: 115k 0.1%; R_0603_1608Metric; MPN TNPW0603115KBEEA
R74: 100k 0.1% 25ppm; R_0603_1608Metric; MPN TNPW0603100KBEEA
R76: 3.3M 1%; R_0603_1608Metric; MPN CRCW06033M30FKEA
R77, R79: 22R 1%; R_0603_1608Metric; MPN CRCW060322R0FKEA
R78, R80, R85, R86: 100k 1%; R_0603_1608Metric; MPN CRCW0603100KFKEA
R81, R82: 6.8k 1%; R_0603_1608Metric; MPN CRCW06036K80FKEA
R83, R84: 2.2M 1%; R_0603_1608Metric; MPN CRCW06032M20FKEA
R87: 0.47R 1% 0.5W; R_1206_3216Metric; MPN RCWE1206R470FKEA
TP27: VIN_P; TestPoint_Pad_D1.5mm
TP28, TP29: GND; TestPoint_Pad_2.0x2.0mm
TP30: VIN_OV; TestPoint_Pad_D1.5mm
TP31: SRC_G; TestPoint_Pad_D1.5mm
TP32: AMP_G; TestPoint_Pad_D1.5mm
TP33: SUPPLY; TestPoint_Pad_D1.5mm
U20: TC4427EOA; SOIC-8_3.9x4.9mm_P1.27mm; MPN TC4427EOA713
U21: MCP6561T-E/OT; SOT-23-5; MPN MCP6561T-E/OT

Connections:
+12V_A: C56.1, C57.1, D16.2 (K), D17.2 (K), U20.6 (V_{DD}); also elsewhere on the board
/Monitors/VIN_P: D14.1 (A1), F1.2, Q5.5 (D), R73.1, TP27.1 (1_1); also elsewhere on the board
/Output Stage/VIN_RAW: F1.1; also elsewhere on the board
/Path Switching/LDO_OUT: Q4.5 (D); also elsewhere on the board
/Path Switching/SUPPLY: C62.1, Q8.5 (D), Q9.5 (D), R87.1, TP33.1 (1_1); also elsewhere on the board
unnamed: C60.2, R81.1
unnamed: C61.2, R82.1
unnamed: C63.1, R87.2
unnamed: C61.1, D17.1 (A), Q5.4 (G), Q7.3 (C), Q9.4 (G), R80.2, R84.1, TP32.1 (1_1)
unnamed: D17.3 (common), R79.2
unnamed: D18.1 (A), Q4.1 (S), Q4.2 (S), Q4.3 (S), Q6.2 (E), Q8.1 (S), Q8.2 (S), Q8.3 (S), R83.2
unnamed: D18.2 (K), D18.3 (common), Q6.1 (B), R85.1
unnamed: D19.1 (A), Q5.1 (S), Q5.2 (S), Q5.3 (S), Q7.2 (E), Q9.1 (S), Q9.2 (S), Q9.3 (S), R84.2
unnamed: D19.2 (K), D19.3 (common), Q7.1 (B), R86.1

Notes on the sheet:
Supply node of the ladder. C62 and the damped branch R87, C63 take the current of the supply leads when the over-current trip opens the output in ampere mode. Simulated: SUPPLY stays 0.5 V or more below +12V_A then. The bleed resistor of this node is on the Shunt Ladder sheet.
VIN: 0.8 V to 5.0 V in use. With the ampere pair open the terminal withstands -20 V to +20 V and takes less than 1 mA (simulated). With the pair closed the supply has to stay in its range. D14 takes hot-plug rings and the kick of the supply leads; it conducts from 22.2 V (datasheet): never a 24 V s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
Mode pairs: Q4, Q8 pass the regulator output (source mode), Q5, Q9 pass VIN (ampere mode). Both are open at reset. The gate networks are alike; for the ampere pair: Closing: R80 charges the gate against C61, R82: (100 k + 6.8 k) x 100 nF = 10.7 ms, after a first step of 0.76 V, below the threshold 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

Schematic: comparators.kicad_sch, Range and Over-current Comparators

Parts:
C93, C94, C95, C96, C97: 100n 50V X7R; C_0603_1608Metric; MPN C0603C104K5RACTU
D23: BAV199; SOT-23; MPN BAV199-7-F
R132: 34.8k 0.1% 25ppm; R_0603_1608Metric; MPN TNPW060334K8BEEA
R133: 3.6k 0.1% 25ppm; R_0603_1608Metric; MPN TNPW06033K60BEEA
R134: 2.4k 0.1% 25ppm; R_0603_1608Metric; MPN TNPW06032K40BEEA
R135: 9.31k 0.1% 25ppm; R_0603_1608Metric; MPN TNPW06039K31BEEA
R136: 3.01k 0.1% 25ppm; R_0603_1608Metric; MPN ERA-3AEB3011V
R137: 1k 0.1% 25ppm; R_0603_1608Metric; MPN TNPW06031K00BEEA
TP45: CMP_JUMP; TestPoint_Pad_D1.5mm
TP46: CMP_OC; TestPoint_Pad_D1.5mm
TP47: CMP_UP; TestPoint_Pad_D1.5mm
U31: MCP6562-E/SN; SOIC-8_3.9x4.9mm_P1.27mm; MPN MCP6562-E/SN
U32: MCP6561T-E/OT; SOT-23-5; MPN MCP6561T-E/OT

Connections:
/Comparators/AMP_RAW: R136.1; also elsewhere on the board
/Comparators/CMP_UP: TP47.1 (1_1), U32.1; also elsewhere on the board

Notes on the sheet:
Inputs: AMP_RAW / 4.01 (R136, R137). Thresholds from VREF through R132 to R135, all 0.1 %; the levels at the comparators are calculated. With every tolerance the over-current level is 111.4 mV to 118.7 mV at the shunt and stays below the full scale of the converter, 122.9 mV. Jump forces range 3, o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
over-current: 0.584 V, 115 mV at the shunt
step up: 0.464 V, 91 mV at the shunt
jump: 0.764 V, 151 mV at the shunt

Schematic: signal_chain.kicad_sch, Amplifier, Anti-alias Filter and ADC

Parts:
C75, C76: 22p 50V C0G; C_0603_1608Metric; MPN C0603C220J5GACTU
C77: 220p 50V C0G; C_0603_1608Metric; MPN C0603C221J5GACTU
C78, C82, C83, C91, C92: 1u 25V X7R; C_0603_1608Metric; MPN C0603C105K3RACTU
C79, C80, C81, C84, C86, C88: 100n 50V X7R; C_0603_1608Metric; MPN C0603C104K5RACTU
C85: 1.5n 50V C0G; C_0603_1608Metric; MPN C0603C152J5GACTU
C87: 680p 50V C0G; C_0603_1608Metric; MPN C0603C681J5GACTU
C89: 22u 6.3V X5R; C_0805_2012Metric; MPN CL21A226KQQNNNE
C90: 10n 25V C0G; C_0603_1608Metric; MPN C0603C103J3GACTU
D22: BAV199; SOT-23; MPN BAV199-7-F
MP3: BMI-S-210-C; MPN BMI-S-210-C
R121: 49.9k 0.1% 25ppm; R_0603_1608Metric; MPN TNPW060349K9BEEA
R122: 1.02k 0.1% 25ppm; R_0603_1608Metric; MPN TNPW06031K02BEEA
R123: 523R 0.1% 25ppm; R_0603_1608Metric; MPN RT0603BRD07523RL
R124: 11k 0.1% 25ppm; R_0603_1608Metric; MPN TNPW060311K0BEEA
R125, R128: 3.9k 1%; R_0603_1608Metric; MPN CRCW06033K90FKEA
R126: 10k 1%; R_0603_1608Metric; MPN CRCW060310K0FKEA
R127: 1k 0.1% 25ppm; R_0603_1608Metric; MPN TNPW06031K00BEEA
R129: 10R 1%; R_0603_1608Metric; MPN CRCW060310R0FKEA
R130: 22R 1%; R_0603_1608Metric; MPN CRCW060322R0FKEA
R131: 0.22R 1%; R_0603_1608Metric; MPN ERJ-3RQFR22V
RN5: 220R 5%; R_Array_Convex_4x0603; MPN CAY16-221J4LF
SH1: BMI-S-210-F; Laird_Technologies_BMI-S-210-F_44.00x30.50mm; MPN BMI-S-210-F
TP41: PED; TestPoint_Pad_D1.5mm
TP42: VDRV; TestPoint_Pad_D1.5mm
TP43: ADC_IN; TestPoint_Pad_D1.5mm
TP44: AMP_RAW; TestPoint_Pad_D1.5mm
U26: OPA197IDBV; SOT-23-5; MPN OPA197IDBVR
U27: AD8421ARZ; SOIC-8_3.9x4.9mm_P1.27mm; MPN AD8421ARZ
U28, U29: OPA365AIDBV; SOT-23-5; MPN OPA365AIDBVR
U30: ADS8860IDGS; MSOP-10_3x3mm_P0.5mm; MPN ADS8860IDGS

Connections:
+12V_A: C79.1, C80.1, C83.1, U26.5 (V+), U27.8 (Vs+); also elsewhere on the board
/Comparators/AMP_RAW: R125.1, TP44.1 (1_1), U27.7; also elsewhere on the board
/Controller/ADC_CNV: RN5.6 (R3.2); also elsewhere on the board
/Controller/ADC_DOUT: RN5.7 (R2.2); also elsewhere on the board
/Controller/ADC_SCK: RN5.8 (R1.2); also elsewhere on the board
/Shunt Ladder/INN: C75.1, C77.2, U27.1 (-); also elsewhere on the board
/Shunt Ladder/INP: C76.1, C77.1, U27.4 (+); also elsewhere on the board
unnamed: R123.1, U27.2 (Rg)
unnamed: R123.2, U27.3 (Rg)
unnamed: R127.1, R129.1, U28.1
unnamed: RN5.1 (R1.1), U30.8 (SCLK)
unnamed: RN5.2 (R2.1), U30.7 (DOUT)
unnamed: RN5.3 (R3.1), U30.6 (CONVST)
unnamed: C78.1, R121.2, R122.1, U26.3 (+)
unnamed: TP41.1 (1_1), U26.1, U26.4 (-), U27.6 (Ref)
unnamed: R126.2, U28.3 (+)
unnamed: R124.1, R127.2, U28.4 (-)

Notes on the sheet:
AMP_RAW can reach 10 V during a range change: R125 and D22 limit the driver input. U29 and D22 run from VDRV: 1.091 x VREF = 2.73 V at the output of U28 (R127, R124), about 2.68 V behind R129 (calculated), which keeps the buffer stable into C88. While the buffer is supplied the converter input cann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
SH1, MP3: two-piece shield can over the multiplexer, the amplifier, the converter and the shunts of ranges 0 to 2. The frame is soldered with the parts; the cover is snapped on after cleaning and comes off for probing.
U27: G = 1 + 9.9 k / R123 = 19.93. Its reference pin stands at 50 mV (R121, R122, U26): zero current reads about 1313 codes; the converter is at full scale with 122.9 mV across the shunt. Input filter C77 220 pF, C76 = C75 22 pF: about 0.12 us with the multiplexer in front (calculated).

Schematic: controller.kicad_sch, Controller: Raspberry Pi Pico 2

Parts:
D1: 1N5819HW; D_SOD-123; MPN 1N5819HW-7-F
J1: Debug UART; PinHeader_1x03_P2.54mm_Vertical; MPN 61300311121
JP1: USB of Pico feeds +5V; SolderJumper-2_P1.3mm_Bridged_RoundedPad1.0x1.5mm
MP1, MP2: Socket 1x20 2.54 mm; MPN 61302011821
R1: 4.7k 1%; R_0603_1608Metric; MPN CRCW06034K70FKEA
R2: 0R; R_0603_1608Metric; MPN CRCW06030000Z0EA
R3: 1.5k 1%; R_0603_1608Metric; MPN CRCW06031K50FKEA
R4: 1k 1%; R_0603_1608Metric; MPN CRCW06031K00FKEA
RN1: 2.2k; R_Array_Convex_4x0603; MPN CAY16-222J4LF
RN2, RN3: 4.7k; R_Array_Convex_4x0603; MPN CAY16-472J4LF
RN4: 47R; R_Array_Convex_4x0603; MPN CAY16-470J4LF
SW1: RESET; SW_PUSH_6mm; MPN B3F-1000
U1: Raspberry Pi Pico 2; RaspberryPi_Pico_Common_THT_NoKeepout; MPN SC1632

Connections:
+5V: D1.2 (A); also elsewhere on the board
/Comparators/CMP_UP: U1.11 (GPIO8); also elsewhere on the board
/Controller/ADC_CNV: RN4.7 (R2.2); also elsewhere on the board
/Controller/ADC_DOUT: U1.21 (GPIO16); also elsewhere on the board
/Controller/ADC_SCK: RN4.8 (R1.2); also elsewhere on the board
/Controller/C_DAC_CS: R3.2; also elsewhere on the board
/Controller/C_MISO: RN1.8 (R1.2), RN2.1 (R1.1); also elsewhere on the board
/Controller/C_MON_CS: RN1.7 (R2.2); also elsewhere on the board
/Controller/C_MOSI: RN1.5 (R4.2); also elsewhere on the board
/Controller/C_SCK: RN1.6 (R3.2); also elsewhere on the board
/Controller/GATE_OUT: U1.10 (GPIO7); also elsewhere on the board
/Controller/GATE_R1: U1.4 (GPIO2); also elsewhere on the board
/Controller/GATE_R2: U1.5 (GPIO3); also elsewhere on the board
/Controller/GATE_R3: U1.6 (GPIO4); also elsewhere on the board
/Controller/MUX_A0: U1.7 (GPIO5); also elsewhere on the board
/Controller/MUX_A1: U1.9 (GPIO6); also elsewhere on the board
/Controller/PICO_5V: JP1.2 (B); also elsewhere on the board
/Controller/PWR_GOOD: R4.1; also elsewhere on the board
/Controller/SIDE_DOUT: U1.22 (GPIO17); also elsewhere on the board
/Controller/SIDE_LOAD: RN4.6 (R3.2); also elsewhere on the board
/Controller/SMU_ON: U1.24 (GPIO18); also elsewhere on the board
unnamed: D1.1 (K), U1.39 (VSYS)
unnamed: J1.1, U1.1 (GPIO0)
unnamed: J1.2, U1.2 (GPIO1)
unnamed: JP1.1 (A), U1.40 (VBUS)
unnamed: RN1.1 (R1.1), U1.16 (GPIO12)
unnamed: RN1.2 (R2.1), RN2.2 (R2.1), U1.17 (GPIO13)
unnamed: RN1.3 (R3.1), RN2.3 (R3.1), U1.19 (GPIO14)
unnamed: RN1.4 (R4.1), RN2.4 (R4.1), U1.20 (GPIO15)
unnamed: RN3.1 (R1.1), RN4.1 (R1.1), U1.25 (GPIO19)
unnamed: RN3.2 (R2.1), RN4.2 (R2.1), U1.26 (GPIO20)
unnamed: RN3.3 (R3.1), RN4.3 (R3.1), U1.27 (GPIO21)
unnamed: RN3.4 (R4.1), RN4.4 (R4.1), U1.29 (GPIO22)
unnamed: R3.1, RN4.5 (R4.2)
unnamed: R2.1, U1.33 (AGND)
unnamed: R1.2, U1.15 (GPIO11)
unnamed: R4.2, U1.34 (GPIO28_ADC2)
unnamed: SW1.2, U1.30 (RUN)

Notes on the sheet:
Series resistors limit the current of a pin into an input whose supply is absent (calculated): RN1 2.2 k: 1.24 mA, 1.39 mA at tolerance. RN4 47 ohm plus R3 1.5 k in the DAC select: 1.77 mA, 1.90 mA at tolerance; the inputs of the DAC are rated 2 mA. The slow SPI bus runs at 500 kHz or less.
Supply: the USB voltage of the module leaves through JP1 as PICO_5V to its current limiter (0.76 A) and to the source selector on the Power Input sheet, where USB-C has priority. The selected +5V feeds VSYS through D1. Cut JP1 to keep the carrier off the USB port of the computer.
U1 is a Raspberry Pi Pico 2 with headers, plugged into the sockets MP1 and MP2: the only programmable part. RP2350 stepping A3 or A4 is preferred. A Pico 2 W fits the sockets, but the firmware does not support it. PIO block 0 (GP16, GP17, GP19 to GP21) clocks the converter and reads its data and th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
Released pins (reset, boot loader, sockets empty): a resistor on the carrier holds every line that the module drives, except the console output. RN2 and RN3 pull the two chip selects (GP13, GP22) up to +3V3_A and the other SPI and acquisition lines down: no converter is selected, none converts. Aga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
R1 and R4 keep the two status lines true if a pin is set as an output by mistake: VIN_OV then moves by 0.14 V at most, and PWR_GOOD carries 3.3 mA at most (calculated; the comparators that drive it are rated 25 mA). Firmware never sets GP1, GP8 to GP12, GP16, GP17 or GP28 as an output.

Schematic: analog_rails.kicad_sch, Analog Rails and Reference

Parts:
C18, C20, C22, C28, C30: 4.7u 25V X7R; C_0805_2012Metric; MPN CL21B475KAFNNNE
C19, C24: 1u 25V X7R; C_0603_1608Metric; MPN C0603C105K3RACTU
C21: 22u 10V X7R; C_1206_3216Metric; MPN CL31B226KPHNNNE
C23: 220p 50V C0G; C_0603_1608Metric; MPN C0603C221J5GACTU
C25: 100n 50V X7R; C_0603_1608Metric; MPN C0603C104K5RACTU
C26: 10u 16V X7R; C_0805_2012Metric; MPN CL21B106KOQNNNE
C27, C29, C31: 10u 25V X7R; C_1210_3225Metric; MPN CL32B106KAJNNNE
D6, D7, D8, D9: B0530W 30V 0.5A; D_SOD-123; MPN B0530W-7-F
L1: 10u 3A; L_Wuerth_MAPI-4030; MPN 74438357100
R27: 100k 1%; R_0603_1608Metric; MPN CRCW0603100KFKEA
R28: 150k 1%; R_0603_1608Metric; MPN CRCW0603150KFKEA
R29: 51k 1%; R_0603_1608Metric; MPN CRCW060351K0FKEA
R30: 2.2R 1% 0.25W; R_1206_3216Metric; MPN CRCW12062R20FKEA
R31: 10R 1%; R_0603_1608Metric; MPN CRCW060310R0FKEA
R32: 133k 1%; R_0603_1608Metric; MPN CRCW0603133KFKEA
R33: 13.3k 1%; R_0603_1608Metric; MPN CRCW060313K3FKEA
R34: 226k 0.1%; R_0603_1608Metric; MPN TNPW0603226KBEEA
R35: 1R 1%; R_0603_1608Metric; MPN CRCW06031R00FNEA
R36: 100k 0.1% 25ppm; R_0603_1608Metric; MPN TNPW0603100KBEEA
R37: 0.47R 1% 0.25W; R_1206_3216Metric; MPN ERJ-8RQFR47V
R38: 120k 0.1%; R_0603_1608Metric; MPN TNPW0603120KBEEA
R39: 442k 1%; R_0603_1608Metric; MPN CRCW0603442KFKEA
R40: 12.4k 1%; R_0603_1608Metric; MPN CRCW060312K4FKEA
TP12: -4V_A; TestPoint_Pad_D1.5mm
TP13: +13V5; TestPoint_Pad_D1.5mm
TP14: VREF; TestPoint_Pad_D1.5mm
TP15: GND; TestPoint_Pad_2.0x2.0mm
TP16: +12V_A; TestPoint_Pad_D1.5mm
U9: 803 type, 3.08 V; SOT-23; not fitted
U10: LMR62014XMF; SOT-23-5; MPN LMR62014XMF/NOPB
U11: LM27761DSG; WSON-8-1EP_2x2mm_P0.5mm_EP0.9x1.6mm; MPN LM27761DSGT
U12: REF5025AID; SOIC-8_3.9x4.9mm_P1.27mm; MPN REF5025AID
U13: LT3042EMSE; MSOP-10-1EP_3x3mm_P0.5mm_EP1.68x1.88mm; MPN LT3042EMSE#PBF

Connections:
+5V: C18.1, L1.1, R29.1, R30.1, U9.3 (V_{DD}), U10.5 (VIN); also elsewhere on the board
+12V_A: C31.1, D9.1 (K), R39.1, TP16.1 (1_1), U13.9 (OUTS), U13.10 (OUT); also elsewhere on the board
+13V5: C23.1, C25.1, C27.1, D6.1 (K), R32.1, R37.1, TP13.1 (1_1); also elsewhere on the board
/Analog Rails/5V_OK: R27.1, U13.3 (EN/UV); also elsewhere on the board
unnamed: C26.1, R35.2
unnamed: C29.1, R37.2, U13.1 (IN), U13.2 (IN)
unnamed: D6.2 (A), L1.2, U10.1 (SW)
unnamed: R29.2, U9.2 (~RESET), U10.4 (EN)
unnamed: C23.2, R32.2, R33.1, U10.3 (FB)
unnamed: C19.1, U11.8 (C+)
unnamed: C19.2, U11.7 (C-)
unnamed: C22.2, U11.3 (CPOUT)
unnamed: R27.2, R28.1, U11.6 (EN)
unnamed: R34.1, R36.2, U11.5 (VFB)
unnamed: C21.1, R30.2, U11.1 (VIN)
unnamed: C24.1, U12.5 (Trim/NR)
unnamed: C20.1, R31.2, U12.2 (Vin)
unnamed: R39.2, R40.1, U13.6 (PGFB)
unnamed: C30.1, R38.1, U13.7 (SET)

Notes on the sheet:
U10: VOUT = 1.23 V x (1 + R32 / R33) = 13.5 V, 1.6 MHz; not gated by 5V_OK. C25 closes the switching loop at D6; C27 is 7 uF at 13.5 V (datasheet curve). U9: position for an open-drain voltage detector of the 803 type (3.08 V), not fitted. With it the converter stays off while +5V is below that lev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
Links for the first power-up: L1, R37, R31 and R27; each starts one stage.
R37 damps the capacitors on both sides and filters the ripple: 49 kHz with C29. U13: VOUT = 100 uA x R38 = 12.0 V; enabled by 5V_OK (1.24 V rising). R39, R40 end the fast charge of C30 at 11 V; settled after 0.8 s (calculated). D9 clamps +12V_A near ground while -4V_A is present without it.
U11: VOUT = -1.22 V x (R34 + R36) / R36 = -3.98 V. R30, C21 keep fast edges of +5V off the 5.8 V rating of VIN. R27, R28: EN = 0.6 x 5V_OK, below VIN while U11 limits its input current. D8 clamps -4V_A to ground while U11 is off.
U12 is supplied from +3V3_A through R31 and C20 (3.9 kHz), so VREF is never present without the rail of the parts that receive it. D7 empties the capacitors on VREF into +3V3_A when that rail falls. R35 damps C26; it is a tuning position, 0 ohm to 1.5 ohm. C24: noise filter, 10 Hz to 20 Hz (datashe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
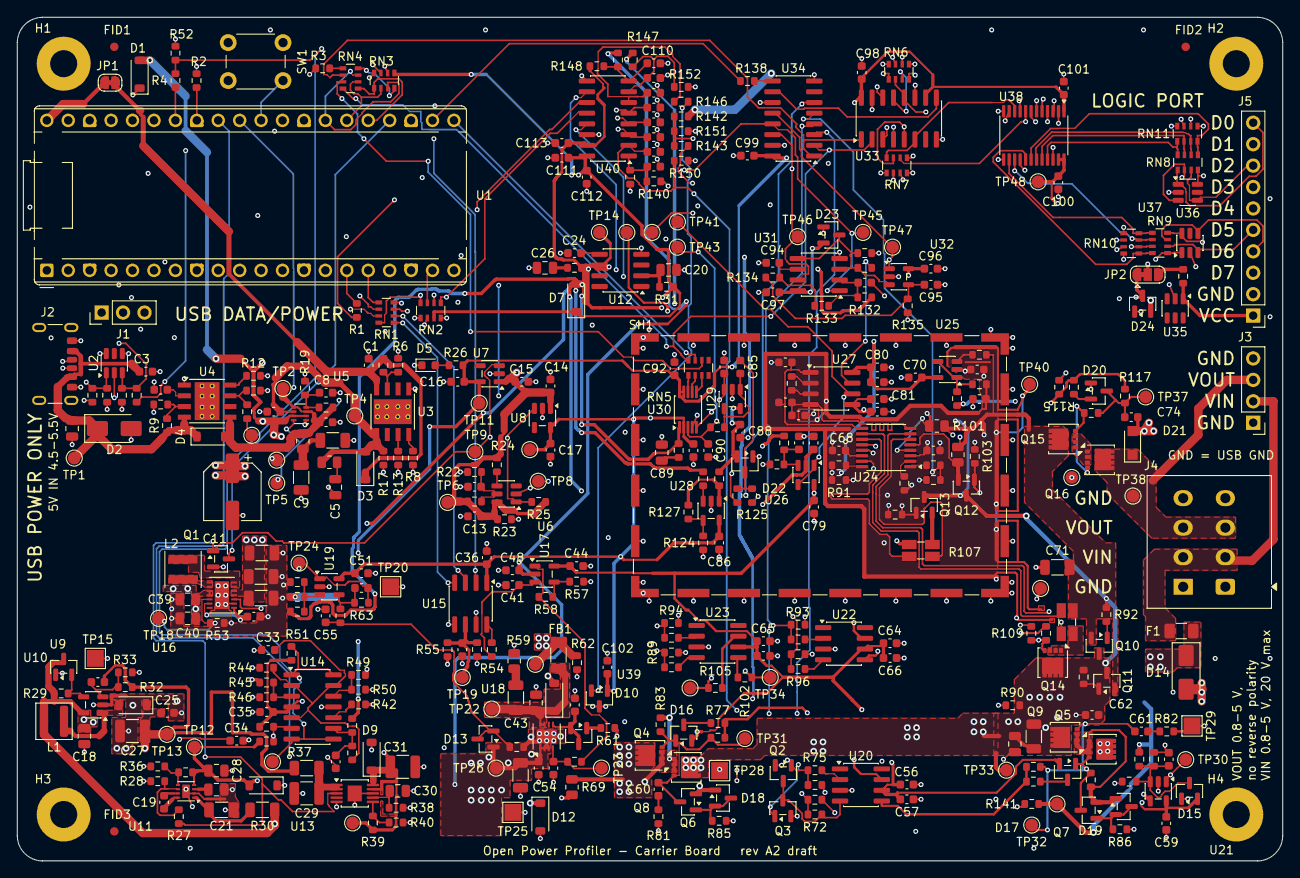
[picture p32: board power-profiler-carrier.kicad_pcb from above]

Board: 4 copper layers, 150.0 x 100.0 mm, 425 parts (0 on the bottom side), 225 nets.

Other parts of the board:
C102, C103, C104, C105, C106, C107, C108, C109, C110, C111, C113: 100n 50V X7R; C_0603_1608Metric
C112: 1u 25V X7R; C_0603_1608Metric
R140, R142: 120k 1%; R_0603_1608Metric
R141: 430k 1%; R_0603_1608Metric
R143: 68.1k 1%; R_0603_1608Metric
R144, R145, R150, R152: 10k 1%; R_0603_1608Metric
R146: 1k 1%; R_0603_1608Metric
R147: 47k 1%; R_0603_1608Metric
R148, R149, R151: 100k 1%; R_0603_1608Metric
R153: 200k 1%; R_0603_1608Metric
U39: MCP9700AT-E/TT; SOT-23
U40: MCP3208-BI/SL; SOIC-16_3.9x9.9mm_P1.27mm

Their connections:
+5V: R142.1; also elsewhere on the board
+12V_A: R147.1; also elsewhere on the board
/Controller/C_MISO: U40.12 (Dout); also elsewhere on the board
/Controller/C_MON_CS: U40.10 (~CS/SHDN); also elsewhere on the board
/Controller/C_MOSI: U40.11 (Din); also elsewhere on the board
/Controller/C_SCK: U40.13 (CLK); also elsewhere on the board
/Monitors/CC1: R144.1; also elsewhere on the board
/Monitors/CC2: R145.1; also elsewhere on the board
/Monitors/SRC_ST: R143.2; also elsewhere on the board
/Monitors/VIN_P: R141.1; also elsewhere on the board
/Monitors/VOUT_BUF: R140.1; also elsewhere on the board
unnamed: R146.1, U39.2 (V_{OUT})
unnamed: C103.1, R140.2, R149.1, U40.1 (CH0)
unnamed: C104.1, R141.2, R150.1, U40.2 (CH1)
unnamed: C105.1, R142.2, R143.1, R151.1, U40.3 (CH2)
unnamed: C106.1, R144.2, U40.4 (CH3)
unnamed: C107.1, R145.2, U40.5 (CH4)
unnamed: C108.1, R146.2, U40.6 (CH5)
unnamed: C109.1, R147.2, R152.1, U40.7 (CH6)
unnamed: C110.1, R148.2, R153.1, U40.8 (CH7)

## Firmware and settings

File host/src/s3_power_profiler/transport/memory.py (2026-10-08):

"""In-memory transport: two connected ends that carry bytes between them.

It replaces a cable in tests and in simulation. The ends are safe to use from
two threads. A single thread can also drive both sides by installing a pump on
the reading end, as :func:`s3_power_profiler.sim.connect_simulator` does.
"""

from __future__ import annotations

import threading
from collections.abc import Callable

from s3_power_profiler.errors import TransportClosedError


class _Pipe:
    """One direction of the connection."""

    def __init__(self) -> None:
        self.data = bytearray()
        self.condition = threading.Condition()
        self.closed = False


class MemoryTransport:
    """One end of an in-memory connection. Create both with :func:`memory_pair`."""

    def __init__(self, inbound: _Pipe, outbound: _Pipe) -> None:
        self._inbound = inbound
        self._outbound = outbound
        self._pump: Callable[[], None] | None = None
        self._closed = False

    @property
    def closed(self) -> bool:
        """True after this end was closed."""
        return self._closed

    def set_pump(self, pump: Callable[[], None] | None) -> None:
        """Install the function that lets the other side run.

        When a read finds nothing to return, it calls the pump once before
        waiting. In a single-threaded program the pump runs the peer, which
        consumes what was written to it and produces its answer, so the read
        can return it. Pass None to remove the pump.
        """
        self._pump = pump

    def read(self, max_bytes: int, timeout: float | None) -> bytes:
        """Read up to ``max_bytes`` bytes sent by the other end.

        Returns:
            The bytes read, or an empty value if the timeout expired.

        Raises:
            ValueError: If ``max_bytes`` is not positive.
            TransportClosedError: If this end is closed, or the other end is
                closed and everything it sent was already read.
        """
        if max_bytes <= 0:
            raise ValueError("max_bytes must be positive")
        self._ensure_open()
        pipe = self._inbound
        if self._pump is not None and not self._has_data():
            self._pump()
        with pipe.condition:
            if not pipe.data and not pipe.closed and (timeout is None or timeout > 0):
                pipe.condition.wait_for(lambda: bool(pipe.data) or pipe.closed, timeout)
            if pipe.data:
                chunk = bytes(pipe.data[:max_bytes])
                del pipe.data[:max_bytes]
                return chunk
            if pipe.closed:
                raise TransportClosedError("the other end closed the connection")
            return b""

    def write(self, data: bytes) -> None:
        """Send ``data`` to the other end.

        Raises:
            TransportClosedError: If either end is closed.
        """
        self._ensure_open()
        pipe = self._outbound
        with pipe.condition:
            if pipe.closed:
                raise TransportClosedError("the other end closed the connection")
            pipe.data += data
            pipe.condition.notify_all()

    def close(self) -> None:
        """Close this end. The other end can still read what was already sent."""
        if self._closed:
            return
        self._closed = True
        for pipe in (self._inbound, self._outbound):
            with pipe.condition:
                pipe.closed = True
                pipe.condition.notify_all()

    def _ensure_open(self) -> None:
        if self._closed:
            raise TransportClosedError("the transport is closed")

    def _has_data(self) -> bool:
        with self._inbound.condition:
            return bool(self._inbound.data)


def memory_pair() -> tuple[MemoryTransport, MemoryTransport]:
    """Create two connected ends: what one writes, the other reads."""
    forward = _Pipe()
    backward = _Pipe()
    return MemoryTransport(backward, forward), MemoryTransport(forward, backward)

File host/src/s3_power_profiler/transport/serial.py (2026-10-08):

"""Serial-port transport built on pyserial.

The instrument appears as a USB CDC serial port. The adapter receives the port
object through its constructor, so tests can pass a fake one, and
:meth:`SerialTransport.open` builds the real one from a device name or URL.
"""

from __future__ import annotations

from typing import Protocol

import serial

from s3_power_profiler.errors import TransportClosedError, TransportError

DEFAULT_BAUD_RATE = 115200
"""Baud rate requested when opening a port. A USB CDC port ignores it."""

DEFAULT_WRITE_TIMEOUT = 1.0
"""Seconds a write may block before it fails."""


class SerialPort(Protocol):
    """The part of a pyserial port that the adapter uses."""

    timeout: float | None

    @property
    def is_open(self) -> bool:
        """True while the port is open."""

    @property
    def in_waiting(self) -> int:
        """Number of received bytes waiting to be read."""

    def read(self, size: int = 1) -> bytes:
        """Read up to ``size`` bytes, waiting at most ``timeout`` seconds."""

    def write(self, data: bytes, /) -> int | None:
        """Send ``data``."""

    def flush(self) -> None:
        """Wait until everything written was sent."""

    def close(self) -> None:
        """Close the port."""


class SerialTransport:
    """Transport over a serial port.

    Args:
        port: An open pyserial port, or an object with the same interface.
    """

    def __init__(self, port: SerialPort) -> None:
        self._port = port
        self._closed = False

    @classmethod
    def open(
        cls,
        url: str,
        *,
        baudrate: int = DEFAULT_BAUD_RATE,
        write_timeout: float | None = DEFAULT_WRITE_TIMEOUT,
    ) -> SerialTransport:
        """Open a serial port.

        Args:
            url: Device name such as ``COM5`` or ``/dev/ttyACM0``, or a pyserial
                URL such as ``loop://``.
            baudrate: Baud rate to request.
            write_timeout: Seconds a write may block, or None for no limit.

        Raises:
            TransportError: If the port cannot be opened.
        """
        try:
            port = serial.serial_for_url(url, baudrate=baudrate, write_timeout=write_timeout)
        except (serial.SerialException, ValueError) as error:
            raise TransportError(f"cannot open serial port {url!r}: {error}") from error
        return cls(port)

    def read(self, max_bytes: int, timeout: float | None) -> bytes:
        """Read up to ``max_bytes`` bytes from the port.

        Returns:
            The bytes read, or an empty value if the timeout expired.

        Raises:
            ValueError: If ``max_bytes`` is not positive.
            TransportClosedError: If the port is closed.
            TransportError: If the port failed.
        """
        if max_bytes <= 0:
            raise ValueError("max_bytes must be positive")
        self._ensure_open()
        wait = None if timeout is None else max(timeout, 0.0)
        try:
            if self._port.timeout != wait:
                self._port.timeout = wait
            data = self._port.read(1)
            if data and max_bytes > 1:
                waiting = min(self._port.in_waiting, max_bytes - 1)
                if waiting:
                    data += self._port.read(waiting)
        except serial.SerialException as error:
            raise TransportError(f"serial read failed: {error}") from error
        return bytes(data)

    def write(self, data: bytes) -> None:
        """Send all of ``data`` through the port.

        Raises:
            TransportClosedError: If the port is closed.
            TransportError: If the port failed or the write timed out.
        """
        self._ensure_open()
        try:
            self._port.write(data)
            self._port.flush()
        except serial.SerialException as error:
            raise TransportError(f"serial write failed: {error}") from error

    def close(self) -> None:
        """Close the port. Closing a closed transport does nothing."""
        if self._closed:
            return
        self._closed = True
        self._port.close()

    def _ensure_open(self) -> None:
        if self._closed or not self._port.is_open:
            raise TransportClosedError("the serial port is closed")

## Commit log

2026-10-08 chore: add repository configuration
    Ignore rules for ESP-IDF, Python and KiCad outputs, LF line endings for
    every text file, editor settings, and the Markdown lint rules used by
    the documentation.
2026-10-08 docs(spec): add system specification
    Baseline for the architecture and the development plan of the
    instrument: requirements, analog and firmware design, host protocol,
    calibration, verification plan, phases with exit criteria, risk
    register and decision log.
    Parts marked as candidates are not yet verified against their
    datasheets, and no value has been simulated or measured. Section 16
    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
2026-10-08 docs: add documentation index and record templates
    Component checks close the open items of section 16 of the
    specification and phase reports close the development phases of
    section 13. Both get a template and the rules for filling it in, so
    that every figure can be traced to a datasheet or to a measurement.
2026-10-08 chore: add firmware, hardware, host and tools skeleton
    One directory per part of the instrument, each with a README that
    states its scope, planned layout and current status. The firmware
    components follow section 6.1 of the specification. No code yet.
2026-10-08 feat(protocol): add single protocol definition and generator
    The constants of the wire protocol were about to be typed twice, in C
    and in Python. They now live in protocol/definition.toml, and
    protocol/generate.py writes the C header for the firmware, the Python
    module for the host and a set of test vectors that both codecs must
    reproduce byte for byte.
    The generator carries its own reference encoder, checked against
    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
2026-10-08 docs(spec): add carrier board, protocol codes and engineering rules
    Three changes share the file:
    - The instrument becomes two boards: an ESP32-S3-DevKitC-1 compatible
    development board on a carrier board (D-14), with its own USB-C
    power connector (D-15) and the slow monitors on an external
    converter (D-16). The pin map is rewritten for the 19 signals the
    headers leave available, and section 4.11 defines the power domains.
    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
2026-10-08 feat(firmware): add ESP-IDF project and tested core logic
    The firmware starts with the part that needs no hardware, written as
    pure C11 behind ports and tested on the PC with Unity:
    - base: status codes, byte access, lock-free block queue
    - proto: CRC-16, frame encoder and parser, sample word, stream
    payload, command envelopes
    - acq: settling window and step-down rule
    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
    [gcovr.cfg]
2026-10-08 feat(host): add Python package with codec, client and simulator
    s3-power-profiler talks to the instrument through layers that depend
    only downward:
    - protocol: CRC, frames, sample word, stream payload and command
    envelopes, with no I/O
    - transport: one interface, with serial and in-memory adapters
    - device: client that matches responses and collects the stream
    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
2026-10-08 feat(hardware): add KiCad project with development board sockets
    The carrier board starts with the part of the design that is fixed:
    the two rows of sockets for the ESP32-S3-DevKitC-1 compatible board
    and the 19 signals of section 5 of the specification.
    The project library has a 44-pin symbol and a footprint with rows
    22.86 mm apart, both taken from the Espressif reference design. The
    analog sheets follow once their component checks are closed.
    The electrical rules check reports no errors and 20 warnings for
    labels that end at the edge of the sheet until those sheets exist.
    [mcu_interface.kicad_sch, power-profiler-carrier.kicad_sch]
2026-10-08 ci: add firmware, host, protocol and hardware workflows
    Each area gets the checks of section 18 of the specification:
    - Firmware: unit tests, coverage floors, sanitizers, clang-format,
    clang-tidy, cppcheck and the ESP-IDF build for esp32s3
    - Host: lint, strict type check, tests on Windows, Linux and macOS,
    and a wheel that installs and runs
    - Protocol: generated files up to date
    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
2026-10-08 docs: describe the software foundations and the quality gates
    The readme, the contributing guide and the changelog follow the new
    state of the project: two boards, a protocol directory, tested
    firmware and host packages, and gates that every pull request has to
    pass.
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2026-10-08 feat(hardware): draw the carrier board schematic as draft A0
    Draw every block of the carrier board on thirteen A4 sheets: board
    interface, power input, analog rails, source meter, path switching,
    shunt ladder, output stage, signal chain, comparators, range logic,
    digital inputs and monitors. Connections inside a sheet are wires,
    supply rails use power symbols, and the root sheet joins the sheets
    with wires between their hierarchical pins.
    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
    [analog_rails.kicad_sch, comparators.kicad_sch, digital_inputs.kicad_sch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]
2026-10-08 feat(hardware): add the board with every footprint placed by block
    Add the board file of draft A0: outline of 160 mm x 100 mm with four
    M3 holes, four copper layers, the sockets of the development board at
    the left with its USB end at the bottom edge, the power connector
    beside them, and the VIN and VOUT terminals and the logic header on the
    right edge. The other footprints are packed inside the area of their
    functional block, drawn on the Dwgs.User layer. The area under the
    antenna of the development board is a keep-out.
    Nothing is routed. The design rules check reports no violation and no
    difference between board and schematic; the unconnected items it lists
    are the missing tracks.
    [power-profiler-carrier.kicad_pcb]
2026-10-08 ci: check the board against the schematic
    The Hardware workflow now also runs the design rules check with the
    schematic parity test. The board is not routed, so the unconnected
    items are expected and the exit code cannot be used: the job reads the
    report and fails on any rule violation or any difference between board
    and schematic. The job is renamed to cover both checks.
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2026-10-08 feat(hardware)!: draw draft A1 of the schematic around a Pico 2
    A Raspberry Pi Pico 2 on two 1x20 sockets replaces the ESP32-S3
    development board, the programmable logic device and the buffer
    between the two boards (D-39 to D-43 of the specification). The former
    interface and range logic sheets become two new ones:
    - Controller: the Pico 2, the diodes that join its USB supply and the
    5 V rail of the carrier, resistor arrays in the SPI and acquisition
    lines, a reset button and a console header.
    - Side Data: two shift registers that take the range, the status
    signals and the eight logic inputs with every sample.
    The DUT connects through a 1x4 pin header and a lever terminal block
    in pa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
    [analog_rails.kicad_sch, comparators.kicad_sch, controller.kicad_sch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]
2026-10-08 feat(hardware): place the parts of draft A1 on a 130 mm x 100 mm board
    The outline shrinks from 160 mm x 100 mm to 130 mm x 100 mm (D-46).
    The back edge, on the left, has the Pico 2 with its USB connector and
    the USB-C power connector. The front edge, on the right, has the logic
    port and the two DUT connectors, each with the names of its pins.
    The parts are no longer packed in rows. Each one stands near the pin
    it serves, turned towards its connections, inside the area of its
    functional block; the switching converters are in the left third and
    the front end in the right third. The reference designators of 23
    parts are hidden on the silkscreen, where no free place was left
    beside the part, a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
    [power-profiler-carrier.kicad_pcb]
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2026-10-08 docs: use the new name of the repository
    The repository is now open-power-profiler. Its former name carried the
    ESP32-S3, which is no longer the controller (D-39); the new one names no
    hardware, so it survives a change of controller.
    Update the clone command and the changelog link, say in the README what
    the repository was called before, and record the rename in the
    changelog. The former address redirects to the new one.
2026-10-08 docs: present the project as the Open Power Profiler
    The repository is called open-power-profiler now, and the README still
    carried the short working title and a paragraph about its history.
    Give the README the name of the project and bring it in line with what
    exists: the state of hardware, software and firmware target at the top,
    a section on the connections with the pin order of the connectors and
    the two modes, the range sequencer in the diagram, protection that does
    not wait for firmware, and the guides of every part in the list of
    documents. The history moves to the acknowledgments.
    The title of the specification takes the same name, and the changelog
    records this round.
2026-10-08 docs(firmware): write the guide around the Raspberry Pi Pico 2
    The guide described an ESP-IDF project with a note on top saying that
    the controller had changed. Turn it around: the firmware is that of the
    Pico 2, a table says what exists (the hardware-independent core and its
    tests), what does not (the Pico SDK build, the adapters, the PIO
    programs), and that the only target build in the directory is still the
    ESP-IDF one of the first plan.
    The architecture and the rules speak of the SDK of the controller
    instead of ESP-IDF, the build section separates the Pico 2 from the
    build that is being replaced, and new adapters are to be written for
    the Pico SDK only. Commands for the Pico 2 are adde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
2026-10-10 feat(hardware): draw draft A2 of the schematic
    428 parts on 15 A4 pages, 14 sheets below the root sheet (D-83). Two
    sheets are new: Logic Supplies, with the supervisor of the 5 V rail and
    the two 3.3 V regulators, and Rail Monitor, with the comparators behind
    PWR_GOOD.
    The drawings follow the specification of draft A2: a current limiter
    on each supply input and a priority multiplexer, a pre-regulator that
    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
    [analog_rails.kicad_sch, comparators.kicad_sch, controller.kicad_sch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]
2026-10-10 feat(hardware): place and route draft A2 on a 150 mm x 100 mm board
    The outline grows from 130 mm x 100 mm to 150 mm x 100 mm (D-85). A
    script places the 425 footprints inside the areas of sixteen functional
    blocks, with the front end under the frame of a shield can, and an
    autorouter draws the tracks (D-86): 956 of the 984 connections, on
    three layers over an unbroken ground plane. 28 connections are open.
    The project file holds thirteen net classes, the default class among
    them, and a rule file adds the clearances that a net class cannot
    express. The stackup is the build that section 10.1 of the
    specification assumes until a manufacturer is chosen.
    The design rules check reports no rule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
    [power-profiler-carrier.kicad_pcb]
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2026-10-10 docs(hardware): list the open connections and the simulations to file
    The hardware guide opens with the state of the draft in one table and
    says plainly that the autorouted board does not work as it is. Its
    list of open work is in the order of the work:
    - the 28 open connections one by one, with the net, what it is, both
    ends, their places and what is lost while it is open, and a map of
    them over the copper of the board;
    - what the layout review has to draw and check by hand;
    - the simulations behind the figures that the specification marks
    "simulated", block by block, whose files are not filed yet;
    - the open checks and the work that waits for the firmware.
    The bill of materials of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
    [bom.csv]
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2026-10-10 feat(hardware): review the layout of the carrier board
    The autorouted board of draft A2 had 28 of its 984 connections open
    and none of the copper that an autorouter does not draw. The layout is
    now reviewed against section 10 of the specification:
    - every connection is routed;
    - the 1 A path is pours, with the supply band doubled on the bottom
    layer: 19.5 squares in source mode and 23.3 squares in ampere mode
    against the limit of 30;
    - the measured node has its guard and the Kelvin lines of the four
    shunts, and no track on the bottom layer under the shield can; the
    surface leakage into it is 5.1 nA against a budget of 10 nA;
    - the switch nodes and the output copper of the converters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
    [power-profiler-carrier.kicad_pcb]
2026-10-10 docs(hardware): name the project in the schematic title block
    The title block of the root page now reads "Open Power Profiler -
    Carrier Board", as the silkscreen and the title block of the board do
    since the previous commit. The circuit is unchanged: the electrical
    rules check reports no error and no warning, and the board still
    agrees with the schematic.
    The schematic PDF and the picture of its root page are exported again
    with KiCad set to English. The other 14 pages are the same as before,
    compared page by page.
    [power-profiler-carrier.kicad_sch]
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2026-10-10 feat(tools): add the board figures package
    The documents quote figures of the layout that are calculated from the
    drawn copper. The scripts behind them were not in the repository, so
    nobody could repeat a figure. They are filed now as a package under
    tools/board (distribution board-figures, command board-figures):
    - squares: resistance of the copper of a net between pads, in squares
    and in milliohms;
    - path: whether two pads are joined on one layer alone, and how long
    the way is;
    - pairs: length of the two lines of a pair along their center lines;
    - leakage: surface leakage into the measured node on an outer layer;
    - report: every figure that the definition of the carrier asks for.
    Wha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
2026-10-10 ci: fail the Hardware workflow on an unconnected pad
    The autorouted board had open connections, so the workflow could not
    look at the unconnected items of the design rules check. The reviewed
    board has none: the report now has to show no rule violation, no
    unconnected pad and no footprint error.
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2026-10-10 feat(simulation): add the circuit simulation package
    Add circuit_sim, a package that builds SPICE decks from a snapshot of
    the netlist of the schematic, runs them in the ngspice shared library
    and takes figures from the waveforms. A bench names parts of the
    schematic and adds sources, loads and analyses; the circuit itself is
    generated, so that a simulated circuit cannot differ from the drawn
    one. Results are filed as records with graphs and decks, and the
    pages are written from the records.
    The engine fails a run whose log shows an operating point that did
    not converge, which ngspice otherwise reports as if it had. Tests:
    777, of which 11 need the ngspice library; line and branch coverage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
2026-10-10 feat(simulation): add the benches of the carrier board
    Add 134 benches: 93 on the circuits of the board in ten blocks (shunt
    ladder, signal chain, range logic, source meter, output stage, path
    switching, power input, analog rails, digital lines, whole measuring
    path) and 41 that put the models into the test circuits of their
    datasheets. A bench takes its parts from the netlist, adds what the
    schematic does not hold (sources, loads, cables, the device under
    test) and compares each figure with the value and the limits of the
    specification. A figure that fails stays failed, and the notes of the
    bench say what the models leave out.
    [boost_detector.py, boost_output.py, boost_start.py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]
2026-10-10 docs(spec): record decisions D-94 to D-98
    D-94 puts the circuit simulations in a package of their own in
    simulation/, built from a snapshot of the netlist and run in the
    ngspice library of KiCad 10. D-95 to D-98 are the four points that
    the simulations of 2026-10-10 raised and the project owner decided:
    10 nF at the rail monitor inputs C32 to C34, a position for a
    capacitor at the non-inverting input of U28, the detector position U9
    left without a part, and the damper R14 with C5 fitted on the input
    from the controller module.
    The decisions are propagated through sections 1, 3, 4.1, 4.5, 4.7,
    10.8, 11, 13, 14, 16 and 17. D-95, D-96 and D-98 are not drawn yet:
    schematic, board and bill of ma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

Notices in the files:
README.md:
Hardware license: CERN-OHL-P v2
